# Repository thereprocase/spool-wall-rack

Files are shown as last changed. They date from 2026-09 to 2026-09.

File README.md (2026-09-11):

# Spool wall rack: recovered print settings and E + F trials

**Recovered print evidence changes the reference.** The completed overnight ASA archive uses seven walls, 10% base infill and 1.6 mm minimum top/bottom thickness. Its associated downloaded STEP matches E13 exactly. The newer STEP matches G; its saved PETG project uses two walls and the same 1.6 mm thickness settings, but the exact earlier PETG submission is not recovered. Geometry, walls and material changed together.

https://github.com/thereprocase/spool-wall-rack/blob/main/designs/rev-g2/print-controls/RECOVERED-PRINTS.md

**Current E + F result: material budget achieved; stiffness target missed.** A direct diagonal with a continuous solid helper core uses 22.49% less extrusion than the deliberate eight-wall G control, with 1.6 mm skins retained. Intermediate contact diagnostics give 4.9818 mm movement versus 2.6730 mm for that G control. Both tighter 1e-5 checks miss their time bounds. This is not a winning or physically qualified design.

The G rod/mount positions and protected bearing/capture geometry remain fixed. The locating underside stays at Y=-32 mm for at least 25.4 mm from the wall. No moulding support is assumed.

All current controls, actual slices, aligned STEP/helpers and numerical limitations

https://github.com/thereprocase/spool-wall-rack/tree/main/designs/rev-g2/print-controls

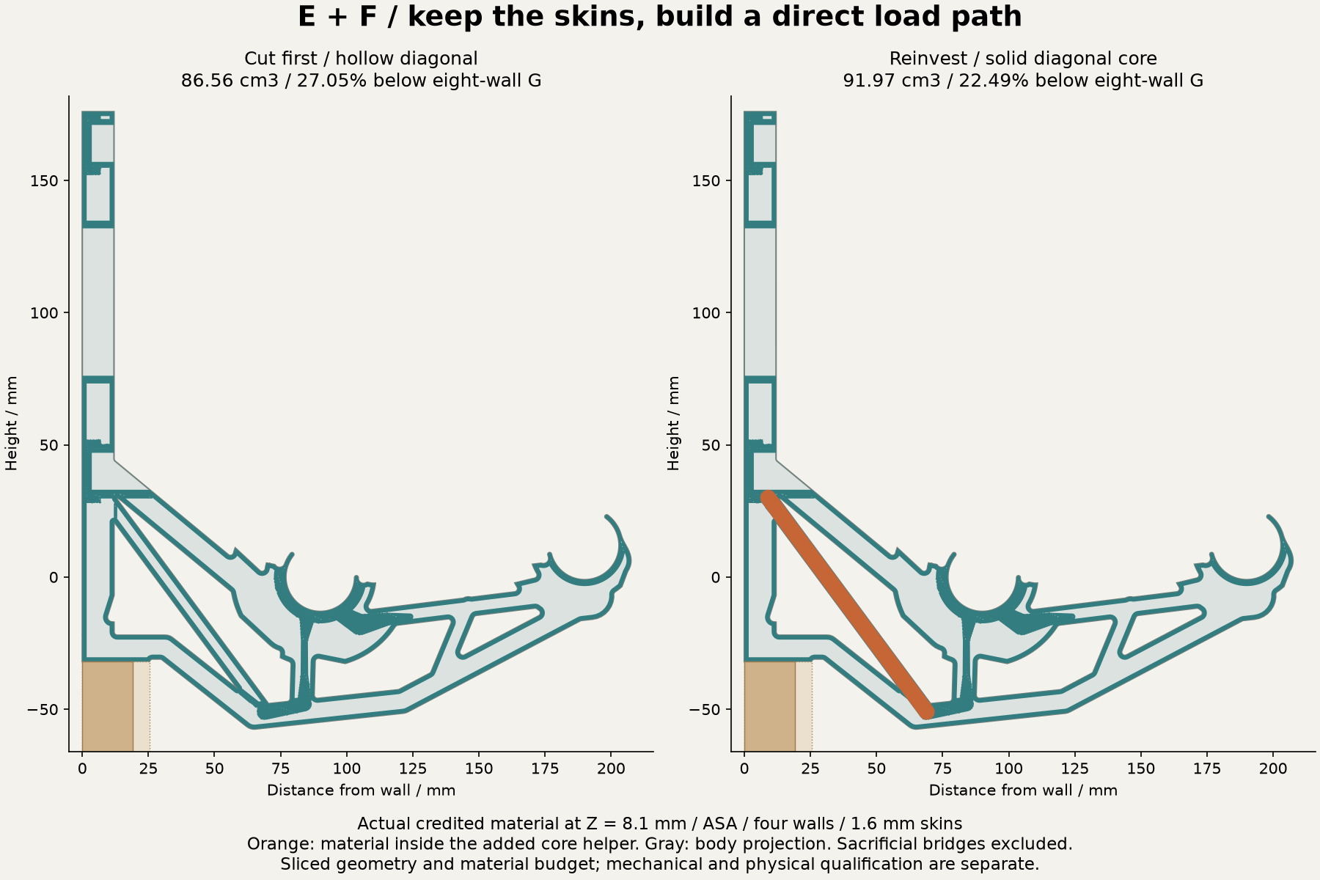
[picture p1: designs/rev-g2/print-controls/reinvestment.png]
Actual sliced brace reinvestment


## Preserved earlier screening work

**Completed local pilot: [evolutionary screening loop](analysis/rev-g2/EVOLUTION.md).** The first
batch screened 100 helper proposals in 11 min 18 s. The leading actual-slice
3D pass took 6 min 55 s including CAD, slicing, preparation and field audit:
4.1295 mm movement versus 4.3355 mm for G, with a 2.02% higher raw stress peak.
Its full-cell leader refinement took another 5 min 18 s and gives 4.1547 mm
maximum movement. Further finalist and mesh checks are recorded on the loop page. These are
screening results; material accuracy and physical qualification remain open.

Fresh 10.75 / 12 / 13.25 kg G contact checks are documented in [G results](analysis/rev-g2/G-RESULTS.md). One spool changes bracket movement by about 0.452 mm; material accuracy and physical qualification remain open.

[Printable STEP bodies, aligned helpers and per-idea notes](PRINT-CANDIDATES.md).

**Restart checkpoint:** [complete handoff and current candidates](RESTART-2026-09-11.md).

**G baseline: [completed 3D contact screen and accuracy limits](analysis/rev-g2/G-RESULTS.md).**
At 12 kg, the retained-material model gives **4.3355 mm maximum bracket movement**
and **20.0254 MPa raw peak tensile stress**. Wall contact has settled. A tenfold
tighter numerical check changes no nodal movement by more than 0.00000049 mm.
The geometry still omits 8.02% of raw nominal plastic; this is an explicitly
bounded numerical screen, not a qualified PETG/ASA bracket or load rating.
All seven G2 architectures remain unbuilt.

[Previous adaptive mesh and fresh P1S/PETG slicing checkpoint](analysis/rev-g2/ADAPTIVE-MESH.md).

**September 11, 2026: correcting the structural material model before G2.**
G's finalist is being rechecked against actual Orca paths with at least two
walls, 0% base infill and the existing 100% helpers. The wall/skin validation
matrix includes eight walls with two top/bottom layers and the reverse.
Thick 0.4 mm bridge extrusion counts toward plastic use but receives no
structural or bonded-connection credit. The new eroded-material contact screen is linked above; no corrected-material
qualification or preferred G2 prototype is established yet.

The reusable path-backed shape tool has passed independent occupancy and
thickness checks across all five schedules: 50,000 occupancy samples, with
zero mismatches outside the stated 0.005 mm polygonization band. The two-wall,
1 mm skin reference uses 77.920 cm³ of plastic, of which 6.940 cm³ is excluded
sacrificial bridge extrusion. A boundary-only volume mesh matches the
reconstructed continuum volume but fails topology/quality review. The long
whole-part CPU meshing attempts have been stopped. The replacement investigation
now uses GPU adaptive hexahedra; the completed eroded-material numerical
screen is linked above.

[GPU execution checkpoint](analysis/rev-g2/GPU-VALIDATION.md): the free Warp
runtime now passes an upstream elasticity comparison and independent 3D
elasticity/contact fixtures on the RTX 3080 Ti. GPU patch tests also pass on
an actual G slice crop. Conservative voxels still omit 17.12%, 8.37% and 4.31%
of that crop at progressively finer XY grids, so they are not accepted as
G's printed material. Material-converged whole-bracket mechanics and all seven
G2 architecture families remain unfinished. [Earlier software review](analysis/rev-g2/GPU-FEM-REVIEW.md).

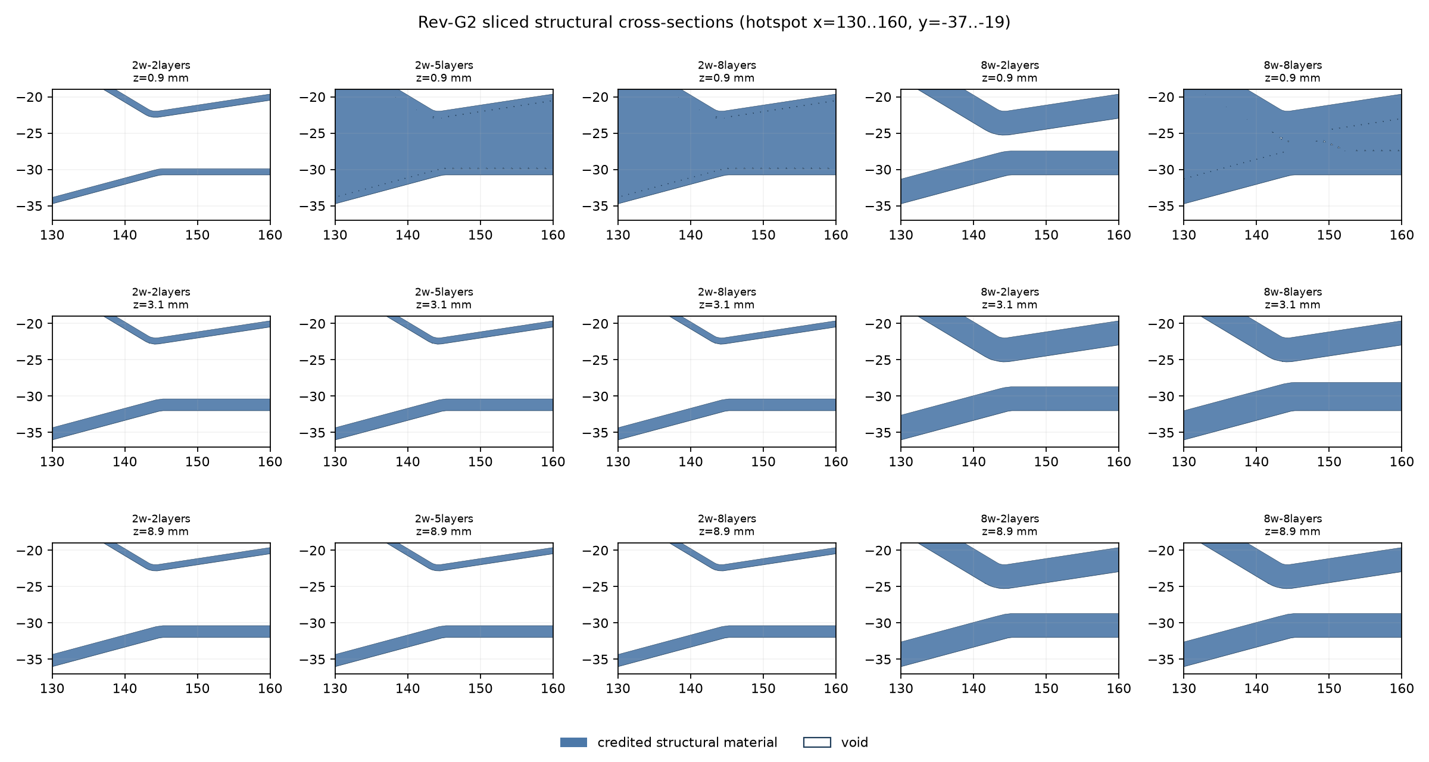
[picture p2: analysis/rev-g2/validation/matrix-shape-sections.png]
Actual sliced material across five wall and skin schedules


[G2 scope and acceptance gates](G2-BRIEF.md) ·
[Shape validation, slice evidence and reproduction](analysis/rev-g2/README.md) ·
[Slicer-backed shape tool](analysis/rev-g2/plastic_shape.py) ·
[Meshing progress and sources](analysis/rev-g2/MESHING-NOTES.md)

The new study changes actual architecture and density strategy while preserving
the specified interfaces. The current contract supersedes the earlier permission
to move rods or fixings and the old silhouette restrictions. P1S, 0.4 mm nozzle;
PETG or ASA.

## Preserved Rev G numerical study

**September 10, 2026: Rev G's evolutionary-search sprint is complete.
1,458 distinct parameter sets were evaluated. No tested finalist demonstrates
the requested 4× fracture margin; no qualified minimum-mass winner is selected.**
E13 remains the established prototype handoff, with its existing validation limits.

The results below belong to G's former material approximation. They are
preserved as regression evidence while the slice-to-FEM mapping is corrected;
they do not establish failure of the actual printed bracket.

[Current Rev G research CAD](designs/rev-g/README.md) ·
[Search, 3D results and limiting mechanism](analysis/rev-g/README.md) ·
[Next study](NEXT-SPRINT.md) · [Preserved F checkpoint](REV-F-CHECKPOINT.md) ·
[E13 guide](E13-ENGINEERING-GUIDE.md) · [Design journal](DESIGN-JOURNAL.md)

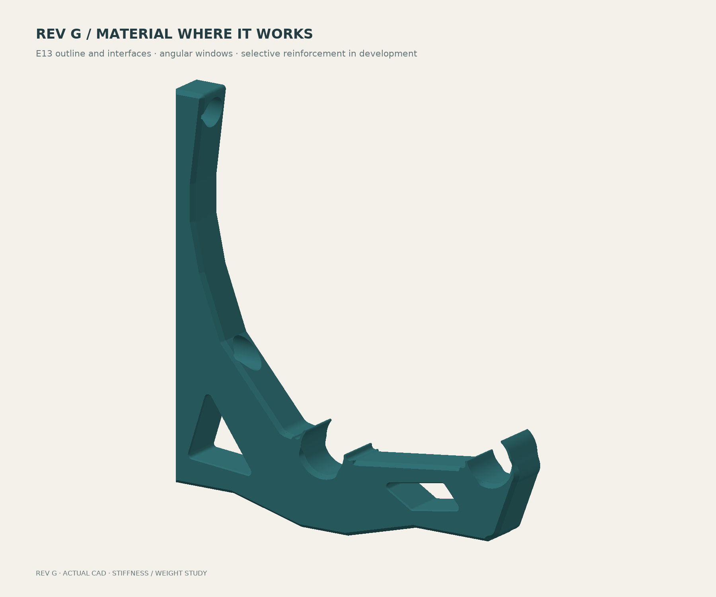
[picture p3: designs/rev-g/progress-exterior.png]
Actual Rev G finished CAD with preserved E13 exterior and angular windows


The full-plane search finalist slices to **103.76 g per bracket: 37.9% less
plastic than E13**. On matched fine meshes it is 51.1% more flexible and has
**6.6% better stiffness per gram**. Its 3.306 mm mean seat translation leaves
1.694 mm of the 5 mm total movement budget for other contributors at the
1 GPa planning modulus. Its raw tensile peak still fails the strength screen.

| Tested design | Actual Orca mass | Front vertical movement at 12 kg, E = 1 GPa | Outcome |
|---|---:|---:|---|
| E13, 8 walls | 167.11 g | 2.148 mm, h1 | Preserved reference prototype |
| G, thin shaped seed-1 candidate | 84.35 g | 4.930 mm, h2 | Movement, strength and dense-path coverage failures |
| G, full-plane search finalist | **103.76 g** | **3.246 mm, h1** | CAD/toolpaths pass; all three meshes fail fracture screen |
| G, wider inner-seat support | 108.03 g | 2.988 mm, h2 | Improves coarse result; fracture screen still fails |

Masses use the same neutral density of 1.24 g/cm³. Movements are modeled,
not measured. Mesh levels differ where stated; no physical print or sustained
load qualification is claimed.

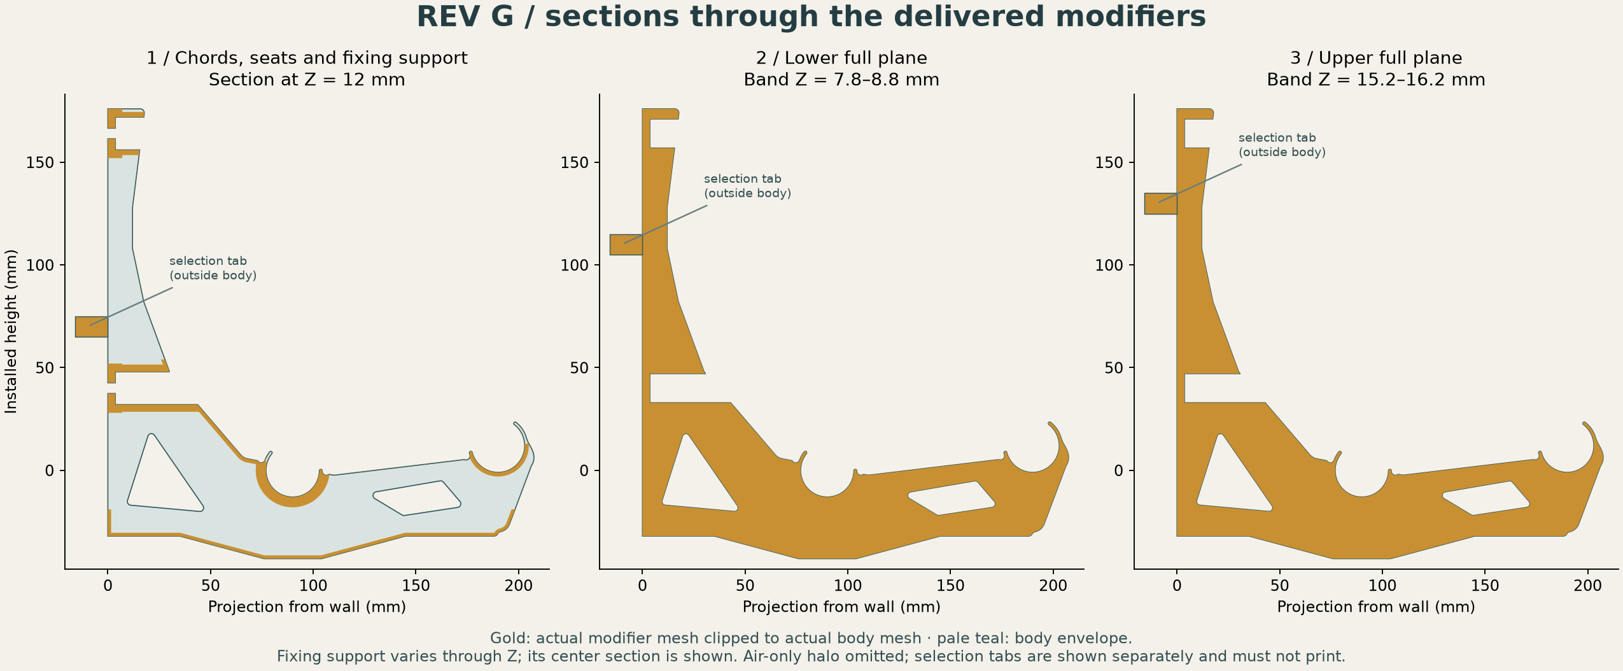
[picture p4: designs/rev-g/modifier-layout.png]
Sections through actual Rev G body and three modifier meshes


The genetic optimizer is implemented. Two broad-family seeds and a second
family informed by 3D failures were run; two cached search replays reproduced
the complete ledgers exactly. Four uncached physics cases match the canonical
solver. Actual Orca checks verify modifier roles, alignment and nonprinting
tabs. [Full evidence and reproduction commands](analysis/rev-g/README.md).

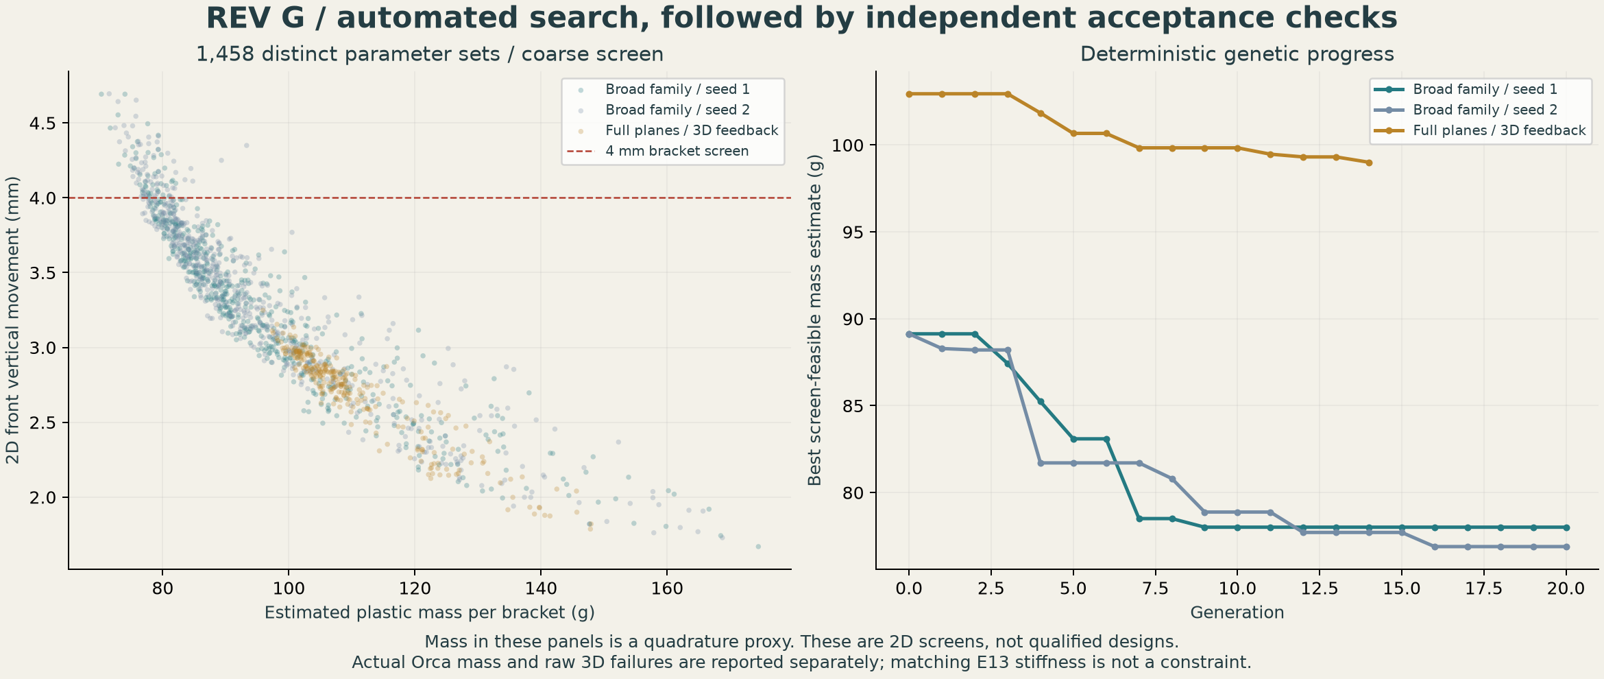
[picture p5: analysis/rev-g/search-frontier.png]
Genetic search progress and estimated mass/movement frontier


**What limits the design:** the full-plane candidate's raw tensile peak rises
from 32.29 to 55.05 MPa with mesh refinement, above the 10.125 MPa nominal
screen. The fine peak is adjacent to a preserved exterior forearm chamfer.
All finite cells are retained; this is not a converged rupture prediction.
The next study addresses that local geometry/material-model uncertainty before
further mass optimization. [Stress evidence](analysis/rev-g/README.md#mesh-refinement-and-the-limiting-mechanism)
· [Next study scope](NEXT-SPRINT.md).

---

## Preserved E13 print and engineering guide

**Established prototype handoff: E13 — an 11 mm deep reinforcement with straight angled
flanks and a short flat bottom.** It is 1.5 mm deeper than E12 and remains
below the 12.67 mm maximum. Small corner blends preserve the angular shape.

**[Download E13 STEP with aligned helpers](designs/closed-wall-e13/bracket-with-modifier-helpers.step)** ·
[CAD and print checks](designs/closed-wall-e13/README.md) ·
[Refined stress and material results](analysis/e13/RESULTS.md) ·
[Hotspot audit](analysis/e13/HOTSPOTS.md) · [Design journal](DESIGN-JOURNAL.md)

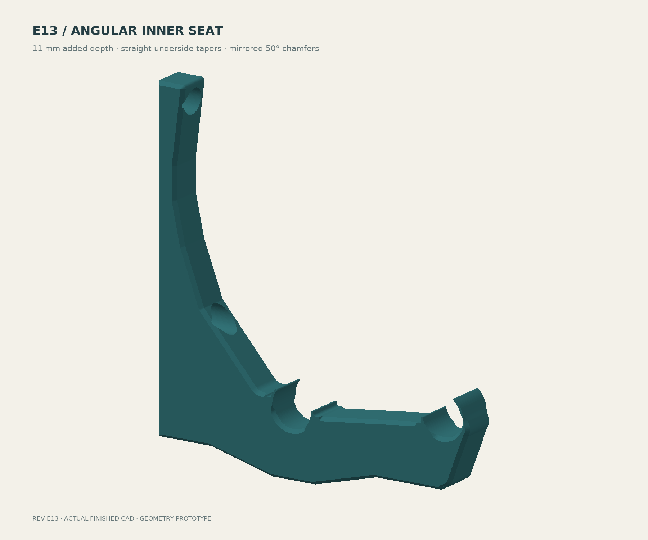
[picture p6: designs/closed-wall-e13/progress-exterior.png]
Current E13 finished CAD


## Angular shape and preserved fit

The underside has two straight 41 mm horizontal runs into a 28 mm flat. Each
flank changes height by 11 mm, about **15° to horizontal**. Small corner
blends join the facets. The inner-center section is **30 mm deep**, and the
body envelope is approximately **207.51 × 219.00 × 24 mm**.

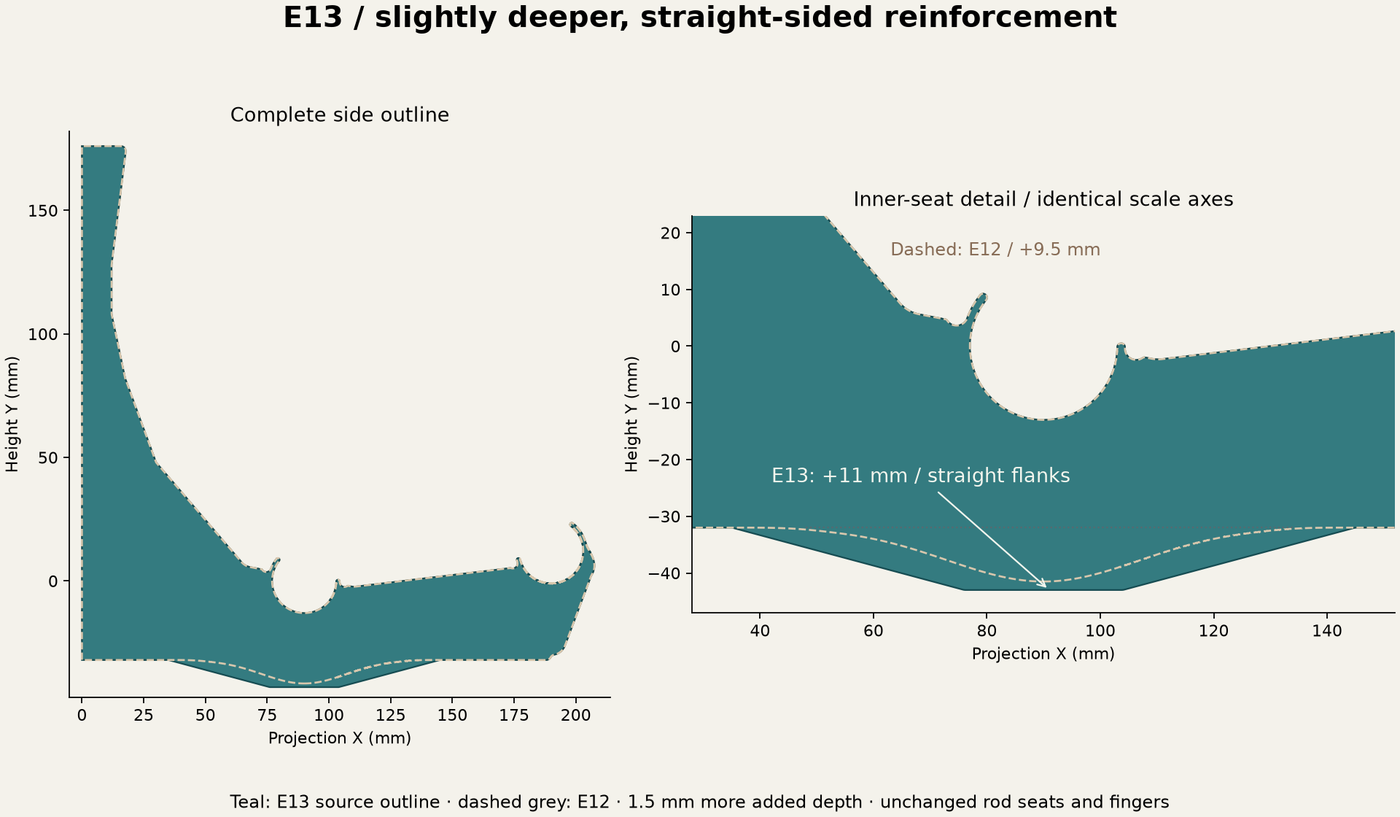
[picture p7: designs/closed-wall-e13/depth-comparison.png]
E13 and E12 outlines


The longer tapers spread the reinforcement into the adjoining knee and arm.
The matched reduced model gives **40–41% lower near-seat stress than E10**,
and **12–13% lower than E12**, with about **16% less front movement than E12**.
The outer-rod-only stress statistic is about **43% lower than E10**.
[Exact comparisons](analysis/e13/COMPARISON.md).

The finished ideal printed section has at least **3.15× E10's minimum
seat-band bending I** and **2.00× its elastic section modulus**. It does
not exceed both adjacent reference sections. The depth cap supersedes that
E11 target; adjacent arms have not been weakened to improve the ratio.
[Section audit](designs/closed-wall-e13/section-verification.json).

The R6 rigid shoulder blends, fingers and relief pockets remain. Both broad
faces have **2 mm chamfer inset, 2.384 mm rise and 50° above the bed**. Only thin
retainers receive bevel runouts. Actual STEP boundary probes confirm the
straight flanks, flat underside and mirrored angles.

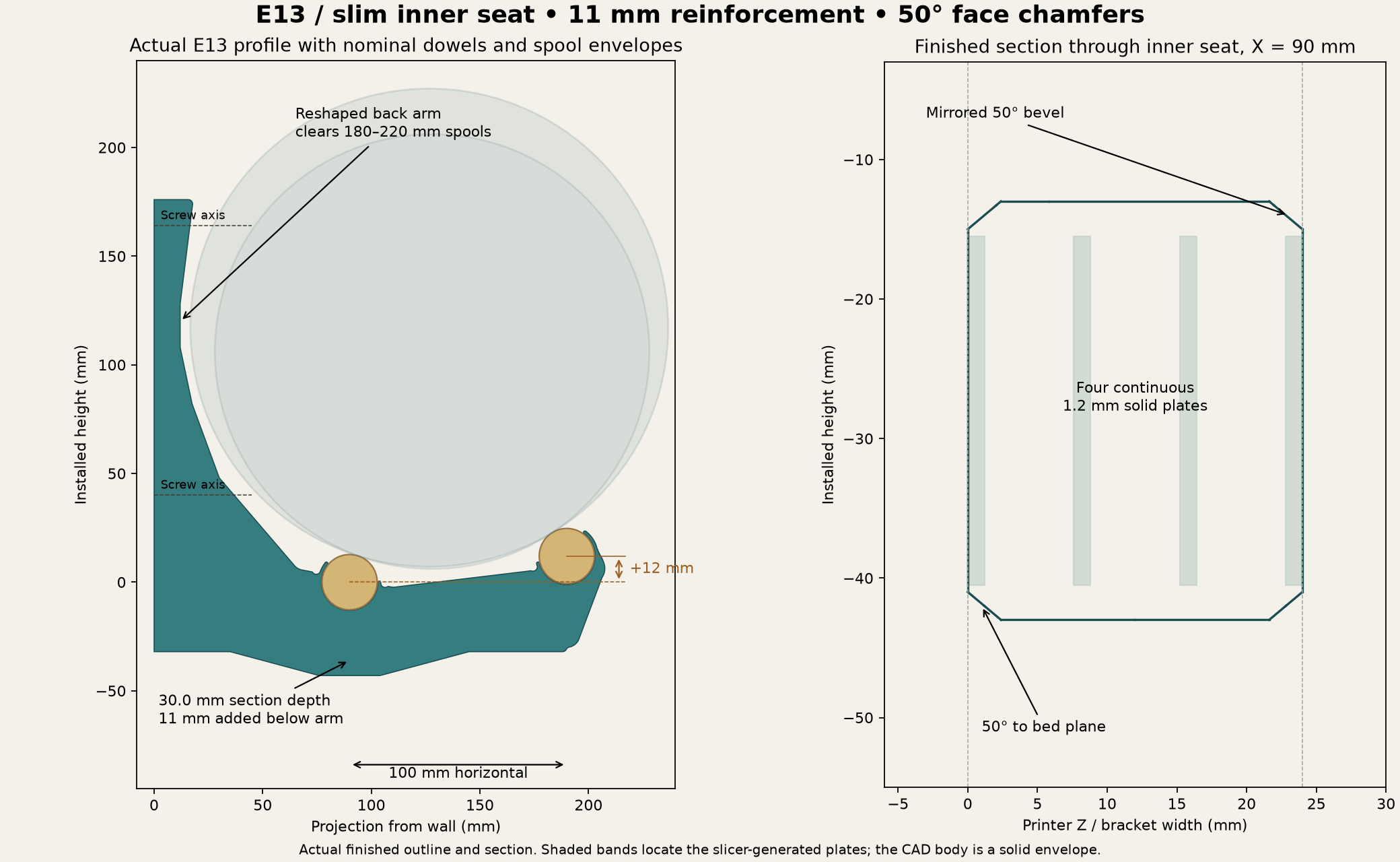
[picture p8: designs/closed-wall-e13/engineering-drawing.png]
Profile and finished section


[Inner-seat close-up](designs/closed-wall-e13/finish-inner-front.png) ·
[Reverse face](designs/closed-wall-e13/finish-inner-reverse.png) ·
[Outer fingers](designs/closed-wall-e13/finish-outer-front.png).

Rear/front rail centers stay at (90,0)/(190,12) mm. The 322-case nominal
180–220 mm spool sweep retains **3.927 mm minimum clearance**. All four flexible
sectors match E10 at nine print depths. Physical rod fit and insertion force
remain untested.

## Print setup

Print on the supplied broad side. Import the STEP as **one object with three
aligned parts**, so the main bending load stays in the layer plane.

| Setting | Working value |
|---|---|
| Body footprint / height | **207.51 × 219.00 × 24 mm**; check bed exclusions |
| Layer / first layer | **0.20 / 0.20 mm** |
| Reference nozzle | 0.4 mm |
| Outer / inner nominal line widths | 0.42 / 0.45 mm |
| Wall generator / solid-region gap fill | **Arachne / Everywhere** |
| PLA prototype walls | **8**, about 3.27 mm ideal contour thickness |
| PETG prototype walls | **10**, about 4.08 mm ideal contour thickness |
| Body infill | **15%**, zero structural credit |
| Exterior top / bottom | **1.2 / 1.2 mm**, six layers each |
| Helper 1 | **100% infill modifier**, Z=7.6–8.8 mm |
| Helper 2 | **100% infill modifier**, Z=15.2–16.4 mm |
| Filament process | Exact grade's calibrated temperature, cooling, flow and bonding |

1. Keep the main body printable with the selected walls, 15% infill and six
   top/bottom layers.
2. Convert both named helpers to **100% infill modifiers** in their supplied
   positions. They must not print as extra exterior slabs.
3. Inspect all four solid bands, seat perimeters, fingers, screw lands and
   access roofs; then save the configured machine/filament project.

STEP stores geometry and alignment, not modifier status or print settings.
[STL fallback and detailed handoff](designs/closed-wall-e13/README.md).

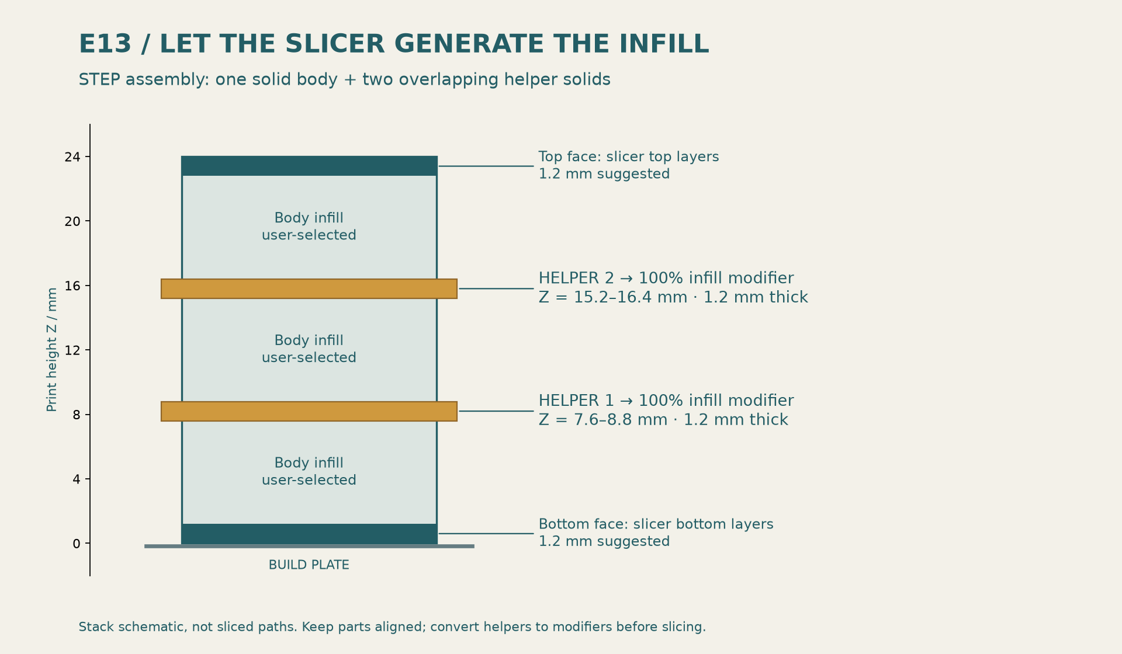
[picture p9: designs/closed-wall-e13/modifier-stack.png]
Modifier stack


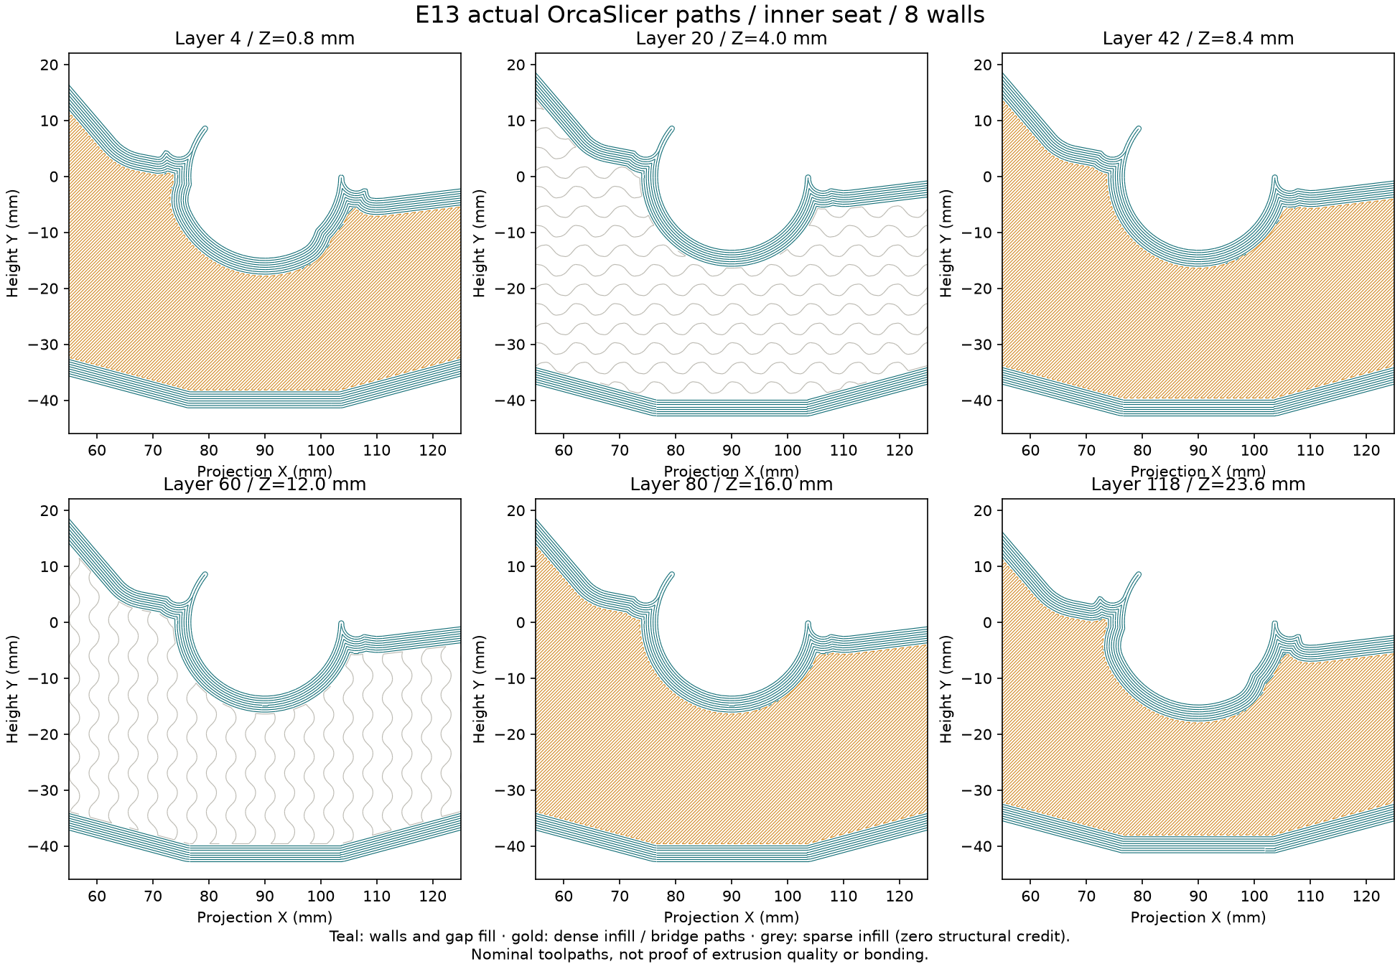
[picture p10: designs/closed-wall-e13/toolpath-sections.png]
Actual E13 OrcaSlicer paths


**Both OrcaSlicer 2.4.2 audits pass:** 120 layers, all 24 intended solid-band
layers checked around the inner seat, plus sampled full L-planes, walls and
fingers. Minimum nominal footprint coverage is **99.82% in the seat bands,
99.99% in sampled seat walls and 99.84% in sampled fingers**, with a
0.03 mm tessellation/rounding allowance. These neutral slices do not qualify
bonding, bridging, curling or an actual filament process.
[Toolpath evidence](designs/closed-wall-e13/toolpath-verification.json).

The contour estimate remains
`t(n) = 0.42 + (n − 1) × [0.45 − 0.2 × (1 − π/4)] mm`.
Arachne varies thin-feature widths; actual paths govern. Keep the four 1.2 mm
plates if changing nozzle or wall count. Sparse infill supports the plates
during printing while receiving zero structural credit in the analysis.

## Finer meshes and remaining stress concentrations

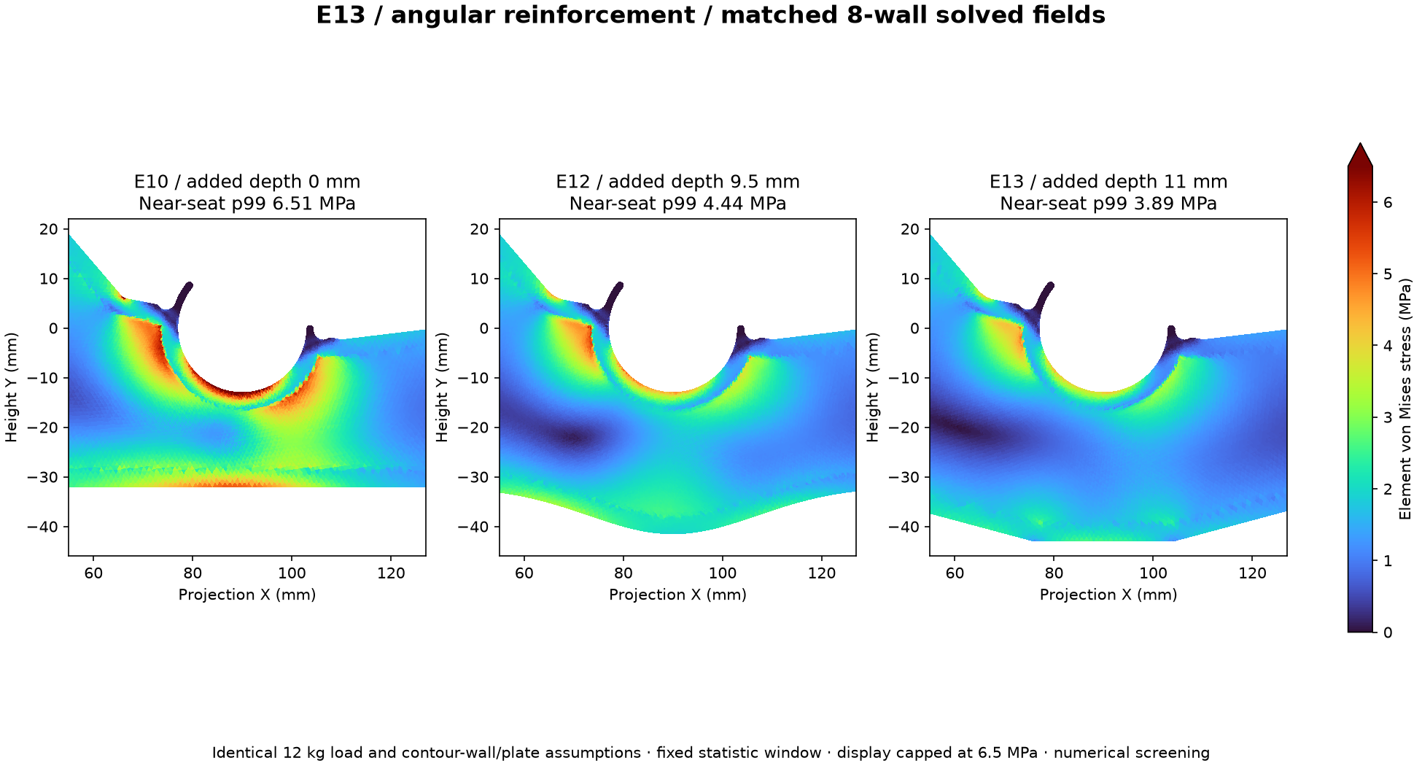
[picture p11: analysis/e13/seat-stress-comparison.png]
Matched reduced stress fields


The full 3D model includes the finished chamfers, ideal contour walls, four
continuous plates, screw tunnels, compression-only wall contact and rigid
washer/shank restraints. Sparse infill receives zero structural credit.

Both wall counts now have **three global mesh levels: h=2, 1.5 and 1 mm**.
E12 was also re-solved at h=1 mm for the matched hotspot comparison. Two further
meshes check the 500 N upper screw landing. All ten new 3D fields pass independent
free-residual, force and moment gates below 1e-6.

| Walls | Tetrahedra at h=2 / 1.5 / 1 mm | Last movement change | Last near-seat p99 change |
|---:|---:|---:|---:|
| 8 | 192,633 / 323,629 / 757,028 | +1.84% | -0.34% |
| 10 | 195,838 / 328,179 / 787,137 | +1.90% | -1.09% |

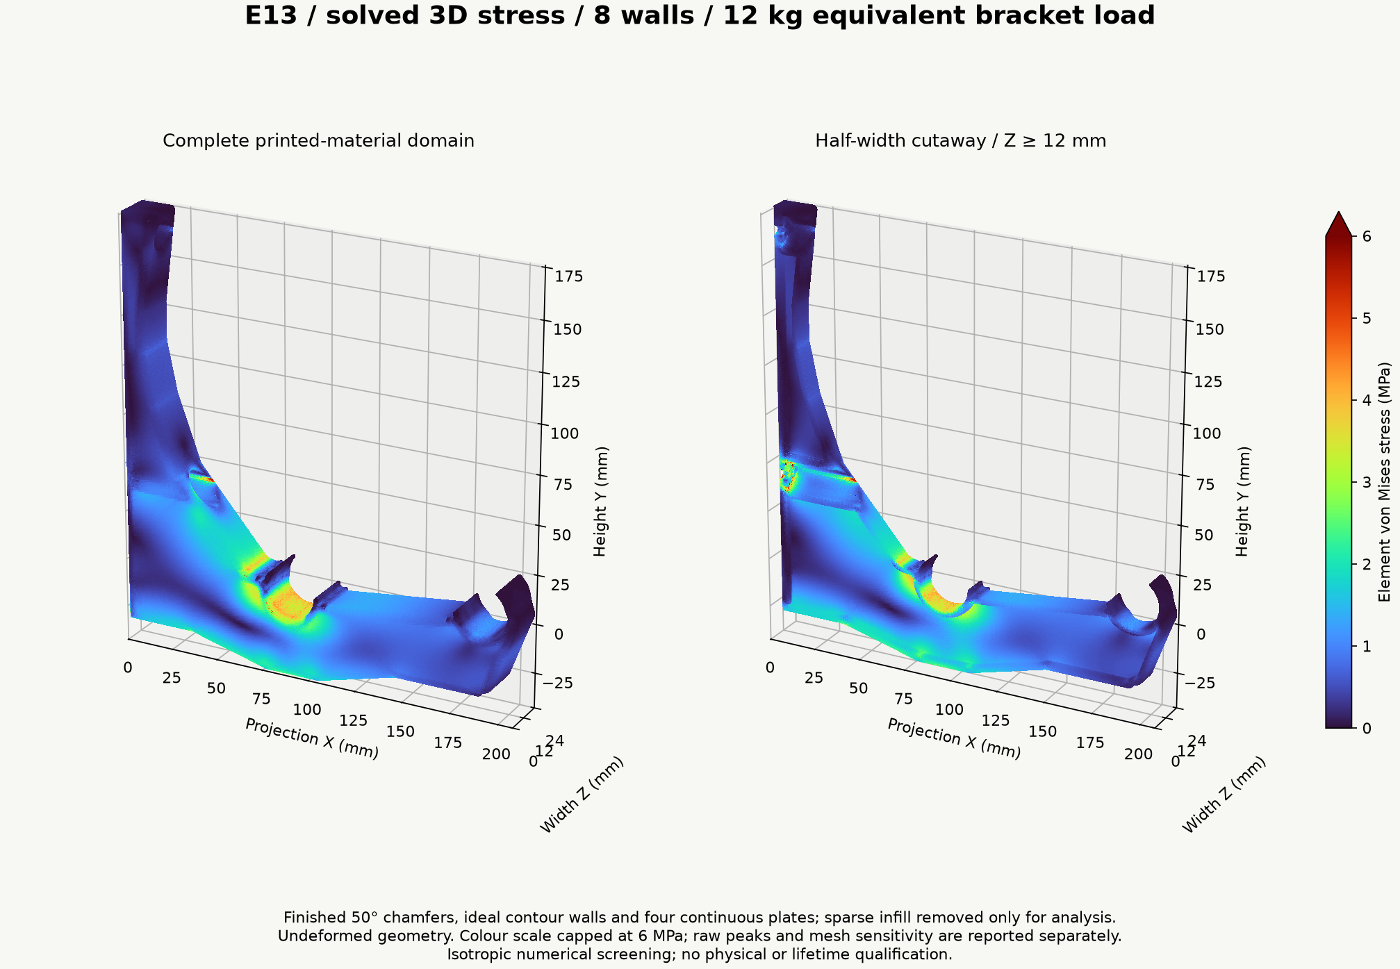
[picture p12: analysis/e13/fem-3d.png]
Refined 3D stress and cutaway


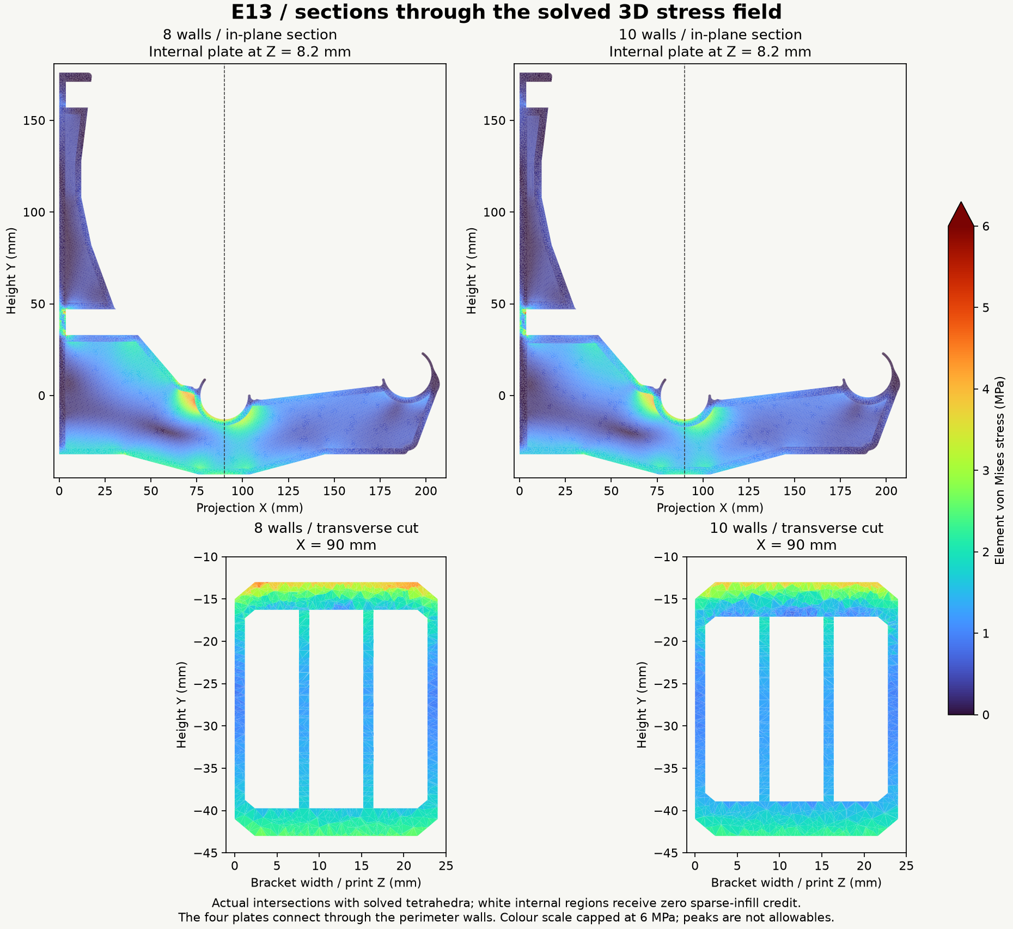
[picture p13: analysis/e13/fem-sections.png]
Sections through the actual solved tetrahedra


The table below compares volume-weighted p99 stress in fixed regions at the
same h=1 mm mesh size. Negative means lower stress in E13.

| Region | 8-wall stress change vs E12 | 10-wall stress change vs E12 |
|---|---:|---:|
| Inner seat | -13.28% | -13.22% |
| Knee | -9.31% | -10.37% |
| Outer arm | -19.41% | -20.24% |
| Lower landing | -0.17% | +0.93% |
| Upper landing | +1.17% | -1.12% |

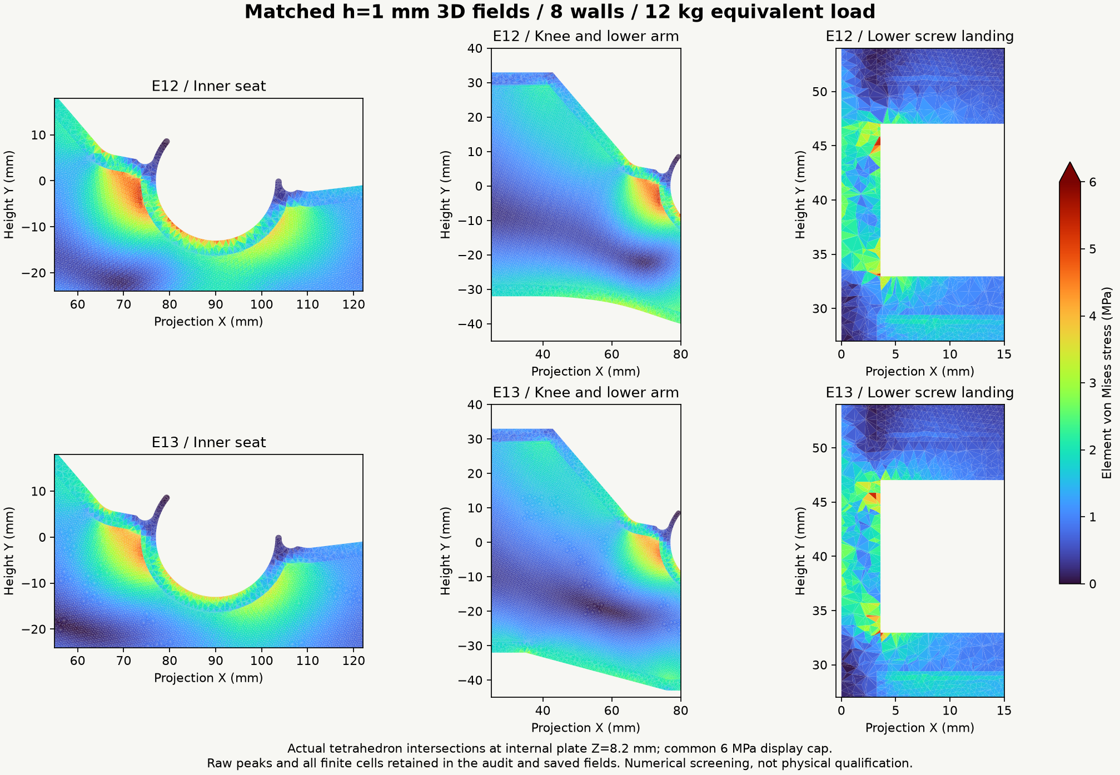
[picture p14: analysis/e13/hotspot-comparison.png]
Matched fine-mesh hotspot details


The large isolated raw peaks do **not** all disappear. Some change substantially
with refinement at chamfer, plate and restraint intersections. The audit keeps
their locations, cell volumes and every finite element; small cell size alone
does not establish that a peak is an artifact. The common 6 MPa figure cap
does not alter the saved stress field. No rupture allowable is inferred.
[Raw peaks and refinement](analysis/e13/HOTSPOTS.md) ·
[Full engineering results](analysis/e13/RESULTS.md).

## Current movement and material cases

The criteria remain **5 mm total loaded movement**, including dowels and
mounts, and **1 mm change per full spool**. At the 12 kg reference load, the
refined front coefficients are **K=2148.0 MPa·mm for 8 walls** and
**1936.6 for 10 walls**.

| Reference material | Walls | Initial front movement | One 1.25 kg roll | Ec for 5 mm bracket-only |
|---|---:|---:|---:|---:|
| PLA | 8 | 0.627 mm | 0.065 mm | 430 MPa |
| PETG | 10 | 0.838 mm | 0.087 mm | 387 MPa |
| ASA | 8 | 0.903 mm | 0.094 mm | 430 MPa |
| PA6-GF dry | 8 | 0.401 mm | 0.042 mm | 430 MPa |
| PA6-GF wet | 8 | 1.198 mm | 0.125 mm | 430 MPa |

These use the retained grade-specific room-temperature XY moduli, not measured
hot or aged properties. [Exact grades, conditions, sources and hashes](designs/closed-wall-e6/material-reference-data.json).
The [material report](analysis/e13/RESULTS.md) includes 24 kg linear proof
scaling and one-, five- and ten-year creep sensitivities. No lifetime safe
spool count is assigned.

For common linear-viscoelastic compliance with unchanged contact,
`δ(t,T) = K × J(t,T) = K / Ec(t,T)`.
The complete rack requires **Ec ≥ K / (5 mm − dowel movement − mount movement)**.
Retain the project screening target of **at least 1.0 GPa effective creep
modulus** at the intended age and temperature history. It is not a grade allowable.

The service envelope stays **85°F sustained and 100°F for six loaded hours/year**.
Short-time creep examples, assumed long-time tails, HDT and generic tensile
strength do not establish multi-year performance. PA6-GF dry/wet conditioning
and annealing remain separate. Fast spool unloading uses aged instantaneous
modulus rather than reversal of accumulated creep.

## Loads, rods and installation

The analysis target is **12 kg equivalent / 117.72 N per bracket**. For the
documented 180 mm spool contact case, the rear/front seats receive **75.12 / 42.60 N
downward**, plus **31.29 N outward each**. The front rail remains 12 mm higher;
the back arm accommodates the rearward-shifted spool. The retained
[rail-statics explanation](E10-ENGINEERING-GUIDE.md#current-rail-geometry-12-mm-front-lift)
describes that load split.

At 406.4 mm (16-inch) support spacing and 1.25 kg gross per spool, six spools per
bay weigh 7.5 kg and need pitch ≤67.7 mm. An interior support between simple
spans carries about one bay; the stated two-equal-span continuous example gives
1.25 times the bay load, or 9.375 kg before self-weight. The 12 kg target includes
margin for that example, not every loading pattern. **Six per bay is a proposed
test arrangement, not a released safe count.**

The **24 kg brief proof scenario** doubles the linear fields with unchanged
contact; it is neither a damage simulation nor a performed proof test.

| Hardware feature | E13 geometry |
|---|---:|
| Nominal screw clearance | Ø5.2 mm, with printable roof relief |
| Washer face to wall | 3.6 mm |
| Nominal driver access / checked straight envelope | Ø16 / Ø15.8 mm |
| Checked washer | Ø13 OD / Ø5.5 ID |
| Screw axes in installed coordinates | Y = 164 / 40 mm, Z = 12 mm |

The refined global model gives **211–213 N outward demand at the lower
washer** and about **15 N at the upper**, excluding tightening
preload. The 500 N upper-landing submodel gives **0.01208 mm** mean
compression at E1000 and a **4.95 MPa** raw peak; washer movement
changes **1.61%** on refinement.

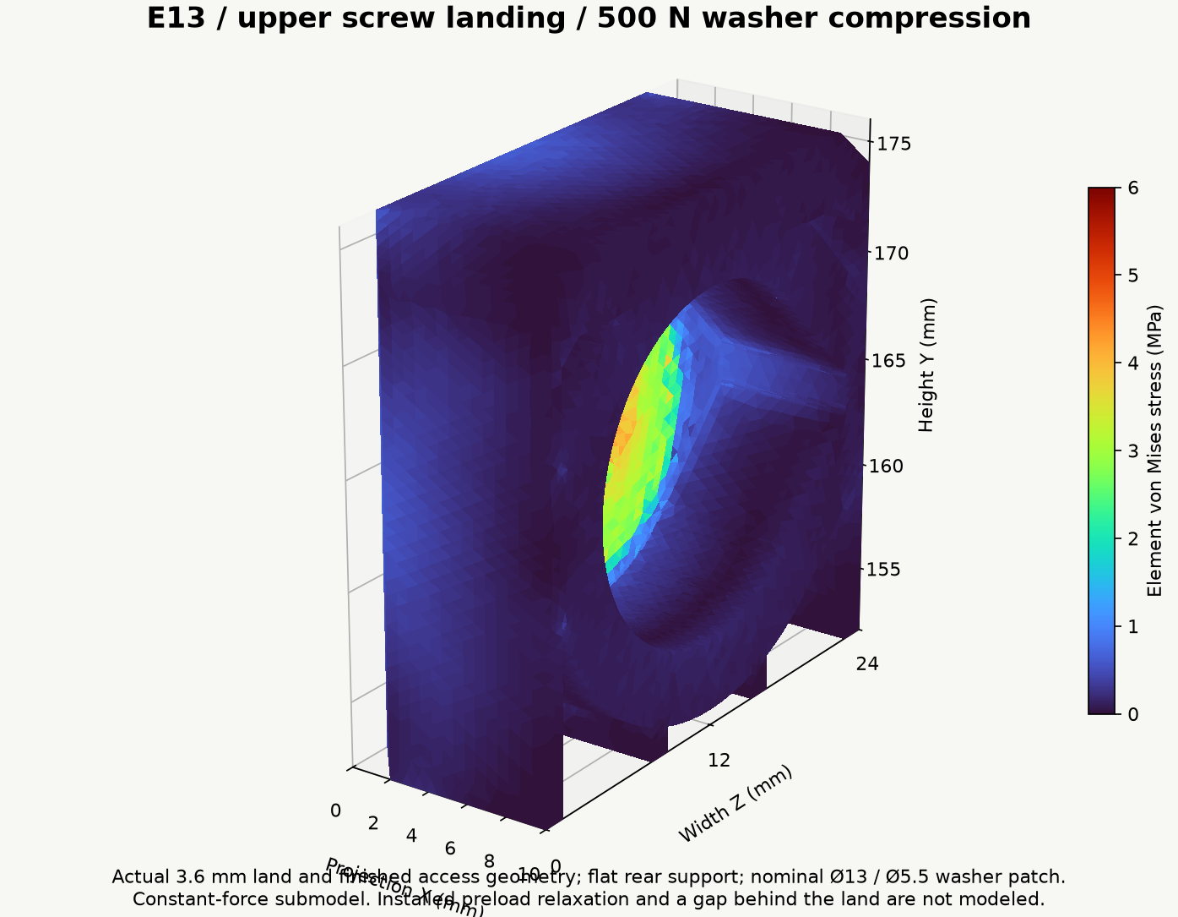
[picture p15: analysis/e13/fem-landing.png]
E13 screw-landing stress


Retain the backed 3.6 mm land. Mount against a flat, firm surface; a gap changes
the land into a bending/punching problem. Use flat-bearing heads and washers,
substrate-appropriate screws, and the manufacturer's pilot/embedment guidance.
M5 shank clearance does not make an M5 machine screw suitable for wood. Driving
torque does not reliably establish clamp force. Service and preload von Mises
maxima cannot simply be added as scalars.

**Rod fit remains provisional.** The 26.0 mm seat assumes nominal 25.4 mm stock.
The checked retail listings specify 1-inch actual diameter but no numeric
production/ovality tolerance. Measure the rods and use the
[full-width fit coupons and measurement plan](fit/README.md).

## Qualification and reproduction

The remaining print checks are physical: fit, snap insertion/retention, bonded
layers, supported internal bands and the actual filament process. Measure
immediate loaded movement and drift, rear/front seat positions, dowel sag and
wall/washer movement. Include the sustained 85°F condition and a six-hour loaded
100°F exposure; inspect for cracking, whitening, layer separation, permanent
snap opening and progressive embedment. A proof test or 1,000-hour trial alone
does not establish ten-year creep-rupture life.

[CAD rebuild and verification](designs/closed-wall-e13/README.md) ·
[Analysis reproduction and solver checks](analysis/e13/README.md) ·
[Machine-readable engineering summary](analysis/e13/engineering-summary.json).

The [curved E12 guide](E12-ENGINEERING-GUIDE.md), [deeper E11 guide](E11-ENGINEERING-GUIDE.md), [E10 guide](E10-ENGINEERING-GUIDE.md), [E9 analysis](analysis/e9/RESULTS.md)
and [level-rail E8 guide](E8-ENGINEERING-GUIDE.md) are preserved as earlier
baselines. [Design journal](DESIGN-JOURNAL.md) · [Design decisions](DESIGN.md) ·
[Separate future open-web exploration](future/open-web/README.md).

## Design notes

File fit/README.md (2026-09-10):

# Dowel fit: source dimensions and outstanding measurements

**The snap fit is not yet qualified against measured retail dowels.** The design uses a nominal 25.4 mm rod and a 26.0 mm CAD seat. That is 0.6 mm diametral design clearance, not a supplier tolerance and not proof that every 1-inch dowel fits.

## Source check — 10 September 2026

| Lowe's product | Identification | Published actual diameter | Published diameter/ovality tolerance found |
|---|---|---:|---|
| [Madison Mill poplar, 48 inches long](https://www.lowes.com/pd/Madison-Mill-Round-Wood-Poplar-Dowel-Actual-48-in-L-x-1-in-dia/3040774) | Item 19386; model 436513 | 1 inch / 25.4 mm | None on the checked listing |
| [Madison Mill oak, 36 inches long](https://www.lowes.com/pd/Madison-Mill-Round-Wood-Oak-Dowel-Actual-36-in-L-x-1-in-Dia/3040784) | Item 19425; model 432513 | 1 inch / 25.4 mm | None on the checked listing |

The manufacturer's [dowel page](https://www.madisonmill.com/dowels-accessories-2/) describes its products as true to size, but gives no numeric tolerance. Its [FAQ](https://www.madisonmill.com/faqs/) also provides no dimensional acceptance band. These pages do not establish minimum/maximum diameters, ovality, moisture condition or batch variation. No physical caliper measurements have been taken for this project.

The poplar listing pools reviews across multiple dowel diameters. Neither those pooled ratings nor the site's generated review summary establishes a measured 1-inch diameter range. Tolerances for another manufacturer's joinery pins must not be substituted for these retail rods.

## Dimensions to keep separate

- **Rod envelope:** measured minimum and maximum diameter, including ovality and locations along the actual rods. These values remain unknown.
- **Seat:** current CAD diameter 26.0 mm. The printed diameter also depends on the actual filament, flow, shrinkage and hole compensation.
- **Snap throat:** the unblended collar construction targets approximately 24.51 mm between rounded noses. Check the working section away from the 2 mm broad-face chamfers. Measure the finished/printed opening; do not treat that construction value as a production tolerance.
- **Finger section:** nominal 1.35 mm in the flexible region, with thickened bearing sectors and blended roots. Insertion strain and retained opening are separate from whole-bracket gravity FEM.

The current approximately 218° collar wrap is not itself a tolerance specification. Capture depends on the actual narrowest opening, rod diameter, finger flexibility and insertion direction. The chamfers taper out before the thin fingers so the edge finish does not consume their section.

## Fit conditions

For an initially relaxed cradle with positive geometric capture:

`smallest printed seat − largest conditioned rod > selected running clearance`

`smallest conditioned rod − largest printed throat > selected capture margin`

The largest rod and smallest throat govern required insertion opening. Half the total opening is only a symmetric-finger approximation; the integrated bracket has unequal local restraints. The seated rod should rest on the thick bearing region without holding the fingers permanently sprung apart. Confirm that the rod cannot escape after repeated insertion/removal and after the loaded temperature exposure.

No numeric production rod envelope, guaranteed insertion force, allowable snap strain or lifetime retention margin is assigned until the missing measurements are available. The 26.0 mm seat remains provisional; widening it blindly can reduce capture and bearing-location control.

## Practical measurements

Use gentle caliper pressure. At each intended bracket contact station, rotate the rod to find the minimum and maximum diameter. Repeat along each rod, including both ends and the middle; do not infer ovality from only one orientation. Record the SKU/species, finish and room condition. Measure again after any applied finish and after the rod has stabilized in the installation environment.

Print the fit coupons using the intended printer, filament and orientation before printing full brackets. Check insertion, seating, rotation, axial sliding, removal and repeat insertion. A coupon checks fit and handling; it does not establish bracket load capacity or creep life. Small-batch measurements describe that batch, not the manufacturer's complete production tolerance.

## Download the current fit coupons

- [Rear seat with aligned helper modifiers](rear-fit-coupon-with-helpers.step) — [body STL](rear-fit-coupon.stl).
- [Front seat with aligned helper modifiers](front-fit-coupon-with-helpers.step) — [body STL](front-fit-coupon.stl).

These are local sections extracted from the finished E10 bracket, at the full 24 mm width. Keep the supplied broad side on the bed and use the same filament, wall count, layers and solid bands as the intended bracket. Import each assembly as one aligned object and change its two helpers to 100% infill modifiers. Cut boundaries change restraint, so a coupon's insertion force is not a calibrated prediction for the complete bracket.

[Rebuild script](build_coupons.py) · [Geometry and mesh checks](coupon-verification.json).

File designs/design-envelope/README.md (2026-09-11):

# Post-G design envelope and material freedom

**Superseded initial draft.** [G2-BRIEF.md](../../G2-BRIEF.md) permits changes
to rail and fixing positions and uses a spool-relative compactness condition.
The fixed interfaces and local E13 underside floor below are a reference
illustration, not the mandatory G2 design domain.

The next search may change the structural body throughout this envelope.
**No existing solid region, wall, skin, rib, internal plane or window is
mandatory. Any number and shape of 100% infill helpers may redistribute
dense material.** Functional performance remains an acceptance requirement.

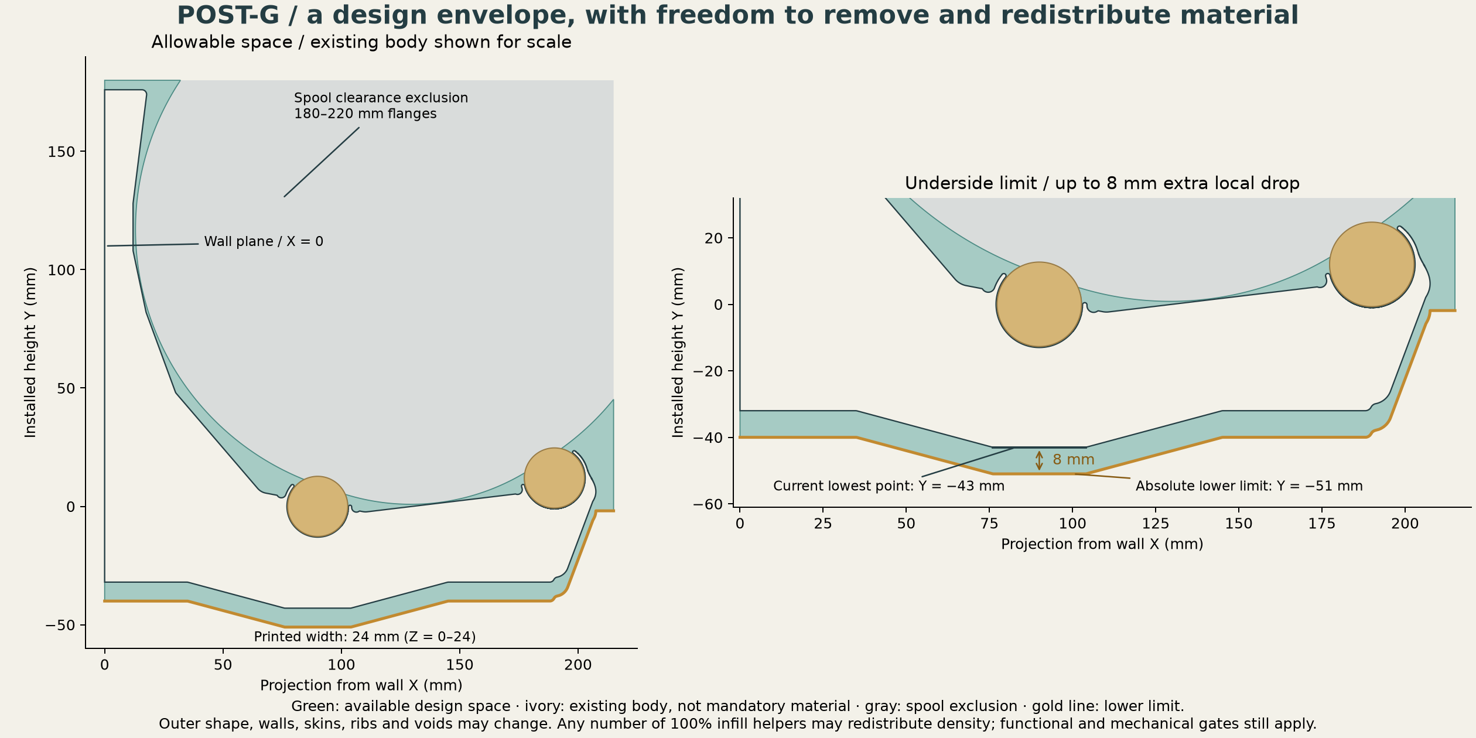
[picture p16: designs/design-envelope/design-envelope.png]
Allowable design space and underside limit


| Boundary | Limit |
|---|---|
| Extra downward extension | **8 mm below the current underside at each X** |
| Absolute lowest point | **Y = −51 mm**, relative to the rear rail center |
| Projection from wall | X = 0–215 mm |
| Upper extent | Y ≤ 180 mm |
| Printed width | Z = 0–24 mm |
| Seated spool exclusion | 180–220 mm flanges, at least 3.5 mm nominal clearance |

The underside cap follows the reference's lower silhouette with an 8 mm
offset. It therefore limits local hanging depth along the arm, rather than
allowing the whole arm to extend to the deepest central level. Beyond the
old forward tip, its final lower-limit height continues to X = 215 mm.
The body need not follow or touch this boundary. The old 12.67 mm added-depth
cap and exact-exterior preservation rule are superseded for the next search.

## Material and density freedom

Material may be removed anywhere or added anywhere inside the admissible
volume. Outer contours, chamfers, fillets, wall counts, skins, plates, ribs,
windows and sparse density are variables. There are no frozen solid islands
and no inherited full-plane architecture.

Helpers have no fixed count, shape or placement. They may overlap, include
disconnected regions or extend into air for selection. Their effective dense
region is **the union of all helpers intersected with the printable body**.
Overlaps count once. Helpers are modifiers, never extra printed parts; their
air-only portions must produce no extrusion. Actual Orca paths determine mass
and whether the intended density distribution is produced.

## Functional requirements

Keep the rail centers at (90, 0) and (190, 12) mm; nominal 25.4 mm rod fit,
13 mm seat radius and positive retention remain targets. Retainers may change,
but fit, capture, insertion force, strain and fatigue then need fresh checks.

Keep fixing axes at (Y, Z) = (164, 12) and (40, 12) mm, nominal 5.2 mm screw
clearance, 13 mm washer support at X = 3.6 mm and 15.8 mm driver access from
X = 3.61 mm. Wall contact must be coplanar at X = 0 and support the solved
load path; the former full-height strip is not mandatory. These are functional
targets, not exact retained volumes. Material behind or around an interface
may change if it still passes the relevant checks.

The 5 mm total movement limit, 1 mm change per 1.25 kg spool, requested 4×
fracture factor, stability and printability requirements remain. Sparse infill
has zero structural credit until a validated model supports otherwise.

## Machine-readable contract and scope

[Definition](definition.json) · [XY domain geometry](design-domain.geojson)
· [Construction and spatial probes](verification.json) · [Builder](build_envelope.py).

The flange exclusion covers continuous effective rail radii 12.4–12.7 mm.
A conservative 0.14 mm sampling guard covers intermediate spool diameters;
circumscribed circle polygons avoid underestimating exclusion. This remains
a seated nominal-clearance model, not insertion or loaded-contact validation.

The spatial checker verifies the envelope and explicit positive/negative
geometry probes. Screw/driver voids and washer support require separate 3D
checks; they are not represented as holes in the side-view illustration.
No new bracket has been optimized or qualified. The published G optimizer
and results remain an immutable prior study; the next implementation must
consume this expanded contract and support arbitrary helper collections.

From the repository root, using the existing pinned environment:

```text
python analysis/rev-g/run_native.py designs/design-envelope/build_envelope.py
```

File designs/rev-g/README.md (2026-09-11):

# Rev G — evolutionary-search research CAD

**The genetic study is complete. No tested finalist demonstrates the requested
4× fracture margin.** These files are research artifacts, not a qualified print
recommendation. E13 remains the [established prototype handoff](../closed-wall-e13/README.md),
with its existing physical-validation limits.

Actual Rev G finished CAD

The displayed body is the full-plane search finalist
`213f8c56151ddee40d51`. It preserves E13's exterior, seats, fingers, screw lands
and driver access. Its two angular windows use 0.9 of the Rev F window scale.
The body envelope remains approximately 207.51 × 219.00 × 24 mm. New window
mouths have 0.6 mm insets at 50°; the existing exterior finish is unchanged.
[Independent delivered-STEP comparisons](geometry-verification.json).

## Research downloads

| File | Contents |
|---|---|
| [Model and three modifiers](rev-g-model-and-modifiers.3mf) | Geometry-only multipart 3MF with modifier roles and per-object process overrides |
| [Body and three helper solids](bracket-with-modifiers.step) | Four aligned, named STEP solids; STEP does not encode slicer settings |
| [Body STEP](body-only.step) · [body STL](body-only.stl) | One printable body, without selection helpers |
| [Dense support helper](dense-chords-and-seats.step) | Chords, seats and fixing-tunnel support |
| [Lower plane](rib-plane-lower.step) · [upper plane](rib-plane-upper.step) | Two separate full internal planes |
| [Exact parameters](selected-layout.json) | Candidate dimensions and nominal process choices |

There are **three modifiers**. Their projecting tabs make selection easier;
the tabs and connecting halo lie outside the printed body. Keep all components
aligned. In a STEP import, convert every helper to a **100% infill modifier**;
only the body is a printable part. The 3MF already encodes those roles.

The supplied 3MF contains no machine or filament profile and no G-code. It
truthfully identifies its geometry packager, avoiding the incomplete native
project metadata that caused the earlier Orca CLI crash. A local neutral
OrcaSlicer 2.4.2 audit supplies separate temporary presets. It is not a
calibrated process for a particular printer or material.

Sections through actual delivered modifier meshes

## Actual slicing result

The full-plane finalist uses one nominal wall, 1.0 mm broad skins, two 1.0 mm
internal planes at Z = 7.8–8.8 and 15.2–16.2 mm, and 5% sparse infill. The
dense helper uses 100% rectilinear infill. The neutral audit uses 0.2 mm layers,
Arachne walls and gap fill everywhere.

It emits **83.68 cm³ / 103.76 g per bracket** at the shared neutral density
of 1.24 g/cm³: **37.91% less plastic than E13's 167.11 g** reference slice.
All 120 layers are present; three modifier roles survive the Orca round trip;
maximum vertex error is below 0.0001 mm. No selection-tab or window extrusion
is detected. Minimum sampled structural coverage is 99.73%, and minimum dense
helper coverage is 98.73%, using the documented 0.03 mm footprint allowance.
[Toolpath audit](toolpath-verification.json) · [3MF/input hashes](3mf-verification.json)
· [Helper solids and STL checks](helper-verification.json).

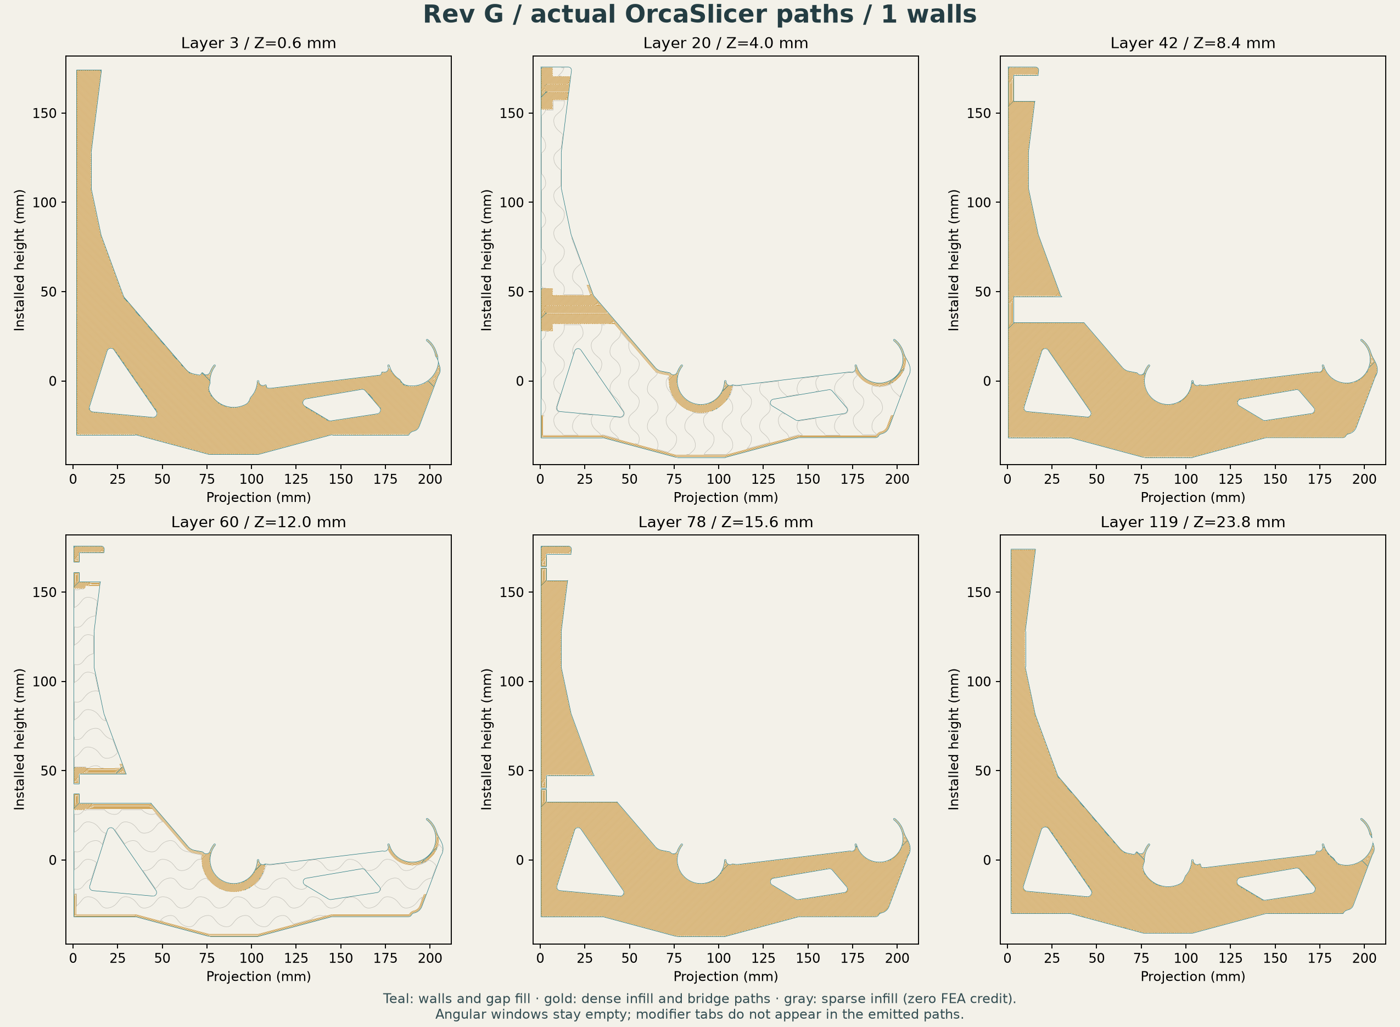
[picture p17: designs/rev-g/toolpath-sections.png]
Actual emitted Orca paths


These checks concern nominal emitted bead footprints. They do not prove bridge
formation, bonding, extrusion quality, fit, creep or strength in a physical part.
Sparse infill receives zero stiffness credit in the mechanical model.

## Mechanical status and alternatives

The full-plane candidate's h1 model gives 3.246 mm front vertical movement and
3.306 mm maximum mean seat translation at E = 1 GPa and the 12 kg reference
load. Its raw maximum tensile principal stress is **55.05 MPa**, above the
10.125 MPa screening limit. The peak rises and changes location with mesh
refinement; no converged fracture margin is established.

The [mechanical report](../../analysis/rev-g/README.md) retains all finite
fields, mesh audits, buckling results and rejected constraints. The current
download is the lowest-mass finalist from the completed full-plane search,
not an accepted optimum.

| Saved study | Actual mass | Outcome |
|---|---:|---|
| [Seed 1 thin shaped planes](studies/seed1-best/README.md) | 84.35 g | Movement, fracture and dense-footprint failures |
| [Full-plane search finalist](studies/full-plane-best/README.md) | 103.76 g | Toolpaths pass; fracture screen fails on all three meshes |
| [Wider inner-seat support](studies/seat-support/README.md) | 108.03 g | Movement improves; coarse fracture screen still fails |
| [Repaired F light helper](studies/repaired-f-light/README.md) | 93.76 g | Export and slicing repaired; original F strength failure remains |

## Reproduce

Use the [analysis requirements](../../analysis/e13/requirements.txt). From the
repository root, with `python` referring to that environment:

```text
python analysis/rev-g/run_native.py designs/rev-g/build_body.py
python analysis/rev-g/run_native.py designs/rev-g/repair_stl.py
python analysis/rev-g/run_native.py designs/rev-g/build_helpers.py
python designs/rev-g/package_3mf.py
python designs/rev-g/slice_audit.py /path/to/OrcaSlicer
python analysis/rev-g/run_native.py designs/rev-g/inspect_toolpaths.py
python analysis/rev-g/run_native.py designs/rev-g/verify_geometry.py
```

CAD/helper/packaging scripts accept the candidate folders used in the studies;
the body builder accepts a parameter JSON followed by its output folder. Run
Orca in its installed environment. The native worker preserves failure exit
codes and flushes outputs before process teardown; it does not turn failures
into successful builds. Regeneration can change tessellation bytes, so rerun
the linked audits after any rebuild.

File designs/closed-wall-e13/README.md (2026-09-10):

# E13 — angular inner-seat reinforcement

**[Download STEP with aligned helpers](bracket-with-modifier-helpers.step)** ·
[Current guide](../../README.md) · [Refined FEA](../../analysis/e13/RESULTS.md)

Finished E13 CAD

Added underside depth is **11 mm**, 1.5 mm more than E12 and below the 12.67 mm
cap. Straight 41 mm horizontal flanks join a 28 mm flat, with small corner
blends. The center section is 30 mm deep; the body is **207.51 × 219 × 24 mm**.
No holes were added. The matched comparisons and local section audit quantify
the improvement without inheriting E11's adjacent-section superiority target.

Outline comparison

Finished section and drawing

The R6 rigid shoulders, fingers, relief pockets and hardware remain. Both
faces have 2 mm chamfer inset, 2.384 mm rise and **50° above the bed**. Actual
STEP probes check the three straight underside segments and both bevel angles.
The four flexible sectors match E10 at nine depths within 0.025 mm STL tolerance.

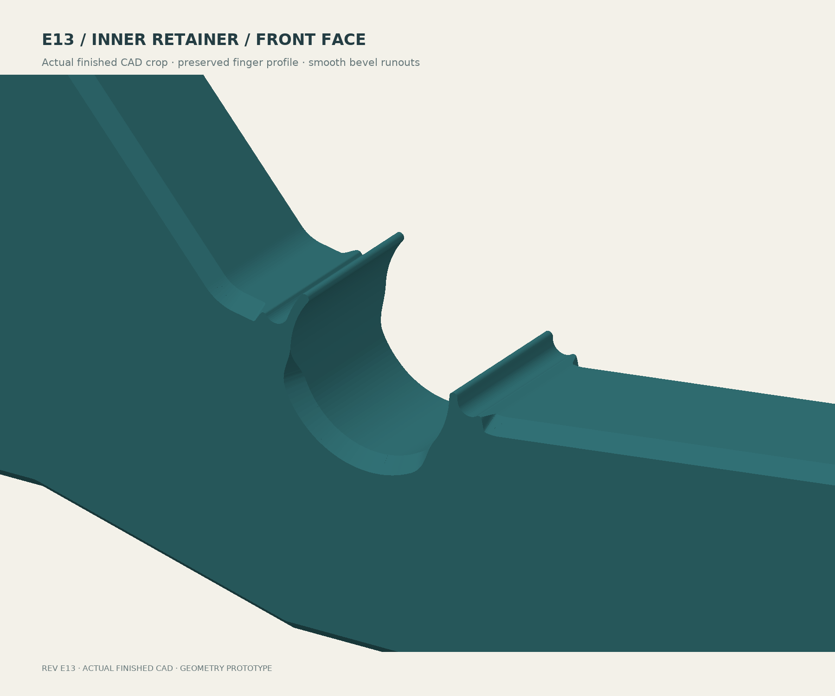
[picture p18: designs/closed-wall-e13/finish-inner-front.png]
Inner-seat finish


[Reverse face](finish-inner-reverse.png) · [Outer front](finish-outer-front.png) ·
[Outer reverse](finish-outer-reverse.png).

The STEP reimports as one valid body and two valid helpers. Closed STLs,
Ø15.8 mm driver, Ø13 mm washer and nominal M5 envelopes pass. The 322-case
nominal spool sweep retains 3.927 mm minimum clearance. Printed rod tolerance,
snap force, fatigue and loaded contact remain untested.

[Build record](build-verification.json) · [STEP/hardware](verification.json) ·
[Angles, straight facets and clearance](engineering-verification.json) ·
[Finger comparison](final-finish-verification.json) · [STL audit](stl-tessellation-check.json) ·
[Sections](section-verification.json).

## Slicing handoff

Import the STEP as **one object with three aligned parts**, broad side down.
Use 8 walls for the PLA prototype or 10 for PETG, 0.2 mm layers, six top/bottom
layers, 15% body infill, **Arachne walls and Everywhere gap fill**. The guide
uses a 0.4 mm nozzle and 0.42/0.45 mm nominal widths. Calibrate the actual filament.

Convert both named helper parts to **100% infill modifiers** at the supplied
Z=7.6–8.8 and 15.2–16.4 mm positions. Their 2 mm overlap is intentional. STEP
does not encode modifier status. Do not fuse or print the helpers as extra slabs.

Four solid bands

If components are lost during import, use [body-only.stl](body-only.stl),
[helper-1.stl](helper-1.stl) and [helper-2.stl](helper-2.stl) as aligned parts.
`body-mounted.stl` uses installed engineering axes and is not the print fallback.

Actual OrcaSlicer paths

Both 8/10-wall audits pass 120 layers and all 24 solid-band layers, with sampled
full L-planes, walls and fingers. Minimum seat-band/wall/finger coverage is
**99.82% / 99.99% / 99.84%**, with the documented 0.03 mm allowance.
[Settings, coverage and hashes](toolpath-verification.json). Equivalent full-plane
height ranges represent the helpers in the neutral audit. No print was started.

## Rebuild

Use OpenSCAD and [the recorded Python environment](../../analysis/e13/requirements.txt).
From this directory:

```sh
openscad -o profile.svg bracket.scad
python build_step.py
python repair_stl.py
python verify_step.py
python verify_engineering.py
python verify_sections.py
python final_finish_check.py
python render_cpu.py
python draw_engineering.py
python draw_depth_comparison.py
python draw_helpers.py
python slice_audit.py 8 /path/to/orca-slicer
python slice_audit.py 10 /path/to/orca-slicer
python inspect_toolpaths.py
```

Comparisons use preserved E10 finger geometry and E12 section/outline data.
Detached bevel remnants are checked against the intended chamfer before removal;
the STL weld repairs near-coincident exporter vertices without changing STEP.
[FEA reproduction and interpretation](../../analysis/e13/README.md).

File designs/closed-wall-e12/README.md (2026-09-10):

# E12 — quarter-depth inner seat

**[Download STEP with aligned helpers](bracket-with-modifier-helpers.step)** ·
[Current print guide](../../README.md) · [Current FEA](../../analysis/e12/RESULTS.md)

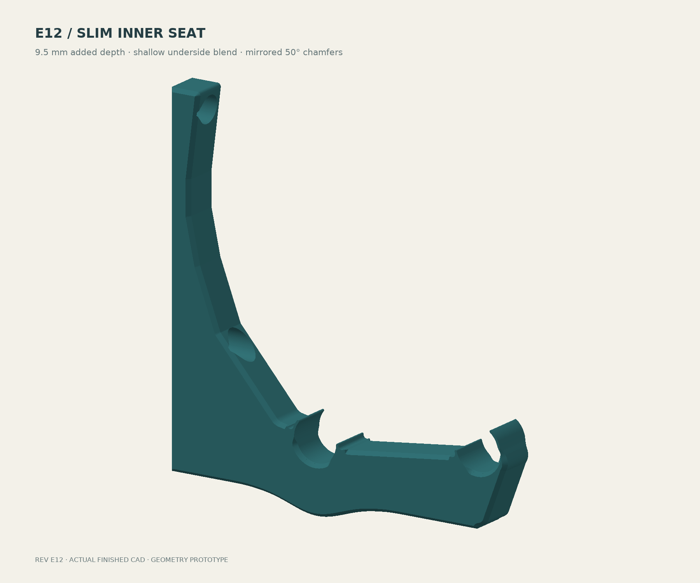
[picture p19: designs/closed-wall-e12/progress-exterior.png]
Finished E12 CAD


The added underside depth is **9.5 mm**, one-quarter of E11's 38 mm and below
the 12.67 mm maximum. It forms a shallow, broader blend. The inner center
section is about 28.5 mm deep; the overall body is **207.51 × 217.50 × 24 mm**.
No strain-relief holes were added. E12 does not inherit E11's claim of exceeding
both adjacent arms; [the section audit](section-verification.json) reports the
lower margin and the improvement over E10.

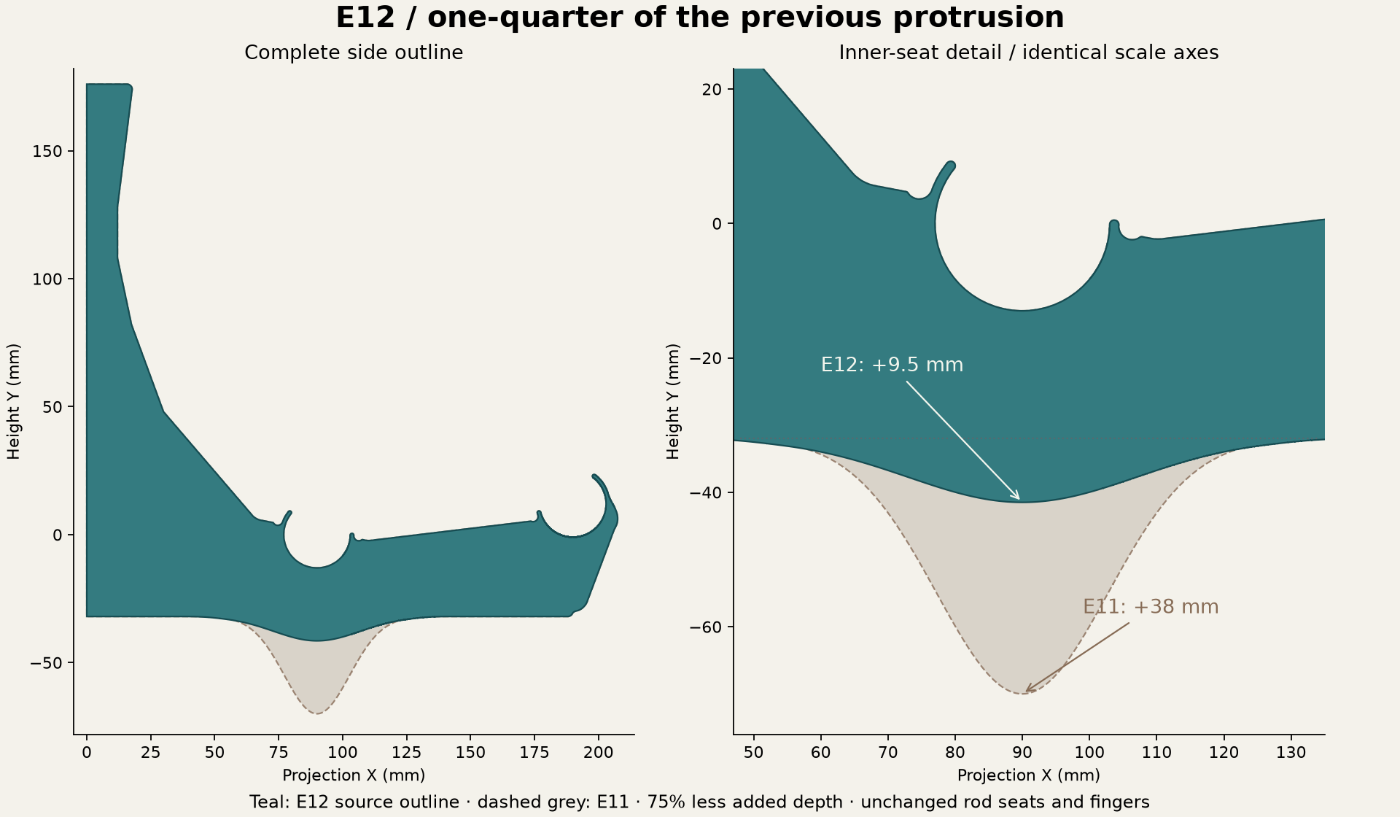
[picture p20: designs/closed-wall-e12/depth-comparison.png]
Depth comparison


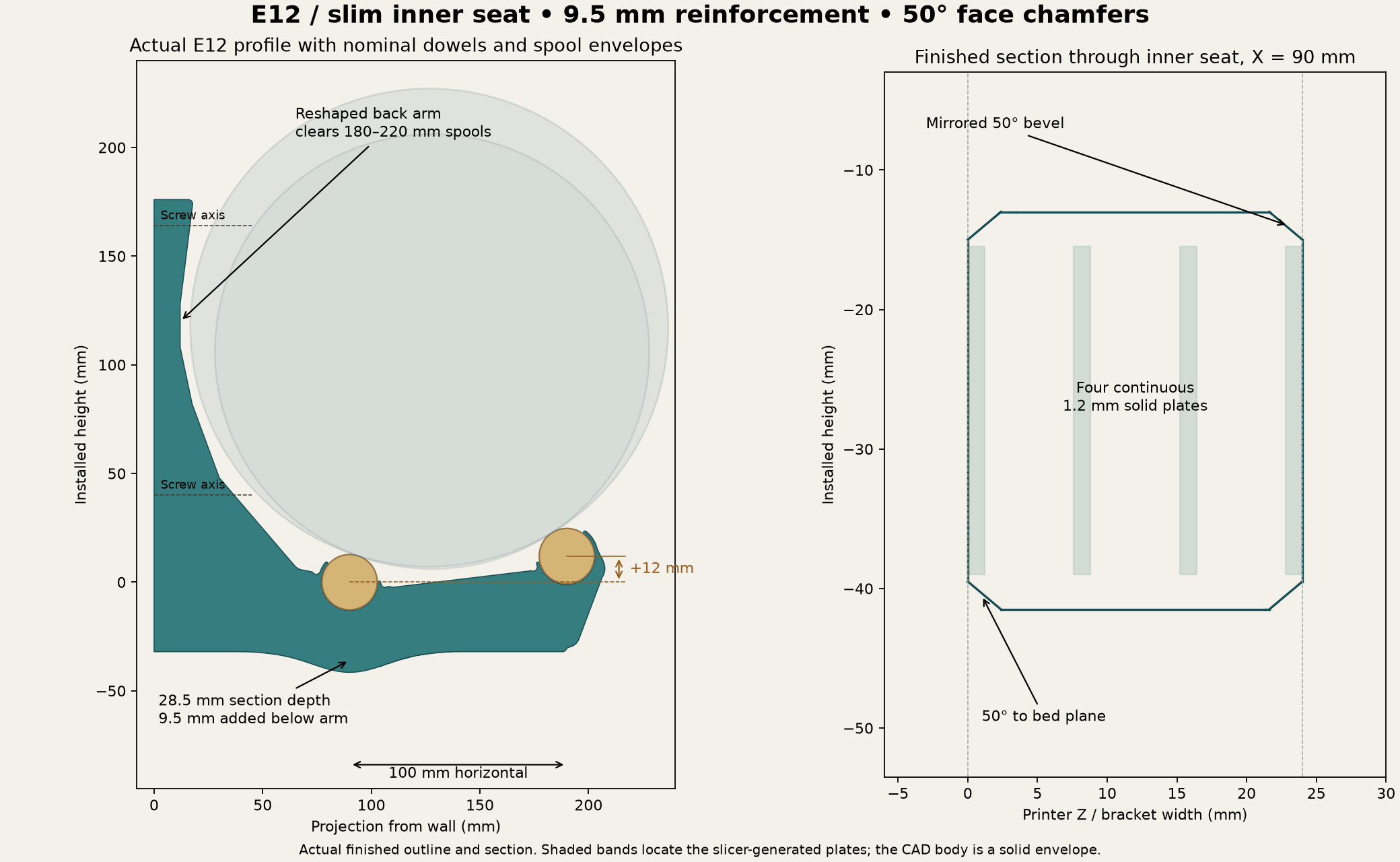
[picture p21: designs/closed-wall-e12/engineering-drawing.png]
Actual outline and finished section


## Finish and validation

The R6 rigid shoulder blends, fingers, relief pockets and hardware are preserved.
The 2 mm face inset has a 2.384 mm rise: **50° above the bed on both faces**.
Runouts remain limited to the thin retainers. The four flexible sectors match
E10 at nine depths within the documented 0.025 mm STL tolerance.

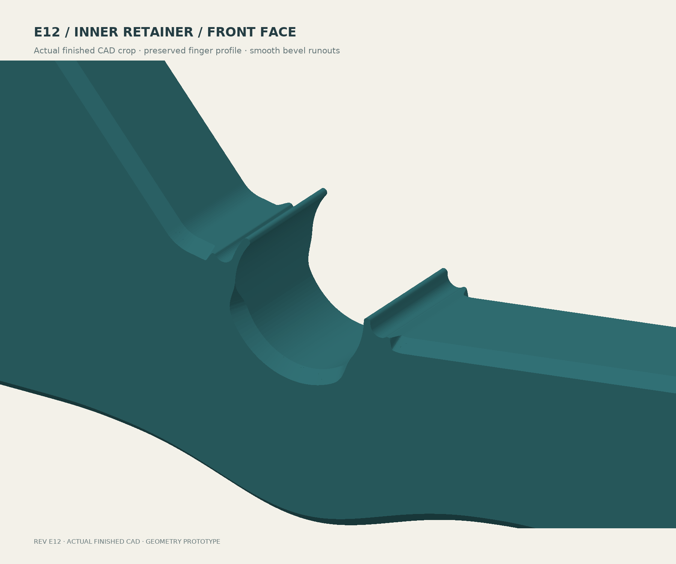
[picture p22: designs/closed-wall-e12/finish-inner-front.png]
Inner-seat finish


[Inner reverse](finish-inner-reverse.png) · [Outer front](finish-outer-front.png) ·
[Outer reverse](finish-outer-reverse.png).

The STEP reimports as one valid body and two valid helpers. Closed STLs,
Ø15.8 mm driver, Ø13 mm washer and nominal M5-shank envelopes pass. The 322-case
180–220 mm nominal spool sweep retains 3.927 mm minimum clearance. Physical
rod tolerance, snap force, fatigue and loaded contact remain untested.

[Build record](build-verification.json) · [STEP/hardware checks](verification.json) ·
[Angles and clearance](engineering-verification.json) · [Complete finger comparison](final-finish-verification.json) ·
[Tessellation audit](stl-tessellation-check.json) · [Section-property plots](section-comparison.png).

## Slicing handoff

Import the STEP as **one object with three aligned parts**, broad side down.
Set the body to 8 walls for the PLA prototype or 10 for PETG, using the guide's
0.4 mm nozzle / 0.42 and 0.45 mm nominal widths. Use 0.2 mm layers including the
first, six top/bottom layers, 15% body infill, **Arachne walls and Everywhere
gap fill**. These are working assumptions, not a calibrated filament profile.

Convert both named helper parts to **100% infill modifiers**, at their supplied
Z=7.6–8.8 and 15.2–16.4 mm positions. Their 2 mm overlap outside the body is
intentional. Do not fuse them or print them as extra slabs. STEP does not store
modifier status or slicer settings.

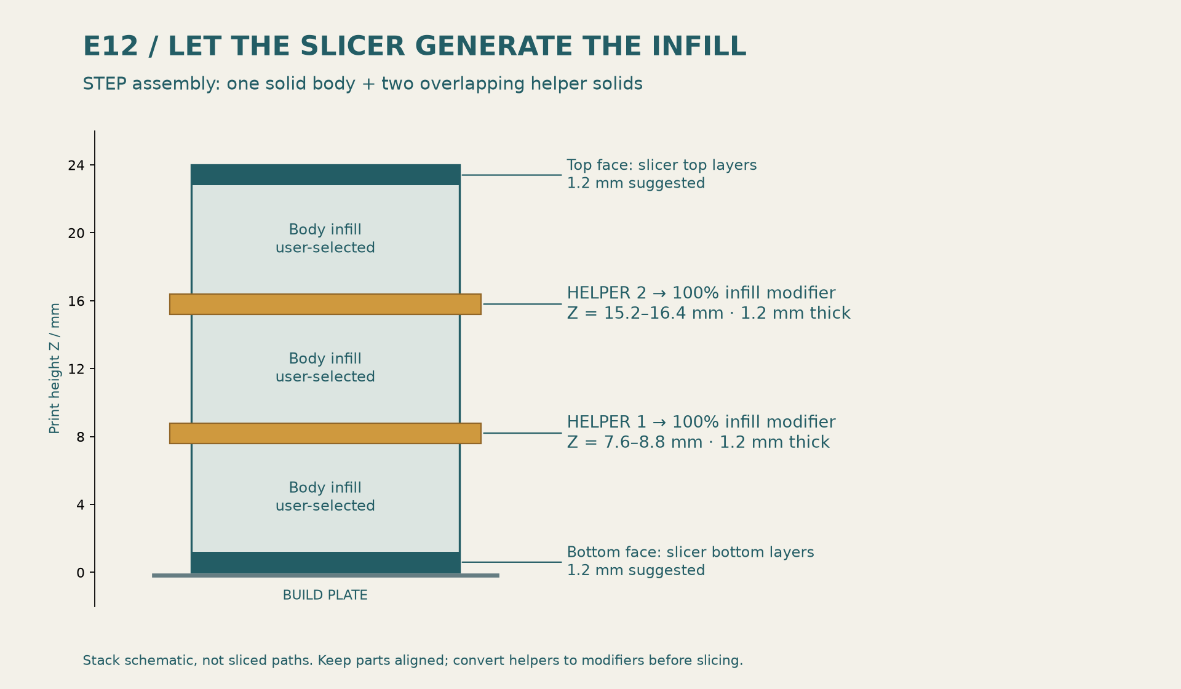
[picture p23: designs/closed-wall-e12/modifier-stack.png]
Solid-band locations


If the importer loses components, use [body-only.stl](body-only.stl),
[helper-1.stl](helper-1.stl) and [helper-2.stl](helper-2.stl) as aligned parts.
`body-mounted.stl` uses installed engineering axes and is not the print fallback.

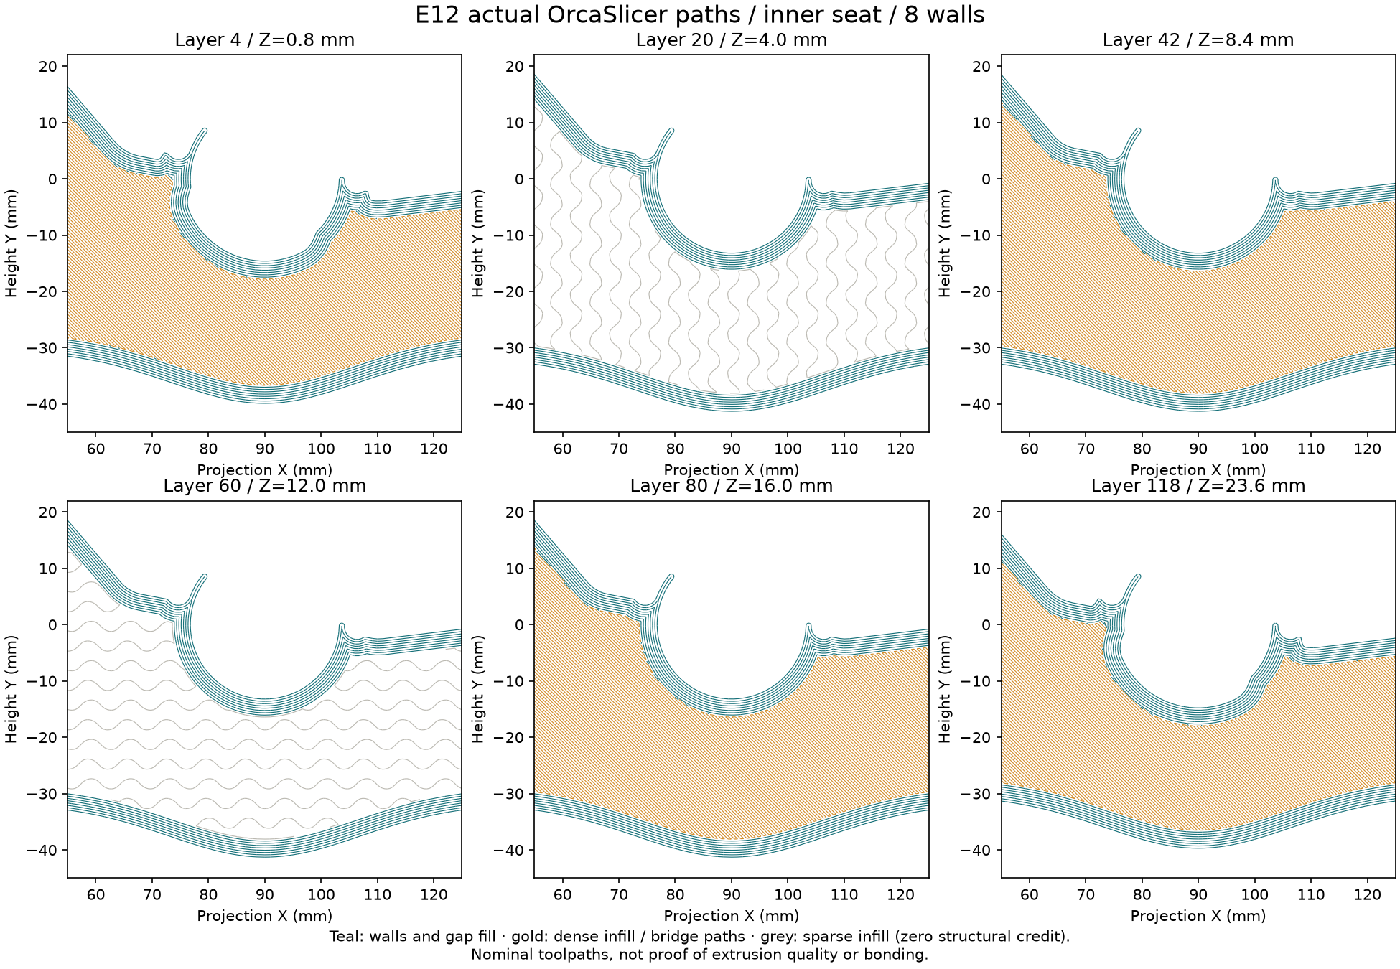
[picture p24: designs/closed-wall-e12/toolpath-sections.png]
Actual OrcaSlicer paths


Both 8/10-wall audits pass 120 layers, all 24 intended solid-band layers around
the seat, and sampled full L-planes, walls and fingers.
[Coverage, settings and source hashes](toolpath-verification.json).
The audit represents the full-plane helpers with equivalent height ranges;
it checks material paths, not a particular STEP import interaction or bonding.
No printer was connected and no print was started.

## Rebuild

Use OpenSCAD and [the recorded Python environment](../../analysis/e12/requirements.txt).
From this directory:

```sh
openscad -o profile.svg bracket.scad
python build_step.py
python repair_stl.py
python verify_step.py
python verify_engineering.py
python verify_sections.py
python final_finish_check.py
python render_cpu.py
python draw_engineering.py
python draw_depth_comparison.py
python draw_helpers.py
python slice_audit.py 8 /path/to/orca-slicer
python slice_audit.py 10 /path/to/orca-slicer
python inspect_toolpaths.py
```

Comparisons use the preserved E10 STL, E11 source outline and E11 section audit.
The narrowly bounded STL weld repairs exporter near-coincident vertices; it
does not change the STEP. [FEA reproduction and interpretation](../../analysis/e12/README.md).

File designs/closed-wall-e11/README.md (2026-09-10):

# E11 — reinforced inner seat and mirrored 50° finish

**[Download STEP with aligned helpers](bracket-with-modifier-helpers.step)** ·
[Current print guide](../../README.md) · [New E11 FEA](../../analysis/e11/RESULTS.md)

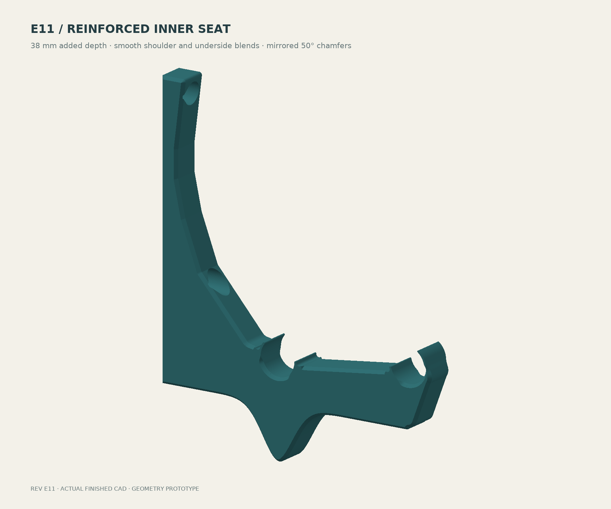
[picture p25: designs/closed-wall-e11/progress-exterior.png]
Finished E11 CAD


The inner seat now has a smooth 38 mm underside reinforcement, approximately
57 mm center section depth and R6 rigid-shoulder blends. The finished ideal
printed section exceeds both adjacent plain-arm reference bands: minimum
bending-I ratios are 1.539 on the wall side and 2.658 on the outer side; minimum
elastic section-modulus ratios are 1.282 and 1.846. These are local geometric
comparisons, not rupture or lifetime ratings.

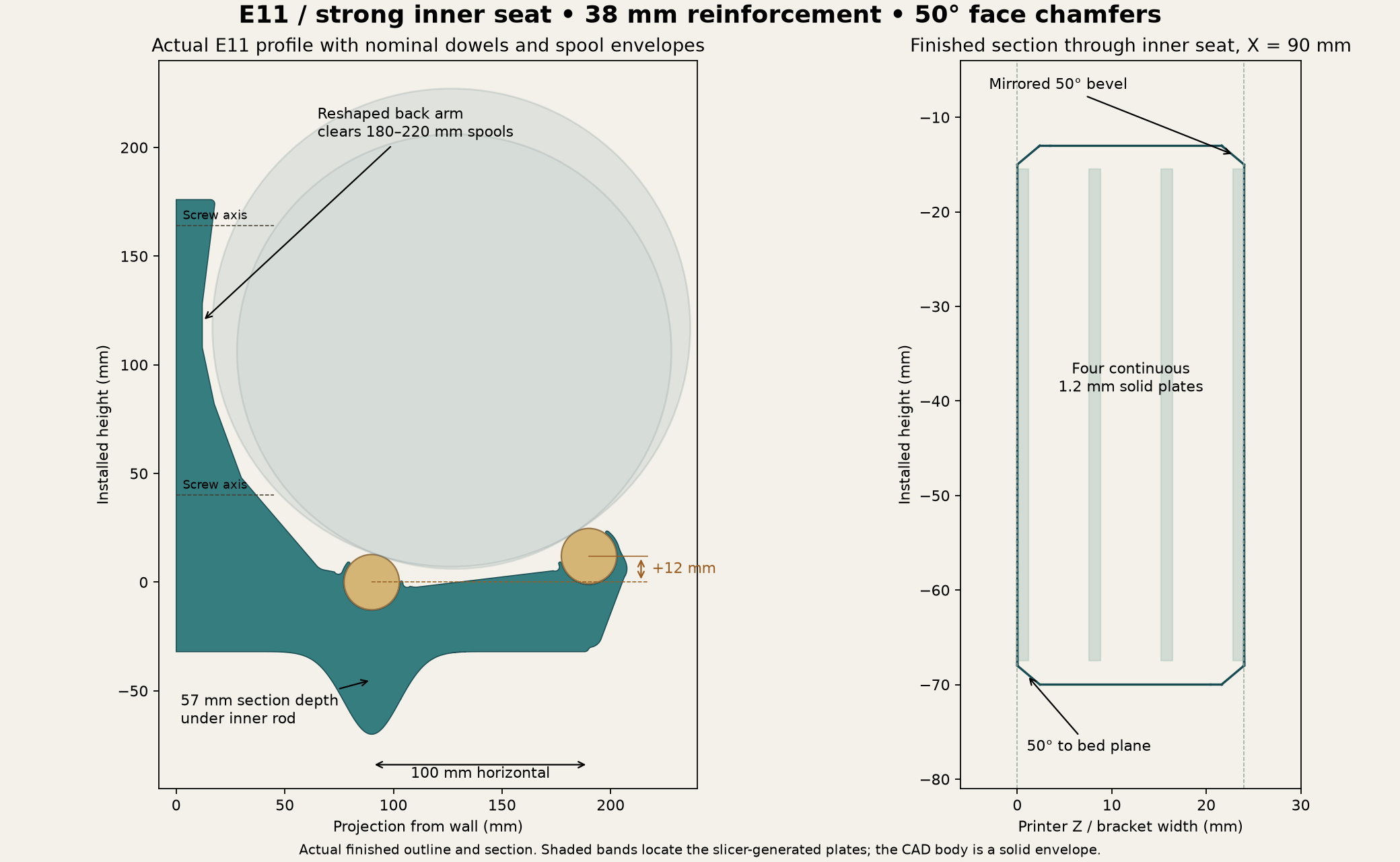
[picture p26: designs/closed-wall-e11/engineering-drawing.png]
Profile and finished inner-seat section


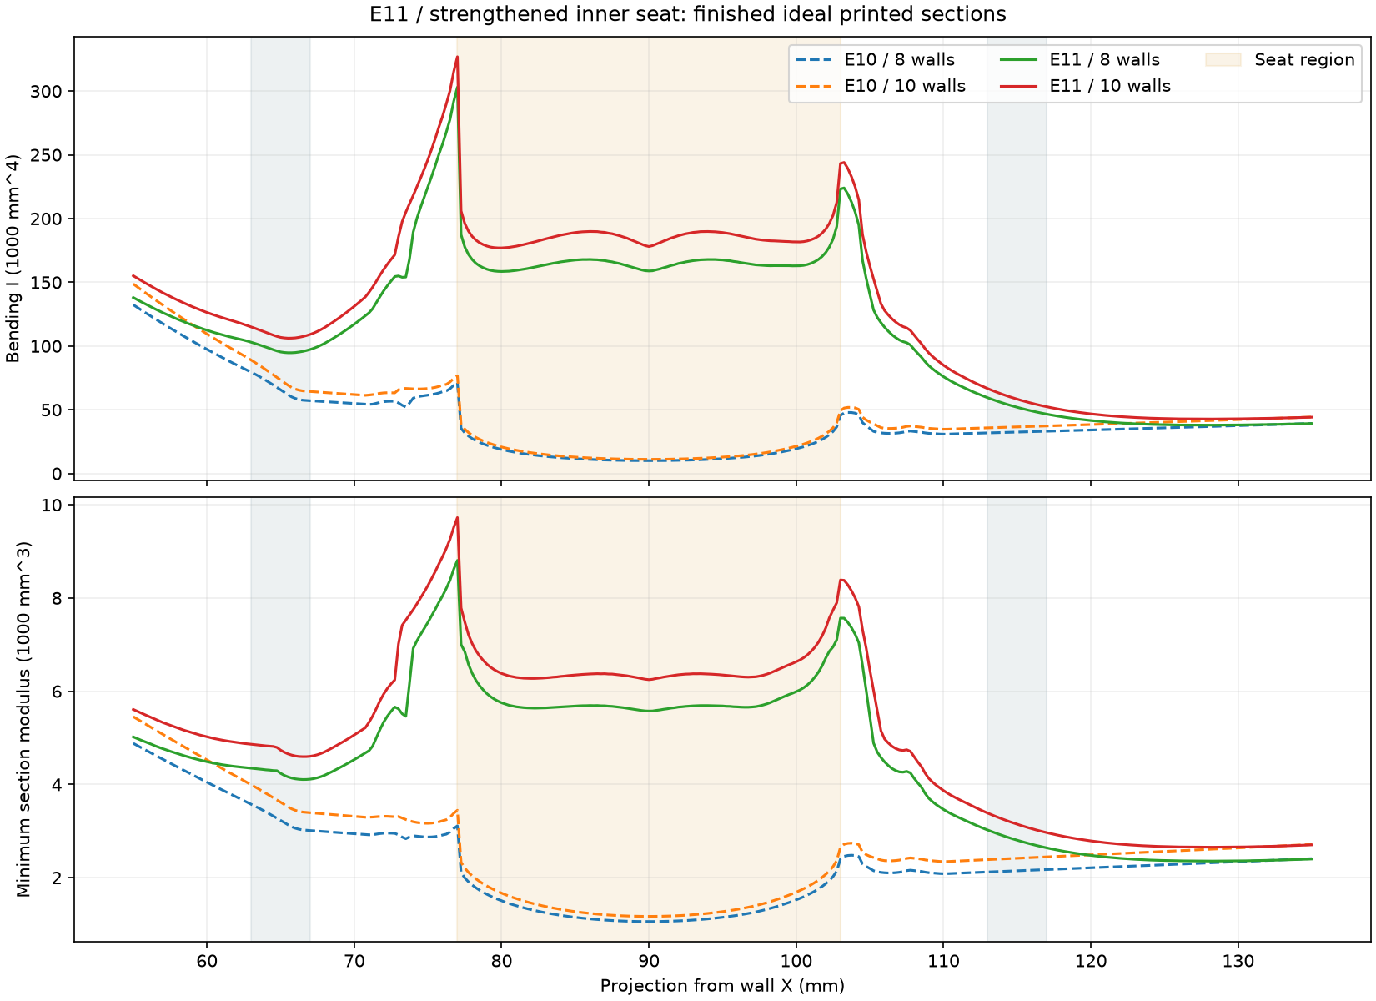
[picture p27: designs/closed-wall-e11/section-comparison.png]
Section-property audit


Both broad faces retain a 2 mm inset and rise 2.384 mm at **50° above the bed**.
Independent STEP material probes measure 50° on each side. Structural corner
blends retain full chamfer depth; the bevel tapers only before thin retainers.
The rear/front centers remain (90,0)/(190,12) mm.

## Finish and fingers

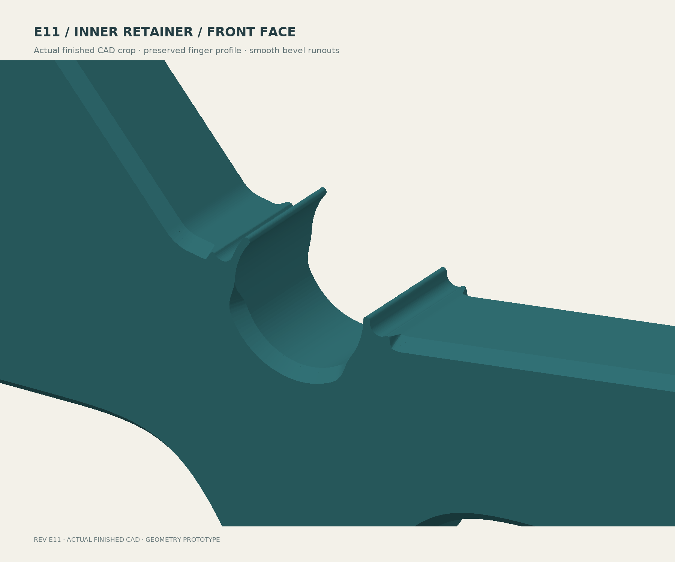
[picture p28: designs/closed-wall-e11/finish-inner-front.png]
Inner-seat finish


[Inner reverse face](finish-inner-reverse.png) ·
[Outer retainer](finish-outer-front.png) · [Outer reverse face](finish-outer-reverse.png).

The four flexible-finger sectors match E10 at nine print depths, within the
documented 0.025 mm STL comparison tolerance. Their functional 1.35 mm nominal
thin sections, rounded noses, relief pockets and root transitions are preserved.
The CAD comparison is independent of the eight material-presence probes in the
finish check. Physical insertion force and retention are not measured.

The 322-case nominal 180–220 mm spool sweep gives 3.927 mm minimum clearance.
The delivered STEP has one valid main body plus two valid helpers. Both driver,
washer and nominal M5 shank envelopes clear; both lands retain their support.

[STEP/hardware checks](verification.json) · [Finish and clearance probes](engineering-verification.json) ·
[Full finger comparison](final-finish-verification.json) · [Build record](build-verification.json).

The STLs are closed single components. Welding exporter-created near-coincident
vertices moves them by at most 0.00005 mm and discards collapsed triangles; it
does not modify the STEP. [Tessellation audit](stl-tessellation-check.json).

## Slicing

Import as **one object with three aligned parts**. The main CAD body is a solid
envelope for slicing, not an instruction to print it at 100%.

| Setting | Working value |
|---|---|
| Orientation | Supplied broad side down |
| Body envelope | 207.51 × 246.00 × 24 mm; check bed exclusions |
| Layer / first layer | 0.20 / 0.20 mm |
| Body walls | PLA 8 / PETG 10 as prototype starting points |
| Reference nozzle and outer/inner line widths | 0.4 mm; 0.42 / 0.45 mm |
| Wall generator / solid-region gap fill | Arachne / Everywhere |
| Body infill | 15%; zero structural credit |
| Exterior solid faces | 1.2 mm each, six layers |
| Helper bands | Z 7.6–8.8 and 15.2–16.4 mm |
| Helper treatment | Convert each to a **100% infill modifier** |

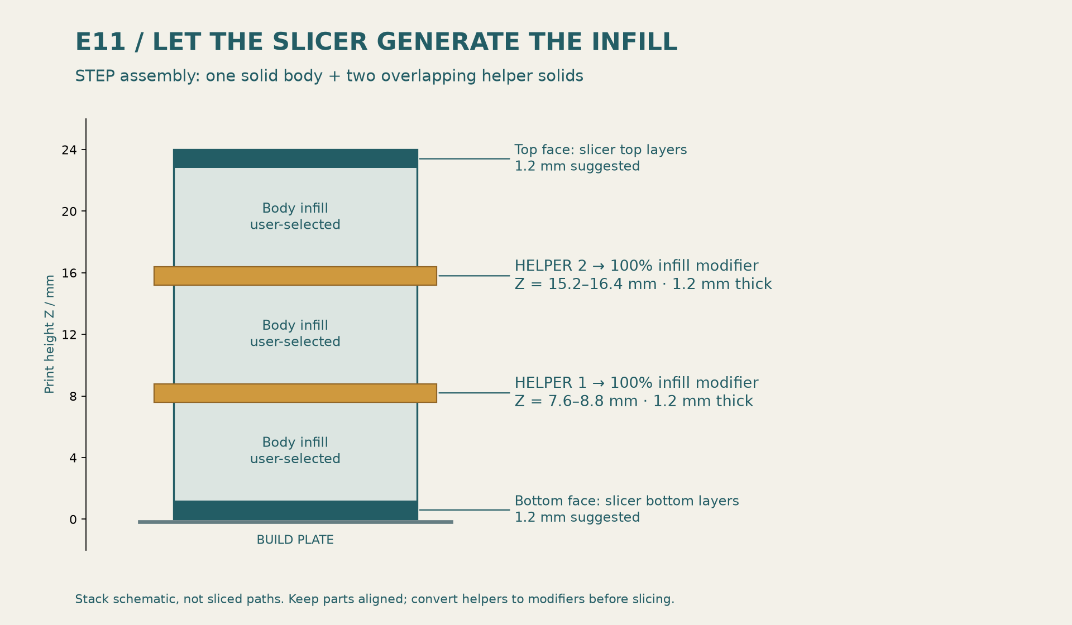
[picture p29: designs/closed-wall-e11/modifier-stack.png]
Modifier stack


Keep helpers aligned and do not print them as separate exterior slabs. STEP
does not store modifier status, wall count or filament settings. The helpers
extend 2 mm past the body bounds; this overlap is intentional.

If the STEP importer cannot preserve components, import these as aligned parts:
[body-only.stl](body-only.stl), [helper-1.stl](helper-1.stl), [helper-2.stl](helper-2.stl).
`body-mounted.stl` uses installed engineering axes and is not the oriented print fallback.

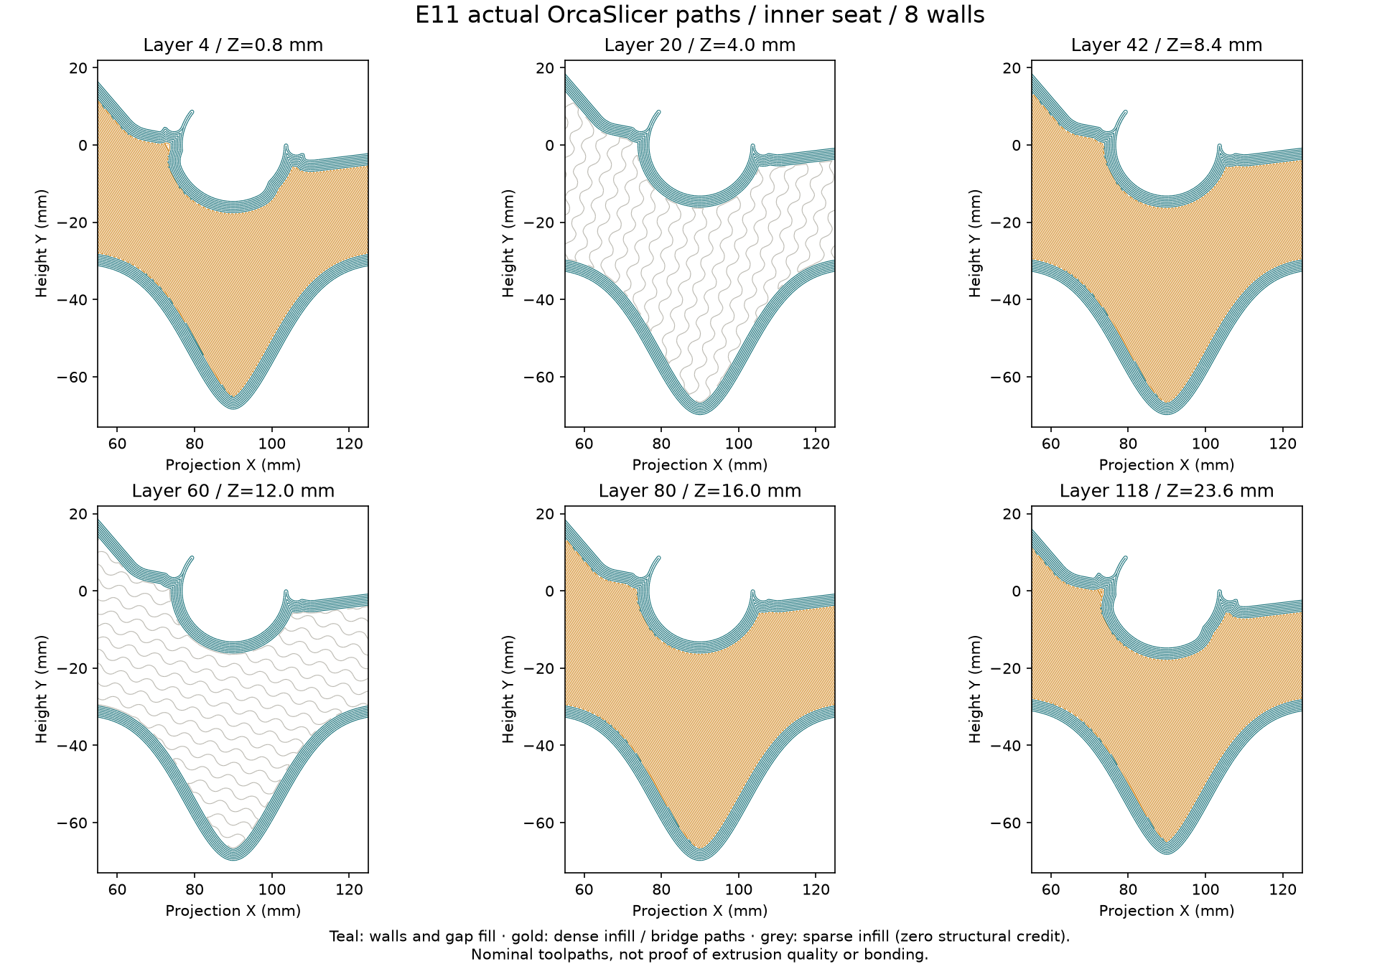
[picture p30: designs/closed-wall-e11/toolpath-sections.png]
Actual OrcaSlicer layers


Actual OrcaSlicer 2.4.2 8/10-wall audits pass with 120 layers. The 24 intended
solid-band layers pass the inner-seat footprint test; the sampled full L-planes
and seat walls also pass. The minimum seat-band footprint coverage is 99.79%,
with a documented 0.03 mm rounding/tessellation allowance.
Sampled flexible-finger coverage exceeds 99.84%. Arachne variable-width walls
fill the small nose pocket found in the initial classic-wall audit, preserving
the delivered CAD. Solid-region gap fill is set to Everywhere; see
[Orca's setting documentation](https://github.com/OrcaSlicer/OrcaSlicer_WIKI/blob/main/print_settings/strength/strength_settings_infill.md).
[Numerical toolpath evidence](toolpath-verification.json).

The audit uses equivalent whole-object height ranges for the two full-plane
helpers. It verifies the intended material paths, not a particular STEP-importer
interaction. Neutral audit profiles/G-code stay local and are not calibrated
print deliverables. Use the intended grade's temperature, cooling and flow;
inspect actual band support, bonding, access roofs and fingers before printing.

## Rebuild and verify

Use OpenSCAD and the Python packages in [the analysis environment](../../analysis/e11/requirements.txt).
From this directory:

```sh
openscad -o profile.svg -D 'part="profile"' bracket.scad
python build_step.py
python repair_stl.py
python verify_step.py
python verify_engineering.py
python verify_sections.py
python final_finish_check.py
python render_cpu.py
python draw_engineering.py
python draw_helpers.py
python slice_audit.py 8 /path/to/orca-slicer
python slice_audit.py 10 /path/to/orca-slicer
python inspect_toolpaths.py
```

Section and finger comparisons require the preserved E10 mounted STL.
`repair_stl.py` is a narrowly bounded tessellation repair, not a CAD repair.
The build copies shapes before meshing and verifies the delivered STEP on reimport.

The new [E11 numerical report](../../analysis/e11/RESULTS.md) includes matched
E10/E11 reduced models, 8/10-wall 3D refinement, washer-compression refinement,
updated material coefficients and explicit creep sensitivities. Exact rod fit,
printing, snap behavior and sustained/hot load qualification remain unperformed.

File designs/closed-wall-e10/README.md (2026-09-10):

# E10 — running prototype with front rail raised 12 mm

**[Download the STEP assembly](bracket-with-modifier-helpers.step)** — one solid CAD body and two aligned 1.2 mm helper solids. Import as aligned parts of one object, then convert the helpers to 100% infill modifiers.

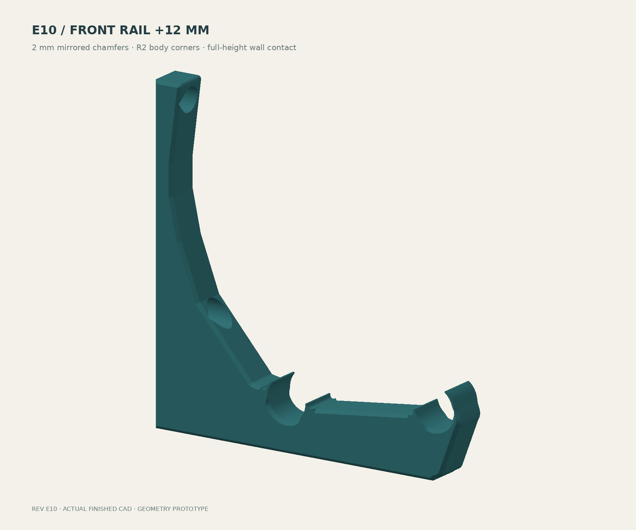
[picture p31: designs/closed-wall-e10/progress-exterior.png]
Current finished CAD


## Geometry changes

- Rear / front rail centers: (90, 0) and (190, 12) mm in installed side coordinates.
- Both broad faces use **2 mm chamfers**, mirrored about the bracket width midpoint. Chamfers stay at full depth through structural corner blends and taper only at the thin retainer regions. Side-profile fillets are formed first; face chamfers follow.
- Exposed body facets join with **nominal R2 fillets**. Snap noses keep their smaller functional radii; the wall-contact strip retains square end contact corners.
- Reshaped the back arm inward to clear the rearward-shifted spool while keeping full-height wall contact. The tight middle portion is 12 mm deep in projection.
- Reoriented both retainers to the raised-rail spool contact directions. The rigid bearing sectors oppose the contact points and the spool tracks remain exposed.
- Carried the raised front-seat buttress down to the original arm base, eliminating the disconnected-looking bottom stub. The underside stays at Y = −32 mm; the front region gains depth.
- Retained 3.6 mm screw landings, Ø5.2 mm shank clearance and Ø16 mm nominal access, with axes at Y = 164 and 40 mm.

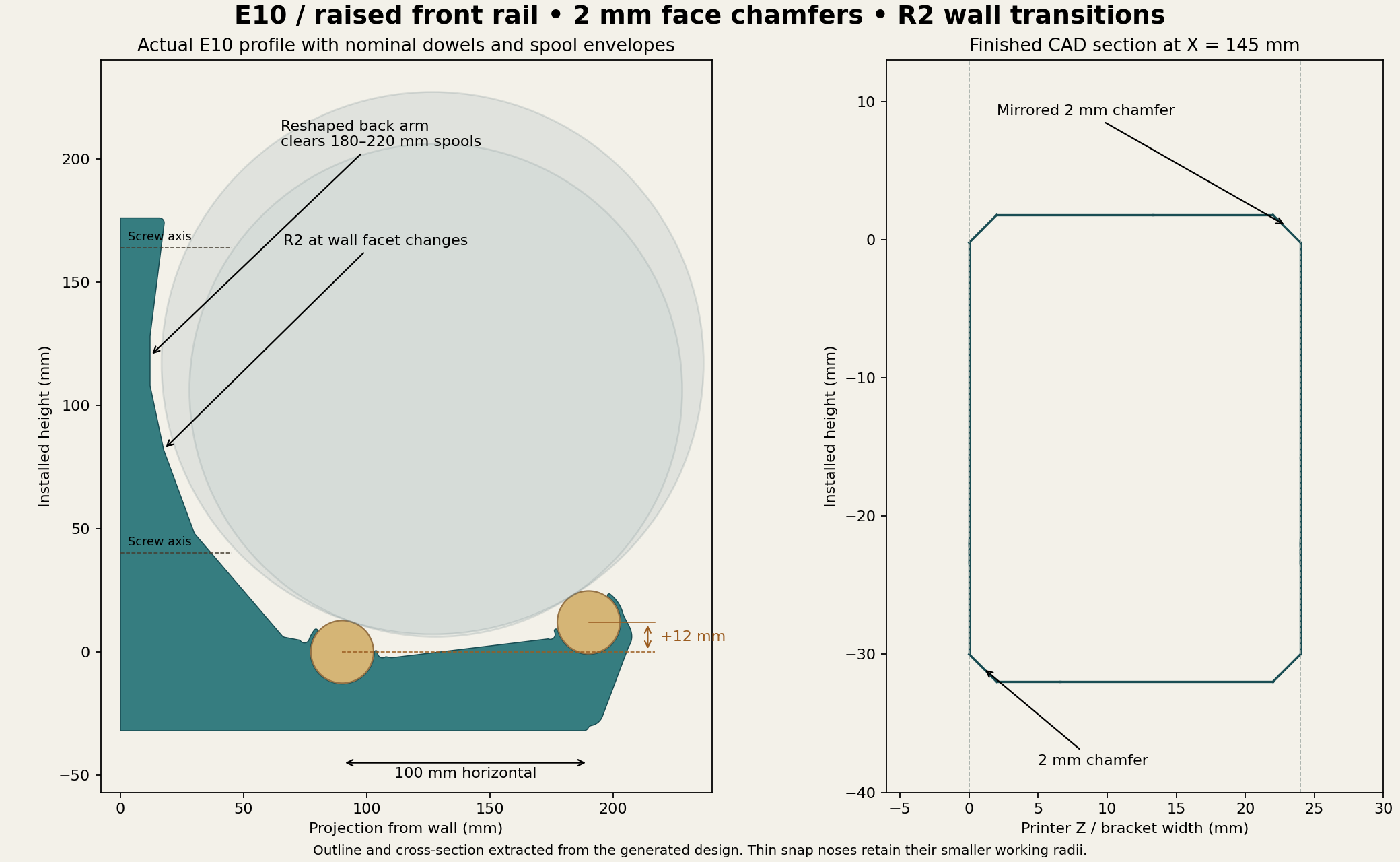
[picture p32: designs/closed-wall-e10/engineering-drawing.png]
Profile and finished chamfer section


## Geometry verification

The STEP roundtrip contains three valid solids. Body and helper STLs pass edge-closure checks. Ø15.8 mm straight driver, Ø13 mm washer and M5 nominal-shank envelope checks pass at both fixings.

The nominal 180–220 mm flange sweep, including the seat-clearance radius sensitivity, has **3.93 mm minimum clearance** over 322 evaluated cases. The finish verification samples full-depth segments around the structural outline, including the pre-existing corner blends, on both faces. Sampled body-facet arcs deviate from the nominal R2 construction by less than 0.001 mm in the exported profile; the STEP profile simplification tolerance is 0.005 mm.

The check includes 726 material probes over 121 full-depth outline segments and eight near-face probes confirming the thin fingers retain material. Both coupons preserve the full 24 mm width. The STEP remains a valid CAD solid; the STL cleanup closes four microscopic tessellation triangles without modifying the STEP. [Tessellation audit](stl-tessellation-check.json).

[Finished geometry checks](engineering-verification.json) · [STEP/helper/hardware checks](verification.json) · [Chamfer edge specification](finish-specification.json).

## Print setup

| Setting | Prototype value |
|---|---|
| Orientation | Supplied broad side down; do not separate or auto-arrange helper parts |
| Layers | 0.20 mm, including first layer for band alignment |
| Body infill | 15%; zero structural credit in analysis |
| Exterior solid faces | 1.2 mm top and 1.2 mm bottom, six layers each |
| Helper bands | Z 7.6–8.8 and 15.2–16.4 mm, each set as a **100% infill modifier** |
| Walls | PLA 8 / PETG 10 as prototype starting points; inspect actual toolpaths |
| Wall-count reference | 0.4 mm nozzle, 0.42 / 0.45 mm assumed outer / inner widths |
| Filament process | Exact manufacturer's grade profile, with verified flow and bonding |

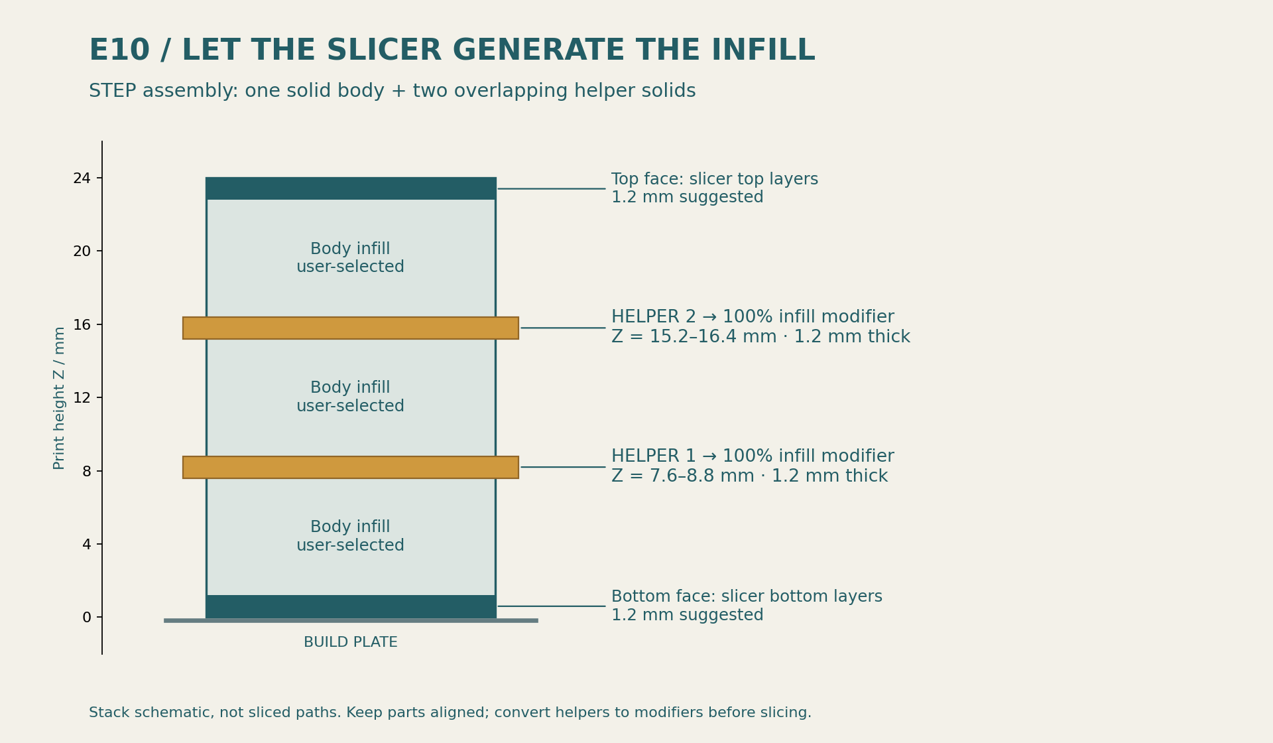
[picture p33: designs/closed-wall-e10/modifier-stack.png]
Modifier positions


STEP stores geometry and alignment, not slicer settings. The helpers must not become separately printed slabs. Inspect all four solid bands, perimeters under the rear seat, full screw-landing material and printable access roofs. The main CAD body is solid so the slicer can generate the selected infill.

If STEP components do not import correctly, use [body-only.stl](body-only.stl), [helper-1.stl](helper-1.stl) and [helper-2.stl](helper-2.stl) as aligned parts of one object.

## Engineering status

E10 is the running geometry prototype. The [E9 FEM and creep guide](../../analysis/e9/RESULTS.md) is a prior-finish baseline; the changed chamfers have not been re-solved as E10. No physical rod fit or creep qualification has been performed.

The nominal 26.0 mm seat is provisional. See the [dowel source check and fit coupons](../../fit/README.md). A published 1-inch catalog diameter does not establish a minimum/maximum production tolerance.

Serviceability criteria remain **5 mm total movement at full load and 1 mm change per full spool added or removed**. The 12 kg equivalent per-bracket case and 85°F sustained / 100°F for six hours per year remain analysis targets, not a released load rating.

## Rebuild

From this directory, with OpenSCAD and the Python CAD dependencies:

```sh
openscad -o profile.svg -D 'part="profile"' bracket.scad
python build_step.py
python repair_stl.py
python verify_step.py
python verify_engineering.py
python render_cpu.py
python draw_engineering.py
python draw_helpers.py
```

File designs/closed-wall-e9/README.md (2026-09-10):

# E9 — running prototype with front rail raised 12 mm

**[Download the STEP assembly](bracket-with-modifier-helpers.step)** — one solid CAD body and two aligned 1.2 mm helper solids. Import as aligned parts of one object, then convert the helpers to 100% infill modifiers.

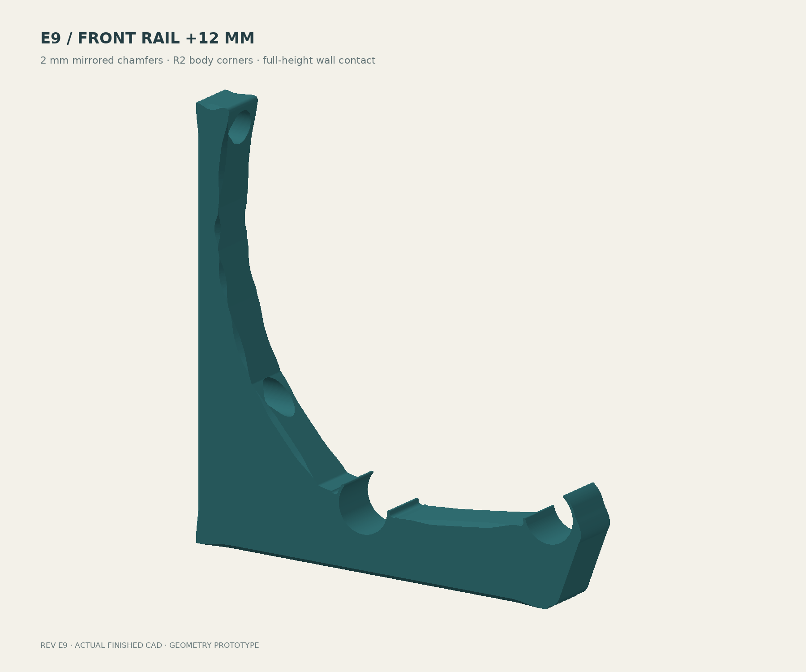
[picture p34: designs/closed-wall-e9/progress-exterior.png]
Current finished CAD


## Geometry changes

- Rear / front rail centers: (90, 0) and (190, 12) mm in installed side coordinates.
- Both broad faces use **2 mm chamfers**, mirrored about the bracket width midpoint. Chamfers fade out before retainers and wall-corner blends.
- Exposed body facets join with **nominal R2 fillets**. Snap noses keep their smaller functional radii; the wall-contact strip retains square end contact corners.
- Reshaped the back arm inward to clear the rearward-shifted spool while keeping full-height wall contact. The tight middle portion is 12 mm deep in projection.
- Reoriented both retainers to the raised-rail spool contact directions. The rigid bearing sectors oppose the contact points and the spool tracks remain exposed.
- Carried the raised front-seat buttress down to the original arm base, eliminating the disconnected-looking bottom stub. The underside stays at Y = −32 mm; the front region gains depth.
- Retained 3.6 mm screw landings, Ø5.2 mm shank clearance and Ø16 mm nominal access, with axes at Y = 164 and 40 mm.

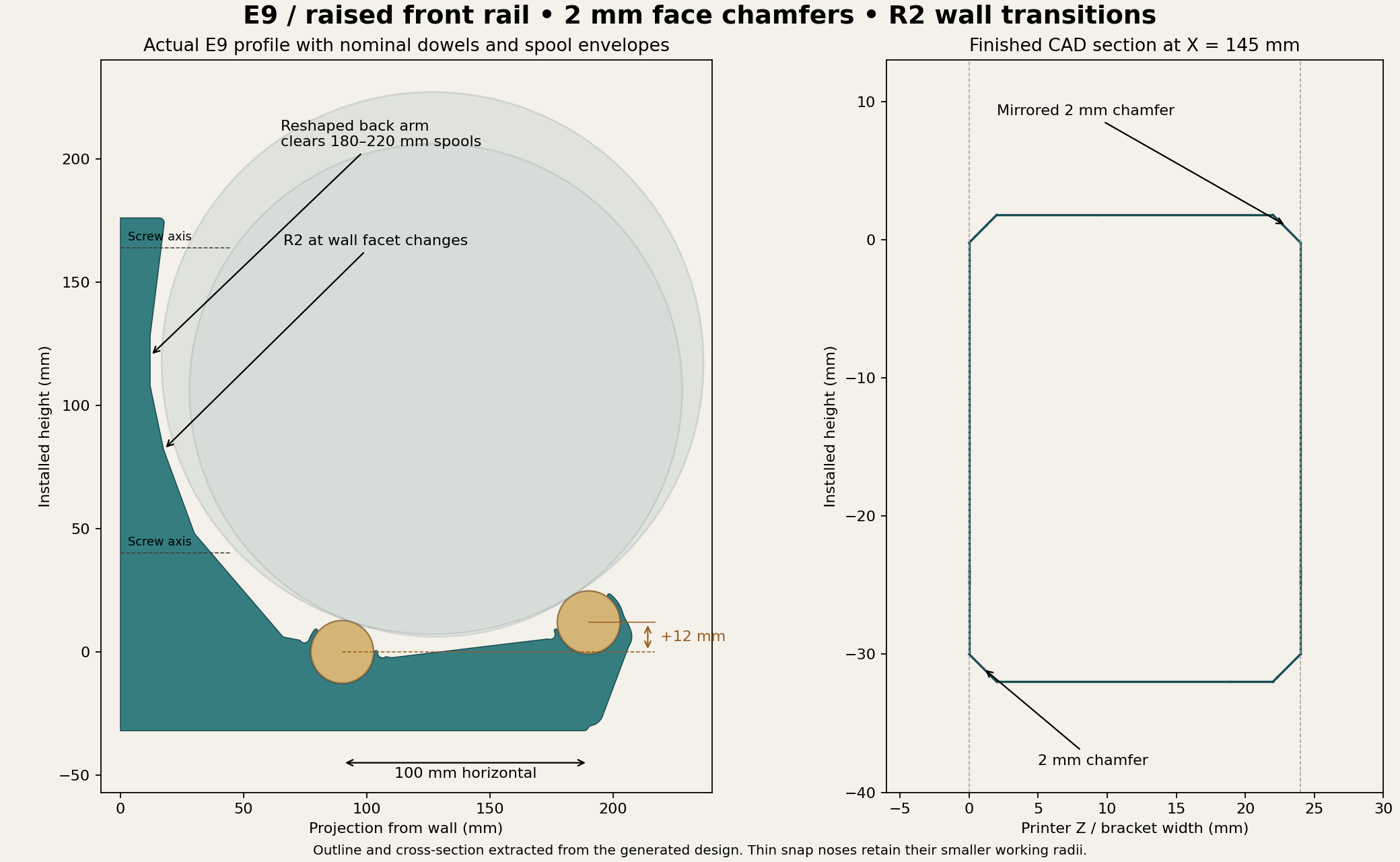
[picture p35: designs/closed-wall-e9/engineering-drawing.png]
Profile and finished chamfer section


## Geometry verification

The STEP roundtrip contains three valid solids. Body and helper STLs pass edge-closure checks. Ø15.8 mm straight driver, Ø13 mm washer and M5 nominal-shank envelope checks pass at both fixings.

The nominal 180–220 mm flange sweep, including the seat-clearance radius sensitivity, has **3.93 mm minimum clearance** over 322 evaluated cases. Material-presence probes confirm the mirrored 2 mm chamfers on nine selected structural edges. Sampled body-facet arcs deviate from the nominal R2 construction by less than 0.001 mm in the exported profile; the STEP profile simplification tolerance is 0.005 mm.

[Finished geometry checks](engineering-verification.json) · [STEP/helper/hardware checks](verification.json) · [Chamfer edge specification](finish-specification.json).

## Print setup

| Setting | Prototype value |
|---|---|
| Orientation | Supplied broad side down; do not separate or auto-arrange helper parts |
| Layers | 0.20 mm, including first layer for band alignment |
| Body infill | 15%; zero structural credit in analysis |
| Exterior solid faces | 1.2 mm top and 1.2 mm bottom, six layers each |
| Helper bands | Z 7.6–8.8 and 15.2–16.4 mm, each set as a **100% infill modifier** |
| Walls | PLA 8 / PETG 10 as prototype starting points; inspect actual toolpaths |
| Wall-count reference | 0.4 mm nozzle, 0.42 / 0.45 mm assumed outer / inner widths |
| Filament process | Exact manufacturer's grade profile, with verified flow and bonding |

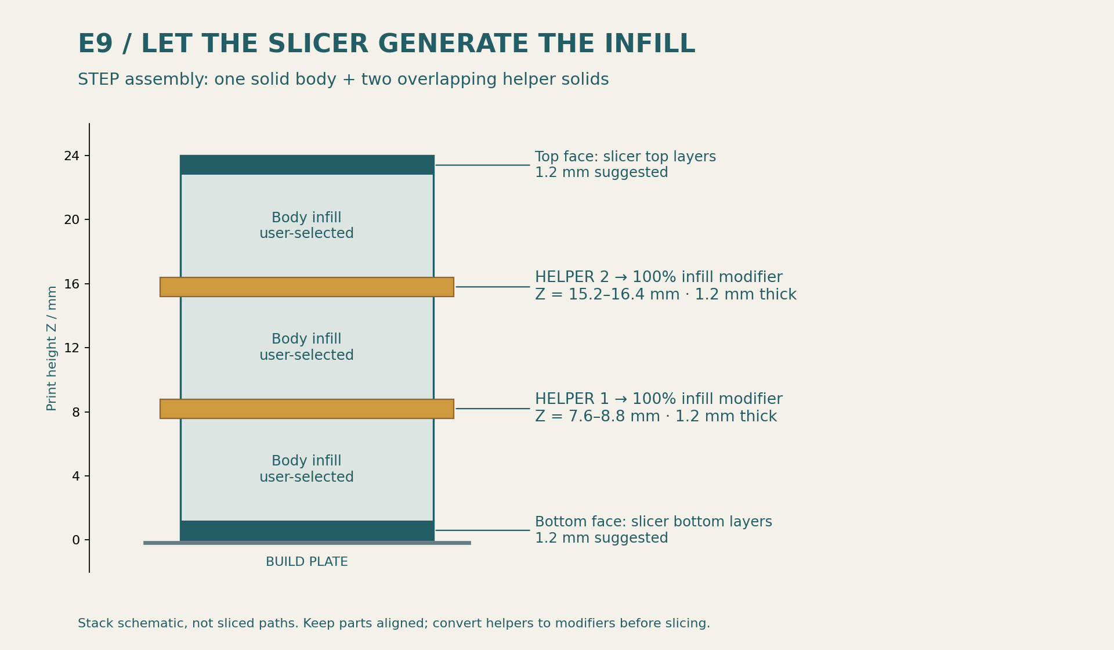
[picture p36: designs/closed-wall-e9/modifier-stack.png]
Modifier positions


STEP stores geometry and alignment, not slicer settings. The helpers must not become separately printed slabs. Inspect all four solid bands, perimeters under the rear seat, full screw-landing material and printable access roofs. The main CAD body is solid so the slicer can generate the selected infill.

If STEP components do not import correctly, use [body-only.stl](body-only.stl), [helper-1.stl](helper-1.stl) and [helper-2.stl](helper-2.stl) as aligned parts of one object.

## Engineering status

E9 is the running prototype. The level-rail E8 FEM and creep guide remain a historical baseline; E9 changes the load split, back arm and finishing geometry, so it does not inherit E8's results. New E9 2D/3D fields, refined 8/10-wall results and a screw-landing submodel are published under [analysis/e9](../../analysis/e9/RESULTS.md). See the [current full engineering guide](../../README.md) for material comparisons and conditional creep margins.

Serviceability criteria remain **5 mm total movement at full load and 1 mm change per full spool added or removed**. The 12 kg equivalent per-bracket case and 85°F sustained / 100°F for six hours per year remain analysis targets, not a released load rating.

## Rebuild

From this directory, with OpenSCAD and the Python CAD dependencies:

```sh
openscad -o profile.svg -D 'part="profile"' bracket.scad
python build_step.py
python verify_step.py
python verify_engineering.py
python render_cpu.py
python draw_engineering.py
python draw_helpers.py
```

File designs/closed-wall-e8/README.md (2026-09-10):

# E8 — solid STEP body with modifier helpers

**[Download the STEP assembly](bracket-with-modifier-helpers.step).** It contains one solid bracket body and two named, overlapping helper solids. The user chooses wall count and infill for the body, then converts the helpers to modifiers set to 100% infill. No infill pattern or support grid is modeled in the CAD.

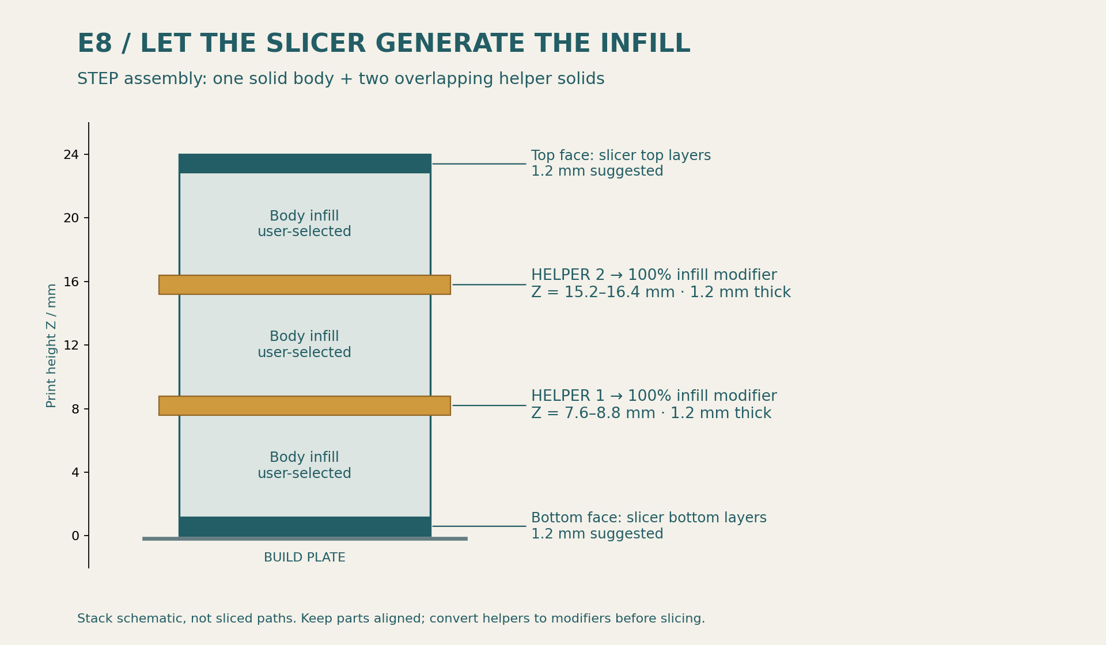
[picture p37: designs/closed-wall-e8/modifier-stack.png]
Modifier locations


**Prototype starting wall counts: PLA 8; PETG 10.** These are test settings, not a verified capacity. See [the thickness mapping and limitations](WALL-COUNTS.md).

## Slicer setup

1. Import the STEP while preserving its three aligned components as parts of one object. Keep the supplied orientation and relative positions; do not arrange the helper parts separately.
2. Select `MAIN_BODY_SET_WALLS_AND_INFILL`. Choose the desired wall count and body infill percentage. The working assumptions remain 0.2 mm layers, 15% body infill and 1.2 mm top/bottom faces; wall count is user-selected.
3. Change both parts named `MODIFIER_…_100_PERCENT_INFILL_…` to **modifier geometry**, and set their infill to **100%**. Use an infill pattern supported by the slicer at that density. These helpers must not print as independent slabs or be fused into the body.
4. Inspect the sliced preview. Confirm two continuous 1.2 mm internal solid bands, sparse infill between them, the desired perimeter thickness, and clear fastener openings. Save the configured slicer project for repeat prints.

| Assembly component | Role | Print Z |
|---|---|---:|
| Main body | Solid CAD envelope; user-selected walls/infill | 0–24 mm |
| Helper 1 | Change to 100% infill modifier | 7.6–8.8 mm |
| Helper 2 | Change to 100% infill modifier | 15.2–16.4 mm |

The helpers are 1.2 mm-thick solids, not zero-thickness surfaces. Each covers the body's entire XY projection with 2 mm of margin on every side, so the slicer can intersect it with the body to create the full internal plate. At 0.2 mm layers each band is six layers thick. Top and bottom faces come from the body's normal solid-layer settings. The slicer generates sparse infill beneath and between the internal bands.

STEP preserves geometry and component names; it does **not** encode modifier status, wall count, infill density or a printer profile. If the slicer does not preserve STEP components, load [body-only.stl](body-only.stl), [helper-1.stl](helper-1.stl) and [helper-2.stl](helper-2.stl) as one object with aligned parts, then assign the helpers as modifiers. All three STL files share the STEP's coordinates.

[Modifier mesh concept and settings](https://help.prusa3d.com/article/modifiers_1767) · [Solid layers over sparse infill](https://help.prusa3d.com/article/layers-and-perimeters_1748).

## Retained bracket features

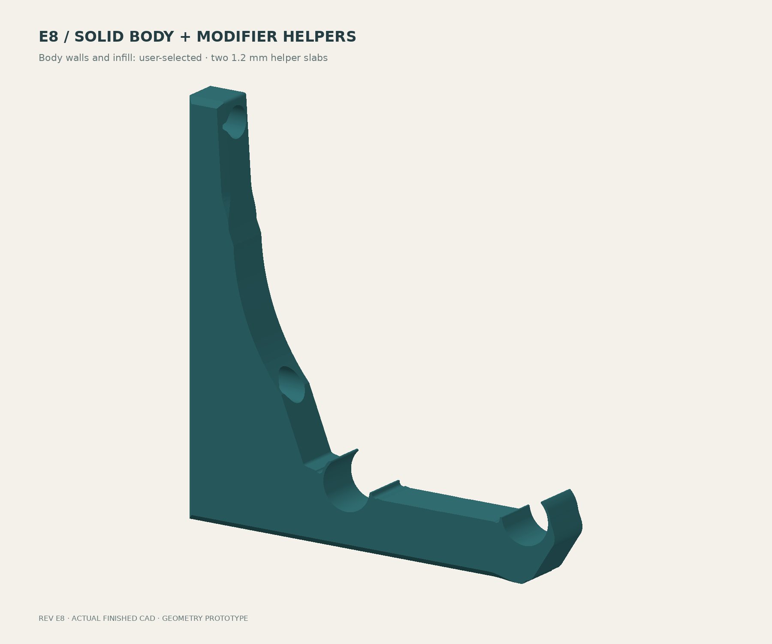
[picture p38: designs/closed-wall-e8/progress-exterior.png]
Actual E8 body envelope


The body retains E7's dowel seats, smooth snap roots, tapered broad-face chamfers and full-height wall contact. The fixings retain 3.6 mm washer-to-wall clamping thickness, Ø5.2 mm screw clearance, Ø16 mm nominal driver access, sloping access roofs and axes at Y = 164/40 mm. Nominal #8/#10 screws and M5 shanks fit the same clearance geometry. The STEP roundtrip retains three valid solids; geometric checks confirm the M5 shank, Ø13 mm washer and Ø15.8 mm straight driver clearance at both fixings.

E7's modeled cell lattice and large hollow bands are removed. E8 does not adopt the separate 34 mm arm-depth proposal. **Structural wall thickness now comes from slicing**, rather than an assumed 2.4 mm CAD shell. The main body's solid CAD volume is not printed material volume or mass. Previous hollow-section calculations do not rate arbitrary user-selected print settings, and sparse infill still receives zero structural credit.

The delivered STEP is an aligned geometry package, not a preconfigured slicer project or a validated load rating. Confirm actual solid bands, bridge behavior and fastener fit in the preview and a representative print.

## Files and rebuild

- [STEP assembly with helpers](bracket-with-modifier-helpers.step) — preferred handoff.
- [Body-only STEP](body-only.step) — external/functional geometry without helpers.
- [STEP and clearance verification](verification.json).
- [Build dimensions and helper bounds](build-verification.json).

Use OpenSCAD and Python with CadQuery/OCP, NumPy, Shapely, Matplotlib, Pillow and VTK. From this directory:

```sh
openscad -o profile.svg -D 'part="profile"' bracket.scad
python build_step.py
python verify_step.py
python render_cpu.py
python draw_helpers.py
```

The two helper solids intentionally overlap the main body. Do not union them when exporting the assembly. Keep the separate open-web exploration isolated.

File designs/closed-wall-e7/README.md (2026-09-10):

# E7 — compartmented voids and accessible wall fixings

E7 retains the closed-wall bracket and its four continuous 1.2 mm load-plane plates. It divides the three air bands into short bridge compartments and replaces the long screw bores with recessed washer seats close to the wall. The external arm depth and 2.4 mm structural perimeter remain E6 dimensions; the separate PLA/PETG beef-up study is not incorporated.

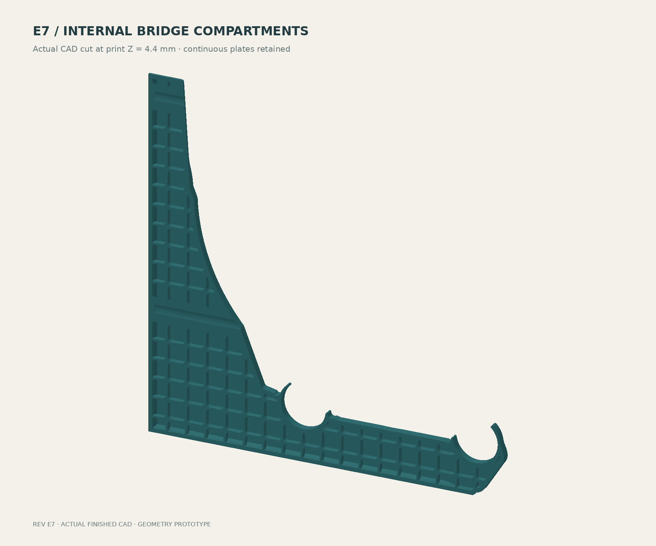
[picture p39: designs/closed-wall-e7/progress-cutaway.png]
Actual CAD cutaway


## First prints

- [Bridge coupon STL](bridge-coupon.stl): 36 × 36 × 24 mm, three hollow bands with the production cell size and plate thickness. Inspect the first roof layers at Z = 7.6, 15.2 and 22.8 mm; use slicer previews and optionally pause before later layers conceal the first bridge surface.
- [Fastener coupon STL](fastener-coupon.stl): extracted from the actual upper fixing, in print orientation. Check M5/#10 clearance, washer insertion, straight driver access and the access roof. This small sample does not establish the full wall-leg strength.
- [Full bracket STL](bracket.stl): geometry prototype, with the broad side on the bed.
- [Finished STEP, ZIP archive](bracket-step.zip): editable final solid. Unzip to obtain `bracket.step`.
- [Unchanged 8 mm snap coupon](snap-coupon-8mm.stl): local fit sample, not the full-width insertion-force test.

## Internal printing geometry

Each full compartment fits inside a 10 × 10 mm box. The fixed lattice has 1.2 mm dividing walls and R2 full-cell corners. Boundary cells are clipped to the original cavity envelope; tiny air slivers are filled. No cell can have a straight geometric span greater than 14.14 mm, including diagonals. Actual slicer bridge direction, extrusion width, anchorage and sag still require verification.

The air bands retain their original Z intervals: 1.2–7.6, 8.8–15.2 and 16.4–22.8 mm. Their final counts are 106, 97 and 106 cavities after bevel and fastener keepouts. The solid plates remain at 0–1.2, 7.6–8.8, 15.2–16.4 and 22.8–24 mm, interrupted locally by the fastener features. These added dividing walls support printing; no structural capacity is assigned to them. They supplement the continuous plates rather than replace them.

The main structural perimeter remains 2.4 mm. Preserve 0.2 mm layers and 1.2 mm top/bottom settings. Fifteen percent infill receives zero strength credit. These are true CAD voids; infill does not appear inside them. Verify actual solid paths in thin walls and plates. No validated printer/material profile or machine-ready G-code is included.

## Fixing and driver access

Dimensioned sections from final CAD

| Feature | E7 geometry |
|---|---:|
| Nominal screw clearance circle | Ø5.2 mm, with small upper print-roof relief |
| Intended shank fit | #8 / #10 wood screws; M5 clearance |
| Plastic between washer and wall | 3.6 mm |
| Washer envelope checked | Ø13 mm OD × Ø5.5 mm ID × 1.2 mm thick |
| Nominal straight access circle | Ø16 mm |
| Driver envelope verified against final CAD | Ø15.8 mm cylinder |
| Screw axes above rail-center datum | 164 and 40 mm |
| Screw spacing | 124 mm |

A #10 has a nominal major diameter of 0.190 inch, or 4.826 mm. The 5.2 mm clearance gives approximately 0.37 mm diametral clearance for #10 and 0.20 mm for nominal M5. M5 fit is more sensitive to printed hole undersizing; verify the coupon. The M5 designation is a clearance compatibility statement, not a recommendation to drive a metric machine screw directly into a wood stud. [Nominal screw diameter reference](https://boltdepot.com/fastener-information/Machine-Screws/Machine-Screw-Diameter).

Use a flat-under-head screw or a suitable washer on the flat landing. A countersunk head does not match this seat without appropriate hardware. The washer land supports approximately 99.1% of the checked washer annulus; a small upper bore relief accounts for the missing fraction. The land depth is 3.6 mm, not the complete wall-leg projection.

The old lower screw axis at Y = 12 mm aimed a straight driver into the rear rod/retainer region. Raising it to Y = 40 mm clears the dowel seats. Removed the obsolete projecting screw-head pad and long narrow sleeve geometry. Both openings extend forward to open air. Use an extended driver bit with approximately 60 mm of unobstructed reach beyond the head for the lower fixing; the verified envelope does not represent an entire drill chuck or arbitrary driver angle. Install before loading spools.

The large access opening has a circular lower region and tangent 45-degree upper shoulders, transitioning into a short rounded cap at print Z = 22.4 mm. That leaves a nominal 1.6 mm outer roof skin and avoids a long flat tunnel ceiling. The small screw bore also has upper roof relief. Printed roof quality remains a coupon check.

## Verification and tradeoffs

The final CAD is one valid solid. The full bracket and both new coupon meshes have no boundary or nonmanifold edges. Boolean checks find zero interference for the tested M5 shank, washer and driver envelopes at both fixings. The nominal 180–220 mm spool clearance sweep still passes. [DFM checks](dfm-verification.json) · [Compartment geometry](dfm-build.json) · [External clearance](verification.json) · [Finished-solid check](finish-verification.json).

Modeled solid volume increases from approximately 94.3 cm³ in E6 to 133.8 cm³ in E7, about 42%, including compartment walls and access reinforcement. The compact approximately 206.73 × 208 × 24 mm envelope remains. E7 does not adopt the 34 mm arm-depth proposal from the material sizing study.

**Slicer paths, physical bridge quality, mounting strength, snap behavior and sustained-load capacity remain unverified.** The internal long-span issue now has a concrete compartmented geometry to test. E6's material/load reports remain historical screening studies; the changed wall connection and local plate interruptions require renewed analysis before transferring any result. No safe spool count is released.

## Rebuild

Use OpenSCAD, Python, CadQuery/OCP, NumPy, Shapely, Matplotlib, Pillow and VTK. E7's `bracket.scad` exports only the exterior/cavity seed profiles. The authoritative finished geometry comes from `dfm_geometry.py` and `finish_cad.py`; an unfinished SCAD bracket export is intentionally disabled.

```sh
openscad -o profile.svg -D 'part="profile"' bracket.scad
openscad -o cavity-profile.svg -D 'part="hollow_profile"' bracket.scad
python finish_cad.py
python verify_dfm.py
python check_and_draw.py
python render_cpu.py
python draw_dfm.py
```

Run from this directory. Verification can extract the delivered STEP archive if the uncompressed file is absent. Repackage the regenerated STEP into `bracket-step.zip` when publishing a geometry change. Keep the separate open-web exploration isolated.

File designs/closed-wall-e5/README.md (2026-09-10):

# E5 — fixed-spacing height study, not selected

This study raises the underside by 45 mm while retaining 150 mm rail spacing. It provides a 194 mm full-height flat back and leaves 27.7 mm below a nominal 200 mm spool.

The 18 mm arm sacrifices too much local section stiffness to accept as an equivalent structural replacement. The final CAD midspan second moment of area is approximately 6,932 mm⁴ versus 38,013 mm⁴ in E4, with the same rail span. E6 instead shortens the span and restores a deeper arm. Both revisions remain unvalidated prototypes.

E5 height study

[Original section comparison](vertical-verification.json) · [E4/E5/E6 comparison](../closed-wall-e6/vertical-verification.json)

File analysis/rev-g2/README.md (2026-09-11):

# G2 prerequisite: correct the sliced-material model

**The five-case shape validation is complete; corrected G mechanics is still
in progress. No accepted G2 architecture exists yet.**
[Restart handoff and current results](../../RESTART-2026-09-11.md).
[Completed G contact screen](G-RESULTS.md): 4.3355 mm maximum movement and
20.0254 MPa raw peak tensile stress at 12 kg. A tenfold tighter numerical check
changes no nodal movement by more than 4.894e-7 mm. This remains an eroded-material
screen with 8.02% material omission, not a qualified printed-part result.

[Adaptive mesh checkpoint](ADAPTIVE-MESH.md): verified coarse/fine constraints
halve the protected whole-G 0.2 mm mesh. Both bounded full-G GPU solves failed
equilibrium convergence. A separate boundary census reaches 0.025 mm XY with
1.10% omitted raw plastic; multilevel grading and mechanics remain unfinished.
The fresh P1S/PETG slice, priming accounting and independently checked raw shape
remain distinct from the historical neutral input used in those GPU trials.
[GPU execution and validation checkpoint](GPU-VALIDATION.md): Warp now runs on
the RTX 3080 Ti and passes independent small 3D fixtures plus manufactured patch
tests on a raw G slice crop. Conservative voxel material loss remains 4.31%
even at 0.1 mm XY spacing in that crop. No full-G GPU result is accepted.
[G2-BRIEF.md](../../G2-BRIEF.md) defines the broader study. E13 and G files
remain unchanged.

The new [plastic_shape.py](plastic_shape.py) reads actual extrusion paths,
widths, heights and E values. It excludes 0.4 mm bridge paths from structural
material while retaining their full plastic use. The two-wall, five-layer
reference has 77.9203 cm³ spent plastic, including 6.9405 cm³ of thick bridges;
70.9798 cm³ is credited extrusion. The nominal continuous footprint volume
differs from the extrusion accounting and is reported separately.

The five actual Orca cases are two/eight walls crossed with two/eight top and
bottom layers, plus the two-wall, five-layer reference. Base infill is zero;
the original three helpers remain at 100%. The minimum is two walls. A prior
one-wall diagnostic is not the current reference.

Credited structural material across wall and skin schedules

## Completed checks

[Independent shape validation](validation/matrix-shape-validation.md) uses
analytical distances to every potentially covering variable-width capsule,
independent of the cached polygon union. All 50,000 occupancy samples agree
outside a 0.005 mm polygonization band. Through-thickness differences remain
within the independently computed sum of boundary-uncertain layer heights.
The sample set includes the old hotspot and thousands of occupied points
per case. This is a geometry check, not a mechanical acceptance result.

The [process audit](validation/process-matrix.json) verifies effective wall
counts, both shell layer counts and minimum thicknesses, zero base infill,
the three 100% helper modifiers, unchanged source hashes and P1S bed/exclusion
clearance. The neutral process is not a calibrated PETG/ASA print profile.

| Schedule | Credited E volume, cm³ | Sacrificial bridge volume, cm³ | Nominal structural footprint union, cm³ | Exact slice archive |
|---|---:|---:|---:|---|
| 2 walls, 2 skin layers | 60.374 | 6.901 | 61.394 | [ZIP](../../designs/rev-g2/g-recheck/2w-2layers/slice-evidence.zip) |
| 2 walls, 5 skin layers | 70.980 | 6.940 | 71.891 | [ZIP](../../designs/rev-g2/g-recheck/2w-5layers/slice-evidence.zip) |
| 2 walls, 8 skin layers | 81.248 | 6.928 | 82.058 | [ZIP](../../designs/rev-g2/g-recheck/2w-8layers/slice-evidence.zip) |
| 8 walls, 2 skin layers | 103.417 | 5.060 | 104.686 | [ZIP](../../designs/rev-g2/g-recheck/8w-2layers/slice-evidence.zip) |
| 8 walls, 8 skin layers | 119.736 | 5.090 | 120.770 | [ZIP](../../designs/rev-g2/g-recheck/8w-8layers/slice-evidence.zip) |

Total spent plastic is credited E plus sacrificial E. Footprint volume is a
separate geometric quantity. Each archive retains exact G-code, audit 3MF,
effective settings and slice result, with a hash manifest referencing G's
published geometry. [Archive verification](validation/slice-archive-audit.json).

The reference cache loads in 1.57 s and answers 10,000 occupancy queries in
0.064 s; 4,000 through-thickness queries take 0.108 s. Across the five cases,
cache loads take 1.10–2.28 s. These are recorded timings on the analysis
machine, not universal performance guarantees. Creating a new shape requires
an actual slice and the one-time path/polygon build.

The new `integrated_volume(regions)` API computes credited material volume
within supplied XY polygons by exact polygon intersections through the layer
stack. It passes independent two-slab analytic fixtures, including different
raw/continuum geometry, empty regions and overlapping queries. The whole G
projection agrees with the cached volume within 0.000000021 mm³.
[API validation](validation/integrated-volume-api.json).

For a constant-strain P1 triangle, this integration also supplies its exact
material-weighted stiffness under the reduced plane-stress assumptions. The
new [reduced recheck](reduced_plastic.py) retains all 37,985 coarse triangles;
it introduces no stiffness at empty sample points. Exact integration took
50.5 s for that mesh and is cached for reuse. The reduced model collapses
the washer plane and through-width deformation, so it remains a ranking
diagnostic pending the 3D comparison.

## Corrected 3D mechanics: unresolved

The [archived comparison](g-slicer-mapping/comparison.json) checks G's saved h1
finite cells against its original emitted paths. It is diagnostic only.
The new reference's layer-derived material forms one connected structural
component without thick-bridge credit. TetGen boundary recovery now reproduces
the continuum volume and all 39 enclosed voids. The
[independent mesh audit](validation/mesh-audit-tetgen-boundary-only.json)
still rejects that mesh for topology/quality. A bounded-envelope mesher passed
the [hollow-box fixture](validation/ftetwild-hollow-box-h1.json). The two long G
jobs were stopped without a mesh. The [tested GPU route](GPU-VALIDATION.md)
now replaces solver discovery; material fidelity and whole-part scaling remain
open. [Earlier GPU alternatives](GPU-FEM-REVIEW.md) and
[meshing attempts, rejected results and sources](MESHING-NOTES.md).

Production load and fixing classifier on the rejected diagnostic mesh

The colored nodes in this diagram come directly from the production interface
classifier. Its grey geometry is the layer projection and washer-plane section.
This checks interface placement on a rejected diagnostic mesh. The actual
contact routine separately passes analytic opening, closing, touching and
release fixtures; elastic assembly and stress recovery pass affine and rigid-
motion checks. [Numerical fixtures](validation/mechanics-fixtures.json).

The raw nominal footprint reference is retained separately from continuum
meshing experiments. Those experiments explicitly report gap closing,
sub-bead void homogenization, coordinate precision and geometric differences.
The path representation has passed the wall/skin geometry validation. The
mechanical recheck is incomplete. Do not equate a manifold surface, a
successful slice or a coverage check with a verified stress result.

## Reproduce the current work

Use the established [analysis environment](../e13/requirements.txt) plus
[the additional dependency](requirements-extra.txt). Native scripts run through
G's unchanged worker. `slice_matrix.py` runs in Orca's installed environment.

```text
python designs/rev-g2/prepare_g_recheck.py --case 2w-5layers
python designs/rev-g2/prepare_g_recheck.py --case 8w-2layers
python designs/rev-g2/prepare_g_recheck.py --case 2w-8layers
python designs/rev-g2/prepare_g_recheck.py --case 2w-2layers
python designs/rev-g2/prepare_g_recheck.py --case 8w-8layers
python designs/rev-g2/slice_matrix.py /path/to/OrcaSlicer
python analysis/rev-g/run_native.py analysis/rev-g2/plastic_shape.py designs/rev-g2/g-recheck/2w-5layers/.work/audit-2w analysis/rev-g2/g-recheck/2w-5layers/validated-shape
python analysis/rev-g/run_native.py analysis/rev-g2/validate_plastic_shape.py analysis/rev-g2/g-recheck --source-root designs/rev-g2/g-recheck --samples 10000
python analysis/rev-g/run_native.py analysis/rev-g2/mesh_plastic.py --validate-hollow-box --output analysis/rev-g2/validation/ftetwild-hollow-box-h1 --h 1 --backend ftetwild --epsilon-mm .01
```

Repeat the `plastic_shape.py` command for the other four case directories
before the matrix validator. To replay the archived slices without reslicing,
extract each ZIP into its case's `.work/audit-2w` or `.work/audit-8w` directory.
The two-wall, five-skin-layer [reference cache](g-recheck/2w-5layers/validated-shape/layers.json.gz)
is included; other caches are rebuildable from the archived inputs.

```python
import sys
sys.path.insert(0, 'analysis/rev-g2')
from plastic_shape import PlasticShape

shape = PlasticShape.load('analysis/rev-g2/g-recheck/2w-5layers/validated-shape')
inside = shape.contains([[145., -30., 23.2]])
thickness_mm = shape.equivalent_thickness([[145., -30.]])
section = shape.section(23.2)
```

The shape tool produces path data, compressed per-layer raw and simplified polygons,
separate spent/credited volume accounting and optional structural STL/mesh.
These are analysis artifacts. Printing uses the original body and modifiers,
with a separately selected and calibrated P1S PETG or ASA process.

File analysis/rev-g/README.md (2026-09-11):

# Rev G — completed evolutionary-search study

**No tested finalist passes every computational gate. The requested 4×
fracture margin remains unverified, and no qualified minimum-mass design is
selected.** The completed sprint implements and verifies the search, examines
real sliced candidates, feeds 3D failures back into a second family, and
publishes the limiting evidence. It does not establish a global optimum or
prove that every untested candidate is infeasible.

[Current CAD and actual toolpaths](../../designs/rev-g/README.md) ·
[Machine-readable search results](search-summary.json) ·
[Complete mechanical metrics](mechanics-summary.json) ·
[Publication integrity audit](publication-verification.json) ·
[Original sprint brief](../../REV-G-SPRINT-BRIEF.md)

Genetic search and candidate cloud

## Objective and limits

Minimize actual printed plastic mass within 5 mm total loaded movement,
including rails, mounting and creep, and 1 mm change per 1.25 kg spool. Use
the 12 kg / 117.72 N reference load and a requested nominal fracture factor
of at least four. Matching E13 stiffness is not a constraint.

The search uses E = 1,000 MPa and Poisson ratio 0.35 as an isotropic effective
creep-planning model. A provisional 1 mm rail/mount reserve gives a 4 mm
bracket screen. The final table also reports the magnitude of the mean seat
translation, which is slightly larger than vertical movement. The per-spool
number scales the same load pattern by 1.25/12; it is not a measured
whole-rack increment or a substitute for the rail/mount assessment.

The nominal tensile-principal-stress limit is **40.5 / 4 = 10.125 MPa**,
using the printed-Z typical tensile value in the
[official PolyLite PLA TDS](https://polymaker.com/wp-content/uploads/lana-downloads/PolyLite-PLA_TDS_EN_V5.4.pdf).
This scalar coupon screen is not a part allowable, a generic safe spool count,
or proof of ASA, PETG or conditioned PA6-GF lifetime performance. The existing
hot/sustained qualification envelope remains in the
[E13 material guide](../../E13-ENGINEERING-GUIDE.md). All finite raw 3D peaks
are retained; percentiles cannot pass the fracture gate.

## Implemented search and repeatability

[fast_screen.py](fast_screen.py) caches meshes, finished-layer membership,
wall masks and load patches while preserving the canonical plane-stress
equations and contact solve. Four cases reproduce canonical E13/F full
displacement and stress fields to below 1.2 × 10⁻¹⁰ mm and 3 × 10⁻¹⁰ MPa.
Each also repeats without its result cache.
[Exact validation records](fast-screen-validation.json).

[search.py](search.py) implements seeded integer genomes, tournament
selection, uniform crossover, bounded mutation, elitism and periodic
immigration. Candidate keys and run signatures include parameters, source,
input layers, dependency versions and screening limits. Numerical failures
are rejected. The saved population ledger contains every generation.

| Run | Population × generations | Distinct evaluations in run | 2D feasible / rejected | Best mass proxy |
|---|---:|---:|---:|---:|
| Seed 20260910, broad family | 32 × 20 | 590 | 455 / 135 | 78.01 g |
| Seed 20260911, broad family | 32 × 20 | 584 | 442 / 142 | 76.89 g |
| Seed 20260912, full-plane feedback | 24 × 14 | 291 | 245 / 46 | 99.01 g |

There are **1,458 distinct parameter sets overall**; seven broad-family
candidates occur in both seeds. The initial population is generation zero.
The first broad run and feedback run were each replayed from the numerical
cache; complete population ledgers, selections and summaries match exactly.
This verifies optimizer replay. The separate uncached four-case check verifies
the numerical evaluator. It is not a second uncached solve of all 1,458 cases.
[Replay evidence](repeatability-verification.json) · [Runs](runs/)
· [Every evaluated candidate](search-evidence/).

The broad family varies 1–8 walls, 0.6–1.2 mm skins and planes, full/shaped
planes, chord widths, seat support, tunnel collars and 0.9/1.0/1.1 window
scales. Sparse infill is fixed at 5% in this sprint and receives no structural
credit. Reduced-model mass is a quadrature proxy. Only actually sliced
finalists receive an Orca mass. The search is bounded and has no global
optimality certificate.

## 3D feedback and real candidates

The first seed's coarse best, `82e88fcf29749880c5c3`, moves 4.001 mm in the
fine 2D screen, narrowly outside the planning limit. It was examined in 3D
as a diagnostic candidate, not accepted. Its 3D movement is 4.930 mm vertical
and 5.034 mm resultant; its raw tensile peak is 120.46 MPa. Its actual dense
toolpath coverage also fails. The second seed's coarse best is preserved in
the ledger but was not claimed to have passed 3D or slicing.

[search_3d_feedback.py](search_3d_feedback.py) then restricts the family to
full planes, 1.0–1.2 mm skins/planes and stronger seat/tunnel support. It adds
2D screening reserve: 3.6 mm movement and 7 MPa stress. Final 3D limits remain
4 mm and 10.125 MPa. The resulting finalist is
`213f8c56151ddee40d51`; its fine 2D result is 3.054 mm and 6.889 MPa.
[Changed family and rationale](3d-feedback-search.json).

| Actual candidate | Orca mass at 1.24 g/cm³ | 3D mesh | Front vertical movement | Max mean seat translation | Raw tensile peak | 40.5 MPa / raw peak |
|---|---:|---:|---:|---:|---:|---:|
| Thin shaped seed 1 | 84.35 g | h2 | 4.930 mm | 5.034 mm | 120.46 MPa | 0.34 |
| Full-plane feedback | 103.76 g | h2 | 3.128 mm | 3.186 mm | 32.29 MPa | 1.25 |
| Full-plane feedback | 103.76 g | h1.5 | 3.167 mm | 3.225 mm | 37.99 MPa | 1.07 |
| Full-plane feedback | 103.76 g | h1 | 3.246 mm | 3.306 mm | 55.05 MPa | 0.74 |
| Wider inner-seat support | 108.03 g | h2 | 2.988 mm | 3.042 mm | 21.25 MPa | 1.91 |

The last row is a targeted 3D-feedback perturbation, increasing only the
inner-seat support width from 5 to 8 mm. It is not a new genetic optimum.
It improves the coarse result but remains rejected; no fine-mesh acceptance
is claimed for it. [Rationale](studies/seat-support/design-rationale.json).

At h1, the 103.76 g full-plane candidate is **37.91% lighter** than E13's
167.11 g reference and about **51.11% more flexible vertically**. Its
reference-load stiffness per gram is approximately **6.58% higher** on the
matched h1 comparison. This is a useful tradeoff inside the movement budget,
but the strength failure prevents selection. The remaining resultant-motion
budget is **1.694 mm** for other contributors; the proportional one-spool
bracket proxy is **0.344 mm**. These remain model-based planning quantities.

## Mesh refinement and the limiting mechanism

Raw stress and movement refinement

The full-plane meshes contain 214,688, 322,730 and 691,297 finite tetrahedra.
Every saved solution passes independently recomputed free residual, force
balance and moment balance below 10⁻⁶, with converged unilateral wall contact.
Only numerically zero-volume mesh cells may be excluded under the recorded
determinant gate; no finite cells are removed for their stress values.

Raw peak stress rises from 32.29 to 55.05 MPa, while the volume above the
10.125 MPa screen rises from 0.00879 to 0.20154 mm³. The global peak migrates
from the inner-seat neighborhood to the lower forearm. These peaks do not
converge to a usable rupture prediction. Small stressed volumes do not, by
themselves, establish numerical artifacts.

Actual finite-element sections and raw hotspot

The fine-mesh peak cell is at approximately (144.843, −30.697, 23.200) mm.
An independent comparison with both delivered G and source E13 STEP files
places its center about **0.00162 mm from a preserved exterior chamfer face**.
This is not solely an internal density-transition hotspot.
[CAD-face evidence and source hashes](hotspot-geometry-verification.json).
Changing reinforcement alone has not demonstrated a solution. The next study
needs to separate actual exterior geometry, emitted bead geometry and local
material behavior without deleting troublesome cells or relaxing the gate.

## Buckling, manufacturing and qualification

[Quadratic buckling report and benchmark](BUCKLING.md) records the complete
constant-strain prestress field, a quadratic displacement basis and linear
bifurcation eigenpairs. A beam benchmark exposes substantial first-order
shear locking. Buckling is reported separately from the fracture factor;
passing a linear stability screen cannot override the tensile failure.

The repaired F light helper, full-plane G finalist and wider-seat variant
pass the actual modifier and nominal bead-footprint checks. The first thin
G finalist fails dense coverage at an upper-skin bridge transition; that
failure is preserved. The earlier F helper export issue was fixed by extending
selection geometry through air. A CAD Boolean comparison proves that the
printed density intersection is unchanged.
[Correction evidence](../../designs/rev-g/studies/repaired-f-light/helper-correction-verification.json).

No physical print, fit test, calibrated process, sustained/hot test or creep
qualification was performed. E13 is retained as an established prototype
handoff, not relabeled as a qualified load rating. The completed G result is
an implemented repeatable optimizer and a documented **absence of a verified
feasible finalist in the tested set**.

## Reproduction and retained evidence

Install the pinned [requirements](../e13/requirements.txt) in a dedicated
environment. The portable [native worker](run_native.py) handles native-library
teardown while preserving failures. From the repository root:

```text
python analysis/rev-g/run_native.py analysis/rev-g/validate_fast.py
python analysis/rev-g/run_native.py analysis/rev-g/search.py --seed 20260910
python analysis/rev-g/run_native.py analysis/rev-g/search.py --seed 20260911
python analysis/rev-g/run_native.py analysis/rev-g/search_3d_feedback.py
python analysis/rev-g/run_native.py analysis/rev-g/refine_candidates.py 3d-feedback-seed-20260912-h2 --count 2
python analysis/rev-g/run_native.py analysis/rev-g/build_analysis_geometry.py designs/rev-g/studies/full-plane-best/selected-layout.json analysis/rev-g/.work/full-plane-best --body-dir designs/rev-g/studies/full-plane-best
python analysis/rev-g/run_native.py analysis/rev-g/mesh_model.py print-material 1 2 1 --clean --directory analysis/rev-g/.work/full-plane-best
python analysis/rev-g/run_native.py analysis/rev-g/solve3d.py print-material-1w-h2 --directory analysis/rev-g/.work/full-plane-best --pardiso
python analysis/rev-g/run_native.py analysis/rev-g/buckling.py --validate
python analysis/rev-g/run_native.py analysis/rev-g/buckling.py --field analysis/rev-g/studies/full-plane-best/print-material-1w-h2-solution.npz --output analysis/rev-g/studies/full-plane-best/buckling-p2-h2 --order 2
python analysis/rev-g/run_native.py analysis/rev-g/audit_publication.py
```

Use h1.5 and h1 for the two refined meshes. Study folders retain raw finite
fields and numerical audits; regenerable BREP/mesh caches and neutral G-code
stay local. Quadratic whole-rack buckling is memory intensive; the recorded
run used a 64 GiB workstation. Do not run multiple such jobs concurrently.
The [manifest](publication-manifest.json) hashes published evidence using
canonical LF for text and exact bytes for binary CAD and field files.

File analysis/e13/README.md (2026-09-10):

# E13 refined structural analysis and reproduction

[Results and material cases](RESULTS.md) · [Matched reduced comparison](COMPARISON.md) ·
[Fine-mesh hotspots](HOTSPOTS.md) · [Current guide](../../README.md).

E13 uses 11 mm added underside depth with long straight flanks and a short
flat. The 12.67 mm cap supersedes E11's adjacent-section margin target. Fingers,
R6 rigid shoulders, mirrored 50° bevels, hardware and four plates are retained.

## Models and refinement

- Five new reduced fields integrate the actual 120 finished STL layers with
  ideal contour walls and plates. E10/E12 comparison fields stay in their
  archived packages. The near-seat statistic uses fixed X75–110, Y−24–0 mm.
- Six current global 3D fields use h=2, 1.5 and 1 mm for 8 and 10 walls. Sparse
  core is removed only from the analysis domain. Two new h=1 mm E12 fields
  provide the matched fine-mesh comparison; they use the preserved E12 CAD.
- The actual upper 3.6 mm screw landing has two additional meshes at h=1 and
  0.65 mm with a separate 500 N washer-compression load and flat rear support.
- Global loads are 12 kg equivalent / 117.72 N per bracket: rear/front 75.12/
  42.60 N down and 31.29 N outward each. E=1000 MPa, nu=0.35. Wall contact is
  compression-only; washer axial and shank shear restraints are rigid. No
  friction or tightening preload is credited.

All ten 3D fields pass independent residual, force and moment balance below
1e-6. The reduced solver has separate affine/beam checks; the 3D patch checks
stress and energy and compares PARDISO with SuperLU. Same-domain face cleanup
preserves CAD volume within 0.001 mm3. Only numerically zero-volume cells may
be removed (normalized determinant below 1e-12, total volume below 1e-8 mm3).
All finite stress cells and their raw peaks remain.

## Reproduce

Use Python 3.12 and `requirements.txt`; `environment.json` records the actual
versions. Gmsh needs system graphics libraries; the published direct solves
use PARDISO/MKL. Build [E13 CAD](../../designs/closed-wall-e13/README.md) first.
Build and clean the preserved [E12 analysis domains](../e12/README.md) before
running the fine baseline commands. From this directory:

```sh
export OPENBLAS_NUM_THREADS=1
export OMP_NUM_THREADS=1
export MKL_NUM_THREADS=8
python verify_solver.py
python verify_solver3d.py
python solve_comparison.py
python build_analysis_geometry.py 8 10
python clean_analysis.py
for walls in 8 10; do
  for h in 2 1.5 1; do
    python mesh_model.py print-material "$walls" "$h" 1 --clean
    python solve3d.py "print-material-${walls}w-h${h}" --pardiso
  done
  python mesh_model.py print-material "$walls" 1 1 --clean --baseline-e12
  python solve3d.py "baseline-e12-print-material-${walls}w-h1" --pardiso
done
for h in 1 0.65; do
  python mesh_model.py landing 8 "$h" 1
  python solve3d.py "landing-8w-h${h}" --pardiso
done
python report.py
python audit_hotspots.py
python render_fields.py
python verify_release.py
```

PowerShell uses `$env:NAME='value'` for environment variables and equivalent
`foreach` loops. Mesher algorithm 1 is Delaunay; failed boundary recovery
retries HXT on the same geometry. Each mesh audit records the actual algorithm,
source and CAD-volume agreement. Contact can start from a completed coarser
field, but the final state must independently converge. PARDISO steps are
recorded as -2 in `linear_iterations`.

Saved `*-solution.npz` files contain coordinates, connectivity, displacement,
element stress, material volume and contact data. Figures intersect the actual
tetrahedra; their colour cap does not filter saved values. BREP domains, base
meshes, logs and caches regenerate locally and are not printable deliverables.

`verify_release.py` checks the 15 new fields, source hashes, material scaling,
geometry and toolpath gates, hotspot records and relative links. It verifies
the published artifact manifest, including archived comparison inputs. Use
`--write` only after deliberate regeneration. Earlier manifests apply to
their own revision checkout because root documentation evolves.

## Interpretation

Refinement measures numerical sensitivity, not physical validation. It does
not resolve printed anisotropy, bead bonding, actual rod/washer contact,
insertion force, damage or lifetime creep. Raw peaks are not allowables and
cannot be dismissed solely because their cells are tiny. Region statistics,
raw peaks and last-step changes are all published.

24 kg proof scaling and common-compliance creep scaling assume unchanged
contact and load pattern. Reference room-temperature moduli, a short PETG
creep example and assumed long-time/thermal tails remain distinct. No physical
print, hot-load trial or long-term creep-rupture qualification is claimed.

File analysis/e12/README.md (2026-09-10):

# E12 structural analysis and reproduction

[Solved results](RESULTS.md) · [E10/E11/E12 comparison](COMPARISON.md) ·
[Current print guide](../../README.md).

E12 limits the added underside depth to **9.5 mm**, meeting the quarter-depth
target and the 12.67 mm maximum. That cap supersedes E11's adjacent-section
margin requirement. Preserve the fingers, R6 rigid shoulders, mirrored 50°
chamfers, hardware and four continuous 1.2 mm plates.

## Models

- **Matched reduced model:** actual 120-layer finished STL outlines, ideal
  contour walls and plates, plane stress and projected fixing/contact conditions.
  E10/E11 solved fields are retained in `analysis/e11`; five E12 fields are new.
  The stress comparison window is fixed at X=75–110, Y=−24–0 mm.
- **Whole-bracket 3D:** finished E12 STEP, analysis-only sparse core removal,
  ideal 8/10-wall contours, four plates and retained tunnel surrounds. This is
  not a resolved bead, orthotropic, rod-contact or damage simulation.
- **Loads/restraints:** 12 kg equivalent / 117.72 N per bracket; rear/front
  seats receive 75.12/42.60 N downward and 31.29 N outward each. Compression-only
  wall contact, rigid washer axial and shank shear restraints; no clamp friction
  or arbitrary tightening preload. Reference E=1000 MPa, nu=0.35.
- **Landing:** the actual upper 3.6 mm land, flat rear support and a separate
  500 N nominal washer load. Two meshes assess this submodel's sensitivity.

## Numerical controls

All six published 3D fields pass independent free residual, force and moment
balance gates below 1e-6. The reduced solver has independent affine/beam checks;
the 3D affine stress/energy test includes PARDISO versus SuperLU.

All four global meshes use the audited same-domain face cleanup. CAD volume
changes remain below 0.001 mm3. Only numerically zero-volume cells may be
removed: normalized determinant below 1e-12, total removed volume below 1e-8 mm3.
Finite cells remain, including those producing raw stress peaks.

The initial 10-wall h3 HXT field failed the residual gate at 2.19e-4. A surface
algorithm 5 retry failed during mesh generation. Neither was accepted. The
published 10-wall pair is h2.5/h2 with surface algorithm 6 and Delaunay 3D, on
the unchanged cleaned analysis domain. The 8-wall pair is h3/h2. Raw peaks,
mesh sensitivities and rejected attempts are recorded in the results.

## Reproduce

Use Python 3.12 and `requirements.txt`; `environment.json` records the actual
versions and platform notes. Gmsh needs its system graphics libraries.
PARDISO/MKL is used for the published direct solves. Build the
[E12 CAD and geometry checks](../../designs/closed-wall-e12/README.md) first.
From this directory:

```sh
export OPENBLAS_NUM_THREADS=1
export OMP_NUM_THREADS=1
export MKL_NUM_THREADS=8
python verify_solver.py
python verify_solver3d.py
python solve_comparison.py e12 8 2
python solve_comparison.py e12 8 1
python solve_comparison.py e12 10 2
python solve_comparison.py e12 10 1
python solve_comparison.py e12 8 1 outer_only
python build_analysis_geometry.py 8 10
python clean_analysis.py
python mesh_model.py print-material 8 3 1 --clean
python solve3d.py print-material-8w-h3 --pardiso
python mesh_model.py print-material 8 2 1 --clean
python solve3d.py print-material-8w-h2 --pardiso
python mesh_model.py print-material 10 2.5 1 --clean
python solve3d.py print-material-10w-h2.5 --pardiso
python mesh_model.py print-material 10 2 1 --clean
python solve3d.py print-material-10w-h2 --pardiso
python mesh_model.py landing 8 1 1
python solve3d.py landing-8w-h1 --pardiso
python mesh_model.py landing 8 0.65 1
python solve3d.py landing-8w-h0.65 --pardiso
python report.py
python render_fields.py
python verify_release.py
```

In PowerShell set the environment variables with `$env:NAME='value'`. Algorithm
1 is Delaunay 3D; the mesher can retry failed boundary recovery with HXT.
Published global runs used Delaunay. Coarse or 8-wall contact can initialize a
new contact solve, but the final state must independently converge. PARDISO
steps are stored as -2 in `linear_iterations`.

Saved `*-solution.npz` files contain coordinates, connectivity, displacement,
element stress, material volume and contact data. Figures use these actual
fields; section views intersect the solved tetrahedra. The 6 MPa display cap
does not discard raw values. Geometry caches, BREP domains and base meshes
regenerate locally and are not printable deliverables.

`verify_release.py` checks the 11 new fields against their result files,
source hashes, material calculations, depth/section/toolpath gates and relative
Markdown links. It verifies the artifact manifest, including the archived
comparison inputs. After deliberately regenerating changed outputs, `--write`
records a new manifest. Earlier manifests apply to their original revision
checkout, since the root guide and project instructions evolve.

## Interpretation

Mesh refinement is numerical sensitivity, not proof of asymptotic convergence
or actual printed behavior. Neither percentiles nor raw peaks are allowables.
Linear 24 kg scaling and common-compliance creep scaling require an unchanged
load pattern and contact state. The grade-specific room-temperature moduli,
short-time PETG example and assumed thermal/long-time tails remain separate.

No physical print, rod fit, snap-force test, hot-load trial or long-term
creep-rupture qualification is claimed. The current criteria remain 5 mm total
loaded movement and 1 mm change per full spool, including dowels and mounts.

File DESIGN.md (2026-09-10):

# Design decisions

**Current implementation: [E13](README.md).** An 11 mm underside reinforcement
uses long straight flanks and a short flat, with small corner blends. It stays
within the 12.67 mm cap, which supersedes E11's adjacent-section superiority
target. Fingers, relief pockets, R6 rigid shoulders, 50-degree mirrored bevels
and hardware are retained. New global meshes at h=2/1.5/1 and matched h1 E12
baselines assess the other hotspots without suppressing finite stress cells.
[Current results](analysis/e13/RESULTS.md) and [hotspot audit](analysis/e13/HOTSPOTS.md).

Current printable CAD is a solid envelope with two aligned 100% infill modifier
helpers; wall count is slicer-controlled. Four continuous 1.2 mm planes remain
the load-path intent. The OrcaSlicer audit confirms the intended paths, while
physical fit, extrusion and sustained/hot qualification remain outstanding.

The sections below retain historical E6 reasoning and dimensions. Where they
describe modeled hollow bands, level rails, coupons or next work, use the
current E13 guide and [design journal](DESIGN-JOURNAL.md) for their successors.

## Closed-wall load path

The wall mounting leg extends upward. Four continuous planes span the arm, knee and wall leg: two exterior faces and two internal plates. Hollow bands force these internal planes into the modeled solid. They lie in printer XY. The principal installed bending load acts in those planes; local bearing, load transfer between planes and buckling still need evaluation.

## Structural thickness

E6 retains a 2.4 mm perimeter around the L profile while retaining 1.2 mm side faces and internal plates. This is a prototype choice, not an optimized thickness or load rating. The arm's upper and lower perimeter bands lie far from its bending neutral axis, so thickening them is useful. External and internal side planes also carry in-plane stress; do not describe all material as equally effective or infer proportional strength gains from perimeter thickness.

A modeled 2.4 mm wall does not guarantee a particular number of extrusion paths. The original three-wall setting must be revised or verified for the 2.4 mm perimeter. The snap fingers remain 1.35 mm in bending thickness. Their stiffness and strain requirements differ from those of the structural perimeter.

## Rotated snap seats

The current E6 geometry uses a 200 mm spool on 25.4 mm rods with 100 mm seat-center spacing. With 0.3 mm radial seat clearance, the rear contact direction is 63.587° from +X; the rigid bearing sector is centered at 243.587°. The front is mirrored. A 218° curved retainer leaves a 142° opening toward the spool. Rounded noses form an approximately 24.51 mm throat, giving about 0.89 mm nominal diametral interference. E1–E5 used 150 mm seat spacing.

The lower/outside bearing sector is 6 mm thick radially. Local relief pockets free the curved fingers from the bracket body. Finger deflection stays in the print layer plane. The ideal seated rod relaxes into the saddle; the design avoids relying on sustained finger clamping.

The 8 mm coupon is a preliminary fit sample. At equal profile geometry, its width is one-third that of the full bracket, so it cannot establish the full part's insertion force. Curved-beam strain, root concentrations, release behavior, overtravel and actual filament behavior have not been validated.

For circular rigid contact, the dowel also receives outward thrust. Over the original 180–220 mm range that component is of similar magnitude to vertical load. Preserve the solid seat-to-arm path; do not route the main bearing load through thin fingers.

## Next work

1. Verify coupon fit against measured dowel diameter and ovality; analyze curved-finger insertion/release and tolerance extremes.
2. Resolve internal roof printing while retaining continuous load-plane plates. Any printing scaffold gets zero structural credit.
3. Inspect slicer paths with explicit line widths, plate thicknesses and printer profile.
4. Evaluate bracket, mounting fasteners and dowel spans together; derive material-specific creep-aware loads from defensible data and tests.

## References

- [Covestro snap-fit design guide](https://solutions.covestro.com/-/media/covestro/solution-center/brands/downloads/imported/1557218421.pdf): snap geometry and stress-free seated design principles. Molded-resin values are not printed-material allowables.
- [Prusa layers and perimeters](https://help.prusa3d.com/article/layers-and-perimeters_1748): extrusion overlap and solid layer behavior.
- [Prusa bridging guidance](https://help.prusa3d.com/article/poor-bridging_1802): unsupported extrusion and bridge quality.

## E2 root correction

Removed the stepped annular root and intersecting circular bumps. The finger outer boundary now uses a quintic radial transition with zero first and second derivative at its joins to the thin finger and thick bearing sector. This gives tangent and curvature continuity in the analytic profile. The model discretizes that curve at 0.25-degree intervals.

The complete bracket profile receives R1.5 concave blends and R0.45 convex rounds. A 17.75 mm relief-pocket radius leaves clearance around the finger while a 6 mm radial bearing sector maintains attachment to the bracket. The coupon base also has rounded corners and blended connections. These changes remove the previous sharp re-entrant roots; they do not establish zero local stress concentration or a safe snap strain.

The larger roots shorten/change the effective flexible length relative to E1. Validate the curved finger as modeled, rather than reusing the earlier straight-cantilever screening example.

## E3 obsolete saddle removal

The old open-saddle lip sectors and round support nodes remained in the base profile after snap retainers were added. They produced an unnecessary secondary prong beneath the working finger. Removed those old features at both rail locations. A new buttress joins a patch of the rigid bearing sector to a rounded anchor inside the arm. It does not use the old lip as a stop or load-bearing feature.

The complete profile retains the concave and convex blends established in E2. The local retainer coupon is unchanged; the integrated support geometry is different and still requires its own compliance and insertion checks.

## E4 angular outline and smoothly terminating face bevels

The large outline uses straight facets with nominal R2 corner blends. Both broad faces have mirrored 3 mm chamfers on selected structural edges. Their depth falls to zero over 20 mm before small features. The quintic Bezier control values 3, 3, 3, 0, 0, 0 ensure zero slope and curvature at each end; the thin snap noses retain their smaller local rounds. The integrated concave root blends are R2.

The final solid is built from the OpenSCAD profile by `finish_cad.py`. A raw SCAD bracket export omits the finished bevels and their matching internal rim reinforcement. The cavity keepout lies 1.8 mm beyond the bevel in the sum of inward distance and face depth. Including the maximum runout gradient of 0.28125, its normal spacing exceeds 1.2 mm. This retains a conservative solid ligament behind the bevel; it is a geometric design rule, not a load allowable. The middle hollow band and both 1.2 mm internal load-plane plates remain continuous.

The finished CAD passes single-solid validity and STL edge closure. Full-profile nominal clearance is 5.34 mm for 180–220 mm spool flanges. Internal bridge spans, toolpaths, fasteners, snap force, fatigue and creep remain unvalidated.

## E5/E6 vertical efficiency

E5 explored simply raising the arm underside while keeping the old rail spacing. Its 18 mm-deep arm had only 18% of the old midpoint section inertia; it was not selected as an equivalent structural replacement.

E6 moves the seats to X=90 and 190 mm, keeping a roughly 28 mm-deep arm between them. The back is flat at X=0 from Y=−32 to +176 mm. The upper fixing moves to Y=164 mm and the lower remains at Y=12 mm. The central 18 mm of the back width reaches both ends of that height after broad-face chamfering; screw holes interrupt its bearing area. A full-height plane is a fit condition, not a claim of full or uniform contact pressure under load.

For 180/200/220 mm flanges, the bracket extends 31.4/32.7/33.7 mm below the spool and never extends above its top. Loaded rack envelopes are 211.4/232.7/253.7 mm before adding handling space. The 200 mm case saves 40.1 mm over E4. The single bracket occupies approximately 206.73 × 208 × 24 mm on the bed.

The section-property script reads final STEP solids. Its midpoint `I/L³` comparison suggests that the shorter forearm can recover the stiffness lost through reduced depth, but it does not model the complete bracket. The idealized bolt-force screen assumes equal rail loading, a point wall-compression reaction and one upper tension fixing. Neither calculation provides a spool rating.

The 100 mm rail spacing reduces the ideal rise needed to rock the spool over one rod to about 12 mm, from 29 mm in E4. This is the main handling compromise; the rail snap does not restrain the spool. Check bumps, off-center loading and sliding with real spools. The closed-wall internal printing issue remains unresolved. The separate open-web path is unchanged.

## Full-row service case at 16 inches on center

The current load study assumes six 1.25 kg gross spools per 406.4 mm bay. It calculates demands rather than allowable capacities. In the two-equal-span continuous-dowel case, the middle support carries 9.375 kg equivalent before rod self-weight and handling loads. An interior support does not merely carry half one bay. Spool width and weight, continuous versus jointed dowels, end overhangs and support compliance affect the reactions.

See E6's `check_16inch_loading.py` and `loading-16inch.json`. Do not treat the low nominal stress at one sampled section, generic filament tensile strengths, or a brief proof load as a long-term creep qualification. The material work cases below now define the temperature envelope and reference grades; a sustained-load limit remains unestablished.

## Material and temperature cases

Use 85°F (29.4°C) sustained and 100°F (37.8°C) for six hours/year at full load. Evaluate PLA, PETG, ASA and PA6-GF. E6's rounded design/qualification target is 12 kg equivalent per bracket; a proposed 24 kg brief proof case is a chosen test target, not an allowable load or code factor. The ten-station beam screen gives 3.47 MPa maximum sampled nominal stress across 180–220 mm spools; critical local behavior remains outside that model.

ASA is the first prototype selection for thermal headroom and unfilled snap behavior. Reference PA6-GF data require annealing and separate dry/water-conditioned cases; do not apply dry stiffness or dry HDT to wet material. No grade-specific long-term creep allowables have been established. Preserve unknown capacity/life fields as null rather than inventing material-specific spool ratings.

See [the material report](designs/closed-wall-e6/MATERIAL-CASES.md) for primary sources, assumptions, calculations and proposed qualification criteria. Geometry remains E6. Resolving internal roofs and inspecting sliced paths precede full-bracket mechanical testing.

## E7 manufacturing revision

The current geometry subdivides all three true air bands into bounded 10 × 10 mm cells with 1.2 mm dividing walls and R2 full-cell corners. It preserves the four 1.2 mm load-plane plates. This limits geometric cavity spans to 14.14 mm in any direction, with no assigned strength credit for the printing dividers. Physical roof quality and sliced paths remain unverified.

Both washer landings now lie 3.6 mm from the wall. The Ø5.2 mm screw clearance accepts nominal #8/#10 and M5 shanks. Ø16 mm nominal access, verified with a Ø15.8 mm cylinder and Ø13 mm washer, replaces the narrow long bores. Raise the lower axis to Y=40 mm to clear the rear rod; upper remains Y=164 mm. Tool tunnels have 45-degree roof shoulders and short rounded caps at print Z=22.4 mm. Small bore relief gives approximately 99.1% support beneath the checked washer annulus. Remove the former protruding lower screw pad.

See [E7](designs/closed-wall-e7/README.md) for dimensions, actual CAD sections, coupons and verification. The external arm remains approximately 28 mm deep with a 2.4 mm perimeter; the separate material-sizing proposal is not implemented. E7's changed connection requires renewed mechanical evaluation. Nominal volume is 133.8 cm³, approximately 42% above E6. Start with the bridge and fastener coupons.

## E8 slicer-controlled interior

Supersedes E7's modeled grid. Deliver a solid bracket envelope and two separate overlapping helper slabs in STEP. The user sets the body's walls and infill, converts the helper parts to modifier geometry and sets those regions to 100% infill. Slabs occupy print Z=7.6–8.8 and 15.2–16.4 mm. Suggested top/bottom solid thickness remains 1.2 mm; sparse body infill remains 15% as the working assumption and receives zero strength credit. These settings are not encoded by STEP.

E7's fastener geometry remains. Actual structural perimeter thickness now follows the selected slicer wall settings. The grid, hollow bands and 2.4 mm modeled shell are not present in E8. Do not infer printed mass from the solid CAD volume or carry the earlier hollow-CAD capacity calculations across arbitrary print settings. See [the E8 handoff](designs/closed-wall-e8/README.md).

## E8 prototype wall-count selection

Use 8 walls for the PLA prototype and 10 for PETG, with both 1.2 mm helpers at 100% infill. Under the explicit 0.42 mm outer / 0.45 mm inner line-width and 0.2 mm layer assumptions, approximate perimeters are 3.27 and 4.08 mm. Six walls approximate the old 2.4 mm shell; nine approximate 3.6 mm. Counts are prototype choices rather than proven minimums. See [wall-count assumptions and screen](designs/closed-wall-e8/WALL-COUNTS.md). CAD remains unchanged and no capacity is released.

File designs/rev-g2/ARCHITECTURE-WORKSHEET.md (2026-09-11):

# G2 architecture family worksheet (provisional)

**Current update:** [six broad XY sketches](shape-seeds/README.md) now make the
body-shape directions visible. They are not CAD/STEP or mechanical results.
The [current interface contract](INTERFACE-CONTRACT.md) fixes rod and mounting
positions, G's moulding locating height, and a one-inch horizontal underside
from the wall before descending. E plus F is the selected next body. This supersedes older relocation
and 8 mm envelope assumptions in the preparatory notes below.

This is a preparatory architecture screen for G2. It does not select a family,
change E13 or Rev G, or claim mass, strength, movement, fit, or print tests.
The corrected Rev G material mapping and mechanical recheck are prerequisites
for ranking these families.

The common target is a single printable bracket for a Bambu P1S with a 0.4 mm
nozzle, PETG or ASA, and at least two walls. The bracket must accept nominal
one-inch dowels and 180–220 mm spools, positively retain the dowels, and let the
spool flanges slide along the dowels across the bracket positions. Dowel capture
must provide a feasible insertion and removal path without sustained clamping.
Rail centers and capture geometry are
design variables; measured dowel diameter/ovality and printed-coupon results
are fit inputs and acceptance checks, not assumed design values. The reference load is
12 kg / 117.72 N per bracket; 5 mm total loaded movement reserves 1 mm for
rails and mounts pending their own model or measurements, leaving a provisional
4 mm bracket allocation. The 1.25 kg spool movement-change limit is a separate
load/contact check. The 85 °F sustained and brief 100 °F conditions, effective
E = 1,000 MPa planning model, and requested nominal fracture factor of four are
screening assumptions, not lifetime or material allowables.

## Common parameter and audit vocabulary

Installed `X` points outward from the wall, `Y` is vertical, and `Z` runs along
the dowels and across the 24 mm bracket thickness (also the print-build
direction). The existing Rev G functional reference places the rear and front
seat centers near `(X,Y) = (90,0)` and `(190,12)`, with wall fixing lands near
`Y = 40` and `164`; these are starting coordinates only. A spool flange slides
along `Z`; the dowels are retained positively at the seats. Each family should
expose rail center spacing, seat radius, capture geometry, wall fixing land
size, web/rib width, wall-loop count, skin thickness, and helper regions as
parameters, while taking measured dowel dimensions only as fit-validation
inputs.

Every coarse model should represent the body as a union of finite 2D section
regions lofted or extruded through Z, with actual body intersections at each
0.2 mm layer. Wall and skin domains come from the corrected Orca-derived
material map; sparse base infill receives zero structural credit. Dense helper
regions are clipped to the body and counted once. Sacrificial 0.4 mm bridges
count as spent plastic but receive zero stiffness, strength, and bonded-connection credit.
Each candidate needs the same 3D equilibrium, force/moment, contact, movement,
mesh-refinement, retained-cell, buckling, and process-envelope gates.
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

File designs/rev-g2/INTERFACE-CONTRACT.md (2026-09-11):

# G2 current interface contract

The body outline is a design variable. The completed G helper pilot validated
the local screening workflow; its frozen body is not a constraint on this study.
Start with substantially different structural families, then mutate dimensions
within each family by 5–10%. Body depth, width, outer contour, braces, windows,
wall footprint, skin arrangement and helper count/shape may change.

The latest interface requirements supersede the older permission to relocate
rods and mounting holes:

| Interface | Current requirement |
|---|---|
| Rear and front rod axes | Keep `(X,Y) = (90,0)` and `(190,12)` mm; axes run along Z. |
| Mounting holes | Keep axes at `(Y,Z) = (164,12)` and `(40,12)` mm. Preserve the reference 5.2 mm screw clearance and functional washer/driver access. |
| Spool clearance | Preserve axial flange sliding for 180–220 mm spools, with at least 3.5 mm nominal clearance over the effective rail-radius interval 12.4–12.7 mm. |
| Matching bottom corner | Preserve G's lower wall corner at X=0, Y=-32 mm. The printed bracket slides down the wall until this underside touches the top of the closet crown moulding. Rod and mounting heights relative to that datum stay unchanged. |
| Horizontal moulding clearance | Keep the underside at Y=-32 mm for at least 25.4 mm outward from the wall. Moulding projects 19.05 mm; the one-inch design reach includes 6.35 mm extra allowance. No bracket material may descend below that level for X from 0 to 25.4 mm. Beyond it, this moulding imposes no downward limit. |
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

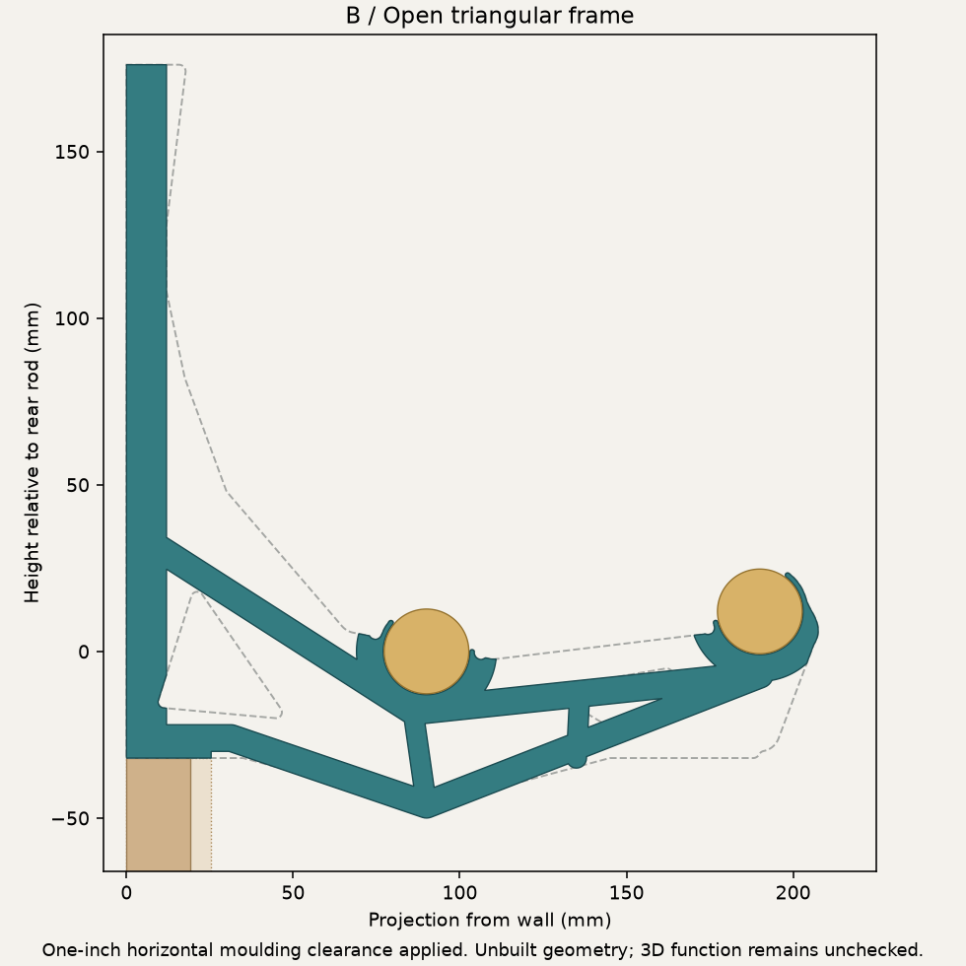
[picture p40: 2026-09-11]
designs/rev-g2/shape-seeds/B-open-truss.png

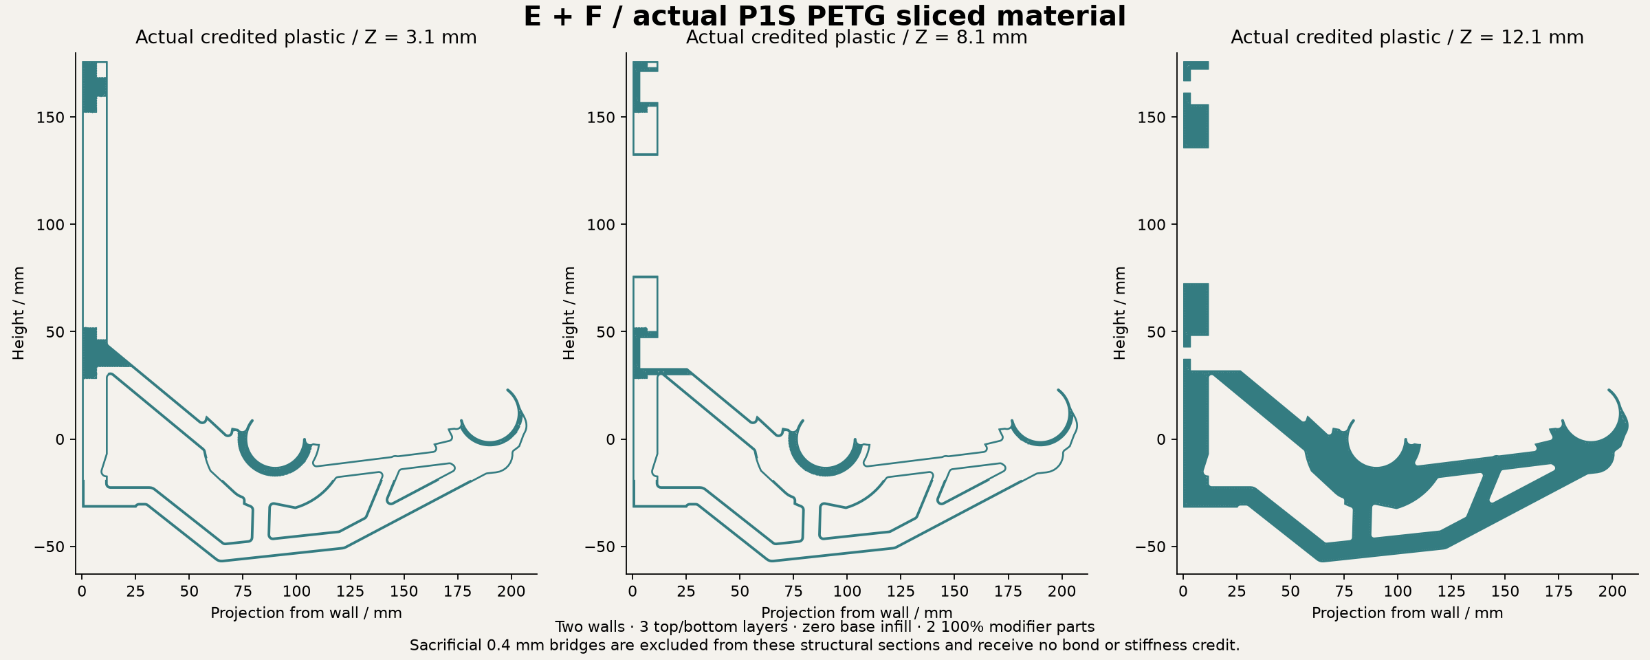
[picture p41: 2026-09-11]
designs/rev-g2/ef-cut-v4/toolpath-sections.png

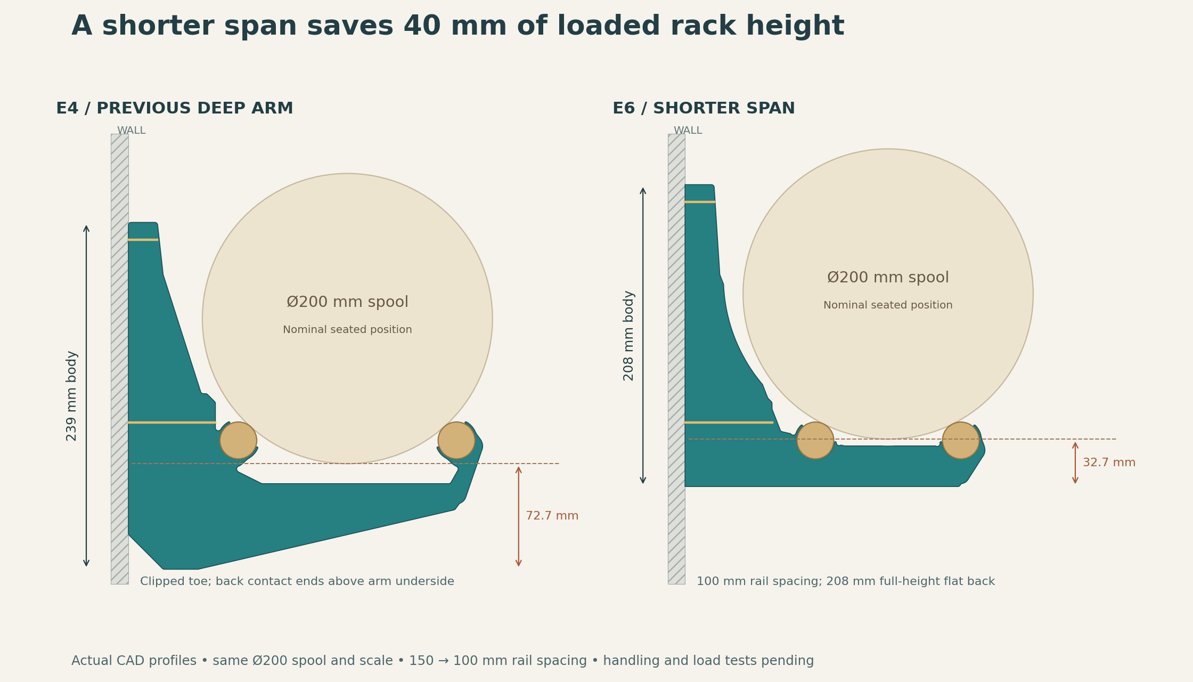
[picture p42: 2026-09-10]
designs/closed-wall-e6/vertical-comparison.png

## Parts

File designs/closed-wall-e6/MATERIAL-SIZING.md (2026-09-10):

# How much additional section for PLA or PETG?

**Proposed shared starting point: 3.6 mm modeled structural perimeters and a 34 mm-deep straight arm, retaining the four continuous 1.2 mm plates and 24 mm overall width.** Carry the added section smoothly through the knee; do not strengthen only the midpoint. E6 CAD remains unchanged pending this study's implementation and local verification.

The present straight arm is approximately 28 mm deep with 2.4 mm structural perimeters. An ideal rectangular multi-cell section gives the following comparison. All modeled solid counts; infill counts zero.

| Study | Straight-arm plastic increase | Geometric bending stiffness, I | Pure bending stress reduction at equal moment |
|---|---:|---:|---:|
| 3.6 mm perimeter only; 28 mm depth | 20% | 1.23× | 19% |
| One more 1.2 mm continuous plate; 24.4 mm width; original depth/perimeter | 13% | 1.07× | 6% |
| 3.6 mm perimeter; 32 mm depth | 29% | 1.72× | 34% |
| **3.6 mm perimeter; 34 mm depth** | **33%** | **2.00×** | **39%** |
| 3.6 mm perimeter; 36 mm depth | 37% | 2.30× | 44% |

These are local section ratios, not whole-part mass increases, whole-bracket deflections or reductions in the previously reported maximum combined stress. The rectangular baseline has I = 23,925 mm⁴ versus 22,261 mm⁴ at the finished CAD midpoint, illustrating the approximation. Chamfers and their cavity-rim reinforcement, the irregular knee, sleeves, snap roots, shear and plate stability require final-CAD checks.

For width b, depth h, perimeter thickness t and n continuous plates of thickness p, the model subtracts the air bands from the outer rectangle:

`A = b*h - (b - n*p)*(h - 2*t)`

`I = [b*h^3 - (b - n*p)*(h - 2*t)^3]/12; S = 2*I/h`

The perimeter increase is particularly useful in the upper and lower longitudinal portions of the arm, where material lies farthest from its bending neutral axis. Additional full-depth plates also carry in-plane bending and shear, but adding one alone gives less bending benefit per added material in this section. Their number should also reflect stability and manufacturing requirements.

## Material interpretation

Using the specific reference flexural moduli in the [material assessment](MATERIAL-CASES.md), PETG needs approximately **41% more I** to match the original ASA section's initial bending stiffness. The older PolyLite PETG reference would need 69% more. The 34 mm candidate provides about 100% more I, producing approximately **1.42× the original ASA initial EI** with the current PETG reference, or 1.18× with the legacy PETG reference. These comparisons use typical reference properties, not properties measured at 85°F or after creep. [Current PETG source](https://cdn.shopify.com/s/files/1/0548/7299/7945/files/PETG_TDS_Polymaker_297e875c-5d38-4d2b-ba68-eef8916de183.pdf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).

The PLA reference already has approximately the same initial bending modulus as ASA, so no extra section is required merely to match that initial stiffness. The proposed increase lowers working stress and provides deformation margin for either material; it does not establish how much is required for long-term creep. Published PLA research shows that creep can continue well below Tg, but does not supply a transferable factor for this grade and temperature envelope. [PLA creep research](https://arxiv.org/abs/2302.11240).

For a linear creep-stiffness sensitivity, doubling I offsets a halving of effective modulus when comparing otherwise identical beam geometry and loading. **A 50% retained modulus is an illustrative assumption, not a measured PLA/PETG retention value or a prediction of service life.** Geometry cannot be sized to a specific life until a defensible time/temperature-dependent material basis exists.

## Implementation intent

Add the 6 mm below the arm to preserve spool clearance and rail positions. Expect approximately 6 mm additional extension below the spool, about 39 mm total for the 200 mm reference spool, subject to final geometry. Continue the lower load path into the full-contact wall leg, maintain smooth knee transitions, and recheck the critical sections. Preserve thin working snap fingers and their smooth roots; do not scale the complete retainer by the perimeter increase.

The four plates stay at 1.2 mm to retain the solid-layer strategy. The thicker modeled perimeter needs matching sliced solid paths rather than the original three-wall assumption. Empty-cavity roof printing remains unresolved and must be handled before representative mechanical testing. The 12 kg sustained/hot qualification target remains unchanged; this sizing study does not release a safe spool count.

[Calculation script](size_material_alternatives.py) · [Computed values](material-sizing.json).

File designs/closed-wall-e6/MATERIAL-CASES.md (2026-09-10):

# E6 material cases: 85°F storage, 100°F excursions

**Decision: use ASA for the first full-load prototype.** This is an engineering selection for its thermal headroom and an unfilled material for the integrated snap fingers. It is not a demonstrated creep advantage over every PLA, PETG or nylon formulation. PA6-GF is an alternative requiring moisture-conditioned evaluation and separate snap testing. No material currently has a verified full-row rating.

Geometry remains E6: four continuous 1.2 mm load-plane plates, a 2.4 mm modeled structural perimeter, 24 mm overall width and 100 mm rail spacing. All modeled solid must actually print solid; 15% infill receives zero structural credit. The original three-perimeter setting does not itself ensure the modeled perimeter is filled. The unresolved empty-cavity roofs remain a manufacturing gate for every material.

## Service and qualification loads

Use 85°F (29.4°C) for sustained storage, with the same full load at 100°F (37.8°C) for six hours per year. Do not substitute an annual average temperature. No intended service life was specified, so this study does not claim a multi-year life.

| Case | Vertical load per bracket | Purpose |
|---|---:|---|
| Six 1.25 kg gross spools per 16-inch bay; two equal continuous spans | 9.375 kg equivalent at the middle support, before self-weight | Original packed-row service example |
| Continuous full row at 60 mm pitch | 10.583 kg equivalent, before self-weight | Denser packing sensitivity |
| Sustained at 85°F | **12 kg equivalent / 117.72 N** | Rounded design and qualification target |
| Hot excursion at 100°F | **12 kg equivalent / 117.72 N** | Full-load temperature case, six hours/year |
| Proposed brief proof case | **24 kg equivalent / 235.44 N** | Chosen 2× test target; not a code safety factor or capacity |

The 12 kg target leaves 1.42 kg above the 60 mm pitch example for self-weight and modest variation. Actual self-weight must fit that budget. For this screen the entire equivalent load acts at the rod seats, conservatively placing bracket self-weight farther from the wall than its actual center of mass. This does not cover arbitrary heavier/narrower spools, clustered loads, overhangs, impact or uneven support settlement. The two-span reaction factor is not a universal bound. Six spools fit per bay when their effective pitch is at most 67.7 mm; gross mass includes the empty spool.

At 12 kg and equal rail sharing, each seat carries 58.86 N downward and approximately 26–33 N outward over 220–180 mm spool diameters. Wall moment is 16.48 N·m. An ideal bottom compression point gives 84 N upper-fixing tension; actual fastener bearing, pull-through, substrate and wall contact still need checking.

The final CAD section screen samples the knee and forearm at ten stations. The largest sampled nominal combined stress is **3.47 MPa**, including outward seat thrust and axial load; linear scaling gives **6.93 MPa** at the proposed proof load. The knee and the forearm near the rear seat are more demanding than the old midpoint-only screen. These are beam estimates, not peak stresses or failure predictions. They exclude local concentrations, seat/root deformation, connection behavior, shear, plate buckling and creep. Symmetric rod loads are assumed.

[Reproducible load cases](work_material_cases.py) · [Calculated results](material-work-cases.json) · [CAD section extraction](check_material_sections.py) · [Section properties](section-load-screen.json).

## Material comparison

These are specific reference grades, not universal properties of the polymer families. Published typical specimen data are not design allowables. In particular, HDT is a short-duration standardized deflection test, not a continuous temperature rating.

| Material and reference | Typical XY flexural modulus | HDT at 1.8 MPa | Assessment for this temperature envelope |
|---|---:|---:|---|
| [PLA, PolyLite V5.4](https://cdn.shopify.com/s/files/1/0548/7299/7945/files/PolyLite_PLA_TDS_EN_V5.4.pdf?v=1731949179) | 3.23 GPa | 58°C | Stiff initially, least thermal headroom here. Keep as a monitored trial; not the first choice for unattended long-term storage without creep evidence. |
| [PETG, current Polymaker formula](https://cdn.shopify.com/s/files/1/0548/7299/7945/files/PETG_TDS_Polymaker_297e875c-5d38-4d2b-ba68-eef8916de183.pdf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) | 2.28 GPa | 65°C | Candidate, but lower reference stiffness and still needs sustained-load measurement. No substantiated blanket claim that PETG creeps more or less than PLA. |
| [ASA, PolyLite/Polymaker](https://cdn.shopify.com/s/files/1/0548/7299/7945/files/PolyLite_ASA_TDS_EN_V5.4.pdf?v=1731955208) | 3.21 GPa | 100°C | First prototype choice: useful thermal headroom with reference bending stiffness similar to PLA. Printed warp, adhesion and snap behavior must be checked. |
| [PA6-GF25, Fiberon V1.1](https://cdn.shopify.com/s/files/1/0548/7299/7945/files/TDS_FIBERON_PA6-GF25_V1.1_EN.pdf), annealed dry → water-conditioned | 4.31 → 1.45 GPa | 157°C dry; wet not reported | Dry headline stiffness is unsuitable as the sole basis. Evaluate both conditioning states; the dry material's low elongation also makes snap insertion a distinct concern. |

The PA6-GF reference specimens were annealed at 100°C for 16 hours. Water-conditioned specimens then underwent 48 hours in 60°C water; the retrieved TDS reports 4.57% moisture. This is a moisture sensitivity case, not an assertion that an indoor rack reaches that condition. Its wet flexural modulus is about one-third of dry. Annealing can change fit, so the dowel throat and flat wall face must be remeasured. A shop FAQ reports a different moisture percentage; this study uses the TDS. Neither the dry HDT nor dry stiffness is assigned to the wet case.

PETG formulations differ: the legacy PolyLite TDS lists 1.90 GPa flexural modulus and 75°C HDT at 1.8 MPa. Those values cannot be silently transferred to the current formula. [Reference values, source URLs and retrieved-document hashes](material-reference-data.json).

For scale only, a **vertical-load-only, constant-section 100 mm forearm** with the E6 midpoint inertia predicts initial reference deflections of 0.273 mm PLA, 0.387 mm PETG, 0.275 mm ASA and 0.204/0.609 mm dry/water-conditioned PA6-GF at the 12 kg case. These use the published typical flexural moduli. They are not whole-bracket deflections, do not include outward force or joint flexibility, and are not predictions at 85°F or after creep.

## Why there is no material-specific safe spool count yet

No grade-specific long-duration creep curves at 29.4°C and 37.8°C were obtained for these four reference formulations. Dividing their room-temperature tensile strengths by nominal bracket stress would miss local failure and time-dependent deformation. Elongation at break is likewise not allowable snap strain.

Published research on a different printed PLA grade found continuing flexural creep over 170 hours at approximately 20°C; its one-week creep modulus was substantially below its datasheet flexural modulus. That establishes why being below Tg does not eliminate creep. It does not supply a transferable derating factor for these grades, temperatures or years of storage. [Fischbach and Weinberg, 2023](https://arxiv.org/abs/2302.11240).

For **PLA, PETG, ASA and PA6-GF alike**, the proposed target is the full-row case above; maximum verified sustained spools remain **undetermined**. This means capacity is unestablished, not that all four have equal capacity or that any has failed.

## Concrete next qualification work

1. Resolve internal roof printing and inspect actual solid paths before testing a full bracket. Use final geometry, documented grade, layer orientation and extrusion widths. Include representative repeat prints; one passing part cannot establish production reliability.
2. Measure dowel fit and test full-width snap insertion/release at temperature. Include annealed dry and moisture-conditioned PA6-GF. Fingers should relax after insertion; sustained load belongs in the thick bearing seat. Check retention again after thermal/load exposure.
3. Apply the 12 kg equivalent case at 30°C for an initial 1,000-hour monitored trial. Use actual spool-rim contact or fixtures reproducing both vertical and outward seat forces. Hanging a vertical weight from each rod alone misses the outward thrust. Include the smaller-spool case and monitor both seats and the wall joint.
4. Under the same load, include a six-hour exposure at 38°C and record movement during the excursion and after return to 30°C. Repeat excursions as part of longer testing; six hours of heating alone does not reproduce years of prior creep.
5. Proposed serviceability screening targets: no more than 1 mm additional vertical seat movement from the initial loaded reading; no more than 0.5 mm residual movement 24 hours after unloading at 30°C; no visible cracks, loss of snap retention or spool/plastic interference. These are selected project acceptance targets, not published standards. Record creep slope as well as total movement.
6. After initial characterization, use a separate specimen for a proposed 24 kg, ten-minute proof case with the same force directions and controlled temperature. Inspect for damage and loss of function afterward. Passing a brief proof test or the 1,000-hour trial does not establish multi-year creep life: release requires an appropriate longer-term basis, critical-region analysis and verified mounting/dowel details.

Keep the closed-wall path separate from the deferred open-web concept. No geometry change or material-specific capacity release is made by this study.

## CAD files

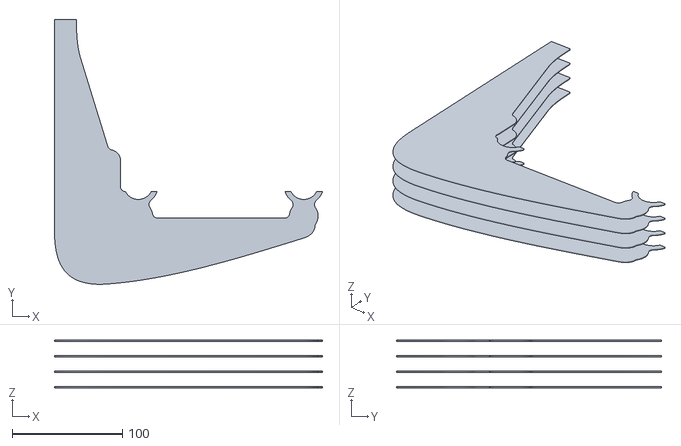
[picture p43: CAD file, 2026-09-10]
designs/closed-wall-d/exploded-plates.stl
243.0 x 240.0 x 43.2

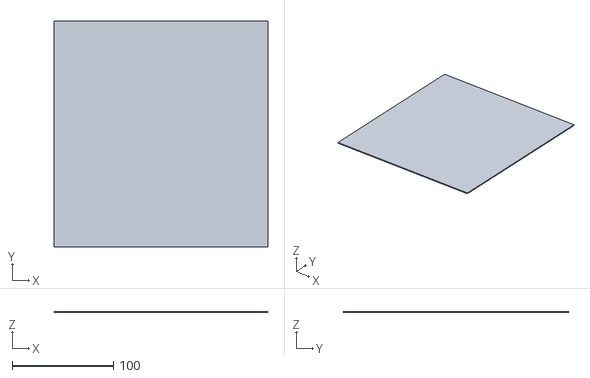
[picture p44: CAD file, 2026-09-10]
designs/closed-wall-e13/helper-1.stl
211.5 x 223.0 x 1.20

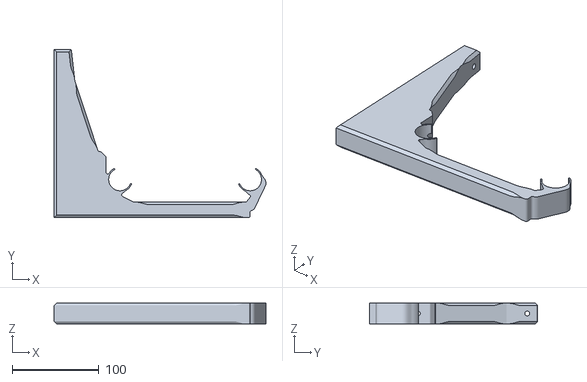
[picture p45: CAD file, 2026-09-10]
designs/closed-wall-e5/mounted.stl
244.2 x 194.0 x 24.0

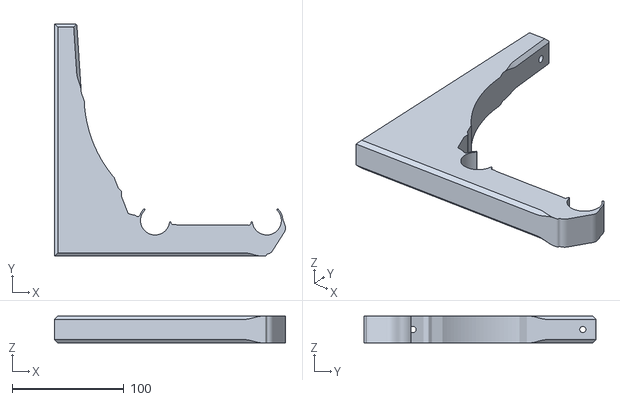
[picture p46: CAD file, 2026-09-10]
designs/closed-wall-e6/mounted.stl
206.7 x 208.0 x 24.0

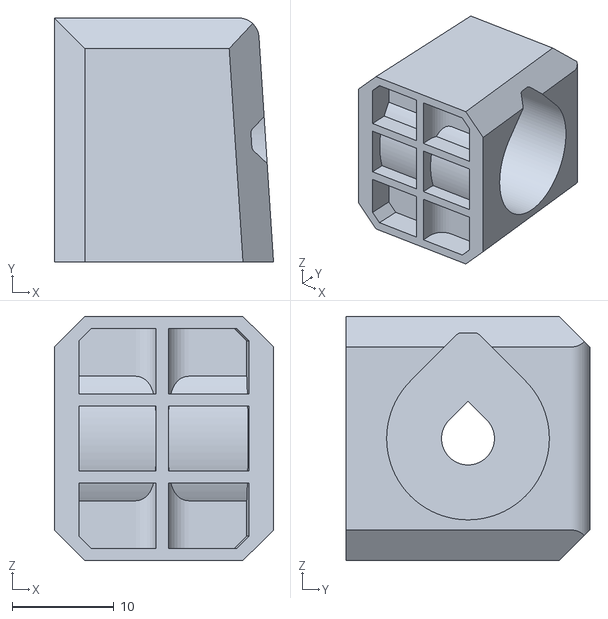
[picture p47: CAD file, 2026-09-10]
designs/closed-wall-e7/fastener-coupon.stl
21.5 x 24.0 x 24.0

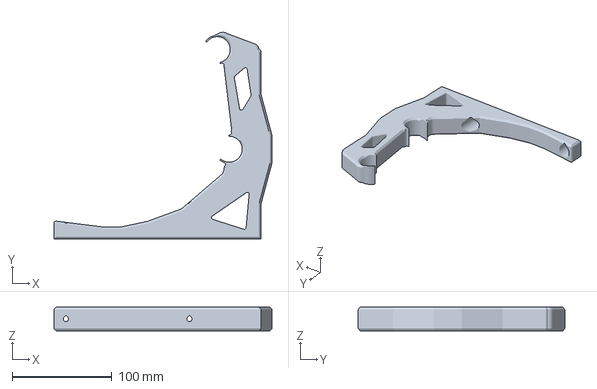
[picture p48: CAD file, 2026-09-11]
designs/rev-g/rev-g-model-and-modifiers.3mf
219.0 x 207.5 x 24.0 mm

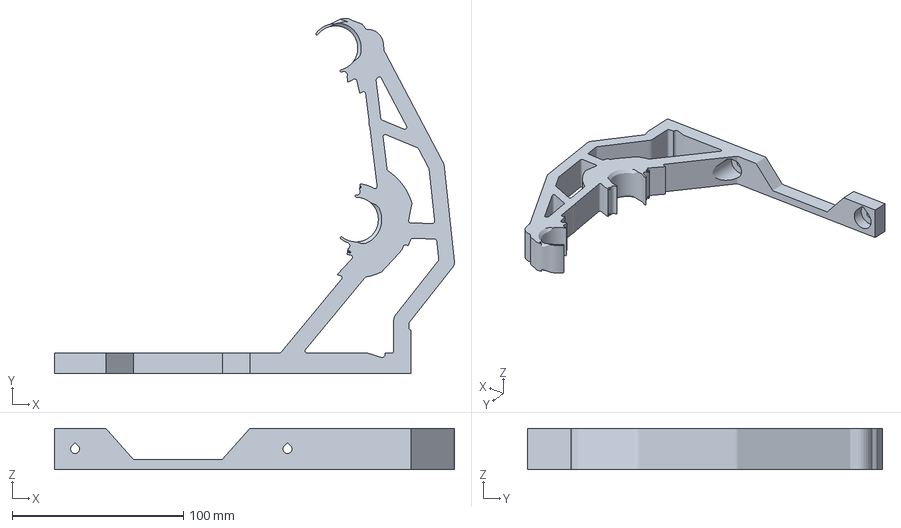
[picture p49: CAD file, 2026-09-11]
designs/rev-g2/ef-cut-v4/part-model-and-modifiers.3mf
233.5 x 207.5 x 24.0 mm

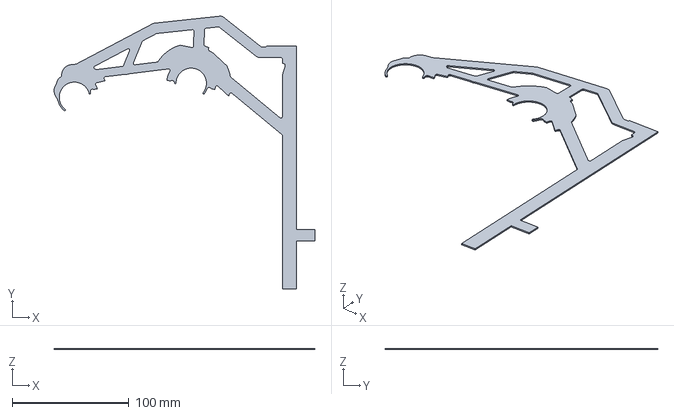
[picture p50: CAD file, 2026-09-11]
designs/rev-g2/ef-hybrid-v1/rib-plane-upper.step
223.5 x 233.5 x 1.00 mm

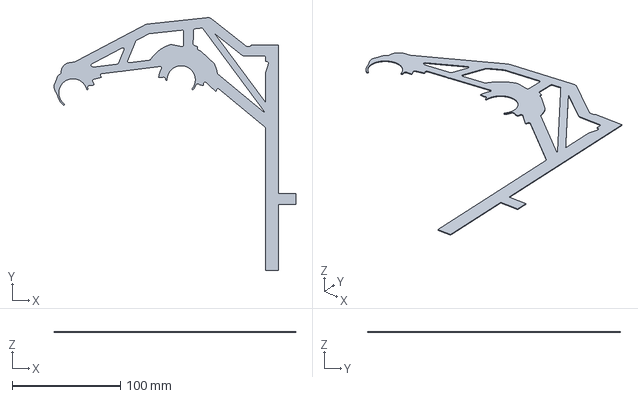
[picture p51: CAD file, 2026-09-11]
designs/rev-g2/ef-triangulated-v1/central-rib-plane.step
223.5 x 233.5 x 0.6 mm

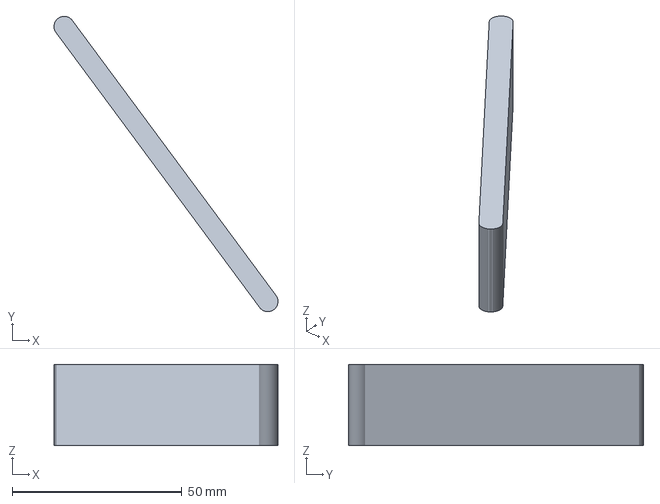
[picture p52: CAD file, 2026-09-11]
designs/rev-g2/print-controls/ef-core-asa-4w-1p6/direct-brace-core.step
66.0 x 87.0 x 24.0 mm

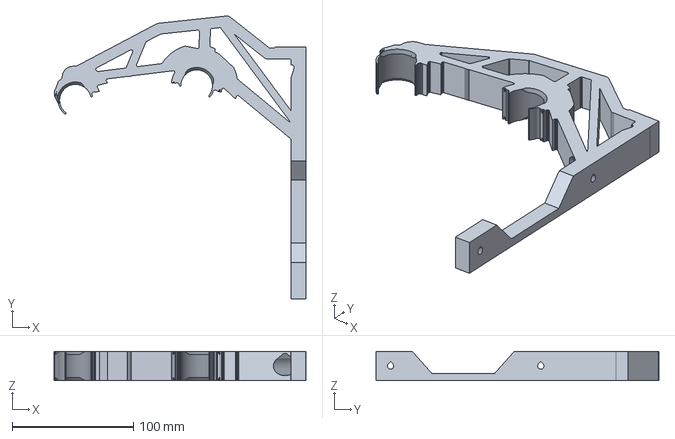
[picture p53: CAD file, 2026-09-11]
designs/rev-g2/print-controls/ef-triangulated-asa-4w-1p6/body-only.step
207.5 x 233.5 x 24.0 mm

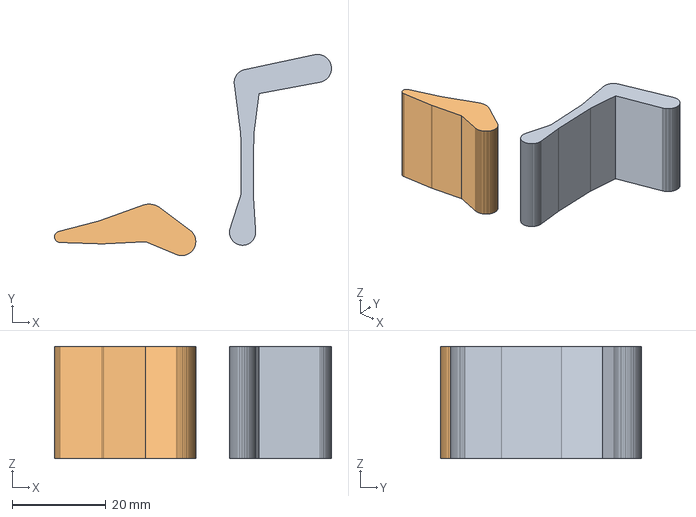
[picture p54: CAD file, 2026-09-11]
designs/rev-g2/print-controls/ef-triangulated-asa-8w-1p6/local-transition-backing.step
59.2 x 43.0 x 24.0 mm

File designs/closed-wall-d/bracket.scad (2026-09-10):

// Revision D: upward L-shaped bracket with continuous in-plane laminations.
// SIDE-PRINT axes: X = projection from wall, Y = height on wall, Z = bracket width.
// No assigned safe working load or creep life. Prior A/B caps are withdrawn.
include <profile_points.scad>
$fn=128;
part="bracket"; // bracket | profile | hollow_profile | stack_section | exploded | bridge_coupon
rod_d=25.4;
clearance_d=.6;
rear=76;
front=226;
width=24;
side_wall=1.35;       // Three 0.45 mm perimeter lines.
layer=.2;
face=1.2;             // Six 0.20 mm layers, including each internal plate.
internal_plates=2;     // 1 => 2 cavities; 2 => 3; 3 => 4.
fixings=[138,12];
wall_depth=20;
seat_r=(rod_d+clearance_d)/2;
plate_pitch=(width-face)/(internal_plates+1);
air_depth=(width-(internal_plates+2)*face)/(internal_plates+1);
assert(air_depth>0,"Too many plates for selected width");
assert(abs(air_depth/layer-round(air_depth/layer))<0.00001,"Align cavity heights to layers; use width=24.4 with 3 internal plates");
module capsule(a,b,d){hull(){translate(a)circle(d=d);translate(b)circle(d=d);}}
module outline(){
 difference(){
  offset(r=-5) offset(r=5) union(){
   polygon(profile_points);
   // Flat front bearing face for the lower screw washer.
   capsule([50,2],[50,22],20);
   for(x=[rear,front]) {
    translate([x,-28]) circle(r=13);
    intersection(){translate([x,0])circle(r=18);translate([x-19,-24])square([38,18]);}
   }
  }
  for(x=[rear,front])translate([x,0])circle(r=seat_r);
  // Maintain >=3 mm nominal clearance to every specified rigid flange.
  for(R=[90:1:110]){
   h=sqrt(pow(R+rod_d/2,2)-75*75)-clearance_d/2;
   translate([(rear+front)/2,h])circle(r=R+3);
  }
 }
}
module hollow_profile(){offset(delta=-side_wall)outline();}
module screw_holes(){for(y=fixings)translate([-1,y,width/2])rotate([0,90,0])cylinder(d=5.5,h=75);}
module sleeve_protection(){
 // Continuous sleeve joins the plates at each screw, without a transverse grid.
 for(y=fixings)translate([-1,y,width/2])rotate([0,90,0])cylinder(d=5.5+2*side_wall,h=75);
}
module air_volumes(){
 difference(){
  for(i=[0:internal_plates])translate([0,0,face+i*plate_pitch])
   linear_extrude(air_depth)hollow_profile();
  sleeve_protection();
 }
}
module bracket(){difference(){linear_extrude(width)outline();air_volumes();screw_holes();}}
if(part=="bracket") {
 // One part on P1S, broad side on bed, rotated 180 deg to clear front-left exclusion.
 translate([250,156,0])rotate([0,0,180])bracket();
}
if(part=="profile")outline();
if(part=="hollow_profile")hollow_profile();
if(part=="stack_section")intersection(){bracket();translate([105,-95,-1])cube([4,100,width+2]);}
if(part=="exploded") {
 // Visual explanation only, not an assembly or printable part.
 for(i=[0:internal_plates+1])color(i==0||i==internal_plates+1?"teal":"orange")
  translate([0,0,i*14])linear_extrude(face)outline();
}
if(part=="bridge_coupon") {
 // Actual root section, 90 mm in X, with the exact stacked cavities and faces.
 intersection(){bracket();translate([18,-95,-1])cube([90,92,width+2]);}
}
if(part=="arm_section") intersection(){bracket();translate([-1,-95,-1])cube([126,260,26]);}

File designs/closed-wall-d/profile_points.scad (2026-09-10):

profile_points=[[0.0, 150.0], [0.0, -42.0], [0.03534, -45.04111], [0.14209, -47.97729], [0.32135, -50.80911], [0.57422, -53.53711], [0.90179, -56.16183], [1.30518, -58.68384], [1.78546, -61.10367], [2.34375, -63.42188], [2.98114, -65.63901], [3.69873, -67.75562], [4.49762, -69.77225], [5.37891, -71.68945], [6.34369, -73.50778], [7.39307, -75.22778], [8.52814, -76.85001], [9.75, -78.375], [11.05975, -79.80331], [12.4585, -81.1355], [13.94733, -82.3721], [15.52734, -83.51367], [17.19965, -84.56076], [18.96533, -85.51392], [20.8255, -86.37369], [22.78125, -87.14062], [24.83368, -87.81528], [26.98389, -88.39819], [29.23297, -88.88992], [31.58203, -89.29102], [34.03217, -89.60202], [36.58447, -89.82349], [39.24005, -89.95596], [42.0, -90.0], [47.74716, -89.66098], [53.54761, -89.20972], [59.39603, -88.65115], [65.28711, -87.99023], [71.21555, -87.2319], [77.17603, -86.3811], [83.16324, -85.44278], [89.17188, -84.42188], [95.19662, -83.32333], [101.23218, -82.1521], [107.27322, -80.91312], [113.31445, -79.61133], [119.35056, -78.25168], [125.37622, -76.83911], [131.38614, -75.37857], [137.375, -73.875], [143.33749, -72.33334], [149.26831, -70.75854], [155.16214, -69.15555], [161.01367, -67.5293], [166.8176, -65.88474], [172.5686, -64.22681], [178.26138, -62.56046], [183.89062, -60.89062], [189.45102, -59.22226], [194.93726, -57.5603], [200.34402, -55.9097], [205.66602, -54.27539], [210.89792, -52.66232], [216.03442, -51.07544], [221.07022, -49.51968], [226.0, -48.0], [227.1835, -47.59644], [228.29614, -47.13867], [229.33737, -46.6311], [230.30664, -46.07812], [231.2034, -45.48413], [232.0271, -44.85352], [232.77719, -44.19067], [233.45312, -43.5], [234.05435, -42.78589], [234.58032, -42.05273], [235.03049, -41.30493], [235.4043, -40.54688], [235.7012, -39.78296], [235.92065, -39.01758], [236.0621, -38.25513], [236.125, -37.5], [236.1088, -36.75659], [236.01294, -36.0293], [235.83688, -35.32251], [235.58008, -34.64062], [235.24197, -33.98804], [234.82202, -33.36914], [234.31967, -32.78833], [233.73438, -32.25], [233.06558, -31.75854], [232.31274, -31.31836], [231.47531, -30.93384], [230.55273, -30.60938], [229.54446, -30.34937], [228.44995, -30.1582], [227.26865, -30.04028], [226.0, -30.0], [92.0, -30.0], [90.16562, -29.9794], [88.41089, -29.91724], [86.73343, -29.81296], [85.13086, -29.66602], [83.6008, -29.47586], [82.14087, -29.24194], [80.74869, -28.96371], [79.42188, -28.64062], [78.15805, -28.27213], [76.95483, -27.85767], [75.80984, -27.3967], [74.7207, -26.88867], [73.68503, -26.33304], [72.70044, -25.72925], [71.76456, -25.07675], [70.875, -24.375], [70.02939, -23.62344], [69.22534, -22.82153], [68.46048, -21.96872], [67.73242, -21.06445], [67.03879, -20.10818], [66.3772, -19.09937], [65.74527, -18.03745], [65.14062, -16.92188], [64.56088, -15.75211], [64.00366, -14.52759], [63.46658, -13.24777], [62.94727, -11.91211], [62.44333, -10.52005], [61.95239, -9.07104], [61.47208, -7.56454], [61.0, -6.0], [24.0, 114.0], [23.6366, 115.21582], [23.2959, 116.42578], [22.97717, 117.62988], [22.67969, 118.82812], [22.40271, 120.02051], [22.14551, 121.20703], [21.90735, 122.3877], [21.6875, 123.5625], [21.48523, 124.73145], [21.2998, 125.89453], [21.13049, 127.05176], [20.97656, 128.20312], [20.83728, 129.34863], [20.71191, 130.48828], [20.59973, 131.62207], [20.5, 132.75], [20.41199, 133.87207], [20.33496, 134.98828], [20.26819, 136.09863], [20.21094, 137.20312], [20.16248, 138.30176], [20.12207, 139.39453], [20.08899, 140.48145], [20.0625, 141.5625], [20.04187, 142.6377], [20.02637, 143.70703], [20.01526, 144.77051], [20.00781, 145.82812], [20.0033, 146.87988], [20.00098, 147.92578], [20.00012, 148.96582], [20.0, 150.0]];

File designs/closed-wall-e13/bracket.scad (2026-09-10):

// Revision E13: solid exterior profile with load-aligned snaps.
// Run build_step.py for solid envelope, recessed fasteners and helper solids.
// Raw SCAD bracket is an intermediate envelope, not the released DFM solid.
// upward L-shaped bracket with continuous in-plane laminations.
// SIDE-PRINT axes: X = projection from wall, Y = height on wall, Z = bracket width.
// No assigned safe working load or creep life. Prior A/B caps are withdrawn.
// Angular structural profile; snap geometry remains smoothly curved.
wall_bottom=-32; wall_top=176;
front_lift=12;
// Straight reinforcement facets, with the existing small corner finish.
// Eleven millimetres added depth stays below the 38/3 mm absolute cap.
// Long flanks carry the thickening into the knee and outer arm without steps.
seat_extra_depth=11;
profile_points=[[0,176],[0,-32],[35,-32],[76,-32-seat_extra_depth],
 [104,-32-seat_extra_depth],[145,-32],[190,-32],[190,7.2],
 [110,-2.4],[66,6],[30,48],[17.5,82],[12,108],[12,128],[18,176]];
include <retainer_geometry.scad>
$fn=128;
part="profile"; // profile only; final STEP assembly is built by build_step.py
rod_d=25.4;
clearance_d=.6;
rear=90;
front=190;
width=24;
seat_r=(rod_d+clearance_d)/2;
module capsule(a,b,d){hull(){translate(a)circle(d=d);translate(b)circle(d=d);}}
module arm_outline(){
 difference(){
  offset(r=2) offset(r=-2) offset(r=-2) offset(r=2) union(){
   polygon(profile_points);
   // E13 removes the obsolete projecting lower screw-head pad.

  }
  for(c=[[rear,0],[front,front_lift]])translate(c)circle(r=seat_r);
  // Maintain >=3 mm nominal clearance to every specified rigid flange.
  for(R=[90:1:110]){
   S=sqrt(100*100+front_lift*front_lift);
   q=sqrt(pow(R+rod_d/2-clearance_d/2,2)-S*S/4);
   translate([140-front_lift*q/S,front_lift/2+100*q/S])circle(r=R+3.5);
  }
 }
}
// Fresh bearing buttresses replace all former open-saddle lips and circular nodes.
module bearing_patch(){sector(snap_seat_r+2.5,snap_seat_r+bearing_t,245,295);}
module bearing_bridge(x,is_front=false){
 hull(){
  translate([x,-24])circle(r=6);
  translate([x,is_front ? front_lift : 0])if(is_front)rotate(front_rotation)bearing_patch();
  else rotate(rear_rotation)bearing_patch();
 }
}
module seat_structure(){
 union(){
  difference(){arm_outline();for(c=[[rear,0],[front,front_lift]])translate(c)circle(r=relief_pocket_r);}
  bearing_bridge(rear);
  bearing_bridge(front,true);
 }
}
module blended_outline(){
 rounded_profile() union(){
  seat_structure();
  // Larger rigid shoulder blends; retain the relief pockets around the snaps.
  intersection(){
   difference(){
    offset(r=-6,$fn=192)offset(r=6,$fn=192)seat_structure();
    for(c=[[rear,0],[front,front_lift]])translate(c)circle(r=relief_pocket_r);
   }
   // Localize the addition to the rear shoulders; other body corners stay R2.
   translate([55,-25])square([70,70]);
  }
  translate([rear,0])rear_collar();
  translate([front,front_lift])front_collar();
 }
}
// Square wall-side end lands keep the back coplanar for its full height.
// Exposed body and snap edges retain their existing blends.
module outline(){union(){blended_outline();translate([0,wall_bottom])square([4,wall_top-wall_bottom]);}}
// Final solid body, fastener features and helper slabs are built by:
// fastener_geometry.py + build_step.py. Do not export an unfinished full bracket here.
if(part=="profile")outline();
if(part=="bracket")assert(false,"Build the finished E13 solid with build_step.py");

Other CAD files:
designs/rev-g2/ef-reinvest-v2/part-model-and-modifiers.3mf
designs/rev-g2/print-controls/ef-triangulated-asa-6w-1p6/part-model-and-modifiers.3mf
designs/rev-g2/print-controls/g-asa-4w-1p6/part-model-and-modifiers.3mf
designs/rev-g2/print-controls/g-asa-8w-1p6/part-model-and-modifiers.3mf
designs/rev-g2/print-controls/g-petg-4w-1p6/part-model-and-modifiers.3mf
designs/closed-wall-e13/retainer_geometry.scad
designs/closed-wall-d/arm-section.stl
designs/closed-wall-d/bracket.3mf
designs/closed-wall-d/bracket.stl
designs/closed-wall-d/bridge-coupon.stl
designs/closed-wall-e1/bracket.scad
designs/closed-wall-e1/bracket.stl
designs/closed-wall-e1/retainer_geometry.scad
designs/closed-wall-e1/snap-coupon-8mm.stl
designs/closed-wall-e10/body-mounted.stl
designs/closed-wall-e10/body-only.step
designs/closed-wall-e10/body-only.stl
designs/closed-wall-e10/bracket-with-modifier-helpers.step
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

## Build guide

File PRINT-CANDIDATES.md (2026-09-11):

# Printable CAD checkpoint index

## Current print controls and connected brace

Eight deliberate print controls have aligned body/helper STEP, model-only 3MF, actual Orca slices, settings audits and source hashes. The successful recovered ASA print is associated with E13 and seven walls, not the eight-wall G control used as this study's denominator.

https://github.com/thereprocase/spool-wall-rack/tree/main/designs/rev-g2/print-controls

https://github.com/thereprocase/spool-wall-rack/blob/main/designs/rev-g2/print-controls/RECOVERED-PRINTS.md

The direct-core E+F trial cuts 27.048% before reinvestment, adds back 5.406 cm3, and retains 22.492% net saving. Its 4.9818 mm intermediate movement diagnostic exceeds the 4 mm allocation. Numerical tightening fails its bound. The complete handoff is retained as an implemented, rejected stiffness trial.

https://github.com/thereprocase/spool-wall-rack/tree/main/designs/rev-g2/print-controls/ef-core-asa-4w-1p6

The upper-mast cut and earlier connected helper trial also have complete CAD/slice handoffs. Their percentages use the older two-wall, 1.0 mm skin G reference.

https://github.com/thereprocase/spool-wall-rack/tree/main/designs/rev-g2/ef-cut-v4

https://github.com/thereprocase/spool-wall-rack/tree/main/designs/rev-g2/ef-reinvest-v2

## Implemented E + F material-allocation trials

These historical thin-reference schedules have aligned body/helper STEP files, model-only 3MF, actual P1S PETG
slicing, checks and hashes. They are experimental and physically unqualified.
The matched G slice spends 74.100 cm3. Sacrificial bridges count in these totals
and receive no structural or bond credit.

| Candidate | Spent extrusion, cm3 | Saving versus G | Role |
|---|---:|---:|---|
| ef-hybrid-v1 | 73.007 | 1.475% | First reinforced reference; accepted numerical screen is worse than G |
| ef-lean-v1 | 65.966 | 10.977% | Intermediate material trial; mechanics untested |
| ef-lean-v2 | 61.613 | 16.851% | Intermediate material trial; mechanics untested |
| ef-cut-v3 | 52.454 | 29.211% | Intermediate 1e-4 diagnostic; tight check failed |
| ef-reinvest-v1 | 58.796 | 20.653% | Adds 6.342 cm3; stiffness remains inadequate |

Browse each handoff for direct STEP/helper/3MF downloads and verification.

https://github.com/thereprocase/spool-wall-rack/tree/main/designs/rev-g2/ef-hybrid-v1

https://github.com/thereprocase/spool-wall-rack/tree/main/designs/rev-g2/ef-lean-v1

https://github.com/thereprocase/spool-wall-rack/tree/main/designs/rev-g2/ef-lean-v2

https://github.com/thereprocase/spool-wall-rack/tree/main/designs/rev-g2/ef-cut-v3

https://github.com/thereprocase/spool-wall-rack/tree/main/designs/rev-g2/ef-reinvest-v1

The six broader architecture seeds remain XY sketches. The selected E+F hybrid
is now built separately. Preserve G's lower locating datum and the 25.4 mm
horizontal underside from the wall; keep the fixed rod/mount positions and
spool clearance. Previous CAD handoffs remain preserved below.

## G evolutionary helper variants

[Screening workflow and measured timings](analysis/rev-g2/EVOLUTION.md).
The 100 reduced proposals are parameter evaluations. These three selected
variants have actual body/helper STEP assemblies and model-only 3MF files.
They use the G body, two walls, five top/bottom layers, 0% base infill and
100% helpers. These are experimental handoffs with unresolved qualification.

| Candidate | Aligned assembly | Notes and individual helpers |
|---|---|---|
| Balanced screen leader, f9ad9cdbc331 | [STEP](designs/rev-g2/evolution/f9ad9cdbc331/bracket-with-modifiers.step) | [Handoff](designs/rev-g2/evolution/f9ad9cdbc331/README.md) |
| Second stiffness candidate, 0c3bac68efa9 | [STEP](designs/rev-g2/evolution/0c3bac68efa9/bracket-with-modifiers.step) | [Handoff](designs/rev-g2/evolution/0c3bac68efa9/README.md) |
| Lighter inner-seat helper, 9be1dd4d87d3 | [STEP](designs/rev-g2/evolution/9be1dd4d87d3/bracket-with-modifiers.step) | [Handoff](designs/rev-g2/evolution/9be1dd4d87d3/README.md) |

Fresh 10.75 / 12 / 13.25 kg G contact checks are documented in [G results](analysis/rev-g2/G-RESULTS.md). One spool changes bracket movement by about 0.452 mm; material accuracy and physical qualification remain open.

Geometry handoffs with helper solids and notes. Keep all relative body/helper positions. Import each STEP assembly as one object with multiple parts: the body prints, helpers become 100% infill modifiers. External tabs/halos must never print. STEP carries geometry, not slicer settings. Use OrcaSlicer and a calibrated printer/material profile. These are experimental geometries, not released load ratings.

[Completed G contact screen](analysis/rev-g2/G-RESULTS.md): 4.3355 mm maximum
movement and 20.0254 MPa raw peak tensile stress at 12 kg in the retained-material
model. Contact and numerical sensitivity are checked; 8.02% material omission
and physical qualification remain unresolved. The existing aligned G body and
three helper exports below are the exact CAD handoff; no new architecture is added.

## Current G recheck schedules

All five use the same unchanged G body and aligned helpers. Their differences are slicer settings. Each page links the combined STEP, individual helpers, exact settings and raw slice evidence. The old G 3MF defaults are historical; the current recheck requires at least two walls and 0% base infill.

| Schedule | STEP, helpers and notes |
|---|---|
| 2 walls / 2 top and bottom layers | [Handoff](designs/rev-g2/g-recheck/2w-2layers/README.md) |
| 2 walls / 5 top and bottom layers | [Handoff](designs/rev-g2/g-recheck/2w-5layers/README.md) |
| 2 walls / 8 top and bottom layers | [Handoff](designs/rev-g2/g-recheck/2w-8layers/README.md) |
| 8 walls / 2 top and bottom layers | [Handoff](designs/rev-g2/g-recheck/8w-2layers/README.md) |
| 8 walls / 8 top and bottom layers | [Handoff](designs/rev-g2/g-recheck/8w-8layers/README.md) |

The 2w/5-layer reference has a corrected 2D diagnostic and the eroded-material
3D contact screen linked above. Physical strength remains unqualified.

[Adaptive mesh and P1S/PETG demo checkpoint](analysis/rev-g2/ADAPTIVE-MESH.md):
the implemented coarse/fine GPU adapter passes independent fixtures and
halves the protected 0.2 mm G mesh. That checkpoint predates the completed contact screen linked above.
The separate fresh PETG slice reuses G's existing body and three helpers;
it adds no architecture or physical qualification to the handoffs below.

[GPU validation checkpoint](analysis/rev-g2/GPU-VALIDATION.md): an installed
free GPU backend passes small 3D fixtures and an actual-slice crop patch test.
The crop's voxel material loss remains unresolved. This adds analysis evidence;
the eight implemented handoffs and five slicing schedules below are unchanged.

## Implemented recent architecture alternatives

| Idea | Aligned STEP body plus helpers | Notes |
|---|---|---|
| G full-plane research finalist | [STEP](designs/rev-g/bracket-with-modifiers.step) | [Notes](designs/rev-g/README.md) |
| G thin shaped planes, seed 1 | [STEP](designs/rev-g/studies/seed1-best/bracket-with-modifiers.step) | [Notes](designs/rev-g/studies/seed1-best/README.md) |
| G archived full-plane best | [STEP](designs/rev-g/studies/full-plane-best/bracket-with-modifiers.step) | [Notes](designs/rev-g/studies/full-plane-best/README.md) |
| G wider inner-seat support | [STEP](designs/rev-g/studies/seat-support/bracket-with-modifiers.step) | [Notes](designs/rev-g/studies/seat-support/README.md) |
| G repaired F light helpers | [STEP](designs/rev-g/studies/repaired-f-light/bracket-with-modifiers.step) | [Notes](designs/rev-g/studies/repaired-f-light/README.md) |
| F shaped planes / three walls | [STEP](designs/rev-f/bracket-with-modifiers.step) | [Notes](designs/rev-f/README.md) |
| F full planes / four walls | [STEP](designs/rev-f/studies/full-plane-4w/bracket-with-modifiers.step) | [Notes](designs/rev-f/studies/full-plane-4w/README.md) |
| E13 continuous body and helpers | [STEP](designs/closed-wall-e13/bracket-with-modifier-helpers.step) | [Notes](designs/closed-wall-e13/README.md) |

Each notes page includes the original process choices, illustrations and geometry/slicing/mechanical status. Historical one-wall candidates remain evidence only; the G2 minimum of two walls requires a new slice and analysis before reuse. Old G material approximations do not establish failure or success of the corrected print.

## G2 concepts awaiting CAD

[Seven-family worksheet](designs/rev-g2/ARCHITECTURE-WORKSHEET.md): continuous plates, triangular frame, closed-section seat arms, cross-width portal, drop cradle, thick-seat portal, and layered shear box. These are concept notes, not printable candidates. Every future checkpoint must include its parameterized body, aligned STEP helpers, sections, process notes and actual slicing evidence. This remains explicit unfinished work in the restart handoff.

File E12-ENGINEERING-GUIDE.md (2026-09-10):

# Archived E12 engineering guide

This is the E12 snapshot. See [the current guide](README.md) for the active design.

# Spool wall rack — E12 print and engineering guide

**Current prototype: E12 — a shallow, smooth inner-seat reinforcement with
one-quarter of E11's protrusion.** Added depth is **9.5 mm**, down from 38 mm,
meeting the preferred quarter-depth target and the 12.67 mm maximum.

**[Download E12 STEP with aligned helpers](designs/closed-wall-e12/bracket-with-modifier-helpers.step)** ·
[CAD and print checks](designs/closed-wall-e12/README.md) ·
[Updated FEA and material results](analysis/e12/RESULTS.md) · [Design journal](DESIGN-JOURNAL.md)

Current E12 finished CAD

## Smaller shape, measured tradeoff

The added underside depth is **75% smaller**, blended across a broader span.
The inner center section is approximately **28.5 mm deep**, compared with 19 mm
in E10 and 57 mm in E11. The finished body envelope is now approximately
**207.51 × 217.50 × 24 mm**.

E12 and E11 depth comparison

The matched reduced-model comparison gives **31.7–32.5% lower near-seat stress
than E10**, compared with E11's 37.4–37.6%. Front movement is only **5.6–7.1%
higher than E11**. With only the outer rod loaded, E12's near-seat stress
statistic is about **35% lower than E10**. No relief holes were added: the
continuous shallow blend already retains most of the measured benefit.
[Exact three-revision comparison](analysis/e12/COMPARISON.md).

The finished ideal printed section has at least **2.77× E10's minimum
seat-band bending I** and **1.85× its elastic section modulus**. It **does
not exceed both adjacent arms**. The explicit depth cap supersedes that E11
margin target; the adjacent arms were not weakened to force a favorable ratio.
[Section comparison and ratios](designs/closed-wall-e12/section-verification.json).

The R6 rigid shoulder blends, functional fingers and relief pockets are
preserved. Both broad-face chamfers retain **2 mm face inset, 2.384 mm rise and
50° above the bed**, mirrored on the reverse face. Other exposed body corners
retain their smaller finish, with smooth chamfer runouts at thin retainers.

Profile and finished section

[Inner-seat close-up](designs/closed-wall-e12/finish-inner-front.png) ·
[Reverse face](designs/closed-wall-e12/finish-inner-reverse.png) ·
[Outer fingers](designs/closed-wall-e12/finish-outer-front.png).

The rear/front rail centers stay at (90,0)/(190,12) mm. The 322-case nominal
180–220 mm spool sweep retains **3.927 mm minimum clearance**. All four flexible
finger sectors match E10 at nine print depths; this checks geometry, not
physical insertion force, fatigue or rod tolerance.

## Print setup

Print on the supplied broad side. Import the STEP as **one object with three
aligned parts**, so the main bending load stays in the layer plane.

| Setting | Working value |
|---|---|
| Body footprint / height | **207.51 × 217.50 × 24 mm**; check bed exclusions |
| Layer / first layer | **0.20 / 0.20 mm** |
| Reference nozzle | 0.4 mm |
| Outer / inner nominal line widths | 0.42 / 0.45 mm |
| Wall generator / solid-region gap fill | **Arachne / Everywhere** |
| PLA prototype walls | **8**, about 3.27 mm ideal contour thickness |
| PETG prototype walls | **10**, about 4.08 mm ideal contour thickness |
| Body infill | **15%**, zero structural credit |
| Exterior top / bottom | **1.2 / 1.2 mm**, six layers each |
| Helper 1 | **100% infill modifier**, Z=7.6–8.8 mm |
| Helper 2 | **100% infill modifier**, Z=15.2–16.4 mm |
| Filament process | Exact grade's calibrated temperature, cooling, flow and bonding |

1. Keep the main body printable with the selected walls, 15% infill and six
   top/bottom layers.
2. Convert both named helpers to **100% infill modifiers** in their supplied
   positions. They must not print as extra exterior slabs.
3. Inspect all four solid bands, seat perimeters, fingers, screw lands and
   access roofs; then save the configured machine/filament project.

STEP stores geometry and alignment, not modifier status or print settings.
[STL fallback and detailed handoff](designs/closed-wall-e12/README.md).

Modifier stack

Actual E12 OrcaSlicer paths

**Both OrcaSlicer 2.4.2 audits pass:** 120 layers, all 24 intended solid-band
layers checked around the inner seat, plus sampled full L-planes, walls and
fingers. Minimum nominal footprint coverage is **99.82% in the seat bands,
99.99% in sampled seat walls and 99.84% in sampled fingers**, with a
0.03 mm tessellation/rounding allowance. These neutral slices do not qualify
bonding, bridging, curling or an actual filament process.
[Toolpath evidence](designs/closed-wall-e12/toolpath-verification.json).

The contour estimate remains
`t(n) = 0.42 + (n − 1) × [0.45 − 0.2 × (1 − π/4)] mm`.
Arachne varies thin-feature widths; actual paths govern. Keep the four 1.2 mm
plates if changing nozzle or wall count. Sparse infill supports the plates
during printing while receiving zero structural credit in the analysis.

## Updated stress and material results

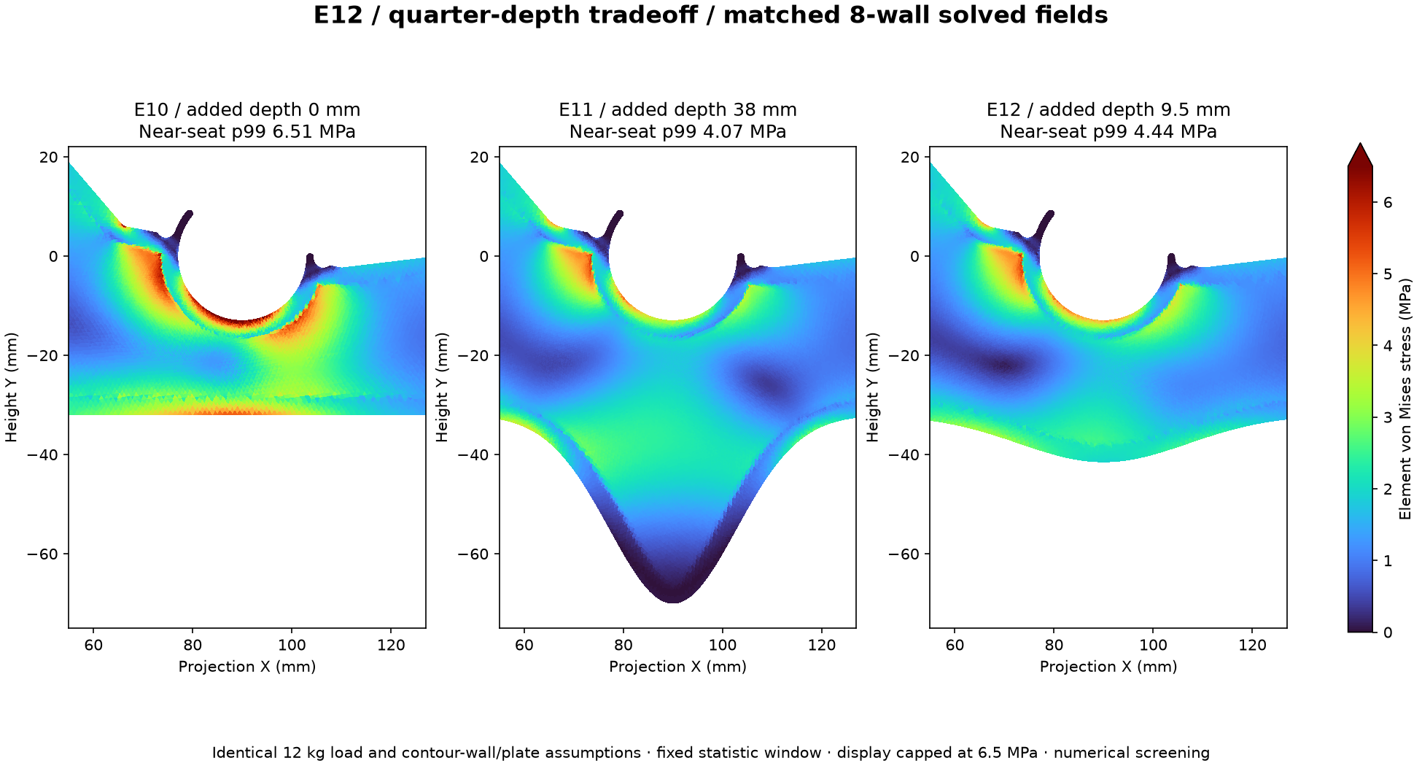
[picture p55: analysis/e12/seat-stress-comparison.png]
Matched E10/E11/E12 stress


New E12 3D solves include the finished exterior, ideal contour walls, four
continuous plates, fastener openings, compression-only wall contact, rigid
washer axial restraints and rigid shank shear restraints. No clamp friction or
arbitrary preload is credited. Sparse core is removed only in the analysis.

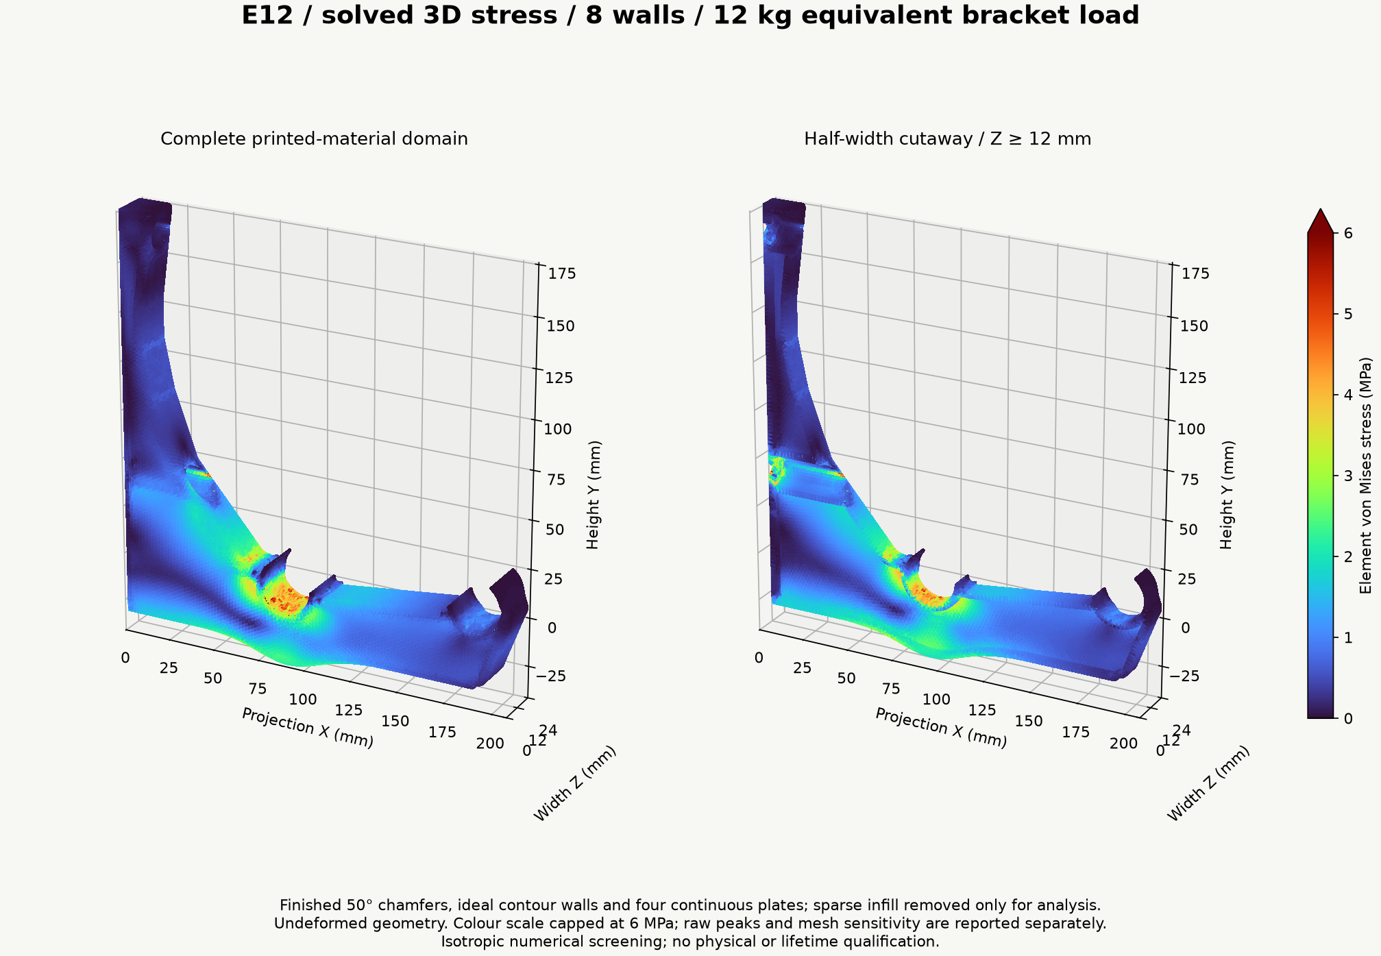
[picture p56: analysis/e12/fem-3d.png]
E12 3D stress and cutaway


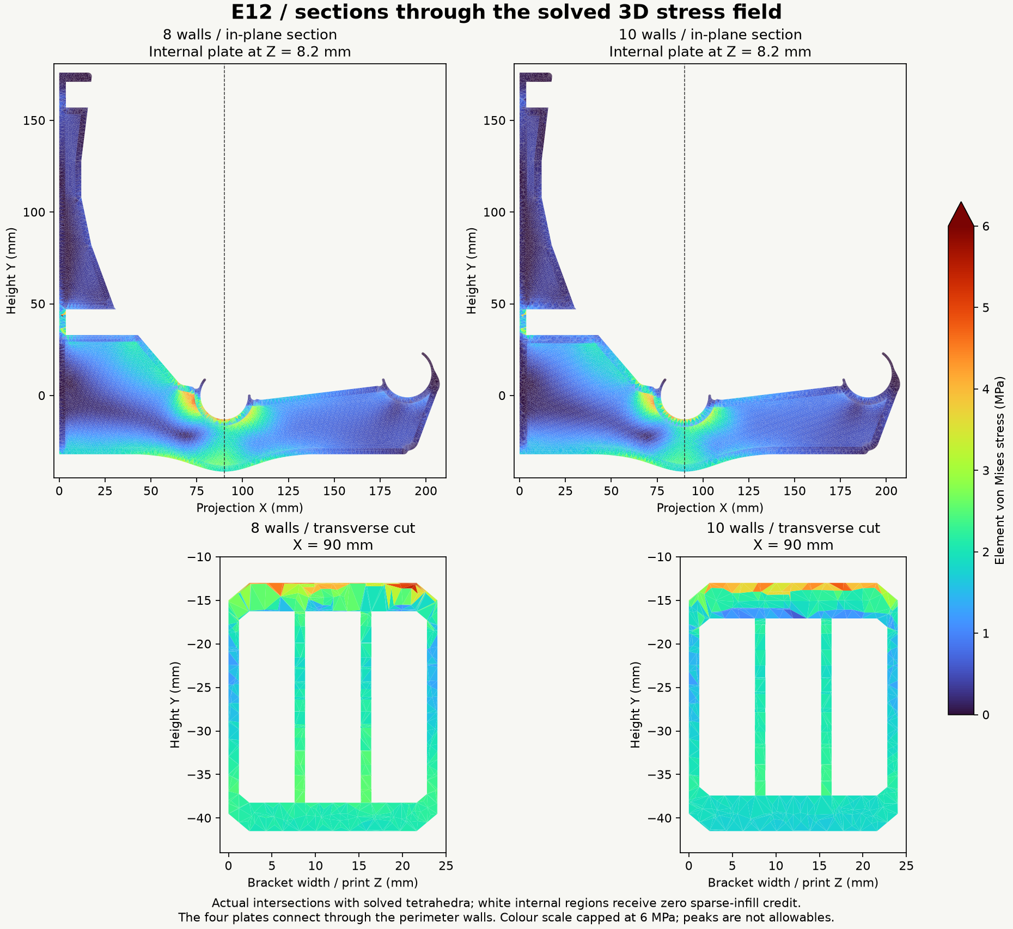
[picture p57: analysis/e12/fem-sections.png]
E12 stress sections


| Walls | Tetrahedra, coarse → fine | Movement refinement change | Near-seat p99, coarse → fine |
|---:|---:|---:|---:|
| 8 | 136,844 → 209,627 | 2.35% | 3.99 → 4.34 MPa |
| 10 | 159,490 → 211,444 | 1.43% | 3.94 → 4.10 MPa |

All six published 3D fields pass independently recomputed residual, force and
moment balance below 1e-6. The refined reduced and 3D movement coefficients
agree within 0.85%. These are numerical checks, not independent physical
validation or proof of asymptotic convergence. Raw refined peaks are
**35.2 / 38.9 MPa** for 8/10 walls and are not rupture allowables.
[Raw fields, rejected mesh attempts and full results](analysis/e12/RESULTS.md).

The criteria remain **5 mm total loaded movement**, including dowels and
mounts, and **1 mm change when adding/removing one full spool**. At the 12 kg
reference load, the new front coefficients are **K=2472.5 MPa·mm for 8 walls**
and **2241.9 for 10 walls**.

| Reference material | Walls | Initial front movement | One 1.25 kg roll | Ec for 5 mm bracket-only |
|---|---:|---:|---:|---:|
| PLA | 8 | 0.722 mm | 0.075 mm | 495 MPa |
| PETG | 10 | 0.970 mm | 0.101 mm | 448 MPa |
| ASA | 8 | 1.039 mm | 0.108 mm | 495 MPa |
| PA6-GF dry | 8 | 0.462 mm | 0.048 mm | 495 MPa |
| PA6-GF wet | 8 | 1.379 mm | 0.144 mm | 495 MPa |

These are retained grade-specific room-temperature XY moduli, not measured hot
or aged properties. [Exact grades, conditions, sources and hashes](designs/closed-wall-e6/material-reference-data.json).
The [updated material report](analysis/e12/RESULTS.md) includes 24 kg linear
proof scaling, landing checks and explicit one-, five- and ten-year creep
sensitivities. No lifetime safe spool count is assigned.

For common linear-viscoelastic compliance with unchanged contact,
`δ(t,T) = K × J(t,T) = K / Ec(t,T)`.
The complete rack requires **Ec ≥ K / (5 mm − dowel movement − mount movement)**.
Keep the project screening target of **at least 1.0 GPa effective creep modulus**
at the intended age and temperature history. It is not a grade allowable.

The service envelope stays **85°F sustained and 100°F for six loaded hours/year**.
Short-time creep examples, assumed long-time tails, HDT and generic tensile
strength do not establish multi-year performance. PA6-GF dry/wet conditioning
and annealing remain separate; fast spool unloading uses aged instantaneous
modulus rather than reversal of accumulated creep.

## Loads, rods and installation

The analysis target is **12 kg equivalent / 117.72 N per bracket**. For the
documented 180 mm spool contact case, the rear/front seats receive **75.12 / 42.60 N
downward**, plus **31.29 N outward each**. The front rail remains 12 mm higher;
the back arm accommodates the rearward-shifted spool. The retained
[rail-statics explanation](E10-ENGINEERING-GUIDE.md#current-rail-geometry-12-mm-front-lift)
describes that load split.

At 406.4 mm (16-inch) support spacing and 1.25 kg gross per spool, six spools per
bay weigh 7.5 kg and need pitch ≤67.7 mm. An interior support between simple
spans carries about one bay; the stated two-equal-span continuous example gives
1.25 times the bay load, or 9.375 kg before self-weight. The 12 kg target includes
margin for that example, not every loading pattern. **Six per bay is a proposed
test arrangement, not a released safe count.**

The **24 kg brief proof scenario** doubles the linear fields with unchanged
contact; it is neither a damage simulation nor a performed proof test.

| Hardware feature | E12 geometry |
|---|---:|
| Nominal screw clearance | Ø5.2 mm, with printable roof relief |
| Washer face to wall | 3.6 mm |
| Nominal driver access / checked straight envelope | Ø16 / Ø15.8 mm |
| Checked washer | Ø13 OD / Ø5.5 ID |
| Screw axes in installed coordinates | Y = 164 / 40 mm, Z = 12 mm |

The global model attracts about **203–208 N outward demand at the lower washer**
and **15 N at the upper**, excluding tightening preload. The new 500 N
upper-landing submodel gives **0.01207 mm** mean compression at E1000 and a
**5.00 MPa** raw peak; its movement changes 1.68% on refinement.

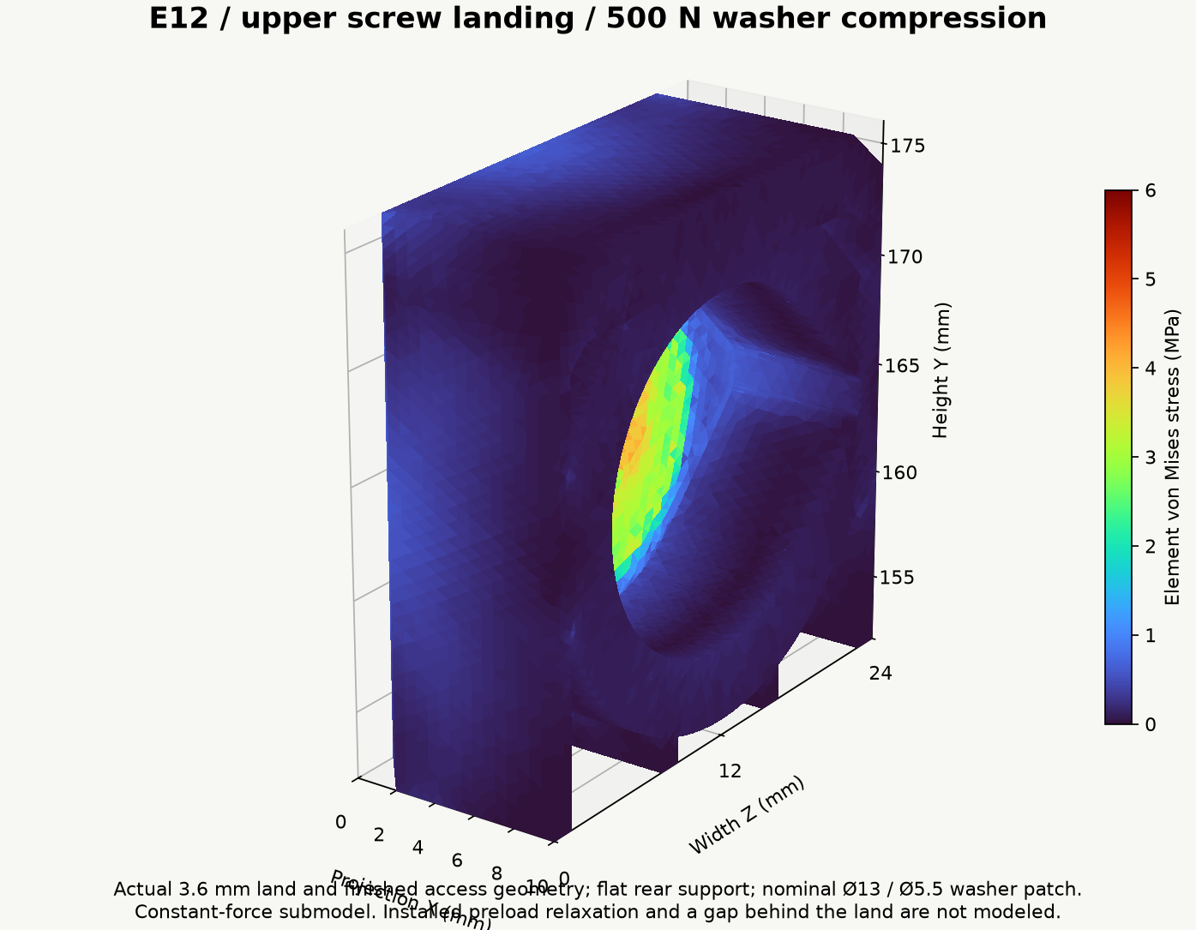
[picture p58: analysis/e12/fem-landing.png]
E12 screw-landing stress


Retain the backed 3.6 mm land. Mount against a flat, firm surface; a gap changes
the land into a bending/punching problem. Use flat-bearing heads and washers,
substrate-appropriate screws, and the manufacturer's pilot/embedment guidance.
M5 shank clearance does not make an M5 machine screw suitable for wood. Driving
torque does not reliably establish clamp force. Service and preload von Mises
maxima cannot simply be added as scalars.

**Rod fit remains provisional.** The 26.0 mm seat assumes nominal 25.4 mm stock.
The checked retail listings specify 1-inch actual diameter but no numeric
production/ovality tolerance. Measure the rods and use the
[full-width fit coupons and measurement plan](fit/README.md).

## Qualification and reproduction

The remaining print checks are physical: fit, snap insertion/retention, bonded
layers, supported internal bands and the actual filament process. Measure
immediate loaded movement and drift, rear/front seat positions, dowel sag and
wall/washer movement. Include the sustained 85°F condition and a six-hour loaded
100°F exposure; inspect for cracking, whitening, layer separation, permanent
snap opening and progressive embedment. A proof test or 1,000-hour trial alone
does not establish ten-year creep-rupture life.

[CAD rebuild and verification](designs/closed-wall-e12/README.md) ·
[Analysis reproduction and solver checks](analysis/e12/README.md) ·
[Machine-readable engineering summary](analysis/e12/engineering-summary.json).

The [deeper E11 guide](E11-ENGINEERING-GUIDE.md), [E10 guide](E10-ENGINEERING-GUIDE.md), [E9 analysis](analysis/e9/RESULTS.md)
and [level-rail E8 guide](E8-ENGINEERING-GUIDE.md) are preserved as earlier
baselines. [Design journal](DESIGN-JOURNAL.md) · [Design decisions](DESIGN.md) ·
[Separate future open-web exploration](future/open-web/README.md).

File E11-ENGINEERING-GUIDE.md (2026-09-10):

# Archived E11 engineering guide

Historical 38 mm reinforcement; E12 supersedes this shape and its current-status claims.
For the current prototype use [README](README.md).

# Spool wall rack — E11 print and engineering guide

**Current prototype: E11 — reinforced inner seat, smooth rigid-shoulder blends,
and mirrored 50° broad-face chamfers.** The inner-seat section now exceeds both
adjacent plain-arm reference bands in local bending stiffness and elastic
section modulus. The flexible fingers, rail centers and hardware geometry are
preserved.

**[Download E11 STEP with aligned helpers](designs/closed-wall-e11/bracket-with-modifier-helpers.step)** ·
[STL fallback and CAD checks](designs/closed-wall-e11/README.md) ·
[New E11 FEA and material results](analysis/e11/RESULTS.md) ·
[Design journal](DESIGN-JOURNAL.md)

Current finished E11 CAD

## What E11 improves

- Added **38 mm of smoothly blended underside depth** beneath the inner rod.
  The center section is approximately **57 mm deep**, up from 19 mm in E10.
- Across the seat band, the finished ideal printed section has at least
  **54% more bending I and 28% more elastic section modulus** than the stronger
  adjacent plain-arm reference band. The comparison includes the new runouts
  in those adjacent bands; it is not a solid-envelope-only calculation.
- Applied **R6 blends to the rigid rear shoulders**, retaining the relief
  pockets, functional finger roots and smaller nose radii. Other exposed
  body-facet joins keep their nominal R2 finish.
- Kept the **2 mm face inset** and changed the chamfer rise to **2.384 mm**:
  **50° above the bed plane**, mirrored on the opposite face. At 0.2 mm layers,
  nominal lateral growth is 0.168 mm per layer. Runouts occur only near the
  thin retainers.

E11 profile and actual finished section

[Section-property comparison](designs/closed-wall-e11/section-comparison.png) ·
[Inner-seat close-up](designs/closed-wall-e11/finish-inner-front.png) ·
[Opposite face](designs/closed-wall-e11/finish-inner-reverse.png) ·
[Outer retainer](designs/closed-wall-e11/finish-outer-front.png)

The rear/front rail centers remain **(90, 0) / (190, 12) mm**. The nominal
180–220 mm spool sweep retains **3.93 mm minimum clearance** across 322 cases.
Complete flexible-finger sectors match E10 at nine depths through the exported
part. This preserves geometry; physical insertion and retention still need
the measured rods and intended filament.

## Print setup

Print on the supplied broad side so the principal bending load stays in the
layer plane. Import the STEP as **one object with three aligned parts**.

| Setting | Working value |
|---|---|
| Body footprint / height | Approximately **207.51 × 246.00 × 24 mm**; check bed exclusions |
| Layer height, including first | **0.20 mm** |
| Reference nozzle | 0.4 mm |
| Outer / inner line-width assumptions | 0.42 / 0.45 mm |
| Wall generator / solid-region gap fill | **Arachne / Everywhere** |
| PLA prototype walls | **8**, approximately 3.27 mm contour thickness |
| PETG prototype walls | **10**, approximately 4.08 mm contour thickness |
| Body infill | **15%**, with zero stiffness/strength credit in analysis |
| Exterior top / bottom | **1.2 / 1.2 mm**, six layers each |
| Helper 1 | **100% infill modifier**, Z = 7.6–8.8 mm |
| Helper 2 | **100% infill modifier**, Z = 15.2–16.4 mm |
| Solid infill | A bonded, fully dense pattern supported by the slicer |
| Filament process | Exact grade's calibrated temperature, cooling, flow and bonding settings |

1. Keep the main body printable and set its walls, 15% infill and six top/bottom layers.
2. Convert both named helper parts to **modifiers** and set their infill to 100%.
   Keep their supplied positions. They must not print as extra exterior slabs.
3. Inspect all four solid bands, the continuous perimeter below the inner seat,
   both fingers, the screw landings and the printable access roofs.
4. Save the configured project with the actual machine and filament identity.
   STEP stores geometry and alignment, not modifier status or print settings.

Solid-band locations

Actual OrcaSlicer paths through E11

**Actual OrcaSlicer 2.4.2 audits pass for 8 and 10 walls.** Both slices have 120
layers. Every intended solid-band layer passes the inner-seat footprint check;
the minimum nominal coverage is **99.79%**, and sampled seat-wall coverage is
above **99.99%**, using a documented 0.03 mm geometry/rounding allowance. Sampled
full L-planes exceed 99.96% coverage, and sampled flexible fingers exceed 99.84%.
The final audit uses Arachne variable-width walls: the initial classic-wall
slice left a small pocket inside one finger nose on an exterior solid layer.
[Toolpath evidence](designs/closed-wall-e11/toolpath-verification.json).
These are neutral geometry audits, not calibrated print profiles or proof of
bonding, bridge quality or absence of curling.

The contour estimate is
`t(n) = 0.42 + (n − 1) × [0.45 − 0.2 × (1 − π/4)] mm`.
Actual line width and thin-wall handling govern the slice. Recalculate the wall
count for another nozzle; keep the four 1.2 mm plates. Sparse infill supports
those plates during printing even though it receives no structural credit.

## New stress results

The matched E10/E11 reduced-model comparison gives **37.4–37.6% lower near-seat
stress** and **35.1–35.5% less front movement** at the same load and wall count.
With **only the outer rod loaded**, near-seat stress falls **43.5%**, supporting
the reduced-section bending diagnosis. The same fixed stress window is used
in both designs, so added underside volume does not dilute that statistic.
[Matched comparison and mesh checks](analysis/e11/COMPARISON.md).

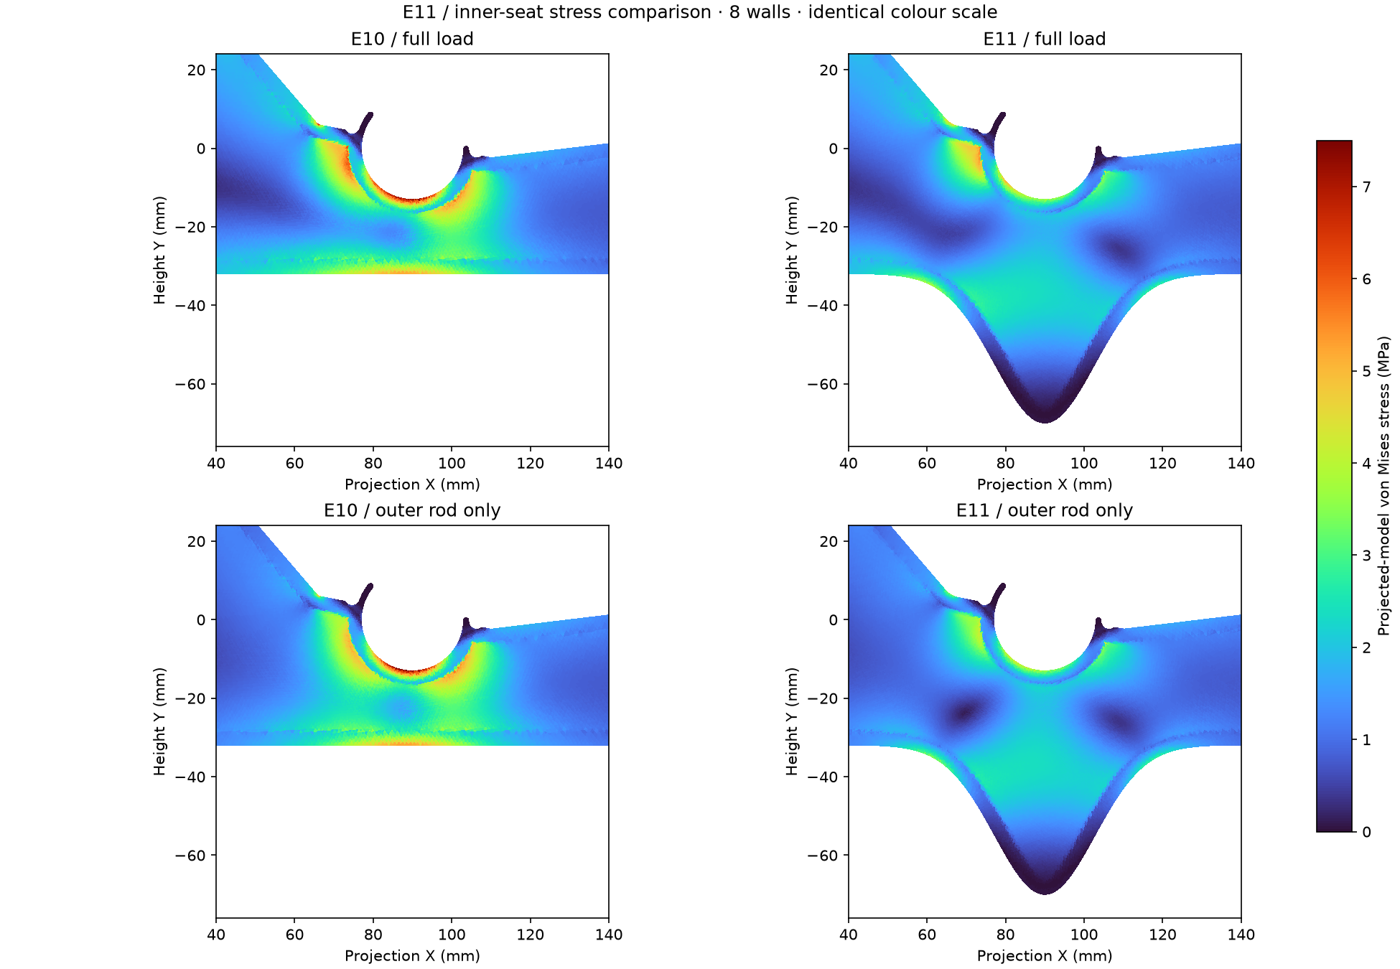
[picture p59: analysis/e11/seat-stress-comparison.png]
Matched E10/E11 inner-seat stress comparison


The **new E11 3D solves** include the actual finished exterior, ideal contour
walls, four continuous plates, fastener openings, compression-only wall contact,
rigid washer axial restraints and rigid shank shear restraints. Sparse core
material is removed only in the analysis domain. No clamp friction or arbitrary
preload is credited.

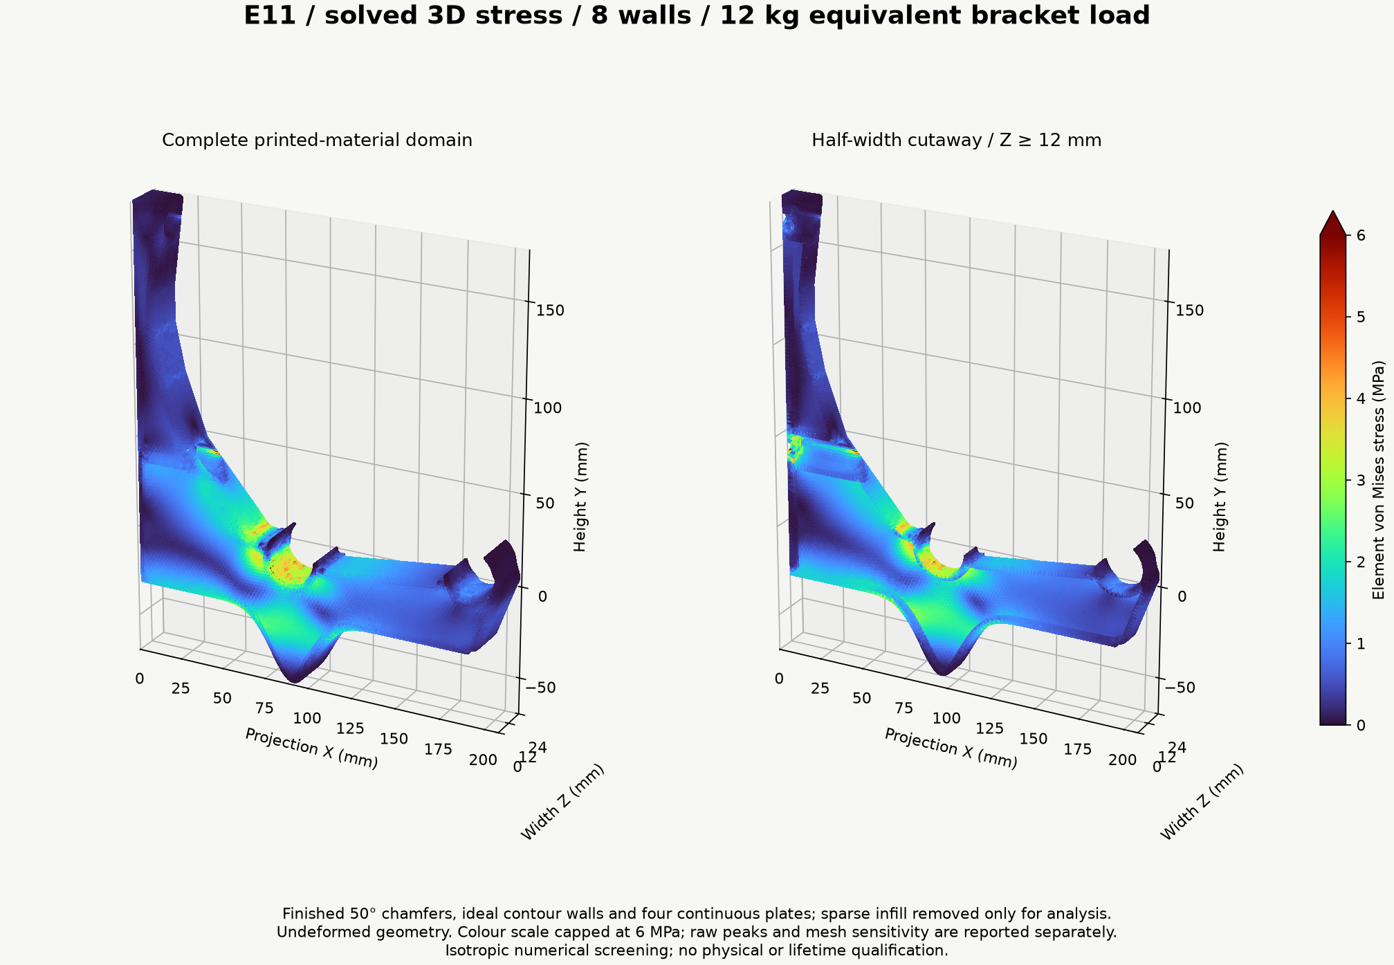
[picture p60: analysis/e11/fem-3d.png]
E11 3D stress and cutaway


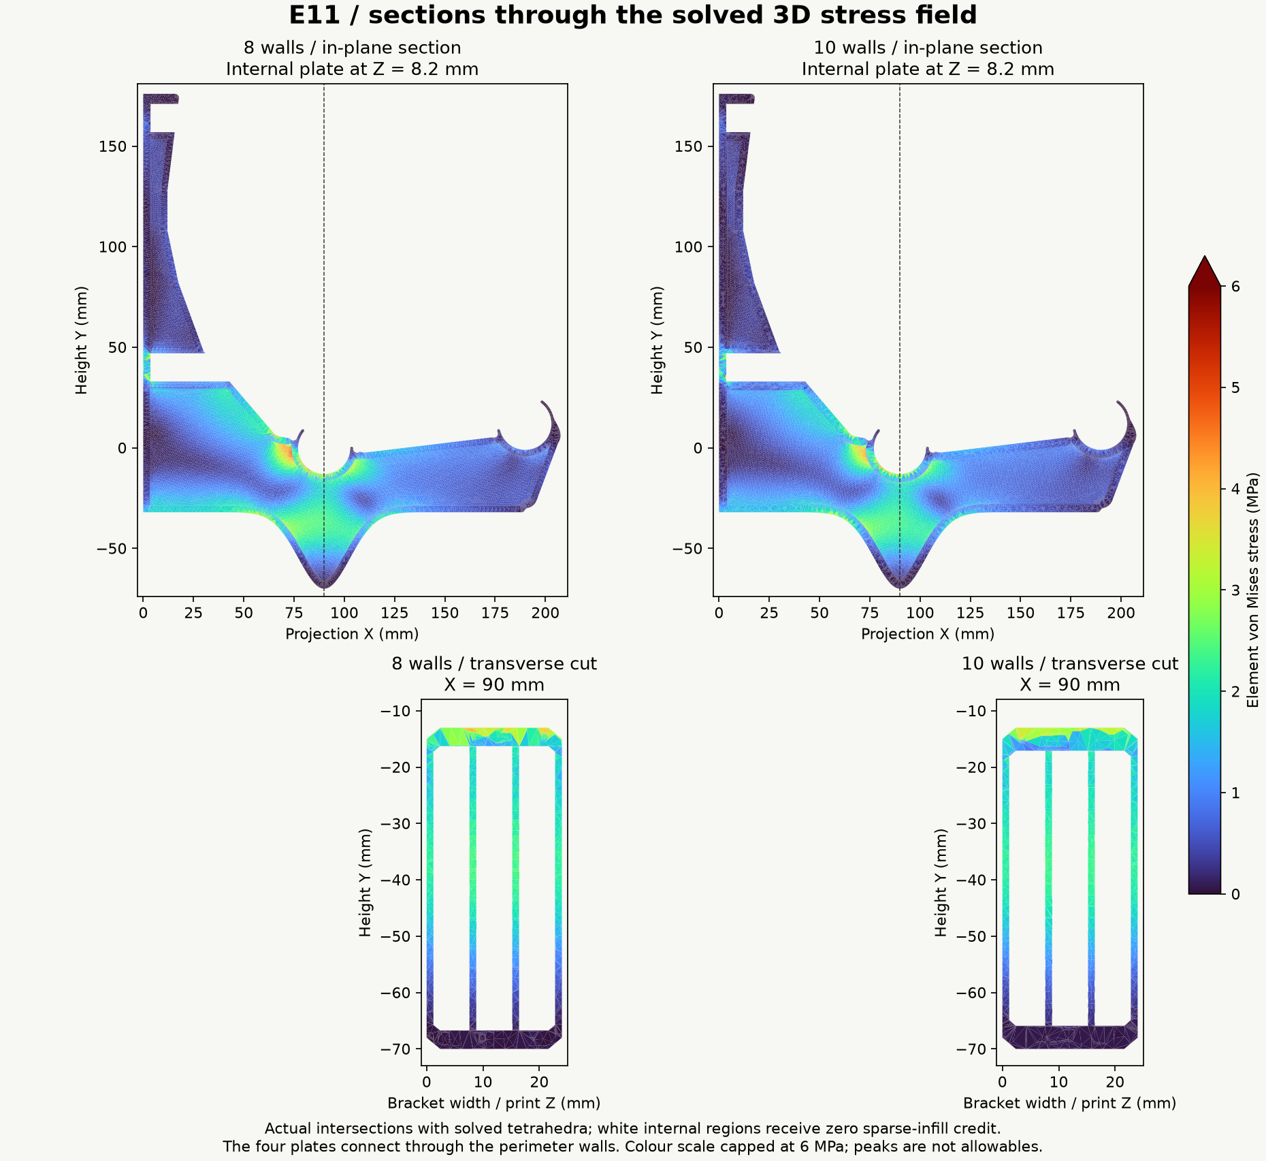
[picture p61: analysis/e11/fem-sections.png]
E11 in-plane and transverse stress sections


[10-wall 3D stress view](analysis/e11/fem-3d-10w.png).

| Walls | Tetrahedra, coarse → fine | Front movement refinement change | Near-seat p99, coarse → fine |
|---:|---:|---:|---:|
| 8 | 180,806 → 235,089 | 2.56% | 3.56 → 3.79 MPa |
| 10 | 149,156 → 242,810 | 2.27% | 3.79 → 3.79 MPa |

All published 3D fields pass independently recomputed residual, force and moment
balance gates below 1e-6. The refined 2D/3D front-movement coefficients agree
within 0.55%. This is numerical screening, not independent physical validation.
The meshes do not establish asymptotic convergence. **Raw refined peaks are
37.9 / 51.1 MPa** for 8/10 walls and remain sensitive to small cells at geometric
and analysis-core intersections; neither those peaks nor percentiles are
allowables. [Raw fields, peak locations, rejected runs and numerical audits](analysis/e11/RESULTS.md).

## Material movement and creep margin

The project criteria remain **5 mm total loaded movement**, including creep,
dowels and mounts, and **1 mm change when adding/removing one full spool**.
The new refined geometry coefficients are **K = 2306.3 MPa·mm for 8 walls** and
**2098.2 MPa·mm for 10 walls**, at 12 kg equivalent load per bracket.

| Reference material | Walls | Initial front movement | One 1.25 kg roll | Ec for 5 mm bracket-only | Compliance growth limit |
|---|---:|---:|---:|---:|---:|
| PLA | 8 | 0.673 mm | 0.070 mm | 461 MPa | 7.43× |
| PETG | 10 | 0.908 mm | 0.095 mm | 420 MPa | 5.51× |
| ASA | 8 | 0.969 mm | 0.101 mm | 461 MPa | 5.16× |
| PA6-GF annealed/dry | 8 | 0.431 mm | 0.045 mm | 461 MPa | 11.61× |
| PA6-GF water-conditioned | 8 | 1.286 mm | 0.134 mm | 461 MPa | 3.89× |

These use the retained grade-specific room-temperature XY moduli, not measured
hot or aged properties. [Exact reference grades, conditions, sources and hashes](designs/closed-wall-e6/material-reference-data.json).
PLA/PETG remain prototype options; ASA is the higher-temperature comparison.
PA6-GF conditioning and annealing must match its source, and can alter fit.
HDT and generic tensile strength do not establish a sustained-load rating.

For common linear-viscoelastic compliance with unchanged contact:
`δ(t,T) = K × J(t,T) = K / Ec(t,T)`.
For the complete rack use **Ec ≥ K / (5 mm − dowel movement − wall/fastener movement)**.
Retain the project screening target of **at least 1.0 GPa effective creep modulus**
at the intended age and loaded temperature history; this is not a grade allowable.

The service envelope is **85°F sustained, plus 100°F for six loaded hours/year**.
The [updated material report](analysis/e11/RESULTS.md) recalculates one-, five-
and ten-year sensitivity cases using E11's coefficients. Published short-time
creep examples do not establish a multi-year law for the printed grades. Thermal
shifts and long-time tails remain explicit assumptions. Fast spool removal uses
aged instantaneous unloading modulus, not reversed accumulated creep.

## Loads, rods and installation

The analysis target is **12 kg equivalent / 117.72 N per bracket**. For the
documented 180 mm spool contact case, the rear/front seats receive **75.12 / 42.60 N
downward**, plus **31.29 N outward each**. The front rail remains 12 mm higher;
the back arm accommodates the rearward-shifted spool. The retained
[rail-statics explanation](E10-ENGINEERING-GUIDE.md#current-rail-geometry-12-mm-front-lift)
describes that load split.

At 406.4 mm (16-inch) support spacing and 1.25 kg gross per spool, six spools per
bay weigh 7.5 kg and need pitch ≤67.7 mm. An interior support between simple
spans carries about one bay; the stated two-equal-span continuous example gives
1.25 times the bay load, or 9.375 kg before self-weight. The 12 kg target includes
margin for that example, not every loading pattern. **Six per bay is a proposed
test arrangement, not a released safe count.**

The **24 kg brief proof scenario** doubles the linear fields with unchanged
contact; it is neither a damage simulation nor a performed proof test.

| Hardware feature | E11 geometry |
|---|---:|
| Nominal screw clearance | Ø5.2 mm, with printable roof relief |
| Washer face to wall | 3.6 mm |
| Nominal driver access / checked straight envelope | Ø16 / Ø15.8 mm |
| Checked washer | Ø13 OD / Ø5.5 ID |
| Screw axes in installed coordinates | Y = 164 / 40 mm, Z = 12 mm |

The global model attracts about **208 N outward demand at the lower washer**
and **15–16 N at the upper**, excluding tightening preload. The new 500 N
upper-landing submodel gives **0.01207 mm** mean compression at E1000 and a
**5.00 MPa** raw peak; its movement changes 1.66% on refinement.

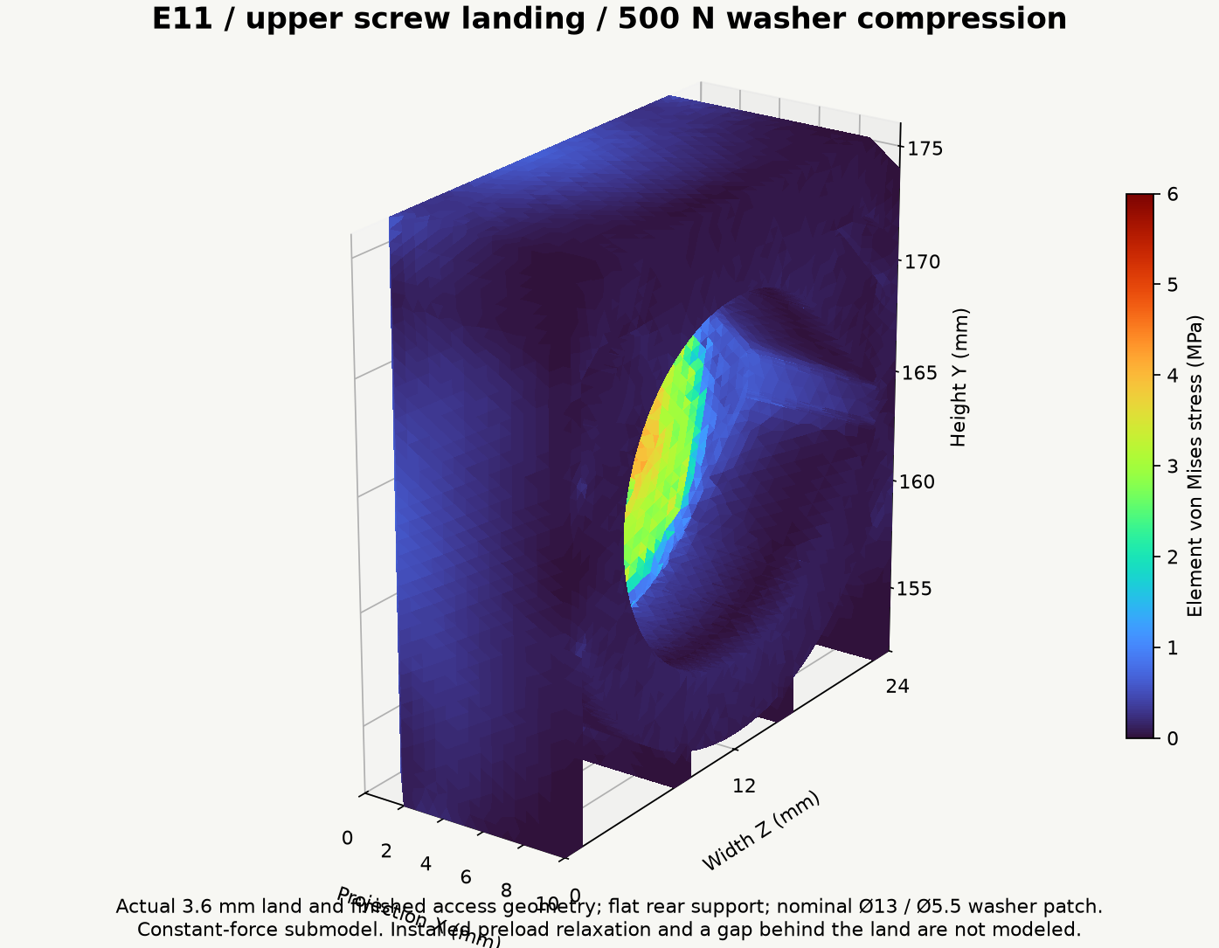
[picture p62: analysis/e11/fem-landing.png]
E11 screw-landing stress


Retain the backed 3.6 mm land. Mount against a flat, firm surface; a gap changes
the land into a bending/punching problem. Use flat-bearing heads and washers,
substrate-appropriate screws, and the manufacturer's pilot/embedment guidance.
M5 shank clearance does not make an M5 machine screw suitable for wood. Driving
torque does not reliably establish clamp force. Service and preload von Mises
maxima cannot simply be added as scalars.

**Rod fit remains provisional.** The 26.0 mm seat assumes nominal 25.4 mm stock.
The checked retail listings specify 1-inch actual diameter but no numeric
production/ovality tolerance. Measure the rods and use the
[full-width fit coupons and measurement plan](fit/README.md).

## Qualification and reproduction

The remaining print checks are physical: fit, snap insertion/retention, bonded
layers, supported internal bands and the actual filament process. Measure
immediate loaded movement and drift, rear/front seat positions, dowel sag and
wall/washer movement. Include the sustained 85°F condition and a six-hour loaded
100°F exposure; inspect for cracking, whitening, layer separation, permanent
snap opening and progressive embedment. A proof test or 1,000-hour trial alone
does not establish ten-year creep-rupture life.

[CAD rebuild and verification](designs/closed-wall-e11/README.md) ·
[Analysis reproduction and solver checks](analysis/e11/README.md) ·
[Machine-readable engineering summary](analysis/e11/engineering-summary.json).

The [E10 guide](E10-ENGINEERING-GUIDE.md), [E9 analysis](analysis/e9/RESULTS.md)
and [level-rail E8 guide](E8-ENGINEERING-GUIDE.md) are preserved as earlier
baselines. [Design journal](DESIGN-JOURNAL.md) · [Design decisions](DESIGN.md) ·
[Separate future open-web exploration](future/open-web/README.md).

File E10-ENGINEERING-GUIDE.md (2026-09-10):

# Archived E10 print and engineering guide

This snapshot preserves the E10 handoff and its prior-finish E9 calculations.
Use the [current E11 guide](README.md) for the current print files, coefficients
and stress fields. Statements below describing a current prototype are historical.

**Current prototype: E10, with the front rail raised 12 mm. Both broad faces have 2 mm chamfers; exposed wall-facet direction changes have nominal R2 fillets. Fillets precede the chamfers; the bevel stays continuous around the main body and tapers only at thin dowel-retainer regions.** Print on the broad side so principal bending loads stay in the layer plane. Two aligned helper solids create continuous internal plates through slicer modifiers.

**[Download the current STEP](designs/closed-wall-e10/bracket-with-modifier-helpers.step)** · [Aligned STL fallback and rebuild](designs/closed-wall-e10/README.md) · [Solved E9 stress fields and results](analysis/e9/RESULTS.md) · [Archived level-rail E8 guide](E8-ENGINEERING-GUIDE.md)

Current E10 CAD

E10 profile and actual finished section

The back arm is reshaped inward for the rearward-shifted spool. A 322-case sweep across 180–220 mm spool diameters and two effective dowel radii gives **3.93 mm minimum nominal clearance**. Both retainers follow the new contact directions. The raised seat connects continuously to the original arm base.

The new finish removes the individual bevel stop/start patches at structural joints. E9's load calculations remain the **prior-finish baseline** below; its coefficients are not a new FEM solve of E10. The 12 mm rail lift, side profile, fasteners and helper positions remain the same.

**Dowel fit remains provisional.** Lowe's lists Madison Mill poplar and oak rods as 1 inch actual diameter, but no numeric diameter/ovality tolerance was found on the checked listings or manufacturer pages. The 26.0 mm seat was designed around nominal 25.4 mm stock; it has not been qualified against measured rods. [Source check, fit conditions and coupons](fit/README.md).

## Current engineering decision

Use **8 walls for the PLA prototype or 10 for the PETG prototype**, plus the four 1.2 mm solid plates described below. At the assumed extrusion widths, these provide about **3.27 and 4.08 mm** of contour wall. These are deliberate prototype settings; they are not material-independent lifetime ratings.

The prior-finish E9 whole-bracket calculations give approximately **1.01 mm front-seat movement for PLA and 1.37 mm for PETG** at the 12 kg equivalent bracket load. That initial flexibility is acceptable against the project serviceability criteria:

- **5 mm maximum total movement under full load**, including creep.
- **1 mm maximum change when adding or removing one full spool.**
- No cracking, loss of rod capture, fastener pull-through or progressive instability. Creep must remain within the movement budget over the chosen service life; an accelerating rate requires investigation.

Movement is measured from the unloaded geometry, relative to a stable wall reference. Decorative camber does not erase actual deformation. Measure at the bracket and between supports so dowel sag and wall/fastener movement are included.

**The remaining material question is creep and rupture over time, not whether 1.2 mm of elastic movement looks large.** No retrieved source establishes an indefinite-life rating for the exact printed grades at this rack's temperatures. The calculations below quantify how much compliance growth the design can tolerate instead of assigning an invented creep factor.

## Print setup

| Setting | Working value |
|---|---|
| Orientation | Supplied broad side down; bracket width is printer Z |
| Layer height | 0.20 mm, including the first layer for the stated band alignment |
| Nozzle used for wall-count mapping | 0.4 mm |
| Assumed outer / inner line width | 0.42 / 0.45 mm; explicit analysis inputs, not asserted slicer defaults |
| PLA contour walls | 8 |
| PETG contour walls | 10 |
| Body infill | 15%; **zero strength or stiffness credit** in the analysis |
| Body top / bottom solid thickness | 1.2 / 1.2 mm, six layers each |
| Helper 1 | 100% infill modifier, print Z = 7.6–8.8 mm |
| Helper 2 | 100% infill modifier, print Z = 15.2–16.4 mm |
| Solid infill | A pattern the slicer supports at 100%, with bonded adjoining lines |
| Filament profile | Exact grade's manufacturer profile, calibrated for the machine |
| Temperature, cooling and flow | Follow that grade's profile; verify bonding and flow before load testing |
| Print envelope | Approximately 206.73 × 208 × 24 mm; pair-print constraint removed |

1. Import the STEP as **one object with three aligned parts**. Do not arrange its components independently.
2. Keep `MAIN_BODY_SET_WALLS_AND_INFILL` as the printable body. Set its walls, 15% infill and six top/bottom layers.
3. Convert each named `MODIFIER_…` helper to **modifier geometry** and set its infill to **100%**. A helper is a finite 1.2 mm slab, not a zero-thickness STEP surface.
4. Inspect the toolpaths at each band. Confirm four continuous solid planes, contour thickness through the knee and beneath both seats, and uninterrupted solid plastic in the screw landings.
5. Confirm the helpers do not print as extra exterior slabs. Check driver tunnels, screw clearance, thin snap fingers and internal bridging over the sparse infill.
6. Save the configured slicer project with the filament identity and settings. The STEP itself stores geometry, not these settings.

Solid-band layout

The body is solid **in CAD** so the slicer can generate its internal structure. It is not an instruction to print the body at 100%. Sparse infill supports the internal bands during printing even though it receives no structural credit. Do not reintroduce modeled hollow bands or an internal grid into the printable STEP.

Use the supplied orientation for all mechanical comparisons. Standing the bracket upright changes the layer-load relationship. A 0.6 mm nozzle may suit abrasive filament, but the wall **count** must then be recalculated to achieve the modeled thickness. Do not silently carry over the 0.4 mm mapping.

### Walls versus millimetres

A rounded-rectangle bead-spacing estimate at 0.2 mm layers is:

`t(n) = 0.42 + (n − 1) × [0.45 − 0.2 × (1 − π/4)] mm`

| Walls | Approximate thickness |
|---:|---:|
| 3 | 1.23 mm |
| 5 | 2.05 mm |
| 6 | 2.46 mm |
| 8 | 3.27 mm |
| 9 | 3.68 mm |
| 10 | 4.08 mm |
| 12 | 4.90 mm |

Inspect the real slice; variable line width, thin-wall handling and local geometry alter this estimate. The two exterior and two interior plates stay 1.2 mm thick. More perimeters add material near bending-section edges and reduce working stress, but gains diminish. They do not establish a material's creep-rupture law. E9 keeps the underside at Y = −32 mm and raises the front seat center to Y = +12 mm, increasing depth toward the front; the rear-seat section still warrants particular attention.

## Material choice at 85°F sustained / 100°F for six hours per year

Both temperature cases retain full load. The following are **reference-grade comparisons**, not universal polymer properties. [Datasheet values, exact sources and hashes](designs/closed-wall-e6/material-reference-data.json).

| Material case | Prototype setup | Engineering implication |
|---|---|---|
| PLA | 8 walls; four 1.2 mm plates | Initially stiff. Least thermal headroom of these reference grades. Plausible candidate under the 5 mm criterion, with a grade-specific sustained/hot load trial. |
| PETG | 10 walls; same plates | More compliant initially, accommodated by thicker walls. A useful candidate; published short-time PETG creep evidence does not determine this grade's multi-year behavior. |
| ASA | Start with 8-wall geometry for comparison | First higher-temperature prototype choice. Thermal headroom is useful, but ASA is not automatically creep-qualified. |
| PA6-GF, annealed/dry | Compare the 8-wall effective thickness | High dry stiffness; match the datasheet's conditioning and annealing before using its properties. Integrated snaps need their own insertion/retention check. |
| PA6-GF, moisture-conditioned | Same geometry, conditioned properties | The reference Young's modulus falls from about 5.36 to 1.79 GPa. Treat this as a separate case, not as dry nylon with a small correction. |

The PA6-GF source specifies 100°C / 16-hour annealing for its reported properties. Its water-conditioned specimens are a deliberate sensitivity case, not a claim about equilibrium moisture in a particular room. Annealing can change fit. Use suitable abrasion-resistant extrusion hardware for glass-filled material and recheck the dowel and screw coupons after conditioning.

HDT and glass-transition temperature help compare thermal sensitivity; neither is a sustained-load allowable. Generic tensile strength divided by a convenient factor is not a creep design method. “PLA+”, “PETG HF” and other modified products need their own data.

## Loads and spool count

The design case uses 406.4 mm (16-inch) support spacing and an assumed **1.25 kg gross mass per full spool**, including the empty spool.

Six spools per bay weigh 7.5 kg and require pitch no greater than 67.7 mm. An interior support between simple spans receives about one bay's load. For two equal continuous spans under uniform load, the middle reaction is **1.25 times one bay's load**, or 9.375 kg equivalent before self-weight. At a continuous 60 mm spool pitch, that estimate becomes about 10.58 kg. The **12 kg equivalent / 117.72 N per bracket** analysis target allows additional demand for that example. It is not a universal bound on uneven loading, overhangs or arbitrary continuous spans.

For E9's 180 mm spool load case, the rear seat receives **75.12 N downward** and the front **42.60 N downward**, with **31.29 N outward at each seat**. The applied FEM moment about the wall is approximately **15.24 N·m**. Loads act over bearing arcs, not at thin finger tips. The structural load case uses an effective 12.4 mm rail radius; the illustrative 200 mm spool statics below uses nominal 12.7 mm. Both are documented inputs.

**Six per bay is the full-row test arrangement, not a released safe count.** No maximum safe spool count is yet assigned for PLA, PETG, ASA or PA6-GF. A capacity must satisfy the printed bracket, snaps, dowels, screws and wall, including creep and the specified serviceability limits.

For a tested material with usable creep compliance, scale bracket movement linearly within this small-deflection model:

`δ(m,t,T) = δ(12 kg,t,T) × m / 12 kg`

Then check the actual support reactions for the installation. Do not equate “six spools per bay” with “six spools carried solely by one bracket.”

## E9 baseline: what the FEM resolves

The **2D plane-stress model** integrates the ideal printed material across the width. It includes contour walls, the four solid bands and fastener opening effects. It omits broad-face chamfers and projects the mounting restraints onto the wall, so it is a reduced comparison model.

The **3D model** starts with the actual chamfered E9 exterior and functional holes, then removes an analysis-only sparse core. It retains the ideal contour walls, four continuous plates and tunnel surrounds. These analysis cavities are not printable CAD changes.

Both models use compression-only wall contact. Rigid washer patches restrain outward movement and ideal screw shanks carry shear. The wall cannot pull the bracket inward. The 3D material is small-strain, homogeneous and isotropic with Poisson ratio 0.35; the reference solve uses E = 1,000 MPa and scales displacement to each grade's published XY Young's modulus. This does not resolve actual FFF orthotropy, bead defects, layer adhesion, screw/stud compliance or changing snap contact.

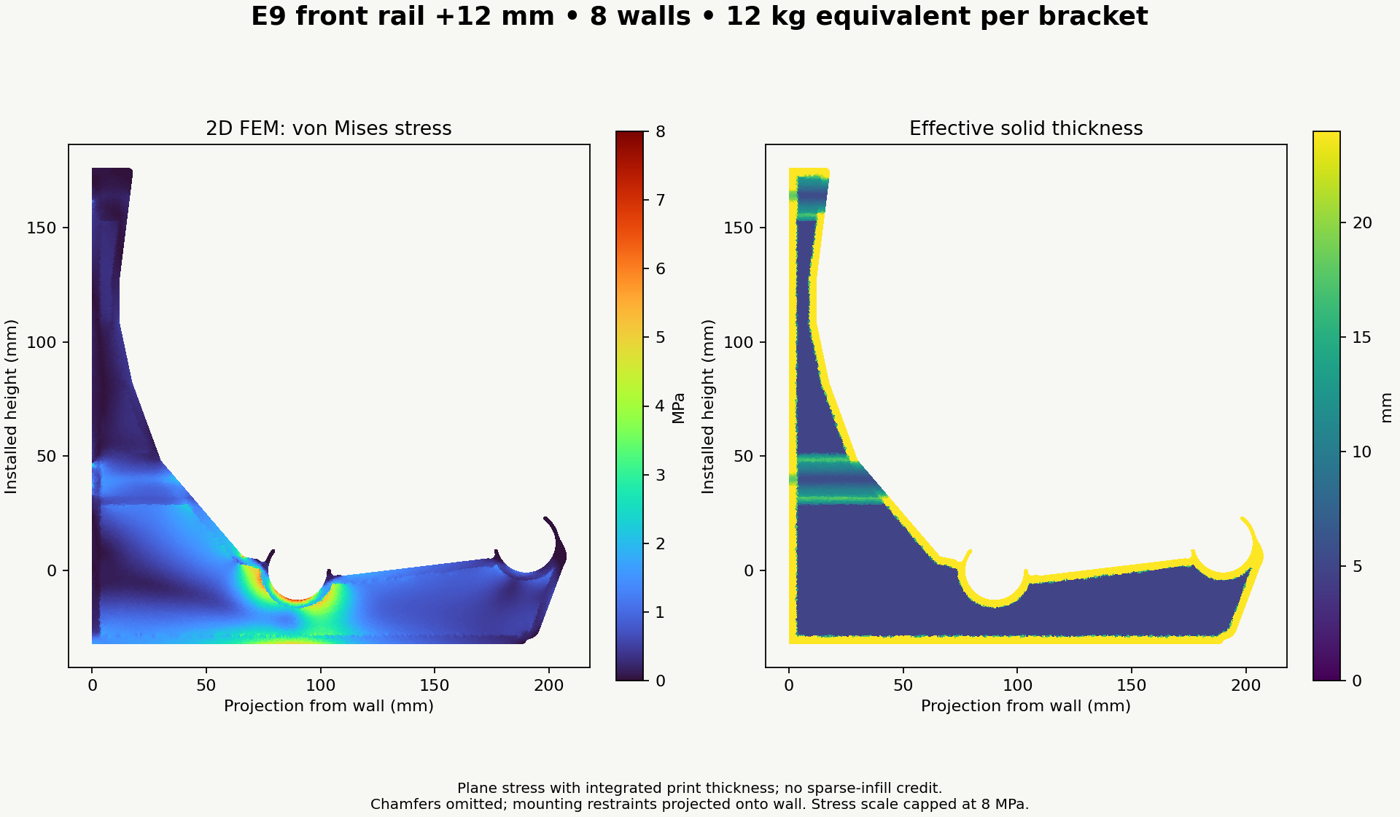
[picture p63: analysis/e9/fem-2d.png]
2D solved FEM


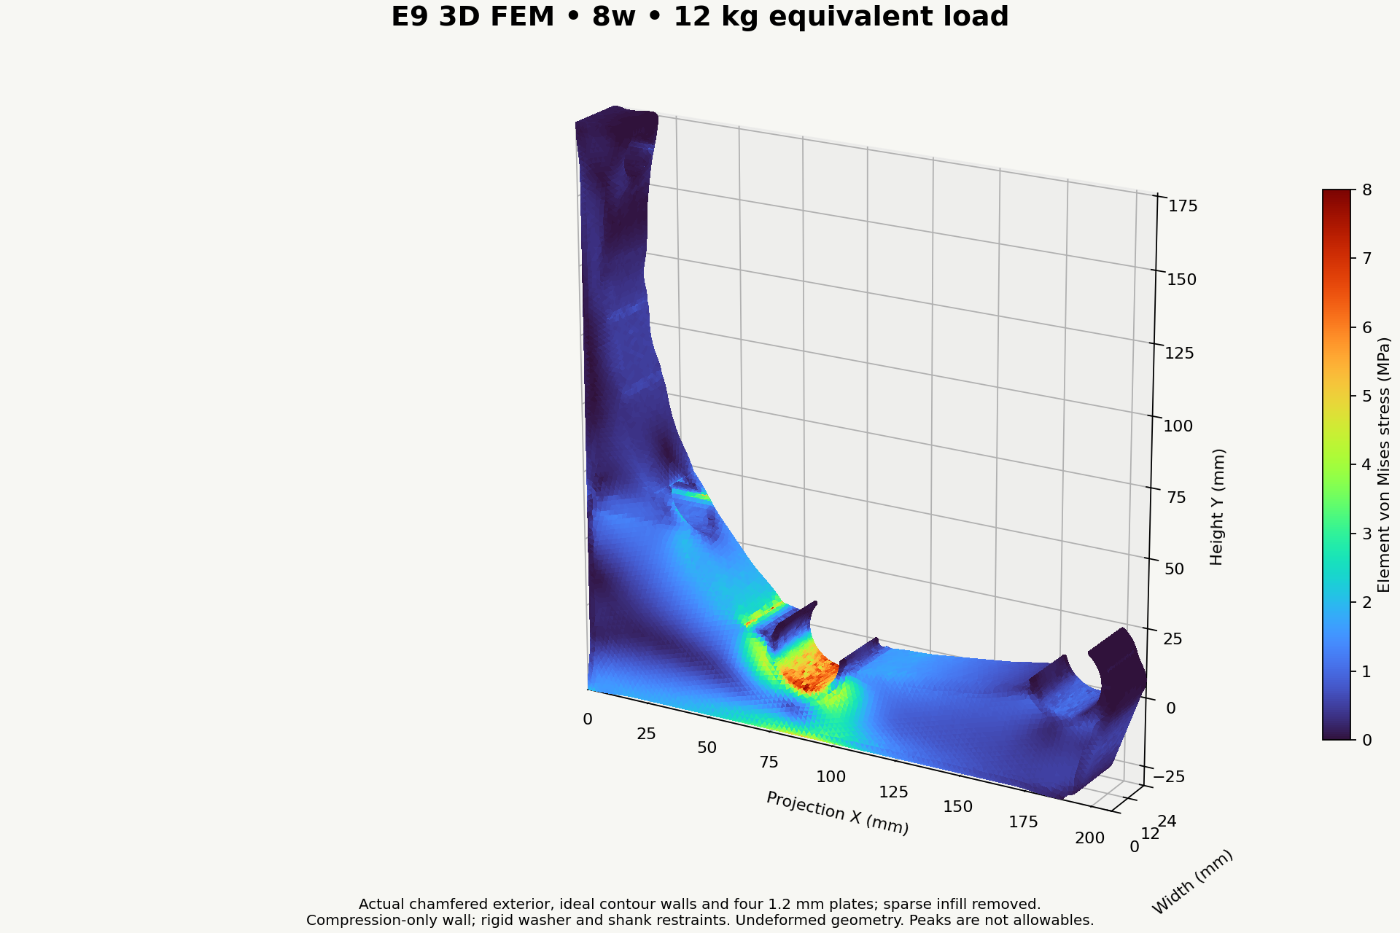
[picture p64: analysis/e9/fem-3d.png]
3D solved FEM


**Takeaways:** the rear-seat region remains important, but the raised-front geometry reduces front movement relative to the level-rail E8 baseline by approximately **18.0% for 8 walls and 17.7% for 10 walls**. This compares complete revisions: the load split, back arm, front depth and chamfers all changed. It is not an isolated rail-height stiffness experiment.

Refined rear-seat regional volume-p99 von Mises stresses are **6.04 MPa for 8 walls and 5.60 MPa for 10 walls**. The lower fixing attracts significant outward reaction, so treating the upper screw alone as the overturning restraint misses this model's connection behavior.

- 8 walls: 108,604 → 183,495 tetrahedra; front movement changes 4.50%; rear-seat regional p99 changes from 5.21 to 6.04 MPa.
- 10 walls: 103,938 → 186,126 tetrahedra; front movement changes 6.44%; rear-seat regional p99 changes from 5.05 to 5.60 MPa.

These comparisons do not establish asymptotic convergence. Raw maxima are **11.2/19.8 MPa** for the 8/10-wall meshes. Sharp analysis-core transitions, tiny cells and ideal restraint edges affect local peaks; actual printed radii, bead anisotropy and defects are not resolved. **Neither raw peaks nor percentile summaries are material allowables.** See [E9 results](analysis/e9/RESULTS.md) for the actual fields, reactions and residuals.

The 8-wall 2D refinement changes front movement by 0.69%; its refined coefficient is about 2.1% below the 3D value. Agreement between these related models is a comparison, not independent physical validation.

The initial 8-wall mesh contained numerically zero-volume cells and failed the independent residual check. That result was rejected. Removing one coarse and six fine degenerate cells removed less than 1.4e-12 mm³ of nominal volume; the corrected solves have relative free residuals below 4e-9 and pass force/moment balance checks. Finite-volume cells were retained. The coarse 8-wall raw peak of 63 MPa falls to 11.2 MPa on refinement and moves from a microscopic tunnel-mouth cell to an inner transition beneath the rear seat—further reason not to interpret raw peaks as rupture allowables. [Mesh audits and reproduction](analysis/e9/README.md).

An affine uniaxial patch test checks stiffness assembly, recovered stress and strain energy. Whole-bracket force/moment balance, residuals and refinement checks accompany the result files. A mesh comparison supports numerical interpretation; it does not validate years of service.

## Creep calculation and available margin

For a constant load and a common linear-viscoelastic compliance throughout a model with unchanged contact state:

`δ(t,T) = K × J(t,T) = K / Ec(t,T)`

Here K is the geometry/load coefficient in MPa·mm, J is creep compliance in MPa⁻¹ and Ec is the **secant creep modulus**, not the instantaneous unloading modulus. For the refined E9 raised-front solves:

| Case | K (MPa·mm) | Initial front movement | Ec for 5 mm bracket-only | Compliance growth limit |
|---|---:|---:|---:|---:|
| PLA, 8 walls | 3466 | 1.01 mm | 693 MPa | 4.94× |
| PETG, 10 walls | 3160 | 1.37 mm | 632 MPa | 3.66× |
| ASA, 8 walls | 3466 | 1.46 mm | 693 MPa | 3.43× |
| PA6-GF dry, 8 walls | 3466 | 0.65 mm | 693 MPa | 7.73× |
| PA6-GF wet, 8 walls | 3466 | 1.93 mm | 693 MPa | 2.59× |

Refinement updates live in [RESULTS.md](analysis/e9/RESULTS.md). These thresholds spend the full 5 mm on the bracket. For the complete rack, use **Ec ≥ K / (5 mm − dowel movement − wall/fastener movement)**. The earlier 1-inch wood-rail example gave about 0.22 mm instantaneous sag with an assumed 8 GPa modulus; wood grade, moisture, defects and long-term behavior remain installation inputs.

For a material-data screening target, use **at least 1.0 GPa effective creep modulus at the intended age and loaded temperature history**. This rounds above the bracket-only thresholds and preserves some movement budget for the dowels, mounting and reaction redistribution. It is a project screening target, not a published grade allowable or a rupture criterion.

The correspondence calculation keeps the original seat reactions. Relative seat sag reduces the initial 12 mm height advantage and redistributes load toward the front. For a nominal 200 mm spool, lowering the front 5 mm relative to the rear changes its vertical share from about 35.2% to 41.3%. This is a sensitivity case, not the predicted differential movement. A deformed-contact check is needed near the movement limit; the linear threshold is not an exact nonlinear capacity.

A one-roll change assigning an entire 1.25 kg reaction to one bracket gives approximately **0.11 mm for PLA and 0.14 mm for PETG** with the reference instantaneous modulus. For simple spans and the stated two-equal-span geometry, a single point load's reaction at the relevant support does not exceed the whole load. This estimate excludes overhangs, unusual continuity and handling impact. Fast removal of a roll depends on the aged unloading modulus; it is not correctly modeled by simply reversing all accumulated creep.

Even a settled, linear response at the full 5 mm limit gives a proportional one-roll change of about 0.52 mm for this load assumption. The 5 mm full-load criterion is therefore more restrictive than the 1 mm per-roll criterion in that simplified case.

### Published creep evidence and its limit

[Stankevics et al., 2025](https://doi.org/10.3390/polym17152075) tested unidirectional, 100%-filled Devil Design PETG at approximately 21.3°C, with tests extending to 20 hours. Its Figure 26 Prony spectrum provides a short-time benchmark. Graphically transcribed amplitudes are approximately 0.005, 0.010, 0.015, 0.010, 0.020 and 0.080 at time constants 1 through 100,000 seconds in decades.

`J(t)/J0 = 1 + Σ Ai[1 − exp(−t/τi)]`

That spectrum gives roughly 1.07 at five hours, 1.10 at 20 hours and a formal asymptote of 1.14. **The asymptote is a property of the fitted finite series, not proof that a rack at 85°F stops creeping.** Longer-time mechanisms were not calibrated by that experiment.

[Fischbach and Weinberg, 2023](https://arxiv.org/abs/2302.11240) tested a different printed PLA at room temperature. After approximately one week, measured flexural creep modulus was 1,040 MPa, about 56% of its 1,860 MPa datasheet flexural modulus, and deformation was still increasing. That demonstrates meaningful sub-Tg creep; it cannot be transferred unchanged to this PLA grade, temperature or service life.

The [calculation file](analysis/e9/engineering-summary.json) reports one-, five- and ten-year **sensitivity cases**, including unmeasured long-time compliance tails of 0, 0.02 and 0.10 per year. These are explicitly assumed continuations of a short-time example, not claimed PLA/PETG forecasts.

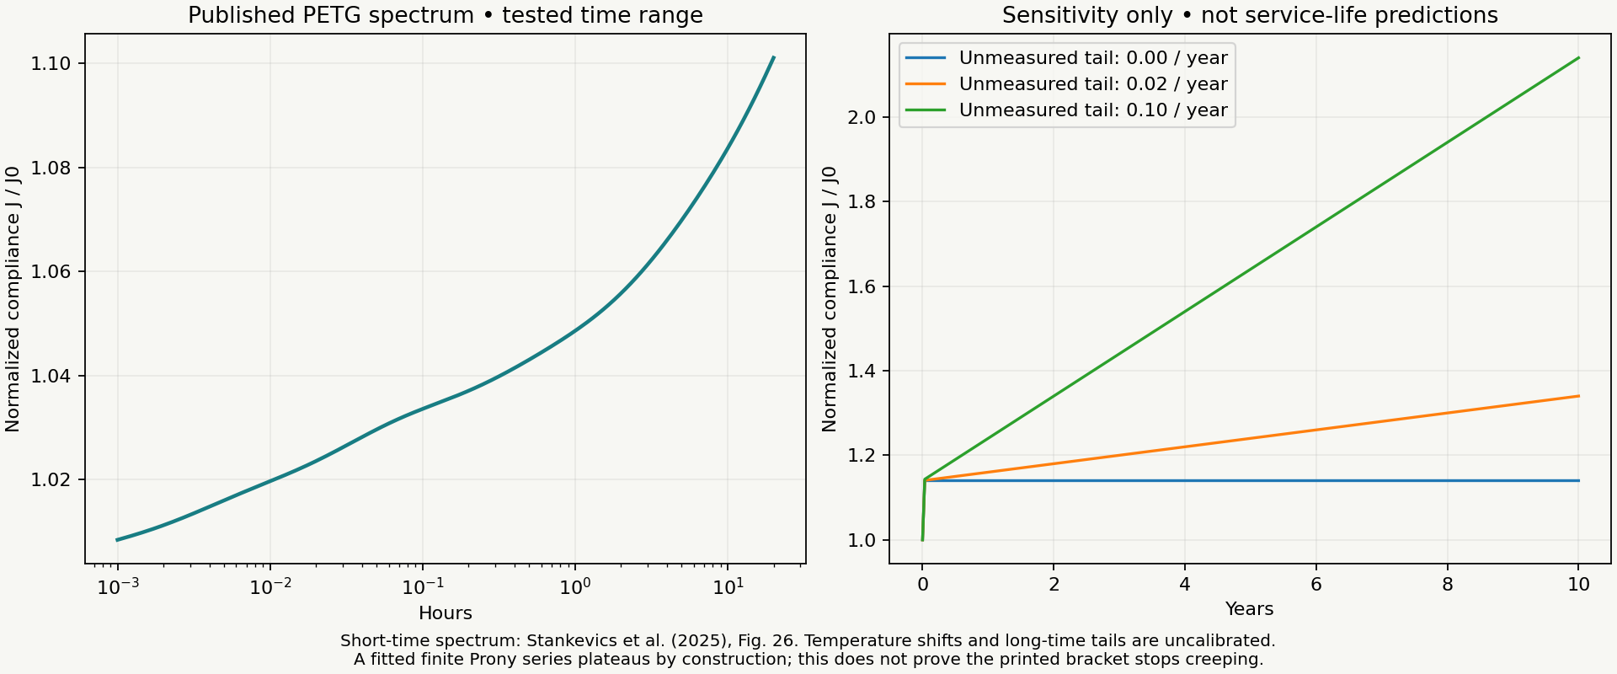
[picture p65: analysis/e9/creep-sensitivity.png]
Creep sensitivity


A long-time viscous tail can be almost invisible in a 20-hour test yet add appreciable deformation over ten years. Conversely, slow creep that remains inside the movement budget need not make the rack unusable. The release question is whether the grade's measured compliance and creep-rupture behavior support the intended life.

### Six hot hours each year

With 85°F as the reference temperature, reduced annual time is:

`ξyear = 8,754 + 6 × Ahot hours`

Ahot is the material's creep-rate shift at 100°F relative to 85°F. It is not known for these print/grade combinations. An **assumed Arrhenius sensitivity**, using activation energies of 50, 100 and 200 kJ/mol, gives Ahot about 1.70, 2.90 and 8.42. The six hot hours then add about 0.048%, 0.130% or 0.508% to annual equivalent time.

Those small percentages do not establish thermal adequacy: the shift law is uncalibrated, reversible hot softening still occurs during the excursion, and nonlinear creep or damage may invalidate simple time shifting. Check loaded movement during the actual hot exposure. Do not replace the cycle with an average temperature or use a universal WLF constant as grade data.

## Screw landings and installation

| Feature | Current design |
|---|---:|
| Screw clearance | Nominal Ø5.2 mm with small printable roof relief |
| Compatible shank envelopes | #8, #10 and nominal M5; printed M5 fit needs confirmation |
| Washer face to wall | **3.6 mm** |
| Nominal driver access | Ø16 mm with sloping roof |
| Checked straight driver envelope | Ø15.8 mm |
| Analysis washer | Ø13 OD / Ø5.5 ID; 1.2 mm thick for geometric fit |
| Screw axes | Y = 164 and 40 mm; Z = 12 mm |

Use flat-bearing heads and washers. A countersunk head introduces wedging that these models do not cover. Do not assume every washer sold for M5 has the analyzed outside diameter. For a different washer, check fit and recalculate bearing area.

The actual CAD supports approximately 99.1% of the specified washer annulus. The small loss comes from the printable roof relief in the screw hole. The available bearing area is about **108 mm²**:

`A ≈ 0.991 × π/4 × (13² − 5.5²)`

| Assumed clamp force per screw | Mean pressure on supported annulus |
|---:|---:|
| 250 N | 2.3 MPa |
| 500 N | 4.6 MPa |
| 1,000 N | 9.3 MPa |

These forces are scenarios. Driving torque into wood does not reliably determine the clamp force because thread cutting and friction consume torque.

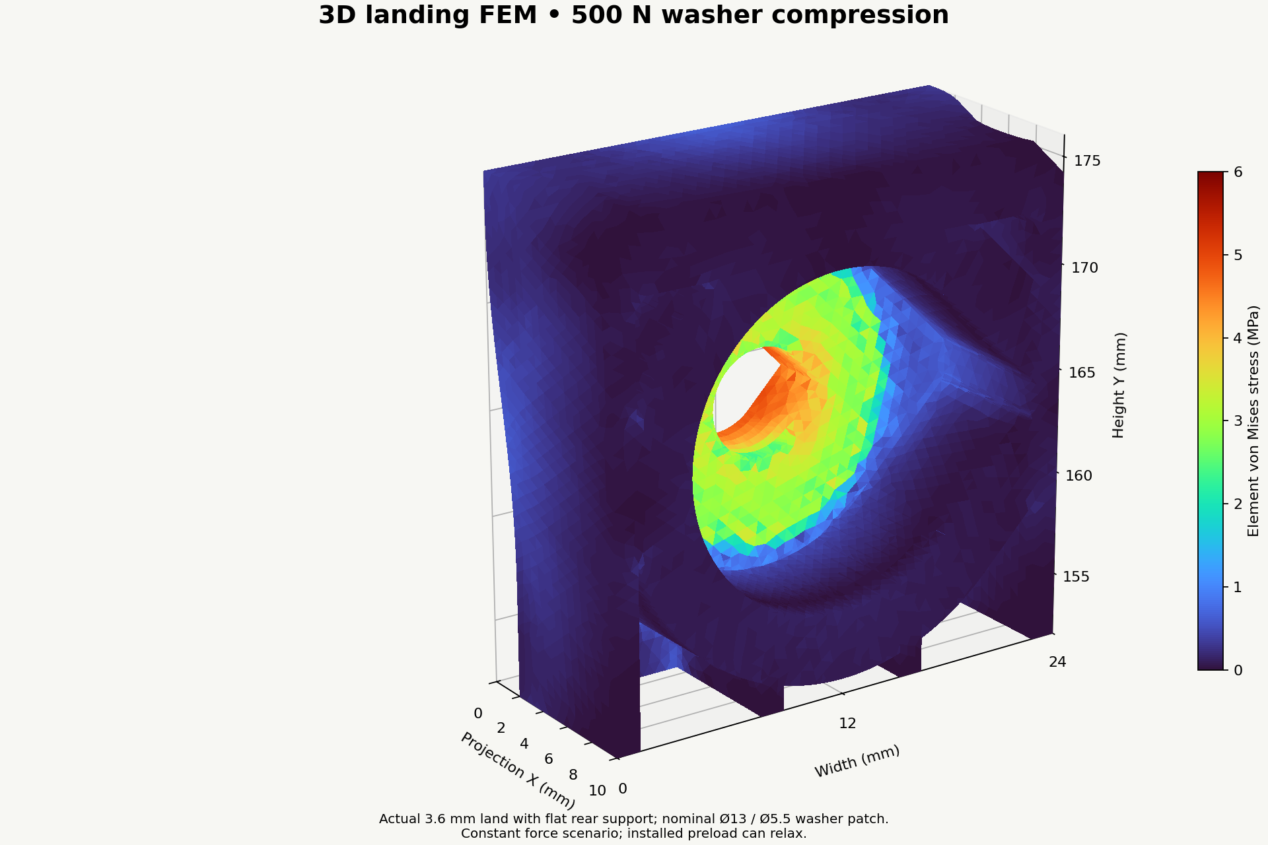
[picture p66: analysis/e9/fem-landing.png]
Screw-landing FEM


The local 3D submodel uses the actual **upper 3.6 mm land**, 500 N distributed washer force and flat rear support. E9's 85,567-tetrahedron solve gives **0.01200 mm** mean axial washer movement at E = 1,000 MPa and **4.96 MPa** raw von Mises peak. At the reference PLA/PETG moduli, axial movement is about 0.0035/0.0052 mm. The earlier E8 landing refinement provides a useful numerical baseline; this is a new E9 coupon result, not a newly repeated E9 mesh-convergence study. These are constant-force calculations, not installed clamp-force-retention predictions.

**Retain the 3.6 mm land for now.** The backed compression case does not justify making it thicker. More thickness would add creep compression travel and violate the compact clamp intent without addressing the governing bracket region. This is a reasoned decision to retain the geometry, not a claim that every washer, tightening force or wall surface is acceptable.

The whole-bracket service model checks both fixings. The refined 8-wall solve attracts approximately **210 N outward demand at the lower washer and 15 N at the upper**. Those demands depend on wall contact and connection stiffness. They do not include arbitrary tightening preload, and maxima from separate cases cannot simply be added as scalar von Mises stresses.

Mount against a flat, firm surface with full back contact. A gap behind a landing changes it into a bending/punching problem and invalidates the backed compression case. Seat the washer firmly without crushing the print; inspect for embedment and loosening. The load path does not rely on sustained clamp friction alone.

Use screws intended for the actual stud substrate, with manufacturer-specified pilot drilling and embedment. Required length includes the 3.6 mm plastic, washer, wall finish and required stud engagement. M5 **shank clearance** does not mean an M5 machine screw can be driven directly into wood. Install the screws before loading the rack. The checked tool is a straight cylindrical envelope, not an arbitrary drill body.

## Current rail geometry: +12 mm front lift

Raising the front rail changes support geometry and reactions; it is more than cosmetic camber. For nominal 25.4 mm dowels, 100 mm horizontal spacing, frictionless contacts and a 200 mm spool:

| Quantity | Level rails | Front rail +12 mm |
|---|---:|---:|
| Spool center from wall | 140.0 mm | 128.0 mm |
| Rear / front vertical load fractions | 50% / 50% | 64.8% / 35.2% |
| Wall moment at 12 kg equivalent | 16.48 N·m | 15.07 N·m |
| Net moment about rear rail | 5.89 N·m | 4.47 N·m |

This reduces wall moment about **8.6%** and the net moment about the rear rail about **24%**. The front rail still carries roughly 35% of the weight. Across 180–220 mm spools, the wall-moment reduction is about 7.6–9.5%. The front rail also presents a higher obstacle to forward roll-out.

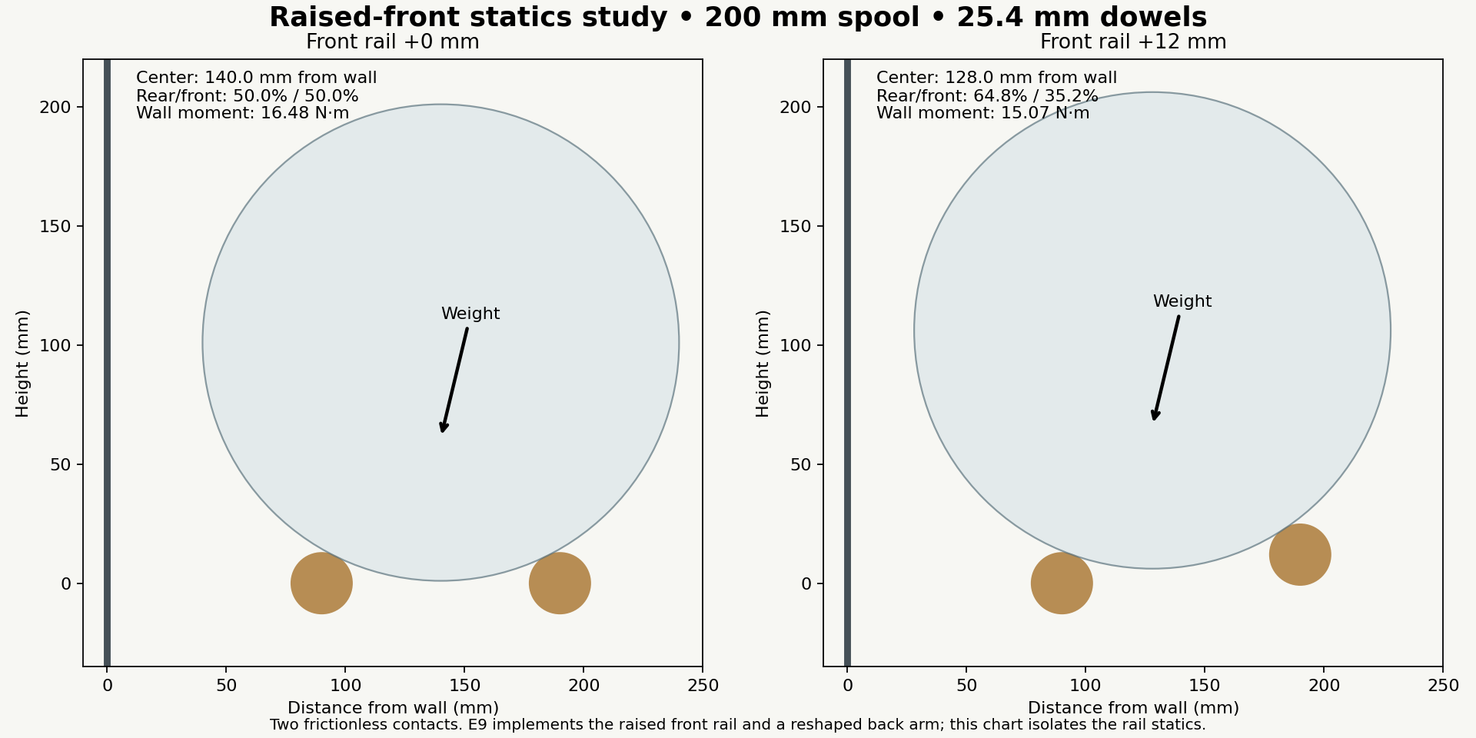
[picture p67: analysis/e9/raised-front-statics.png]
Raised-front statics study


**E9 incorporates the necessary back-arm reshaping and independently reoriented retainers.** The old E8 profile interfered with a 220 mm spool when its front rail was simply lifted. E9's renewed 180–220 mm sweep clears by at least 3.93 mm over the evaluated nominal cases. This resolves the geometric issue; printed tolerances and actual spool/dowel sizes still need fit checks.

The rear seat carries greater vertical load, which is included in the new FEM. Cosmetic camber remains a separate possible adjustment based on a defensible one-year front-minus-rear sag estimate; the present 12 mm lift is a structural support-geometry choice.

## Qualification before assigning a lifetime spool rating

Record the actual filament grade, print settings, dry/conditioned state, washer, screws, dowel diameter/grade, spool mass/pitch and support arrangement. Confirm the slice matches the structural assumptions.

Measure unloaded position, immediate loaded movement and loaded drift at increasing elapsed times, including a sustained 85°F trial and a six-hour loaded 100°F exposure. Log the temperature at the bracket. Track the rear and front seats, span-center rail sag, washer embedment and any movement relative to the wall.

Use **5 mm total full-load movement and 1 mm per-roll change** as the project limits. Compare creep rates over equal time intervals; a plateau should emerge from measurements, not from forcing a finite Prony fit. Inspect for cracks, whitening, layer separation, permanent snap opening, loss of capture and increasing screw embedment. A 24 kg brief proof case is a proposed separate test; passing it does not establish long-term creep life.

A 1,000-hour trial is useful screening and model calibration. It is not automatically a ten-year rating. Extrapolation requires justified temperature/time shifts, the grade's creep behavior and a rupture check.

## Reproduction and design history

[E9 analysis scripts and reproduction commands](analysis/e9/README.md) include material-domain construction, 2D/3D solvers, known-solution verification, stress rendering and conditional creep calculations. The existing [GitHub Actions workflow](.github/workflows/engineering-analysis.yml) reproduces the archived E8 baseline; E9 results shown here were generated with the checked-in E9 scripts. Result JSON files retain force/moment balance, residuals and mesh details. Analysis-only BREP files and base meshes are regenerated, not print deliverables.

The current CAD geometry verification is separate: [E10 STEP and hardware checks](designs/closed-wall-e10/verification.json). Physical printing and mechanical tests have not been performed in this repository.

[Design journal and superseded calculations](DESIGN-JOURNAL.md) · [Design decisions](DESIGN.md) · [Separate future open-web exploration](future/open-web/README.md)

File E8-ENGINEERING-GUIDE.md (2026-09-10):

# Archived E8 level-rail engineering guide

**Historical baseline. E9 is the running prototype; use the [current guide](README.md) and its downloads.**

**This archived revision is E8, with level rails.** Print the bracket on its broad side so the principal bending load stays in the layer plane. Two aligned helper solids create continuous internal plates through slicer modifiers.

**[Download the STEP assembly](designs/closed-wall-e8/bracket-with-modifier-helpers.step)** · [Aligned STL fallback and rebuild](designs/closed-wall-e8/README.md) · [Solved results and stress images](analysis/e8/RESULTS.md) · [Analysis run](https://github.com/thereprocase/spool-wall-rack/actions/workflows/engineering-analysis.yml)

The **front rail raised 12 mm** is a separate statics study, described below. It is not incorporated in this STEP and does not inherit the level-rail FEM results.

Current E8 CAD

## Current engineering decision

Use **8 walls for the PLA prototype or 10 for the PETG prototype**, plus the four 1.2 mm solid plates described below. At the assumed extrusion widths, these provide about **3.27 and 4.08 mm** of contour wall. These are deliberate prototype settings; they are not material-independent lifetime ratings.

The initial whole-bracket calculations give approximately **1.2 mm front-seat movement for PLA and 1.7 mm for PETG** at the 12 kg equivalent bracket load. That initial flexibility is acceptable against the project serviceability criteria:

- **5 mm maximum total movement under full load**, including creep.
- **1 mm maximum change when adding or removing one full spool.**
- No cracking, loss of rod capture, fastener pull-through or progressive instability. Creep must remain within the movement budget over the chosen service life; an accelerating rate requires investigation.

Movement is measured from the unloaded geometry, relative to a stable wall reference. Decorative camber does not erase actual deformation. Measure at the bracket and between supports so dowel sag and wall/fastener movement are included.

**The remaining material question is creep and rupture over time, not whether 1.2 mm of elastic movement looks large.** No retrieved source establishes an indefinite-life rating for the exact printed grades at this rack's temperatures. The calculations below quantify how much compliance growth the design can tolerate instead of assigning an invented creep factor.

## Print setup

| Setting | Working value |
|---|---|
| Orientation | Supplied broad side down; bracket width is printer Z |
| Layer height | 0.20 mm, including the first layer for the stated band alignment |
| Nozzle used for wall-count mapping | 0.4 mm |
| Assumed outer / inner line width | 0.42 / 0.45 mm; explicit analysis inputs, not asserted slicer defaults |
| PLA contour walls | 8 |
| PETG contour walls | 10 |
| Body infill | 15%; **zero strength or stiffness credit** in the analysis |
| Body top / bottom solid thickness | 1.2 / 1.2 mm, six layers each |
| Helper 1 | 100% infill modifier, print Z = 7.6–8.8 mm |
| Helper 2 | 100% infill modifier, print Z = 15.2–16.4 mm |
| Solid infill | A pattern the slicer supports at 100%, with bonded adjoining lines |
| Filament profile | Exact grade's manufacturer profile, calibrated for the machine |
| Temperature, cooling and flow | Follow that grade's profile; verify bonding and flow before load testing |
| Print envelope | Approximately 206.73 × 208 × 24 mm; pair-print constraint removed |

1. Import the STEP as **one object with three aligned parts**. Do not arrange its components independently.
2. Keep `MAIN_BODY_SET_WALLS_AND_INFILL` as the printable body. Set its walls, 15% infill and six top/bottom layers.
3. Convert each named `MODIFIER_…` helper to **modifier geometry** and set its infill to **100%**. A helper is a finite 1.2 mm slab, not a zero-thickness STEP surface.
4. Inspect the toolpaths at each band. Confirm four continuous solid planes, contour thickness through the knee and beneath both seats, and uninterrupted solid plastic in the screw landings.
5. Confirm the helpers do not print as extra exterior slabs. Check driver tunnels, screw clearance, thin snap fingers and internal bridging over the sparse infill.
6. Save the configured slicer project with the filament identity and settings. The STEP itself stores geometry, not these settings.

Solid-band layout

The body is solid **in CAD** so the slicer can generate its internal structure. It is not an instruction to print the body at 100%. Sparse infill supports the internal bands during printing even though it receives no structural credit. Do not reintroduce modeled hollow bands or an internal grid into the printable STEP.

Use the supplied orientation for all mechanical comparisons. Standing the bracket upright changes the layer-load relationship. A 0.6 mm nozzle may suit abrasive filament, but the wall **count** must then be recalculated to achieve the modeled thickness. Do not silently carry over the 0.4 mm mapping.

### Walls versus millimetres

A rounded-rectangle bead-spacing estimate at 0.2 mm layers is:

`t(n) = 0.42 + (n − 1) × [0.45 − 0.2 × (1 − π/4)] mm`

| Walls | Approximate thickness |
|---:|---:|
| 3 | 1.23 mm |
| 5 | 2.05 mm |
| 6 | 2.46 mm |
| 8 | 3.27 mm |
| 9 | 3.68 mm |
| 10 | 4.08 mm |
| 12 | 4.90 mm |

Inspect the real slice; variable line width, thin-wall handling and local geometry alter this estimate. The two exterior and two interior plates stay 1.2 mm thick. More perimeters add material near bending-section edges and reduce working stress, but gains diminish. They do not establish a material's creep-rupture law. The main arm remains approximately 28 mm deep; the earlier 34 mm depth proposal has not been implemented.

## Material choice at 85°F sustained / 100°F for six hours per year

Both temperature cases retain full load. The following are **reference-grade comparisons**, not universal polymer properties. [Datasheet values, exact sources and hashes](designs/closed-wall-e6/material-reference-data.json).

| Material case | Prototype setup | Engineering implication |
|---|---|---|
| PLA | 8 walls; four 1.2 mm plates | Initially stiff. Least thermal headroom of these reference grades. Plausible candidate under the 5 mm criterion, with a grade-specific sustained/hot load trial. |
| PETG | 10 walls; same plates | More compliant initially, accommodated by thicker walls. A useful candidate; published short-time PETG creep evidence does not determine this grade's multi-year behavior. |
| ASA | Start with 8-wall geometry for comparison | First higher-temperature prototype choice. Thermal headroom is useful, but ASA is not automatically creep-qualified. |
| PA6-GF, annealed/dry | Compare the 8-wall effective thickness | High dry stiffness; match the datasheet's conditioning and annealing before using its properties. Integrated snaps need their own insertion/retention check. |
| PA6-GF, moisture-conditioned | Same geometry, conditioned properties | The reference Young's modulus falls from about 5.36 to 1.79 GPa. Treat this as a separate case, not as dry nylon with a small correction. |

The PA6-GF source specifies 100°C / 16-hour annealing for its reported properties. Its water-conditioned specimens are a deliberate sensitivity case, not a claim about equilibrium moisture in a particular room. Annealing can change fit. Use suitable abrasion-resistant extrusion hardware for glass-filled material and recheck the dowel and screw coupons after conditioning.

HDT and glass-transition temperature help compare thermal sensitivity; neither is a sustained-load allowable. Generic tensile strength divided by a convenient factor is not a creep design method. “PLA+”, “PETG HF” and other modified products need their own data.

## Loads and spool count

The design case uses 406.4 mm (16-inch) support spacing and an assumed **1.25 kg gross mass per full spool**, including the empty spool.

Six spools per bay weigh 7.5 kg and require pitch no greater than 67.7 mm. An interior support between simple spans receives about one bay's load. For two equal continuous spans under uniform load, the middle reaction is **1.25 times one bay's load**, or 9.375 kg equivalent before self-weight. At a continuous 60 mm spool pitch, that estimate becomes about 10.58 kg. The **12 kg equivalent / 117.72 N per bracket** analysis target allows additional demand for that example. It is not a universal bound on uneven loading, overhangs or arbitrary continuous spans.

For the level-rail model, each seat receives 58.86 N downward. The 180 mm spool case adds 32.93 N outward at each seat and produces about 16.48 N·m at the wall. Loads act over bearing arcs, not at the thin finger tips. The older load formula used an effective 12.4 mm rail radius; the separate raised-front statics uses nominal 12.7 mm radius. These are explicitly different inputs.

**Six per bay is the full-row test arrangement, not a released safe count.** No maximum safe spool count is yet assigned for PLA, PETG, ASA or PA6-GF. A capacity must satisfy the printed bracket, snaps, dowels, screws and wall, including creep and the specified serviceability limits.

For a tested material with usable creep compliance, scale bracket movement linearly within this small-deflection model:

`δ(m,t,T) = δ(12 kg,t,T) × m / 12 kg`

Then check the actual support reactions for the installation. Do not equate “six spools per bay” with “six spools carried solely by one bracket.”

## What the FEM resolves

The **2D plane-stress model** integrates the ideal printed material across the width. It includes contour walls, the four solid bands and fastener opening effects. It omits broad-face chamfers and projects the mounting restraints onto the wall, so it is a reduced comparison model.

The **3D model** starts with the actual chamfered E8 exterior and functional holes, then removes an analysis-only sparse core. It retains the ideal contour walls, four continuous plates and tunnel surrounds. These analysis cavities are not printable CAD changes.

Both models use compression-only wall contact. Rigid washer patches restrain outward movement and ideal screw shanks carry shear. The wall cannot pull the bracket inward. The 3D material is small-strain, homogeneous and isotropic with Poisson ratio 0.35; the reference solve uses E = 1,000 MPa and scales displacement to each grade's published XY Young's modulus. This does not resolve actual FFF orthotropy, bead defects, layer adhesion, screw/stud compliance or changing snap contact.

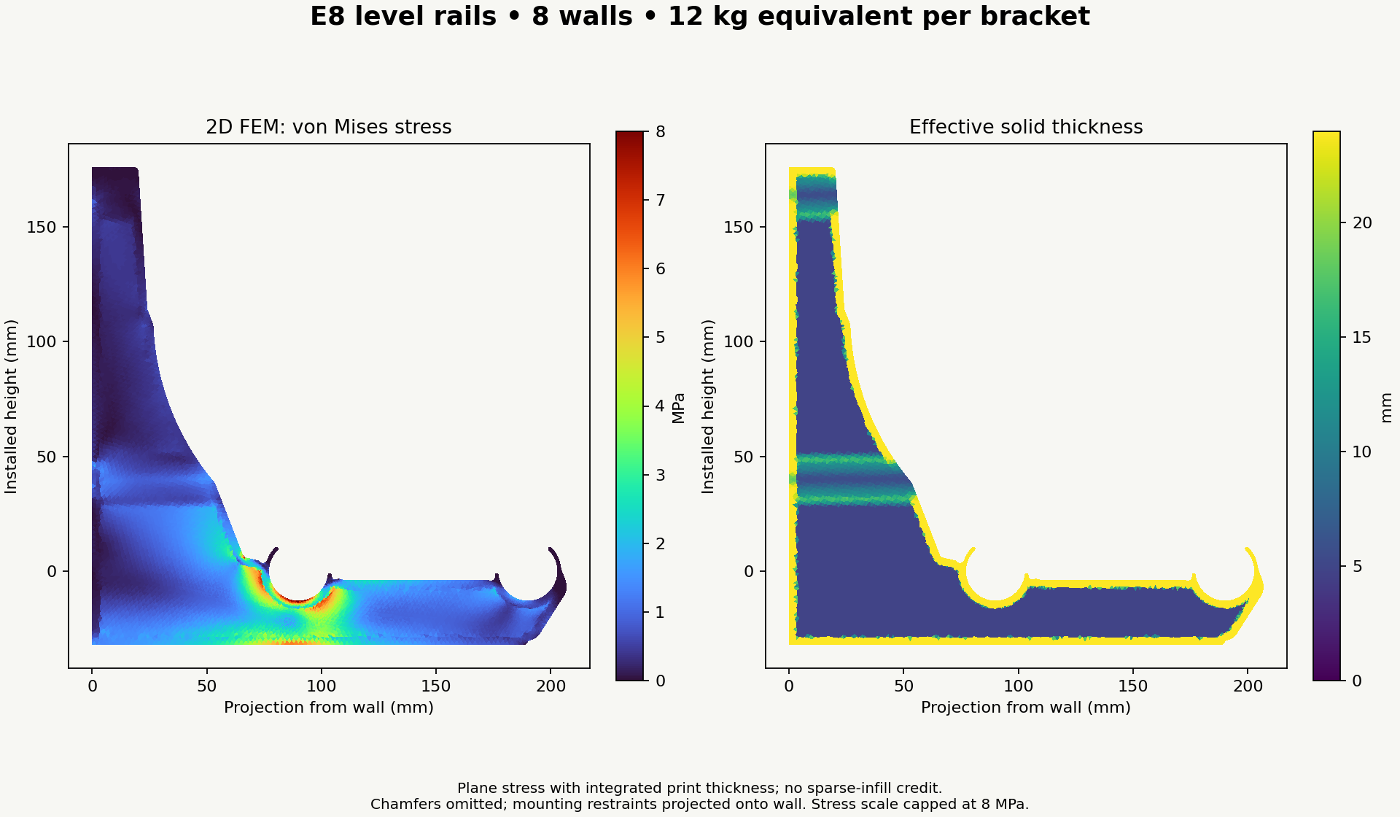
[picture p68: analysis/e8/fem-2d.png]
2D solved FEM


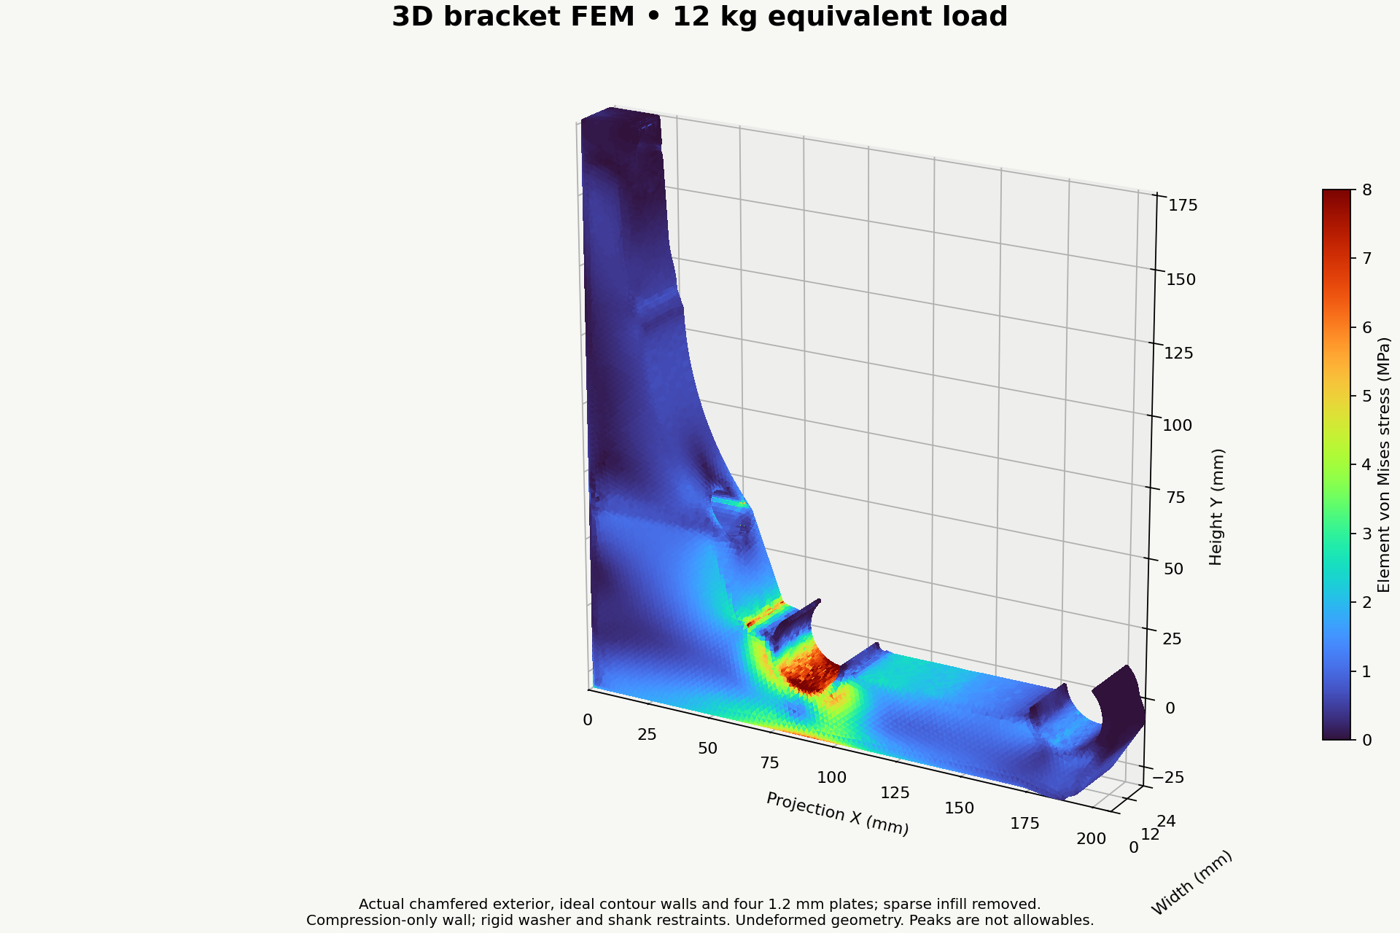
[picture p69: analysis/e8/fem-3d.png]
3D solved FEM


**Takeaways:** the reduced section beneath the rear dowel seat contributes substantial rotation. The earlier 0.22/0.27 mm numbers described only an idealized forearm and must not be used as whole-bracket movement. The first 8-wall 3D solve placed about 48% of the elastic strain energy in the rear-seat region, versus about 14% in the forward arm region. The recessed lower fixing also attracts significant outward reaction; assuming the upper screw alone takes the overturning couple misses that connection behavior.

The refined rear-seat regional volume-p99 von Mises stresses are approximately **7.6 MPa for 8 walls and 7.0 MPa for 10 walls**. Refinement increased these regional values by about 19% and 12%, while front movement increased about 5% and 6%. Global field percentiles changed less. The stress field is not demonstrated to be asymptotically converged. Raw peaks depend on tiny mesh cells at tool-tunnel/chamfer intersections as well as idealized restraint edges. For example, the regenerated 8-wall coarse maximum sits in a roughly 0.0000046 mm³ element at a tunnel-mouth intersection; that value is not a reliable rupture demand. The refined maxima move into the analysis-only inner-wall transitions beneath the rear seat, reaching approximately 25–27 MPa in very small cells. Those sharp core transitions approximate slicer-generated geometry; this analysis neither resolves their physical printed radii nor establishes a notch/rupture allowable. Different meshes can reverse the ranking of raw peak stress between the 8- and 10-wall cases. **Neither raw peaks nor percentile summaries are material allowables.** Use the [regenerated results](analysis/e8/RESULTS.md) for current mesh comparisons, actual stress fields, reactions and residuals.

An affine uniaxial patch test checks stiffness assembly, recovered stress and strain energy. Whole-bracket force/moment balance, residuals and refinement checks accompany the result files. A mesh comparison supports numerical interpretation; it does not validate years of service.

## Creep calculation and available margin

For a constant load and a common linear-viscoelastic compliance throughout a model with unchanged contact state:

`δ(t,T) = K × J(t,T) = K / Ec(t,T)`

Here K is the geometry/load coefficient in MPa·mm, J is creep compliance in MPa⁻¹ and Ec is the **secant creep modulus**, not the instantaneous unloading modulus. For the refined level-rail solves:

| Case | K, approximately | Initial movement | Ec needed for 5 mm bracket-only movement | Maximum compliance growth relative to reference E |
|---|---:|---:|---:|---:|
| PLA, 8 walls | 4,226 MPa·mm | 1.23 mm | 845 MPa | 4.05× |
| PETG, 10 walls | 3,839 MPa·mm | 1.66 mm | 768 MPa | 3.01× |

Refinement updates live in [RESULTS.md](analysis/e8/RESULTS.md). These thresholds spend the full 5 mm on the bracket. For the complete rack, use **Ec ≥ K / (5 mm − dowel movement − wall/fastener movement)**. The earlier 1-inch wood-rail example gave about 0.22 mm instantaneous sag with an assumed 8 GPa modulus; wood grade, moisture, defects and long-term behavior remain installation inputs.

For a material-data screening target, use **at least 1.0 GPa effective creep modulus at the intended age and loaded temperature history**. This rounds above the bracket-only thresholds and preserves some movement budget for the dowels, mounting and reaction redistribution. It is a project screening target, not a published grade allowable or a rupture criterion.

The tabulated correspondence calculation keeps the original seat reactions. Deformation changes those reactions: with a 200 mm spool and the front seat 4.65 mm lower relative to the rear, the front vertical load share rises from 50% to about 55.8%. That modest positive feedback needs a deformed-contact check near the movement limit; do not treat the linear threshold as an exact nonlinear capacity.

A one-roll change assigning an entire 1.25 kg reaction to one bracket gives approximately **0.13 mm for PLA and 0.17 mm for PETG** with the reference instantaneous modulus. For simple spans and the stated two-equal-span geometry, a single point load's reaction at the relevant support does not exceed the whole load. This estimate excludes overhangs, unusual continuity and handling impact. Fast removal of a roll depends on the aged unloading modulus; it is not correctly modeled by simply reversing all accumulated creep.

Even a settled, linear response at the full 5 mm limit gives a proportional one-roll change of about 0.52 mm for this load assumption. The 5 mm full-load criterion is therefore more restrictive than the 1 mm per-roll criterion in that simplified case.

### Published creep evidence and its limit

[Stankevics et al., 2025](https://doi.org/10.3390/polym17152075) tested unidirectional, 100%-filled Devil Design PETG at approximately 21.3°C, with tests extending to 20 hours. Its Figure 26 Prony spectrum provides a short-time benchmark. Graphically transcribed amplitudes are approximately 0.005, 0.010, 0.015, 0.010, 0.020 and 0.080 at time constants 1 through 100,000 seconds in decades.

`J(t)/J0 = 1 + Σ Ai[1 − exp(−t/τi)]`

That spectrum gives roughly 1.07 at five hours, 1.10 at 20 hours and a formal asymptote of 1.14. **The asymptote is a property of the fitted finite series, not proof that a rack at 85°F stops creeping.** Longer-time mechanisms were not calibrated by that experiment.

[Fischbach and Weinberg, 2023](https://arxiv.org/abs/2302.11240) tested a different printed PLA at room temperature. After approximately one week, measured flexural creep modulus was 1,040 MPa, about 56% of its 1,860 MPa datasheet flexural modulus, and deformation was still increasing. That demonstrates meaningful sub-Tg creep; it cannot be transferred unchanged to this PLA grade, temperature or service life.

The [calculation file](analysis/e8/engineering-summary.json) reports one-, five- and ten-year **sensitivity cases**, including unmeasured long-time compliance tails of 0, 0.02 and 0.10 per year. These are explicitly assumed continuations of a short-time example, not claimed PLA/PETG forecasts.

Creep sensitivity

A long-time viscous tail can be almost invisible in a 20-hour test yet add appreciable deformation over ten years. Conversely, slow creep that remains inside the movement budget need not make the rack unusable. The release question is whether the grade's measured compliance and creep-rupture behavior support the intended life.

### Six hot hours each year

With 85°F as the reference temperature, reduced annual time is:

`ξyear = 8,754 + 6 × Ahot hours`

Ahot is the material's creep-rate shift at 100°F relative to 85°F. It is not known for these print/grade combinations. An **assumed Arrhenius sensitivity**, using activation energies of 50, 100 and 200 kJ/mol, gives Ahot about 1.70, 2.90 and 8.42. The six hot hours then add about 0.048%, 0.130% or 0.508% to annual equivalent time.

Those small percentages do not establish thermal adequacy: the shift law is uncalibrated, reversible hot softening still occurs during the excursion, and nonlinear creep or damage may invalidate simple time shifting. Check loaded movement during the actual hot exposure. Do not replace the cycle with an average temperature or use a universal WLF constant as grade data.

## Screw landings and installation

| Feature | Current design |
|---|---:|
| Screw clearance | Nominal Ø5.2 mm with small printable roof relief |
| Compatible shank envelopes | #8, #10 and nominal M5; printed M5 fit needs confirmation |
| Washer face to wall | **3.6 mm** |
| Nominal driver access | Ø16 mm with sloping roof |
| Checked straight driver envelope | Ø15.8 mm |
| Analysis washer | Ø13 OD / Ø5.5 ID; 1.2 mm thick for geometric fit |
| Screw axes | Y = 164 and 40 mm; Z = 12 mm |

Use flat-bearing heads and washers. A countersunk head introduces wedging that these models do not cover. Do not assume every washer sold for M5 has the analyzed outside diameter. For a different washer, check fit and recalculate bearing area.

The actual CAD supports approximately 99.1% of the specified washer annulus. The small loss comes from the printable roof relief in the screw hole. The available bearing area is about **108 mm²**:

`A ≈ 0.991 × π/4 × (13² − 5.5²)`

| Assumed clamp force per screw | Mean pressure on supported annulus |
|---:|---:|
| 250 N | 2.3 MPa |
| 500 N | 4.6 MPa |
| 1,000 N | 9.3 MPa |

These forces are scenarios. Driving torque into wood does not reliably determine the clamp force because thread cutting and friction consume torque.

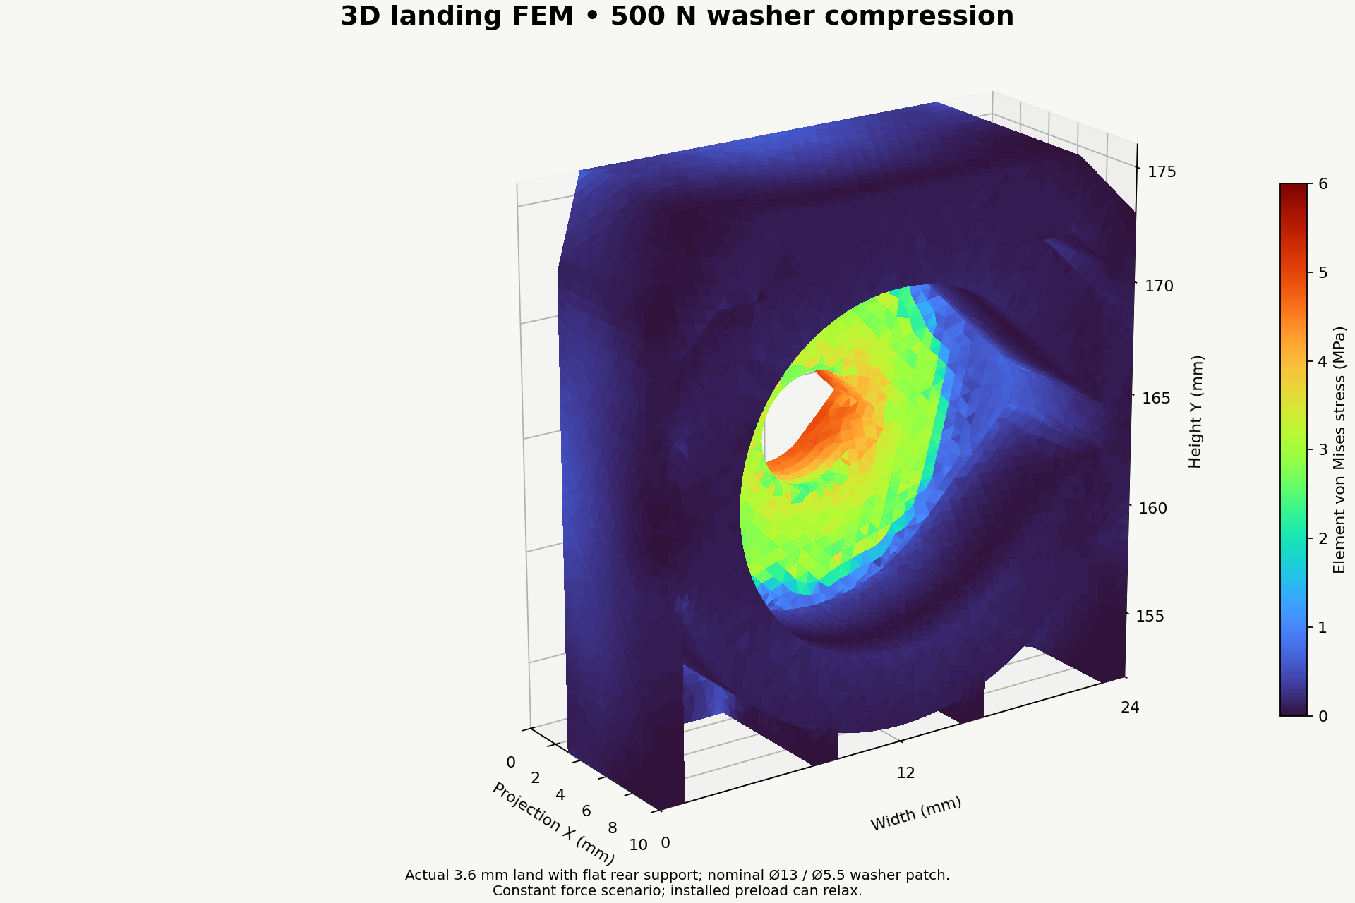
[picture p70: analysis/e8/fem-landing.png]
Screw-landing FEM


The local 3D submodel uses the actual **upper 3.6 mm land**, a 500 N distributed washer force and flat rear support. Refining that submodel from approximately 27,500 to 81,300 tetrahedra changed average axial washer movement from 0.0118 to 0.0121 mm at E = 1,000 MPa; the raw von Mises peak changed from about 4.83 to 4.98 MPa. At the PLA reference modulus that axial movement is about 0.0035 mm; at PETG's, about 0.0052 mm. These are constant-force calculations, not predictions of installed clamp-force retention.

**Retain the 3.6 mm land for now.** The backed compression case does not justify making it thicker. More thickness would add creep compression travel and violate the compact clamp intent without addressing the governing bracket region. This is a reasoned decision to retain the geometry, not a claim that every washer, tightening force or wall surface is acceptable.

The whole-bracket service model checks both fixings. The refined 8-wall solve attracted approximately 187 N outward reaction at the lower washer and 25 N at the upper; those demands depend on wall contact and connection stiffness. They replace the earlier upper-screw-only assumption for this specific model. They do not include an arbitrary tightening preload, and maxima from separate cases cannot simply be added as scalar von Mises stresses.

Mount against a flat, firm surface with full back contact. A gap behind a landing changes it into a bending/punching problem and invalidates the backed compression case. Seat the washer firmly without crushing the print; inspect for embedment and loosening. The load path does not rely on sustained clamp friction alone.

Use screws intended for the actual stud substrate, with manufacturer-specified pilot drilling and embedment. Required length includes the 3.6 mm plastic, washer, wall finish and required stud engagement. M5 **shank clearance** does not mean an M5 machine screw can be driven directly into wood. Install the screws before loading the rack. The checked tool is a straight cylindrical envelope, not an arbitrary drill body.

## Raised-front rail study: +12 mm

Raising the front rail changes support geometry and reactions; it is more than cosmetic camber. For nominal 25.4 mm dowels, 100 mm horizontal spacing, frictionless contacts and a 200 mm spool:

| Quantity | Level rails | Front rail +12 mm |
|---|---:|---:|
| Spool center from wall | 140.0 mm | 128.0 mm |
| Rear / front vertical load fractions | 50% / 50% | 64.8% / 35.2% |
| Wall moment at 12 kg equivalent | 16.48 N·m | 15.07 N·m |
| Net moment about rear rail | 5.89 N·m | 4.47 N·m |

This reduces wall moment about **8.6%** and the net moment about the rear rail about **24%**. The front rail still carries roughly 35% of the weight. Across 180–220 mm spools, the wall-moment reduction is about 7.6–9.5%. The front rail also presents a higher obstacle to forward roll-out.

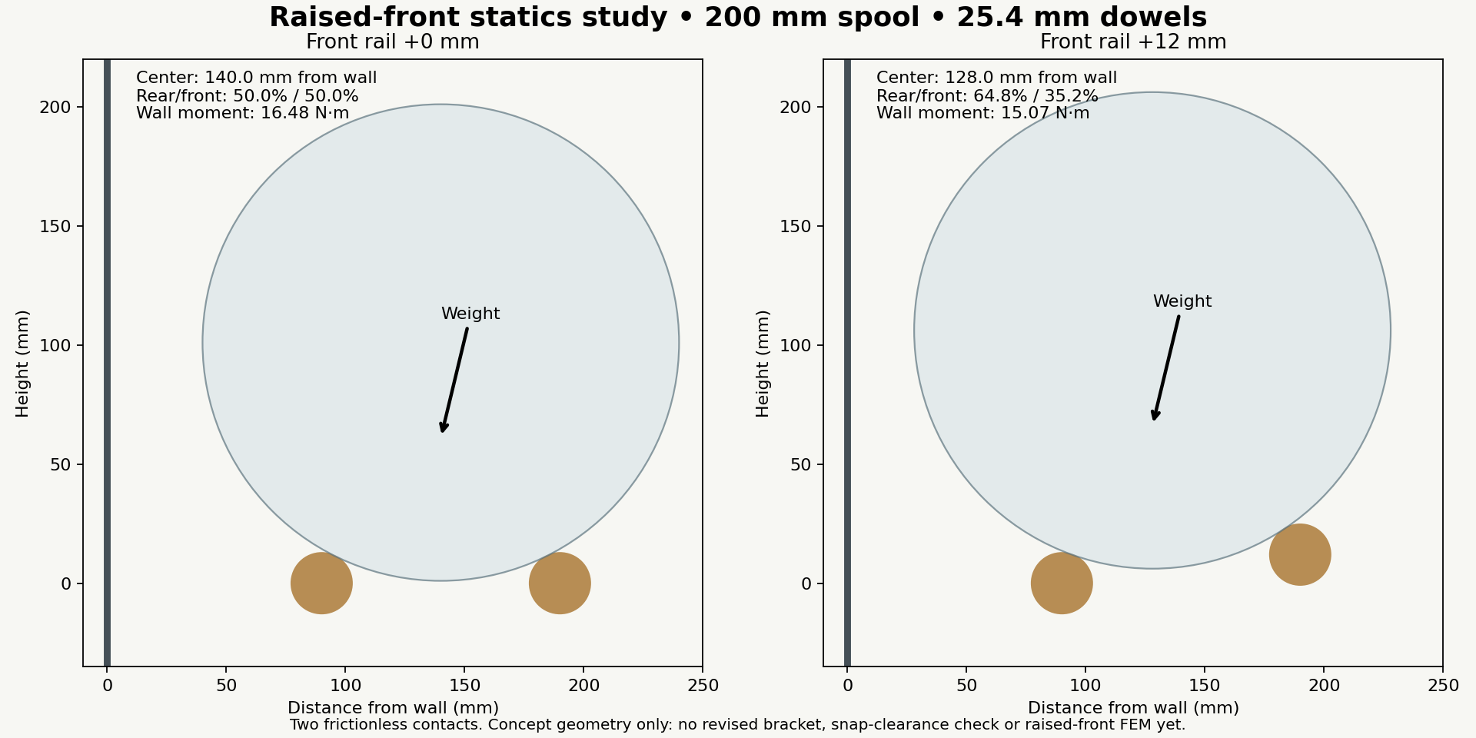
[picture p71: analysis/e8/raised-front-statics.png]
Raised-front statics study


**The unmodified back arm fails the raised-front clearance check.** With the front rail +12 mm, nominal clearance is about 4.65 mm for a 180 mm spool, only 0.22 mm for a 200 mm spool, and **−9.45 mm (interference)** for a 220 mm spool. These values come from point-to-segment distances on the exported E8 profile, using nominal dowel geometry. [Clearance results](analysis/e8/raised-front-clearance.json). Reshape the back arm toward the wall or move the rails outward before adopting this option; moving the rails outward returns some of the moment reduction.

The cost also includes greater rear-seat vertical load. That seat is already an important flexible region. Moving the front seat without remaking its supporting arm and rotating both snap openings to the new contact directions would be incomplete. The closer spool also needs a renewed wall-arm clearance sweep over the full diameter range.

**This option is not yet printable or FEM-qualified.** Complete its geometry, contact/clearance checks and load cases as a separate revision before replacing E8. Cosmetic camber remains an optional separate adjustment: half of a defensible one-year **front-minus-rear differential sag**, not half an unsupported life estimate.

## Qualification before assigning a lifetime spool rating

Record the actual filament grade, print settings, dry/conditioned state, washer, screws, dowel diameter/grade, spool mass/pitch and support arrangement. Confirm the slice matches the structural assumptions.

Measure unloaded position, immediate loaded movement and loaded drift at increasing elapsed times, including a sustained 85°F trial and a six-hour loaded 100°F exposure. Log the temperature at the bracket. Track the rear and front seats, span-center rail sag, washer embedment and any movement relative to the wall.

Use **5 mm total full-load movement and 1 mm per-roll change** as the project limits. Compare creep rates over equal time intervals; a plateau should emerge from measurements, not from forcing a finite Prony fit. Inspect for cracks, whitening, layer separation, permanent snap opening, loss of capture and increasing screw embedment. A 24 kg brief proof case is a proposed separate test; passing it does not establish long-term creep life.

A 1,000-hour trial is useful screening and model calibration. It is not automatically a ten-year rating. Extrapolation requires justified temperature/time shifts, the grade's creep behavior and a rupture check.

## Reproduction and design history

[Analysis scripts](analysis/e8) include the material-domain construction, 2D/3D solvers, known-solution verification, stress rendering, creep calculations and raised-front statics. [GitHub Actions](.github/workflows/engineering-analysis.yml) runs and publishes the calculated fields, then repeats the bracket and landing checks with finer meshes. The result JSON files retain force/moment balance, residuals and mesh details. Analysis-only BREP files and base meshes are regenerated; they are not print deliverables.

The CAD geometry verification is separate: [E8 STEP and hardware checks](designs/closed-wall-e8/verification.json). Physical printing and mechanical tests have not been performed in this repository.

[Design journal and superseded calculations](DESIGN-JOURNAL.md) · [Design decisions](DESIGN.md) · [Separate future open-web exploration](future/open-web/README.md)

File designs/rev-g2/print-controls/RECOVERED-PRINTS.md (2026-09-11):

# Recovered print evidence

The successful overnight ASA archive is associated with **E13**, not an established eight-wall G print. Its filename and closed-face preview agree with the downloaded STEP, which matches the published E13 assembly byte for byte. The newer downloaded STEP matches G byte for byte.

| Evidence | Polymer | Walls | Base infill | Minimum top/bottom thickness | Confidence |
|---|---|---:|---:|---:|---|
| Overnight completed archive, two E13-associated brackets | PolyLite ASA | 7 | 10% | 1.6 mm | Actual stored slice and completed-job filename recovered |
| Saved project using G and three 100% helpers | PolyLite PETG | 2 | 10% | 1.6 mm | Saved during the morning print; not proof of its exact submitted slice |
| Later G-named archive currently on the printer | PLA profile | 5 | 20% | 1.6 mm | Newer reused filename; not the earlier PETG submission |

Both recovered process configurations also store five top and three bottom layers at 0.2 mm, alongside the 1.6 mm minimum thickness settings. Do not interpret the layer counts alone as 1.0/0.6 mm skins.

The ASA archive estimates 256.94 g for two objects together. That is a slicer estimate, not measured mass. The saved PETG project retains all three expected G helpers as 100% infill modifiers. The sliced-only ASA archive omits source meshes and per-part modifier configuration; its exact helper setup is not recovered from that archive.

The original PETG submitted archive was not recovered. The cached G-code's first 65,536 bytes and total size match the newer PLA archive; the cache does not preserve the earlier PETG settings. The printer's filename has been reused, and the saved project was written after the completed morning job began. Bridge history records the completed jobs but does not retain their old project contents. Filament profile labels establish intended slicing material, not independent chemical identification of the loaded filament.

These findings prevent assigning the observed flexibility change solely to ASA versus PETG. Geometry and wall count changed as well. The eight-wall G schedules in this folder remain deliberate virtual controls, not reconstructions of the successful physical print. Their savings retain that explicit denominator.

The compact JSON receipt includes source hashes, selected settings and the exact public STEP matches. Original printer archives and private job metadata remain local and are excluded from Git.

https://github.com/thereprocase/spool-wall-rack/blob/main/designs/rev-g2/print-controls/recovered-print-evidence.json

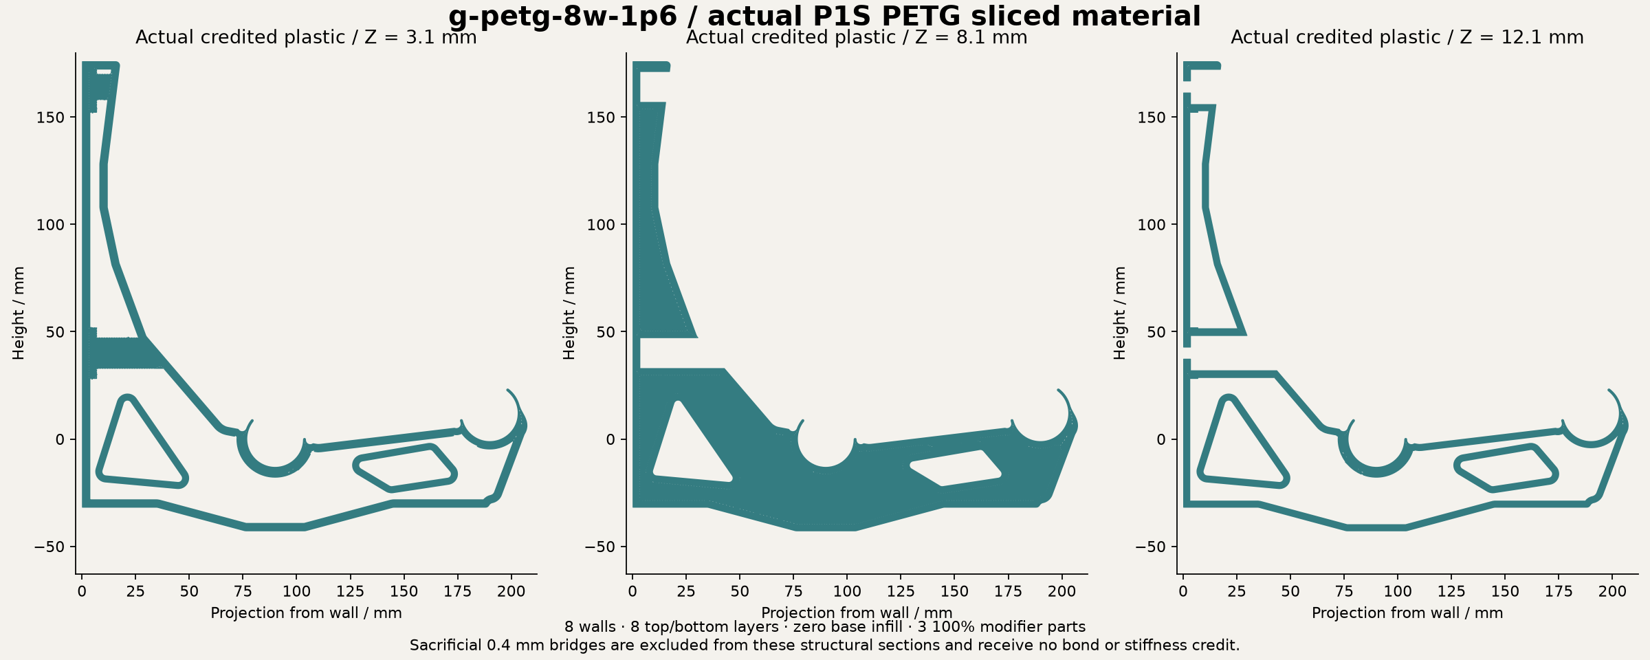
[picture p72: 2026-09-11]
designs/rev-g2/print-controls/g-petg-8w-1p6/toolpath-sections.png

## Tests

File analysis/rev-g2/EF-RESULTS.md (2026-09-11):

# Current continuation: thicker print controls and continuous brace core

The newer controls and reinvestment handoffs are under the following page. Historical percentages below use the two-wall, 1.0 mm skin digital G reference, not a recovered physical print.

https://github.com/thereprocase/spool-wall-rack/tree/main/designs/rev-g2/print-controls

The thin cut and helper trials now have intermediate 1e-4 contact diagnostics. Each tighter 1e-5 attempt missed its bound and is preserved: cut-v3 11.434463 mm / 69.397705 MPa; reinvest-v1 10.765244 mm / 67.948735 MPa; connected reinvest-v2 10.493240 mm / 59.759355 MPa. These did not become winners. No percentile stress substitution was used.

Upper-mast relief frees 2.090 cm3 of actual extrusion in cut-v4, which saves 32.032% against the thin digital G. Connected tapered helpers then spend 10.318 cm3, leaving 18.108% saving in reinvest-v2. Local raw-layer routes pass connectivity, but improved connection alone did not recover G stiffness. The next body adds a direct diagonal and retains thicker skins.

# E + F material reserve and local reinforcement

The implemented cut removes **29.211% of matched G spent extrusion**.
A separate local helper adds **6.342 cm3** back at three transitions, leaving
**20.653% net saving**. These are fresh Orca P1S PETG extrusion totals. The
new cut and reinforced mechanical checks are underway; mass saving is not
strength qualification.

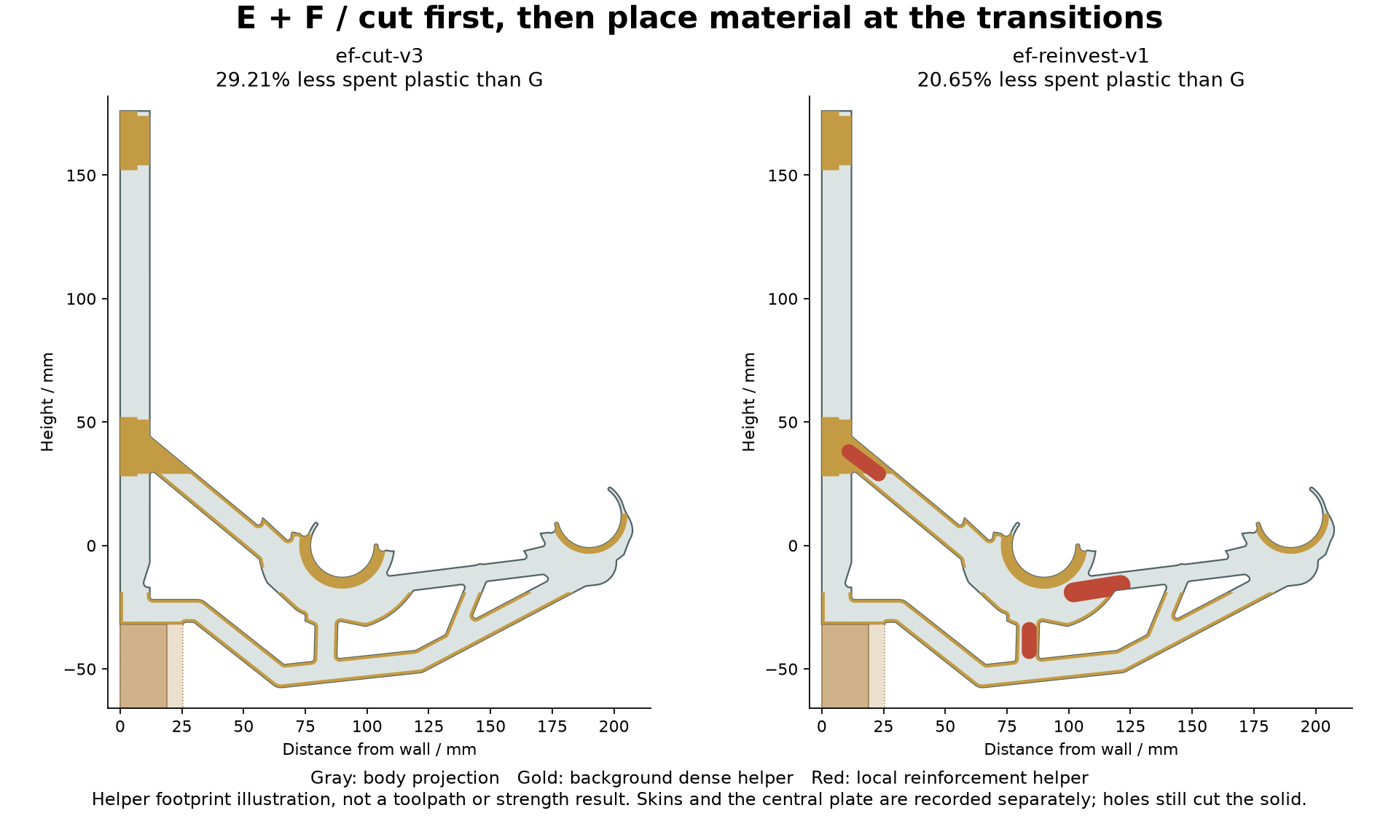
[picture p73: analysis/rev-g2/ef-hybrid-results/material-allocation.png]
Cut and reinforcement allocation


## Measured slice progression

| Candidate | Spent extrusion, cm3 | Saving versus G | Skin, mm | Internal planes |
|---|---:|---:|---:|---|
| Matched P1S G | 74.100 | reference | 1.0 | two 1.0 mm |
| EF reinforced reference | 73.007 | 1.475% | 1.0 | two 1.0 mm |
| EF lean v1 | 65.966 | 10.977% | 0.8 | one 1.0 mm |
| EF lean v2 | 61.613 | 16.851% | 0.8 | one 0.6 mm |
| EF cut v3 | 52.454 | 29.211% | 0.6 | one 0.6 mm |
| EF reinvest v1 | 58.796 | 20.653% | 0.6 | one 0.6 mm plus local backing |

All use two walls, 0% base infill and 100% helper regions. Totals include
startup extrusion and sacrificial bridges. The denominator is the matched
P1S G slice at 74.099671 cm3, not the older neutral-slicer G schedule.
The body is identical across these EF allocation trials. Layer/plate changes
and helper changes require a fresh slice; modifier geometry alone is not
printed plastic. All actual credited path sets are connected and pass the
P1S bed/exclusion and modifier-role checks.

## What the first full EF screen found

At 12 kg, the heavier EF reference gives **5.660824 mm** maximum movement and
**39.997226 MPa** raw tensile peak. G gives 4.335468 mm and approximately
20.0242 MPa under the matched planning model. The first EF body is more
flexible; the 1.475% saving did not establish an efficient design.

Its peak is near installed XYZ 107.758, -12.358, 15.442 mm, where the inner
seat joins the forearm. The local helper extends backing through this joint,
and also covers the wall/upper-brace and seat/keel-post transitions. Placement
is seeded by the accepted reference stress field. The cut and reinvested
states must independently establish the effect on compliance and movement.
If reinforcement needs more budget, the next cuts come from low-stress and
low-strain-energy areas. Preserve load connectivity, bearing/capture geometry,
print support and stability; check the changed load path after each cut.

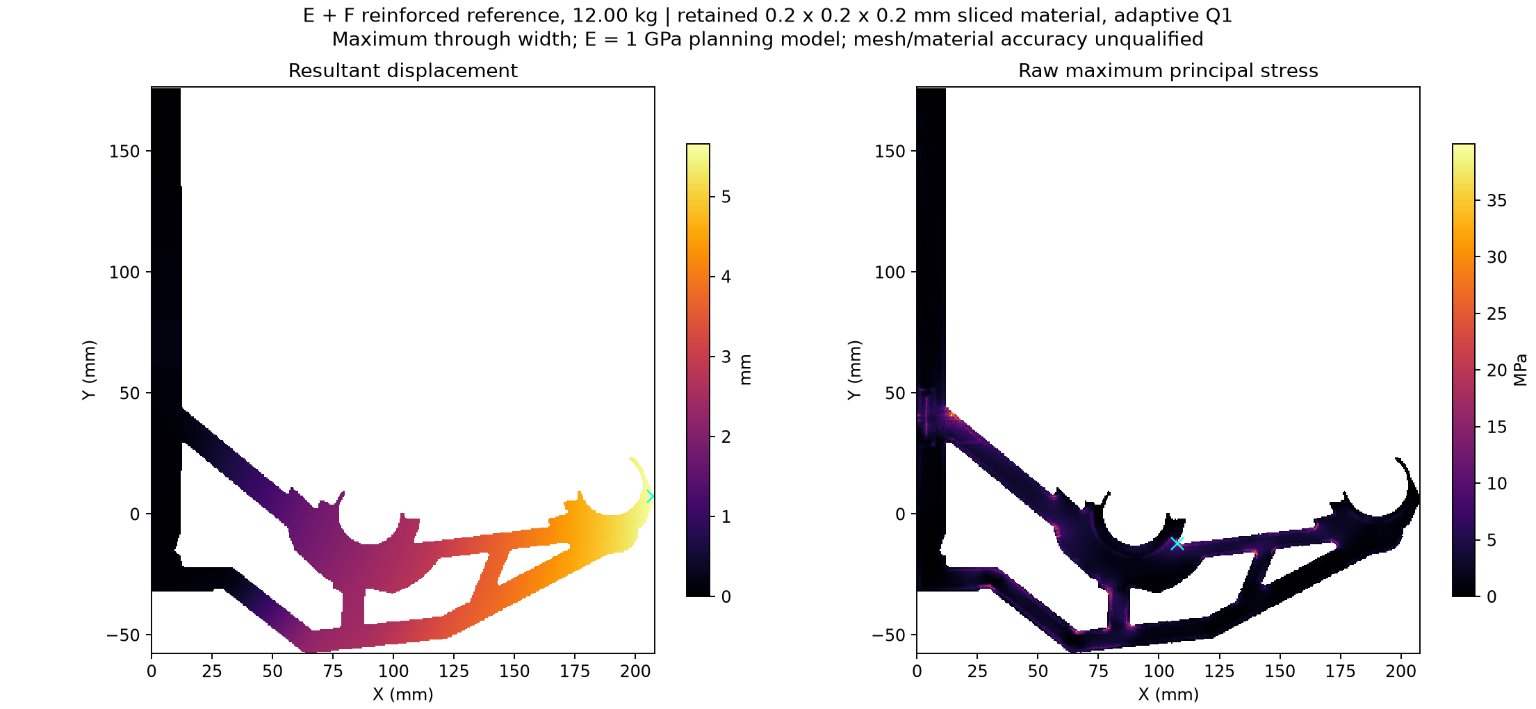
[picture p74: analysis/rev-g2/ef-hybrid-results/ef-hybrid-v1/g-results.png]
Accepted reference field


## Numerical evidence and limits

The reference's first strict linear/contact attempt failed at 6,000 iterations.
A stronger coarse retry also failed its bounded solve. Both raw fields and
all contact iterates survive. Neither failed field is promoted as a prediction.

The successful procedure settles unilateral contact at relative tolerance
1e-4, then recomputes equilibrium/contact at 1e-5. Discovery takes 271.805 s
including all stress export; the final check takes 59.754 s, with 40 linear
iterations and unchanged active contact. True final residual is 8.789e-6;
force/moment balance and contact inequalities pass. All 32,538,824 stress
samples survive. The maximum displacement change between the final discovery
and tight fields, evaluated across every fine node, is 3.235e-7 mm. This is an
iterate comparison, not a mesh-error bound. Earlier attempts, CAD, slicing,
geometry setup and audits are additional elapsed work.

The inscribed grid omits 11.091% of the reference's nominal raw plastic and
15.255% of the thinner cut's material. It adds no material and does not join
real gaps. Disconnected eroded components are retained; only the connected
loaded component receives the applied load. This omission limits quantitative
comparison, especially of local stress. An eroded model is not a guaranteed
conservative bound on every stress or failure mode. The adaptive solve uses
an isotropic E=1000 MPa, nu=0.35 planning law, idealized fixings and unilateral
wall contact. Moulding provides no structural support. Printed anisotropy,
creep, buckling, bonding, fit and a physical load rating remain unqualified.

A fresh EF plane-stress mesh diagnostic remains unsuccessful: its first
attempt encountered two zero-material roundoff elements; after an explicitly
bounded zero-volume cleanup, equilibrium checks still failed. Both attempts
are retained locally. No cheap EF ranking is claimed from those failures.
The completed 100-idea G pilot remains a separate, locally calibrated screen.

## Deliverables

Each directory contains aligned body/helper STEP files, model-only 3MF,
CAD verification, actual slice archive, section images, notes and hashes.
Individual helpers are modifiers, never extra printed parts.

https://github.com/thereprocase/spool-wall-rack/tree/main/designs/rev-g2/ef-cut-v3

https://github.com/thereprocase/spool-wall-rack/tree/main/designs/rev-g2/ef-reinvest-v1

https://github.com/thereprocase/spool-wall-rack/tree/main/designs/rev-g2/ef-hybrid-v1

https://github.com/thereprocase/spool-wall-rack/blob/main/PRINT-CANDIDATES.md

Public compact numerical receipts and full stress-field manifests

https://github.com/thereprocase/spool-wall-rack/tree/main/analysis/rev-g2/ef-hybrid-results

Raw stress arrays, contact iterates, integration caches, failed CAD/package
attempts and full slicer logs remain in ignored local evidence directories.
Do not restart the stopped whole-part CPU meshing jobs.

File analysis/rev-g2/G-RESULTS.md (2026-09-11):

# Rev G: completed 3D contact screen, with explicit accuracy limits

The retained sliced-material model gives **4.3355 mm maximum bracket movement
and 20.0254 MPa raw peak tensile stress at 12 kg**. Wall contact has settled:
there is no penetration and every active wall reaction is compressive.
This is a useful numerical screen, not qualification of the printed bracket.
The 0.2 mm inscribed geometry omits **8.0177%** of the raw nominal plastic;
material/mesh convergence and measured warm material properties remain open.

[Detailed reference audit](g-results/reference-tight/audit.json) ·
[All reference iterations and stress-file hashes](g-results/g-contact-tight-v1/solve.json) ·
[Aligned G STEP and helper handoff](../../designs/rev-g2/g-recheck/2w-5layers/README.md).

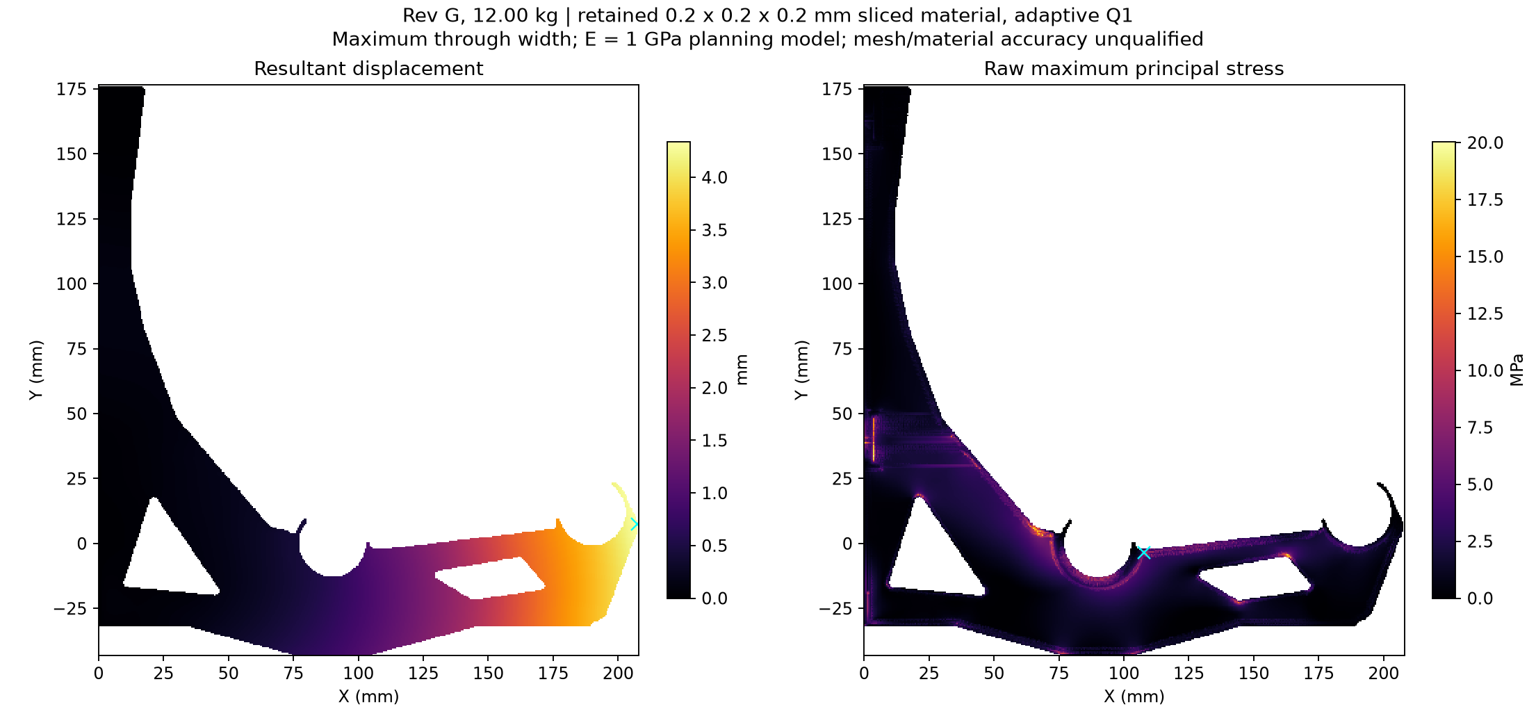
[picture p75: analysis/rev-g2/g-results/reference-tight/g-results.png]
G displacement and raw tensile stress


## What the reference says

| Quantity, at 12 kg / 117.72 N | Result |
|---|---:|
| Maximum resultant bracket movement | 4.335477 mm |
| Front bearing, load-weighted vertical movement | -3.886728 mm |
| Rear bearing, load-weighted vertical movement | -0.522320 mm |
| Raw maximum principal tensile stress | 20.025374 MPa |
| Raw maximum von Mises stress | 17.554158 MPa |
| Compressive wall reaction | 236.424282 N |
| Active wall nodes | 6,426 |
| Minimum wall gap | 0 mm |
| Minimum active wall reaction | +0.0000003502 N |
| Relative force / moment balance errors | 2.95e-9 / 2.89e-9 |
| True relative free residual | 9.96e-7 |

The maximum movement occurs near the outer front lip at
(207.4, 7.4, 21.6) mm. The raw tensile peak is at the inner-seat/forearm
transition, sampled at (107.6423, -3.5577, 22.8423) mm. The plots project
maxima through width; the cyan crosses mark the actual reported maxima.
All **32,772,600 Gauss samples** in **4,096,575 leaves** remain in the raw
stress files. No finite cell or peak was removed for reporting.

Within this model, 4.3355 mm exceeds the provisional 4 mm bracket allocation
by 0.3355 mm. Adding the separate 1 mm rail/mount reserve gives 5.3355 mm
against the 5 mm total budget. Those reserves are not measurements. A nominal
fourfold fracture factor would require an applicable material/process
allowable of at least 80.10 MPa at this sampled peak; no such allowable or
fracture margin has been established here. Raw stress is not mesh-converged.

## Solver accuracy and the delay

The original trials demanded a 1e-10 relative CG residual before allowing
the first wall-contact update. The full model has 14,207,226 independent
degrees of freedom and a slow residual tail. The initial bilateral wall
restraint also included about 322 N of artificial tensile wall reaction,
which had to be released before its displacements could describe contact.

An explicit 1e-5 inner-solve tolerance let the contact loop complete in
28 steps / 734 seconds, including every final stress sample. A fresh check
at 1e-6, using a finer auxiliary coarse grid, took 72.45 seconds and kept
exactly the same contact set. The maximum change across **every original
mesh node** was **4.894e-7 mm**; the largest change across **every stress
component and Gauss sample** was **5.527e-5 MPa**. The raw tensile peak changed
by 1.505e-6 MPa. These are measured iteration sensitivities, not a certified
bound on the exact continuum solution.

These runs are explicitly labelled `CONTACT_SCREEN_AT_STATED_TOLERANCE_ERODED_MATERIAL_ONLY`.
They do not retroactively pass the original stricter solver gate. Earlier
failures remain failures. The coarse-grid comparison at 0.4 mm failed linear
convergence and provides no accepted mesh-sensitivity result.

A bounded retry of the original 1e-10 CG target after contact settled also
failed: 3,500 iterations left a 3.06e-6 true relative free residual.
Its complete fields are retained separately as a failed iterate. The stated
1e-6 screen and its measured quantity sensitivity are the basis of the
reference numbers above; this retry does not upgrade them to the original gate.

## Adding and removing one 1.25 kg spool

| Load | Maximum movement, mm | Maximum movement change from 12 kg, mm | Raw tensile peak, MPa |
|---|---:|---:|---:|
| 10.75 kg | 3.883864 | 0.451612 | 17.939398 |
| 12 kg | 4.335477 | 0.000000 | 20.025374 |
| 13.25 kg | 4.787089 | 0.451612 | 22.111351 |

[Removed-spool audit](g-results/minus-spool/audit.json) and [added-spool audit](g-results/plus-spool/audit.json) retain the force, moment, gaps, reactions and all-sample comparisons. Both keep the 6,426-node contact set. The bracket-only change is about 0.452 mm, leaving about 0.548 mm of the 1 mm change budget for rails/mounts and other effects; those contributions remain unqualified.

The first added-spool attempt with an unscaled initial guess failed its 1e-6 residual target after 1,800 iterations and is preserved. For the successful cases, the converged reference displacement was scaled only as an initial guess. Each case independently assembled the new force, applied the full operator, recomputed reactions and nonzero wall gaps, checked contact and recovered every stress sample. The guesses already satisfied the stated tolerance, so CG accepted them at iteration zero. This demonstrates the same-contact linear response for these loads; it is not a claim that future contact changes can be handled by scaling alone.

## Method and independent checks

The fine physics is the existing constrained adaptive Q1 operator `P.T K P`.
Eight-point integration retains every leaf. An auxiliary Galerkin coarse
space integrates its basis over the actual retained material using exact
polynomial moments, including fixed-DOF projection. It accelerates iteration
without adding physical material, gap bonds, or sacrificial bridge stiffness.
The tiny unloaded components remain in the fine operator; they receive no
coarse correction that could excite their unforced rigid modes.

PyAMG 5.3.0 builds the auxiliary hierarchy on CPU. The V-cycle, transfers,
symmetric smoothing, coarse inverse and surrounding CG run on CUDA. Six
rigid-body near-nullspace candidates follow the elasticity guidance in
[PETSc's solver manual](https://petsc.org/main/manual/ksp/) and
[PyAMG's aggregation documentation](https://pyamg.readthedocs.io/en/latest/generated/pyamg.aggregation.html).
[PyAMG's MIT license](g-results/PYAMG-LICENSE.txt) is included; Warp retains
its earlier verified Apache-2.0 provenance.

[Independent fixtures](g-results/coarse-fixtures/fixtures.json) compare the
coarse operator with a separately assembled scikit-fem operator on solid,
hollow, partial-contact and translated-grid cases; worst relative difference
is 2.69e-15. GPU preconditioner symmetry, positive quadratic forms and CPU/GPU
agreement pass. A long-beam GPU comparison reduces 580 iterations to 80 while
retaining agreement with an independent direct CPU solution.
[Contact fixtures](g-results/contact-fixtures/fixtures.json) cover opening,
closing, nonzero gaps, contact release and fresh changed-load solves with
displacement/contact warm starts. A zero-free-load normalization bug found
by that restart test was fixed; the failed attempt is retained in the ledger.

## What still limits interpretation

- The retained volume is 66,126.984 mm3 versus 71,890.970 mm3 of raw nominal
  material. Erosion is conservative in material amount; it is not a certified
  upper bound on every local stress or displacement. The constrained coarse
  leaves also need a mechanical refinement comparison.
- The mechanics input is the preserved historical two-wall/five-skin-layer
  Orca slice with three original 100% helpers and 0% base infill. The separately
  checked fresh P1S/PETG slice has not replaced this input. No calibrated
  PETG/ASA print-property claim follows from either slice.
- The constitutive law is isotropic E = 1,000 MPa, nu = 0.35. Printed bond
  anisotropy, warm creep, defects and material/process allowables are unmeasured.
- Washers and bores are idealized restraints, with unilateral wall contact
  and radial nonnegative seat loading. Fastener/substrate capacity, rail sag,
  mount slip, dowel fit and physical qualification remain separate work.
- The 0.025 mm boundary census is still geometry-only. It has not become a
  mechanically tested finer full-G mesh. No G2 architecture is built here.

The next method improvement must reduce and measure material/mesh error on
this completed contact problem. Preserved CPU meshing failures stay stopped.

## Reproduction and evidence

Install [requirements-coarse.txt](requirements-coarse.txt) in the isolated
analysis environment. Use the geometry/adaptive preparation commands from
[ADAPTIVE-MESH.md](ADAPTIVE-MESH.md), then run `gpu_demo_solve.py` with
`--coarse-ratio 8 --linear-rtol 1e-5 --true-residual-limit 1.01e-5` for the
initial contact screen. Pass the last saved `master_u.npy` and
`active_wall_indices.npy` with `--initial` and `--initial-active` for a fresh
check at `--coarse-ratio 4 --linear-rtol 1e-6 --true-residual-limit 1.01e-6`.
Each output directory must be new. Omitting tolerance options retains the
original strict defaults. `report_gpu_g.py` audits saved fields and compares
all samples without altering them.

The published JSON reports contain every computed stress-file hash. Large
raw arrays, complete contact states, original failures and caches remain
preserved locally; they are not all embedded in Git. The evidence manifest
records their relative names, sizes and hashes. No CAD was changed: the
existing G body and all three aligned helper exports remain the handoff.

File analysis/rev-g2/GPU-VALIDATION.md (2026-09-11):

# GPU execution checkpoint: tested backend, unresolved whole-G material fidelity

September 11, 2026. **Warp now runs on the actual RTX 3080 Ti.** An upstream
elasticity example, independent 3D numerical fixtures and a manufactured patch
test on G's raw sliced material have been completed. The conservative voxel
geometry still removes too much material to accept as the corrected bracket.
No whole-G GPU load/contact solve, 3D strength margin or G2 architecture is
accepted. The stopped whole-part CPU meshing jobs remain stopped.

## Selected software and reproducible installation

Selected [NVIDIA Warp 1.17.0](https://github.com/NVIDIA/warp/releases/tag/v1.17.0),
whose [source license](https://github.com/NVIDIA/warp/blob/f4c57f26f1e3936a89afd283e39fcabf6d548dc7/LICENSE.md)
is Apache-2.0. The installed wheel includes its own third-party license notices;
this project does not redistribute that runtime. No commercial solver license
or trial is used. The installed wheel JIT compiles the GPU kernels successfully
under WSL2 on the RTX 3080 Ti, 12 GiB, driver 616.92. This is a tested wheel/JIT
installation, **not a source build of the Warp runtime**.

The wheel's elasticity example SHA-256 matches the tagged upstream source at
`f4c57f26f1e3936a89afd283e39fcabf6d548dc7`. Exact environment versions and source
hashes are in [environment.json](gpu-validation/environment.json).

The reviewed DTU snapshots remain useful research references:
[OpenMP GPU](https://github.com/topopt/TopOpt-in-OpenMP-GPU/tree/b46ed453ad5a05818b563e540ce176c9d85c6fe2)
and [Futhark](https://github.com/topopt/futtop/tree/c3cd2b00632ad57cd3d8917246552b2fb4e99e01).
Neither tree contained a license/COPYING file, and neither repository's GitHub
metadata advertised a license in the current inspection. Reuse permission was
not established, so neither was installed or incorporated. No conclusion about
permission should be inferred from public download availability.

Use an isolated environment with [requirements-gpu.txt](requirements-gpu.txt).
The earlier CAD/meshing environment and its caches are unchanged. These commands
run from the repository root, with a working CUDA device exposed to Python:

```sh
python3 -m venv .work/gpu-venv
.work/gpu-venv/bin/python -m pip install -r analysis/rev-g2/requirements-gpu.txt
.work/gpu-venv/bin/python analysis/rev-g2/gpu_benchmark.py --cg-tol 1e-10 --output analysis/rev-g2/.work/gpu-replay/upstream-tight
.work/gpu-venv/bin/python analysis/rev-g2/validate_gpu_hex.py --output analysis/rev-g2/.work/gpu-replay/fixtures
.work/gpu-venv/bin/python analysis/rev-g2/gpu_material_probe.py --h .4 .2 .1 --output analysis/rev-g2/.work/gpu-replay/material
```

Python 3.11.15 was used for the recorded run. The GPU adapter rejects a CPU
device; it does not silently fall back. Run measurements sequentially. Logs
and original failed attempts remain locally in `.work/gpu-route/logs`.

## Upstream elasticity benchmark

The upstream [mixed-elasticity example](https://github.com/NVIDIA/warp/blob/f4c57f26f1e3936a89afd283e39fcabf6d548dc7/warp/examples/fem/example_mixed_elasticity.py)
is a **2D nonlinear** problem, not 3D bracket elasticity. Its 25-by-25 grid uses
degree-two displacement, imposed displacement 0.1 and Poisson parameter 0.5.
The wrapper leaves the upstream file unchanged and explicitly overrides the
linear solver tolerance to `1e-10`. That override is part of the result.

The [accepted backend comparison](gpu-validation/upstream-tight.json) retains
[both CPU/GPU displacement and upstream stress coefficient fields](gpu-validation/upstream-tight.npz).
Relative L2 differences are **3.24e-6 in displacement** and **7.31e-6 in stress**,
both below the original `1e-4` comparison gate. This is a backend regression,
not independent physical validation of the upstream nonlinear problem.

The first measured GPU call took 0.407 s including setup and available cached
JIT work; the subsequent synchronized step took **0.0985 s**. The Warp CUDA
allocation-pool high water was **20.7 MiB**. Device-wide sampled memory peaked
at **1,350.2 MiB**, including the CUDA context, display and unrelated allocations.
These are different memory measures. Sampling is every 20 ms and can miss
short-lived peaks; the allocator high-water counter is not sampled. CPU timing
includes its own initialization/cache behavior, so no controlled speedup ratio
is claimed. Crop timings below do not predict a bracket solve.

Two default-tolerance comparisons failed the original stress-agreement gate:

- [Default material/load](gpu-validation/failures/default-tolerance/upstream.json):
  stress relative L2 difference `2.372e-4`; full fields retained.
- [Severe near-incompressible case](gpu-validation/failures/near-incompressible.json):
  displacement -0.5, Poisson parameter 0.99, stress difference `5.125e-4`;
  full fields retained. It has not been qualified by the accepted default-case run.

The upstream helper defaults to CG tolerance `1e-4`. Tightening that solve
tolerance resolved the default-case comparison without loosening the acceptance
gate. Neither failed output is substituted for the accepted result. The
upstream stress coefficients are retained exactly as its example produces
them; they are not used as bracket stress or material allowables.

## Independent 3D adapter tests

[gpu_hex.py](gpu_hex.py) implements matrix-free, uniform rectangular Q1
hexahedral linear elasticity using Warp GPU kernels and Warp's CG solver.
The common element matrix is integrated at eight Gauss points; the GPU applies
it without assembling a whole-model stiffness matrix. Preconditioning is
diagonal/Jacobi. **There is no multigrid yet.** Mesh construction and contact
active-set decisions run on the CPU; elasticity operator application, CG vector
work and stress recovery run on the GPU in float64.

The [fixture report](gpu-validation/hex-fixtures.json) passes:

| Check | Measured result |
|---|---:|
| General affine strain, analytic stress | maximum error 1.14e-12 MPa |
| Random displacement: GPU operator vs independently assembled scikit-fem Q1 operator | relative difference 3.00e-16 |
| Translation / infinitesimal rotation | internal force norms below 3e-13 N |
| Hollow beam, 0.4 mm walls / two cells through wall | GPU vs independent direct CPU displacement error 2.44e-13 relative |
| Hollow beam force / moment errors | 1.11e-12 N / 2.90e-12 N mm |
| Nonzero-gap contact | analytical open, close, touching, exact touch and release cases pass |
| Face / edge / corner connectivity | shared face bonds; edge-only and corner-only touches have separate nodes |

The hollow fixture has 400 material cells and zero cavity elements. Its
1 N bending diagnostic solves in about 0.025 s with 140 CG iterations.
All 3,200 finite stress samples, displacement, force, reaction, volumes and
independent CPU displacements are in [hollow-bending.npz](gpu-validation/hollow-bending.npz).
The analytic contact fixtures use an actual 3D bar, not just a scalar spring;
their full fields are in the five `contact-*.npz` files alongside the report.

The first fixture run stopped at an incorrectly written expected cell count
(320 instead of `10 * (8*6 - 4*2) = 400`). It had already passed its elasticity
comparisons. Its [incomplete report and fields](gpu-validation/failures/fixture-count)
remain preserved; the corrected completed run is the accepted fixture report.

No void or sacrificial bridge cell receives stiffness. Nodal connectivity is
split locally when material cells touch only on an edge/corner, even if the
same material connects elsewhere. All eight unaveraged stress samples in
every retained cell are exported. Reported raw peaks are maxima over those
samples, not percentiles, nodal smoothing or bounds on unsampled continuum
stress. No cell is deleted based on its stress.

## Actual G sliced-material crop and resolution limit

The input is the preserved **raw** two-wall/five-skin-layer cache, not its
closed/simplified continuum. The crop is installed X=140..148 mm,
Y=-34..-26 mm, Z=0..24 mm. Its raw slice volume is **415.626717 mm3**.
Source hashes are recorded. This is a geometric footprint volume, not extrusion E.

The [mapper](gpu_material_probe.py) retains a voxel only when its entire XY
rectangle is covered by **every** raw slab crossing its Z interval. It never
uses centroid occupancy, closes gaps or gives voids fractional stiffness.
The synthetic bridge-only connector is excluded through the existing
`layer_shapes` routine, and the mapped beads remain two disconnected components.
The separately preserved G-code validation establishes the real bridge mask.

| XY / Z grid, mm | Retained cells | Retained volume, mm3 | Omitted raw material | GPU patch solve, s |
|---|---:|---:|---:|---:|
| 0.4 / 0.2 | 10,765 | 344.480 | 17.12% | 0.051 |
| 0.2 / 0.2 | 47,606 | 380.848 | 8.37% | 0.101 |
| 0.1 / 0.2 | 198,853 | 397.706 | 4.31% | 0.437 |

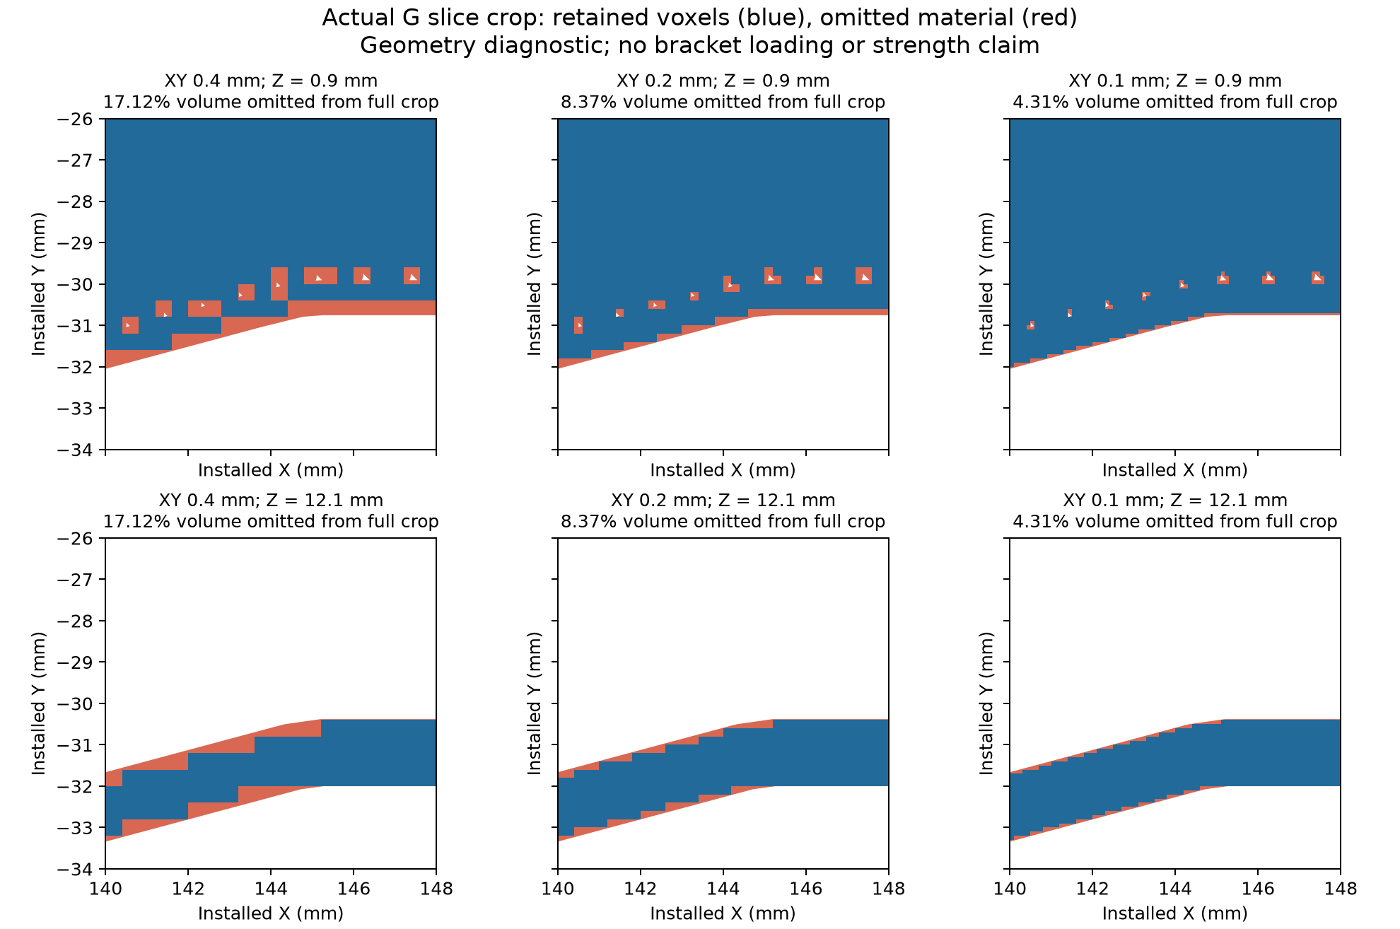
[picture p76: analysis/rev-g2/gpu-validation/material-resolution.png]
Raw material omitted by conservative voxel mapping


The finer crop has 232,445 nodes and a CUDA allocation-pool high water of
**117.2 MiB**. Mapping took 0.705 s and CPU topology construction 7.660 s.
The GPU solve took 200 CG iterations. Its complete
[fields](gpu-validation/refinement/g-crop-h0p1.npz) retain all 1,590,824 Gauss
stress samples, every cell, applied/prescribed data, reactions and geometry.
[Combined coarse reports](gpu-validation/material-probe.json) and
[fine report](gpu-validation/refinement/material-probe.json) include all timings.

These are **manufactured patch tests**: a known affine displacement is imposed
on all material surfaces of the crop, including cavity and cut surfaces, with
interior nodes solved freely. This also supports disconnected particles for
the analytic test only; none are silently discarded. Maximum stress error is
below 2e-8 MPa at all three grids. These boundary conditions make a controlled
operator/mapping check; they are not G's seat, washer, bore or wall conditions.
They do not establish long-beam CG performance or contact at bracket scale.

**The conservative grid is not accepted for whole-G mechanics.** Even the
0.1 mm XY grid removes 4.31% of this crop, concentrated at boundaries and small
pores. A volume difference cannot bound local stress or movement errors, and
the crop cannot establish full-part connectivity. Refinement improves the
geometry but does not demonstrate a converged bracket response.

## Next work and retained gates

1. Resolve thin-path boundary representation with a bounded adaptive/cut-cell
   experiment that preserves disconnected material and actual face bonding, or
   demonstrate adequate full-voxel geometric and mechanical convergence.
2. Establish a practical preconditioner and runtime/memory behavior for a long,
   thin bending problem before scaling to the bracket. Small affine patch
   solves with many prescribed surface nodes are insufficient evidence.
3. Adapt and verify G's actual seat loads, 3.6 mm washer plane, bore restraints
   and nonzero-gap wall contact. Then solve the 117.72 N reference, refinement
   and changed-spool load with all force/moment/stress gates.
4. Only after corrected G feedback, implement the seven preparatory G2
   families and their aligned body/helper STEP checkpoints.

The current [print download index](../../PRINT-CANDIDATES.md) is unchanged in
candidate count: eight earlier implemented handoffs and five G slicing
schedules. This checkpoint adds solver evidence, not a printable architecture.
Measured material/process, creep, dowel fit, rail/mount behavior and physical
qualification remain outstanding. No released spool rating follows from this work.

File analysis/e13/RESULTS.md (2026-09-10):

# E13 solved engineering results

The reinforced inner seat and mirrored 50° finish have been re-solved in 2D and
3D. The printable body stays solid CAD with two separate modifier helpers; only
the analysis domains remove sparse core material.

## Angular reinforcement and stress concentrations

E13 uses **11 mm added underside depth** and straight tapers into a short flat
bottom. It is 1.5 mm deeper than E12 and remains below the 12.67 mm cap. Small
corner blends, rigid shoulder transitions, fingers, plates, hardware and
mirrored 50° chamfers remain. The adjacent arms are not weakened.

[Matched E10/E12/E13 comparison](COMPARISON.md) and
[finished section properties](../../designs/closed-wall-e13/section-verification.json)
record the measured changes. [The hotspot audit](HOTSPOTS.md) compares every
region and retains raw peaks, locations, cell volumes and mesh sensitivity.
These comparisons cannot establish that every local peak is a numerical artifact.

## Current 3D solution and refinement

12 kg equivalent per bracket; E = 1,000 MPa and ν = 0.35. The near-seat window is
X = 75–110 mm, Y = −24–0 mm, over the full width.

| Walls | Tetrahedra, coarse → fine | Front movement at E1000 (mm) | Movement change | Near-seat p99, coarse → fine (MPa) | p99 change |
|---:|---:|---:|---:|---:|---:|
| 8 | 323,629 → 757,028 | 2.148 | 1.84% | 3.82 → 3.80 | -0.34% |
| 10 | 328,179 → 787,137 | 1.937 | 1.90% | 3.60 → 3.57 | -1.09% |

8-wall 3D stress and cutaway

Cuts through the actual solved tetrahedra

[10-wall 3D view](fem-3d-10w.png). The 6 MPa colour cap makes the working field
visible; saved fields retain every solved value. Percentiles and raw peaks are
not stress allowables. These meshes do not establish asymptotic convergence,
printed orthotropy, layer adhesion, snap insertion, rupture or lifetime strength.

| Walls | Raw peak, coarse (MPa) | Raw peak, fine (MPa) | Fine free residual | 2D front coefficient relative to 3D |
|---:|---:|---:|---:|---:|
| 8 | 17.5 | 25.5 | 6.80e-09 | -4.36% |
| 10 | 15.1 | 24.2 | 5.46e-09 | -4.18% |

Raw peaks remain sensitive to small cells at chamfer, tunnel and analysis-core
intersections. Their locations and volumes are in `engineering-summary.json`.
All published 3D fields pass independently recomputed free residual, force and
moment balance below 1e-6. The affine test checks displacement, recovered stress
and strain energy; PARDISO agrees with an independent SuperLU patch solution.
The reduced solver has separate affine and beam checks.

All current and baseline global domains use audited same-domain CAD face cleanup. The
current summary compares h1.5/h1 for both wall counts; the hotspot audit
also retains h2 as the third mesh level and new h1 E12 baselines. No finite cells are deleted
for their stress values. `analysis-topology-cleanup.json` and mesh audits
record CAD volumes and any numerically zero-volume removal.

## Material movement and creep margin

The retained grade-specific room-temperature XY moduli are applied to E13's new
coefficients. They are not measured hot or aged properties.

| Material | Walls | E (MPa) | K (MPa·mm) | Initial front (mm) | One 1.25 kg roll (mm) | Ec for 5 mm bracket-only (MPa) | Compliance growth limit |
|---|---:|---:|---:|---:|---:|---:|---:|
| PLA | 8 | 3427 | 2148.0 | 0.627 | 0.065 | 430 | 7.98× |
| PETG | 10 | 2311 | 1936.6 | 0.838 | 0.087 | 387 | 5.97× |
| ASA | 8 | 2379 | 2148.0 | 0.903 | 0.094 | 430 | 5.54× |
| PA6-GF dry | 8 | 5357 | 2148.0 | 0.401 | 0.042 | 430 | 12.47× |
| PA6-GF wet | 8 | 1794 | 2148.0 | 1.198 | 0.125 | 430 | 4.18× |

`δ(t,T) = K × J(t,T) = K / Ec(t,T)` assumes common linear-viscoelastic compliance
and an unchanged load/contact state. For the whole rack use **Ec ≥ K / (5 mm −
dowel movement − wall/fastener movement)**. Retain the project screening target
of at least 1.0 GPa effective creep modulus at the intended age and loaded
temperature history; it is not a published allowable or rupture criterion.

The one-roll calculation assigns its entire reaction to one bracket for the
stated simple/two-equal-span case. Fast unloading uses aged instantaneous
modulus, not reversal of accumulated creep. Other support arrangements,
overhangs and impact need their actual reactions.

PLA/PETG remain prototype choices; ASA is the higher-temperature comparison.
PA6-GF dry and water-conditioned cases stay separate. Match the source's
100°C/16-hour annealing and conditioning before using its properties, and
recheck fit. [Exact grades, source URLs and hashes](../../designs/closed-wall-e6/material-reference-data.json).

## 24 kg brief proof scenario

Elastic stress and movement double at 24 kg with the same load pattern and
active contact. This is linear scaling, not a damage simulation or a performed
physical proof test.

| Walls | Near-seat p99 at 24 kg (MPa) | Front movement at E1000 (mm) |
|---:|---:|---:|
| 8 | 7.61 | 4.296 |
| 10 | 7.13 | 3.873 |

## Screw landings and contact

The global model uses compression-only wall contact, rigid washer axial
restraints and rigid shank shear restraints. No tightening friction or arbitrary
preload is credited. The lower washer carries substantial outward demand.

| Walls | Upper washer outward demand (N) | Lower washer outward demand (N) |
|---:|---:|---:|
| 8 | 15.2 | 213.5 |
| 10 | 15.4 | 211.0 |

The separate **500 N upper-landing submodel** uses the actual 3.6 mm land and flat rear support. Its 33,764 → 83,814 tetrahedron refinement changes washer movement by 1.61%. Fine mean movement is **0.01208 mm at E1000**, with a **4.95 MPa** raw peak. This constant-force scenario does not predict installed clamp-force retention.

E13 screw-landing stress

Retain the backed 3.6 mm land. A gap behind it creates bending/punching conditions
outside this submodel. Use the checked washer dimensions and substrate-appropriate
fixings. Separate scalar von Mises maxima from service and tightening cannot be
added as if they were stress tensors.

## Creep sensitivity with E13 coefficients

The retained [PETG study](https://doi.org/10.3390/polym17152075) supplies a short-time
example at about 21.3°C, tested to 20 hours. Its approximate Figure 26 spectrum
gives compliance multipliers near 1.07 at five hours and 1.10 at twenty hours.
The formal 1.14 plateau is built into the finite fit and does not prove years of
behavior at 85°F for these bracket grades.

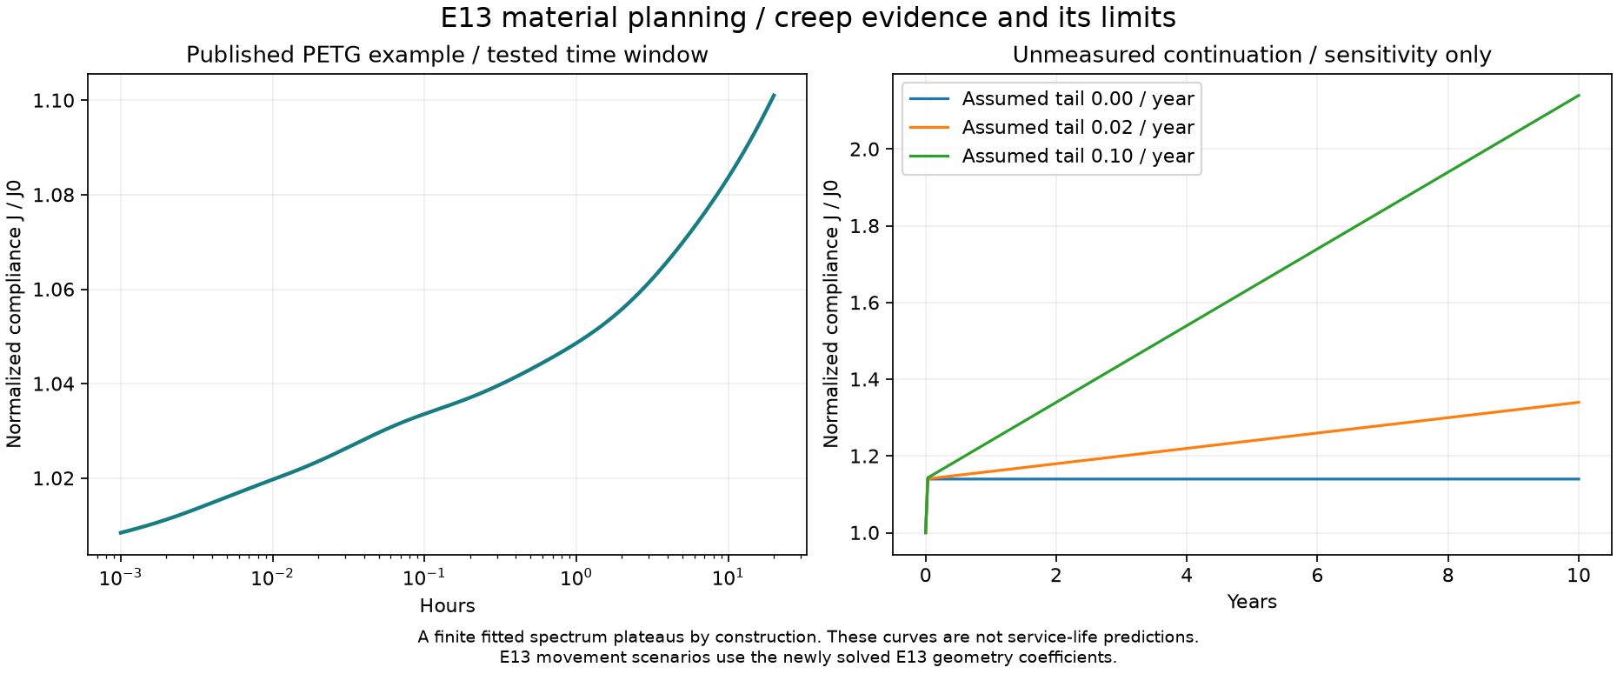
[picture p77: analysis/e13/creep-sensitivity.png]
Short-time evidence and unmeasured tails


These deliberately different long-time tails use E13's new movement coefficients.
They are **not PLA/PETG service-life forecasts**.

| Years | Assumed extra compliance / year | Multiplier | PLA front (mm) | PETG front (mm) |
|---:|---:|---:|---:|---:|
| 1 | 0.00 | 1.14 | 0.71 | 0.96 |
| 1 | 0.02 | 1.16 | 0.73 | 0.97 |
| 1 | 0.10 | 1.24 | 0.78 | 1.04 |
| 5 | 0.00 | 1.14 | 0.71 | 0.96 |
| 5 | 0.02 | 1.24 | 0.78 | 1.04 |
| 5 | 0.10 | 1.64 | 1.03 | 1.37 |
| 10 | 0.00 | 1.14 | 0.71 | 0.96 |
| 10 | 0.02 | 1.34 | 0.84 | 1.12 |
| 10 | 0.10 | 2.14 | 1.34 | 1.79 |

At 85°F sustained and 100°F for six loaded hours/year, the uncalibrated Arrhenius
sensitivity assumes 50/100/200 kJ/mol activation energy. Hot-rate factors are
1.70/2.90/8.42, adding 0.048%/0.130%/0.508% to annual equivalent time. This does
not prove thermal adequacy; actual hot softening, nonlinear creep and rupture
remain unqualified. Full numerical values are in `engineering-summary.json`.

## Print evidence and qualification boundary

The delivered STEP contains one valid body and two aligned helpers. Both faces
measure 50°. Complete flexible-finger sectors match E10 at nine print depths;
hardware and nominal spool-clearance checks pass. Actual OrcaSlicer 8/10-wall
G-code verifies the four solid bands and seat-wall footprints.
[CAD and toolpath evidence](../../designs/closed-wall-e13/README.md).

The 5 mm total loaded-movement and 1 mm per-roll-change limits include dowels and
mounts. Rod fit, snap behavior, extrusion quality, sustained/hot movement and
creep rupture still need physical qualification. No lifetime safe spool count
is assigned by this revision.

[Reproduce](README.md) · [Current print and engineering guide](../../README.md).

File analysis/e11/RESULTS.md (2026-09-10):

# E11 solved engineering results

The reinforced inner seat and mirrored 50° finish have been re-solved in 2D and
3D. The printable body stays solid CAD with two separate modifier helpers; only
the analysis domains remove sparse core material.

## Matched E10/E11 comparison

At identical load, wall count and solver assumptions, the reduced model gives
about **37% lower near-seat stress and 35% less front movement**. Loading only
the outer rod lowers the near-seat statistic **43.5%** in E11. The fixed comparison
window excludes added underside volume from its percentile denominator. This
supports reduced-section bending as the original mechanism, while real bearing
effects remain possible. [Comparison fields and refinement](COMPARISON.md).

The finished section model gives at least **1.539 times the bending I** and
**1.282 times the elastic section modulus** of the stronger adjacent plain-arm
reference band. This is local section margin, not a capacity rating.
[Section evidence](../../designs/closed-wall-e11/section-verification.json).

## Current 3D solution and refinement

12 kg equivalent per bracket; E = 1,000 MPa and ν = 0.35. The near-seat window is
X = 75–110 mm, Y = −24–0 mm, over the full width.

| Walls | Tetrahedra, coarse → fine | Front movement at E1000 (mm) | Movement change | Near-seat p99, coarse → fine (MPa) | p99 change |
|---:|---:|---:|---:|---:|---:|
| 8 | 180,806 → 235,089 | 2.306 | 2.56% | 3.56 → 3.79 | 6.37% |
| 10 | 149,156 → 242,810 | 2.098 | 2.27% | 3.79 → 3.79 | 0.10% |

8-wall 3D stress and cutaway

Cuts through the actual solved tetrahedra

[10-wall 3D view](fem-3d-10w.png). The 6 MPa colour cap makes the working field
visible; saved fields retain every solved value. Percentiles and raw peaks are
not stress allowables. These meshes do not establish asymptotic convergence,
printed orthotropy, layer adhesion, snap insertion, rupture or lifetime strength.

| Walls | Raw peak, coarse (MPa) | Raw peak, fine (MPa) | Fine free residual | 2D front coefficient relative to 3D |
|---:|---:|---:|---:|---:|
| 8 | 35.3 | 37.9 | 3.17e-08 | -0.55% |
| 10 | 75.3 | 51.1 | 3.11e-08 | +0.31% |

Raw peaks remain sensitive to small cells at chamfer, tunnel and analysis-core
intersections. Their locations and volumes are in `engineering-summary.json`.
All published 3D fields pass independently recomputed free residual, force and
moment balance below 1e-6. The affine test checks displacement, recovered stress
and strain energy; PARDISO agrees with an independent SuperLU patch solution.
The reduced solver has separate affine and beam checks.

An initial 10-wall coarse field failed the residual gate and was rejected. An
initial 8-wall refined topology produced a 335 MPa peak in a 3.10e-10 mm³
tunnel-mouth cell. Merging redundant same-domain CAD faces allowed new meshes
without deleting finite material for its stress value; front movement changed
only 0.13% in the 8-wall refined comparison. `analysis-topology-cleanup.json`
records CAD volume differences below 0.001 mm³. Mesh audits retain finite cells
and record only numerically zero-volume removal.
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

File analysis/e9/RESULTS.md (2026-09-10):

# Solved E9 engineering results

These results apply to the raised-front E9 prototype, including its reshaped back arm and 2 mm broad-face chamfers. The rail-statics comparison isolates the effect of the 12 mm height change.

| Material | Walls | Reference E (MPa) | Initial front movement (mm) | One 1.25 kg roll (mm) | Creep modulus needed for 5 mm (MPa) | Compliance limit |
|---|---:|---:|---:|---:|---:|---:|
| PLA | 8 | 3427 | 1.01 | 0.105 | 693 | 4.94× |
| PETG | 10 | 2311 | 1.37 | 0.142 | 632 | 3.66× |
| ASA | 8 | 2379 | 1.46 | 0.152 | 693 | 3.43× |
| PA6-GF dry | 8 | 5357 | 0.65 | 0.067 | 693 | 7.73× |
| PA6-GF wet | 8 | 1794 | 1.93 | 0.201 | 693 | 2.59× |

Moduli are room-temperature reference values. The creep-modulus limits apply to bracket movement alone; subtract dowel and wall movement from the 5 mm system allowance. The one-roll column assigns the entire roll reaction to one bracket, for the stated simple/two-equal-span arrangement, and uses the reference instantaneous modulus. It is not a measured aged unloading modulus.
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

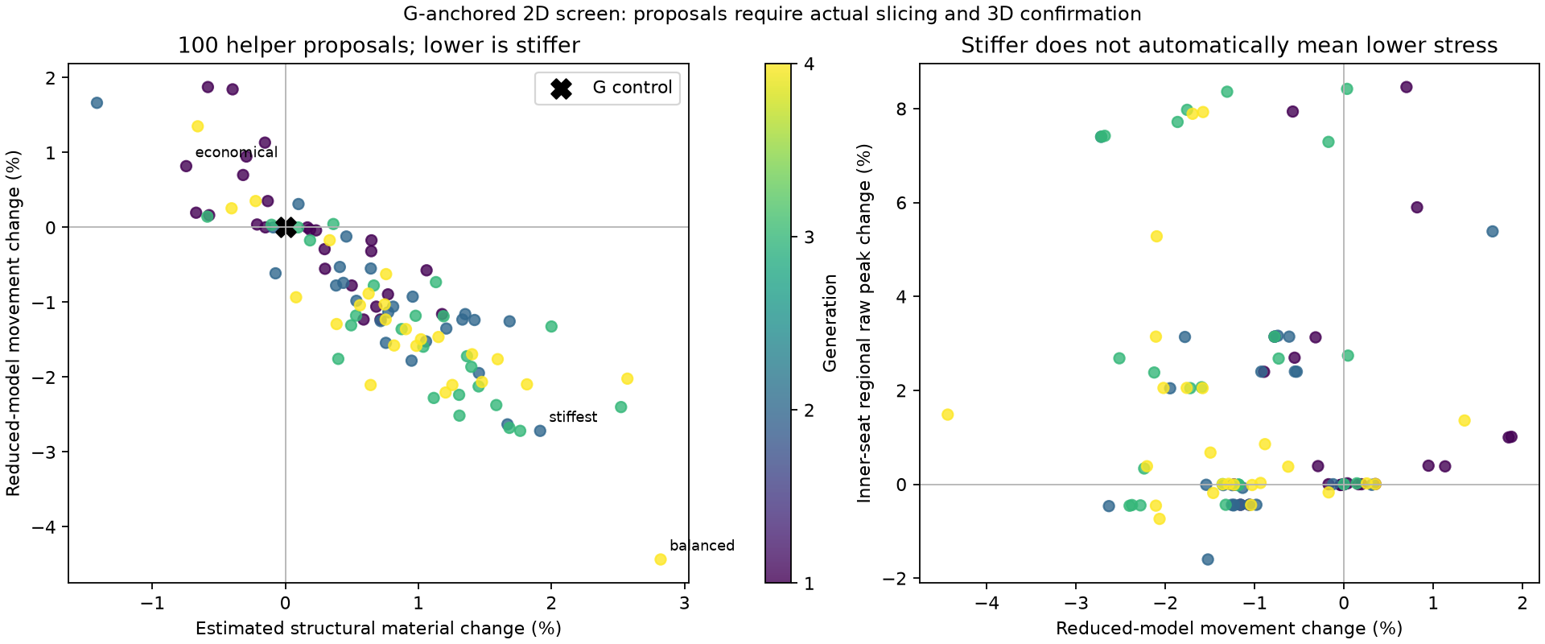
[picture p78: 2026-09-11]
analysis/rev-g2/evolution-results/batch-02/search.png

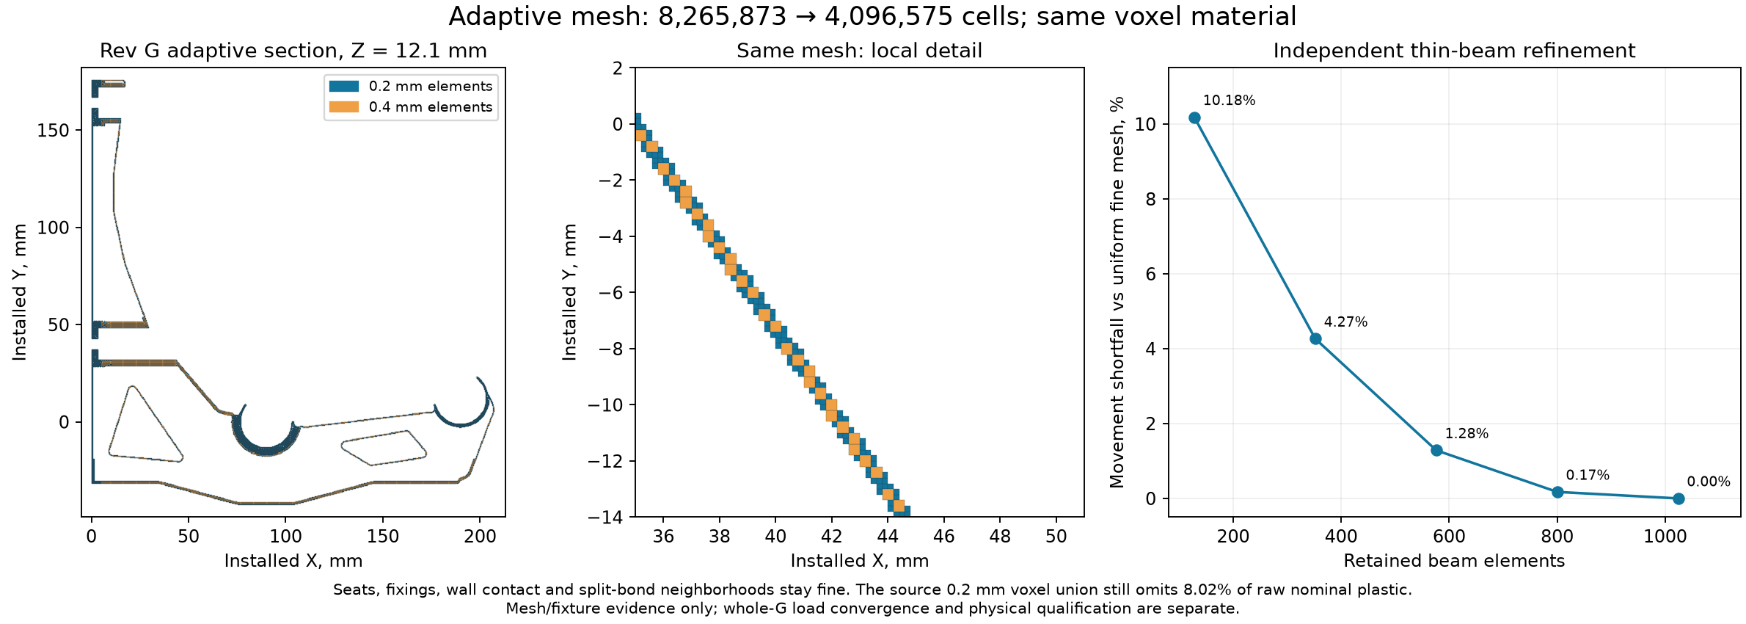
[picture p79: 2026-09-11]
analysis/rev-g2/adaptive-validation/adaptive-mesh.png

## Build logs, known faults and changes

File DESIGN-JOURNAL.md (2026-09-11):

# Historical design journal

Fresh 10.75 / 12 / 13.25 kg G contact checks are documented in [G results](analysis/rev-g2/G-RESULTS.md). One spool changes bracket movement by about 0.452 mm; material accuracy and physical qualification remain open.

These entries preserve earlier reasoning and superseded values. Use the current [engineering guide](README.md) and its linked results for present criteria and conclusions.

## September 11 — continuous brace, thicker controls and recovered originals

Replaced disconnected reinforcement patches with rounded, tapered paths reaching the actual seat/forearm and bearing/keel endpoints. Raw credited layers form one local component on each route; no pores or sacrificial bridges are used to invent connections. CAD verifies body-clipped overlap. Nonetheless, the thin connected helper trial remains much more flexible than G.

Added a direct six-millimetre diagonal between the lower mounting region and keel, retaining the upper-mast relief, fixed interfaces and one-inch moulding underside. In ASA with four walls and 1.6 mm skins, it cuts 27.048% versus a deliberate eight-wall G control. Filling the diagonal with a 100% helper spends 5.406 cm3, leaving 22.492% saving and 2.957 cm3 of reserve before the 20% target. Actual core and adjacent tapered-helper routes each contain all their regional material and endpoint anchors in a single connected component.

The thicker G intermediate contact result is 2.672976 mm / 21.000368 MPa. The reinforced EF intermediate result is 4.981787 mm / 32.195513 MPa. Both retain every stress sample; both miss their bounded 1e-5 check. The EF part exceeds the 4 mm movement allocation and is not a winner. Material omissions remain approximately 4.734% for G and 8.902% for EF. Connectivity and material saving are not enough to demonstrate an effective architecture.

Recovered the actual overnight ASA archive through the existing printer bridge route, with read-only direct transfer after its buffered download stalled. The archive has two brackets, seven walls, 10% base infill and 1.6 mm minimum skins. Its associated downloaded STEP matches E13 byte for byte; the newer downloaded STEP matches G. The saved G PETG project has two walls, 10% infill and all three expected dense helpers, but was saved after the morning job began. The original PETG submission is unavailable: both current printer archive and cached G-code contain a newer PLA profile. The successful physical ASA print therefore must not be called a validated eight-wall G reference. No print, service or printer-setting changes were made during recovery.

Original private archives and job records remain local. Public recovery receipts include selected settings, source hashes and the limits of matching a stripped sliced archive to CAD. Future comparisons should preserve actual submitted files under unique names and separate architecture, wall/skin schedule and polymer.

## September 11 — build E plus F, cut 29%, then reinvest locally

Resolved the crown-moulding interface: preserve the G lower wall corner at
X=0, Y=-32 mm and a horizontal underside for at least 25.4 mm outward. Rod and
mount heights stay fixed. Actual moulding projection is 19.05 mm. No moulding
support is credited by the mechanics model.

Built E's deeper frame with F-derived seat-root backing, retaining exact G
bearing/capture geometry. The first full actual-slice contact screen is
5.660824 mm maximum movement and 39.997226 MPa raw tensile peak, with 11.09%
nominal material omitted by the inscribed 0.2 mm grid. It is worse than G,
despite a small 1.475% extrusion saving; this is not a winning design.

The objective is now a substantial material reserve. Successive actual slices
save 10.977%, 16.851%, then 29.211% of matched G spent extrusion. The 29.211%
cut retains two walls, three 0.2 mm top/bottom layers, a 0.6 mm central helper
plate and reduced broad dense bands. Sacrificial bridges remain spent plastic
with zero stiffness or bond credit.

Added a separate local helper at three stressed transitions identified in the
accepted EF reference: inner seat into forearm, upper brace into wall, and
seat into lower post. The actual slice adds back 6.342 cm3 and retains 20.653%
net saving. Cut-versus-reinforced mechanics are underway. Further material
needed for reinforcement should come from low-stress/low-energy areas, with
new structural and slicing checks. Low stress alone is not an unconditional
permission to remove a connection or print support.

The original strict contact solve and stronger coarse retry failed. Settling
contact first at 1e-4 and then independently checking 1e-5 succeeds. Every
finite stress sample, contact iterate, failed preparation and raw cache is
preserved. See `analysis/rev-g2/EF-RESULTS.md` for the current result rather
than treating historical failure fields as predictions.

## September 11 — reopen the outer body and finish the local pilot

The helper-only pilot was too narrow for the architecture objective. The next
study varies the actual body, depth, braces, windows and through-width material
arrangement. Rod and mounting positions are fixed again. The matching bottom
corner and 15 mm outboard relationship are required, with their exact datums
pending. The old local silhouette floor is not an imposed search boundary.

Published [six reproducible XY body sketches](designs/rev-g2/shape-seeds/README.md):
open triangular frame, curved braces, deep keel, independent arms, seat portals,
and reshaped shear panels. All are connected in projection, add and remove
substantial projected area relative to G, and pass the nominal spool-clearance
sweep. They are unbuilt concepts: CAD, arbitrary helpers, sliced mass, actual
connectivity, manufacturing checks and mechanical ranking remain unfinished.

The local helper pilot's final same-material mesh check is complete. Releasing
adaptive constraints changes its leader from 4.129457 to 4.154745 mm maximum
movement. All 10,234,400 fine-node displacements are compared; maximum nodal
change is 0.025293 mm. The raw tensile peak moves and changes from 20.429187
to 19.679217 MPa; all 67,740,528 uniform-mesh samples are retained. Preparation,
solve/export, audit and comparison take 318.10 active seconds. The 8.12% boundary
material omission persists. This supports the pilot's local movement screen;
small stress differences and transfer to broad architectures remain unresolved.

The second stiffness candidate failed its bounded retry as well as its initial
solve; total active treatment including both audits was 9 min 55 s. No failed
field is promoted to a prediction. All evidence remains preserved in the
[completed loop record](analysis/rev-g2/EVOLUTION.md).

## September 11 — staged evolutionary screening pilot

Established a bounded local helper search around G: paired intuition seeds,
four generations of 25, 5–10% quantized mutations, recombination and independent
exploration. The corrected raw-volume 2D baseline is retained; new helper
responses are explicitly approximate and require real slicing and 3D feedback.
All 100 new proposals passed reduced equilibrium and retained every stress
cell in 677.87 s. A preliminary rounding-policy failure is preserved separately.

The first actual finalist completed CAD, P1S PETG slicing, material mapping,
adaptive GPU contact and all-field audit in 414.80 s. It gives 4.129457 mm
maximum movement, versus 4.335468 mm for the fresh process control. Its raw
peak is 20.429187 MPa versus 20.024198 MPa for the control, and the peak moves
to another location. The movement estimate was close; the cheap global stress
score missed the increase. This supports staged confirmation, not automatic
acceptance of reduced-model winners.

The fresh process check exposed a parser omission: Orca's P1S `0x2` nozzle
offset must be restored before model placement is inverted. The fix leaves
every historical neutral-reference path array identical. Earlier P1S caches
and the failed default-grid-budget attempt remain preserved. No stopped CPU
tetrahedral meshing job restarted. See [the loop record](analysis/rev-g2/EVOLUTION.md)
for subsequent finalists, mesh refinement, evidence and current limits.

## September 11 — G contact results and a measured numerical tolerance study

Implemented exact material-integrated Galerkin coarse correction and a GPU
V-cycle; independent operator, direct-solve beam and changed-load contact
fixtures pass. The original full-G residual gate delayed all wall-contact
updates. Keeping that gate explicit, a 1e-5 intermediate solve tolerance
allowed 28 contact steps to settle in 734 seconds. Rechecking at 1e-6 took
72 seconds and changed no original-node displacement by more than 4.894e-7 mm
and no retained stress component by more than 5.527e-5 MPa.

At 12 kg the retained-material screen gives 4.335477 mm maximum movement and
20.025374 MPa raw tensile stress. It has no wall penetration or tensile active
wall reactions. This model exceeds the 4 mm bracket allocation, but its 8.0177%
material omission, idealized hardware and unmeasured isotropic material law
prevent a printed-part pass/fail qualification. The raw peak remains unconverged
with respect to mesh/material representation. All G stress samples and failed
attempts survive. The coarser mesh trial failed linear convergence.

[Results, fresh spool-load checks, evidence and next accuracy gate](analysis/rev-g2/G-RESULTS.md).
Existing G STEP/helper exports are reused; G2 architectures remain unbuilt.

## September 11 — adaptive constraints, finer boundaries and bounded whole-G trials

Implemented two-level hex coarsening with Q1 hanging-node constraints and a
matrix-free CUDA `P.T K P` operator. Independent scikit-fem, affine/rigid,
Dirichlet and bending fixtures pass. Real G exposed a partially connected edge
case; its initial rejection is retained and split-bond neighborhoods now stay
fine. Protecting those neighborhoods plus seats/fixings/wall contact reduces
8,265,873 cells to 4,096,575 without changing the eroded material union.

The 1,000-iteration and subsequent 12,000-iteration GPU trials failed linear
equilibrium convergence. Complete failed fields and every raw stress sample
survive; neither failure yields a movement or strength result. A useful coarse
correction/preconditioner is still required. No old CPU meshing job restarted.

A separate geometry-only boundary census reaches 0.025 mm XY with 1.10% raw
material omission using 11.75 million prisms before grading, versus 568.79
million uniform fine cells. Multilevel constraints and mechanical refinement
remain unfinished; this is not a solve-time speedup measurement.

An actual installed P1S/Generic PETG slice completed in 2.67 s. Bambu G-code
comment aliases preserve the historical parsed arrays exactly. An initial
footer accounting rejection was traced to 75.526 mm3 of startup priming lines;
counting that spent, nonstructural plastic passes the unchanged accounting
gate and enables a fresh raw shape. Historical neutral slices remain separate.

[Full evidence, failures, limitations and reproduction](analysis/rev-g2/ADAPTIVE-MESH.md).
G's existing aligned STEP/helpers and all seven unbuilt G2 concepts retain
their prior status. No preferred or physically qualified prototype is added.

## September 11 — test the free GPU route on real hardware and raw slices

Installed Warp 1.17.0 in an isolated WSL environment and verified its explicit
Apache-2.0 license and tagged upstream example hash. The DTU snapshots did not
establish reuse permission and were not incorporated. The upstream nonlinear
2D example passes CPU/GPU agreement after an explicit tighter CG tolerance;
the default-tolerance failures remain preserved with full fields.

A new matrix-free GPU Q1 hex adapter passes independent analytic stress/energy,
rigid-motion, scikit-fem operator/displacement, 0.4 mm hollow-wall and 3D
nonzero-gap opening/closing/release contact fixtures. It gives no void or thick
bridge stiffness and splits edge/corner-only nodal bonds. All finite Gauss
stress samples and raw sampled peaks are retained.

An 8x8x24 mm crop of G's actual raw two-wall/five-skin-layer material passes
manufactured GPU patch tests at 0.4, 0.2 and 0.1 mm XY spacing. The finest has
198,853 cells, takes 0.437 s for its patch solve and reaches 117.2 MiB in the
CUDA allocation pool. These surface-prescribed patch timings do not predict
whole-bracket or long-beam performance. Conservative voxelization still removes
17.12%, 8.37% and 4.31% of the crop, respectively; this representation is not
accepted for G. Geometry/bond preservation and preconditioning are next.

[Complete evidence, failures and reproduction](analysis/rev-g2/GPU-VALIDATION.md).
No corrected G 3D load solution or new G2 CAD candidate is claimed. Existing
STEP/helper handoffs, earlier numerical evidence and stopped CPU meshing jobs
remain preserved.

## September 11 — correct slicer-to-FEM material mapping before G2

The long whole-part CPU tetrahedral meshing attempts were stopped without an
accepted G mesh. The next route is GPU voxel/immersed FEM. A
[primary-source software review](analysis/rev-g2/GPU-FEM-REVIEW.md) distinguishes
existing GPU applications, published elasticity kernels and incomplete research
frameworks. No replacement solver or GPU result is established yet; the raw
slicer-material representation and earlier failures remain preserved.

The five-case shape validation is now complete: 50,000 independent
variable-width capsule occupancy samples and through-thickness checks agree
within the explicitly bounded polygonization uncertainty. All effective
wall/skin settings, zero base infill, three 100% helpers, unchanged G geometry
hashes and P1S bed/exclusion checks pass. Raw slice evidence is archived.

Sliced structural material, including few-wall/many-skin and reverse cases

The reference cache loads in about 1.6 seconds; 10,000 occupancy queries take
about 0.06 seconds on the analysis machine. Nominal footprint volume and
extrusion E accounting remain separate. Boundary-only TetGen reproduces the
continuum volume and cavities, but the independent topology/quality audit
rejects it for mechanics. A bounded-envelope mesher is being checked next.
[Validation and current state](analysis/rev-g2/README.md).

The hand-built G shell/core and one-direction footprint coverage audit did
not establish equality with emitted material. The current recheck uses the
same body and helpers, zero base infill and two walls minimum. A two/eight-wall
by two/eight-skin-layer matrix tests the new representation. Thick 0.4 mm
bridge paths remain in plastic use but receive no structural credit.

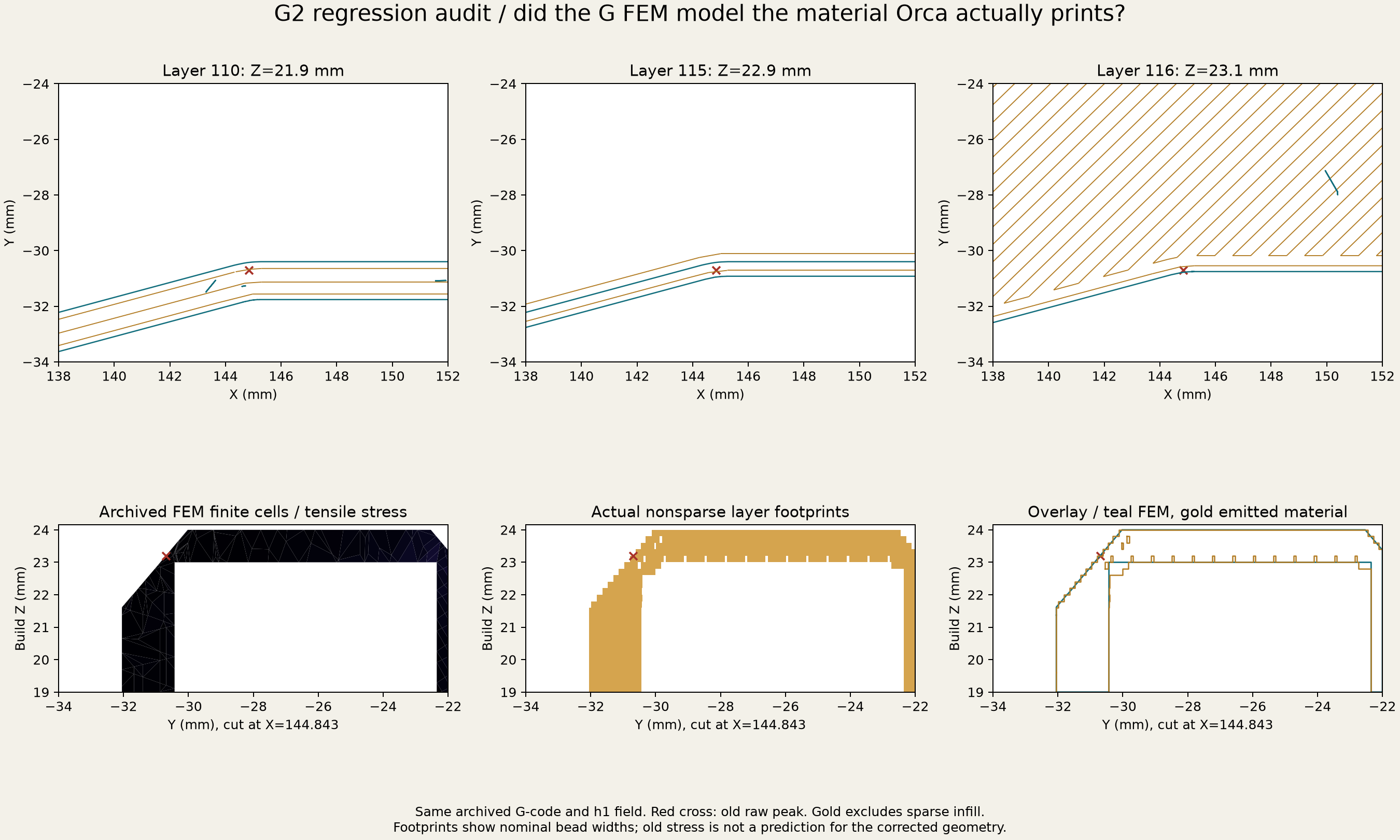
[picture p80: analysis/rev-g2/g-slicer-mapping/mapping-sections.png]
Archived G paths compared with its former FEM section


This initial overlay is diagnostic; it is not a corrected strength result.
The broad architecture brief also supersedes the draft's fixed rail/fixing
positions and local E13 silhouette constraint. [Current brief](G2-BRIEF.md).

## Post-G — September 11 design envelope

Replaced exact exterior preservation with an explicit admissible volume and
functional fit/retention/mounting requirements. The underside may extend up
to 8 mm below its current local profile, with an absolute floor of Y=-51 mm.
Material may be removed anywhere; walls, skins, plates, ribs and windows are
variables. Helpers have no fixed count, shape or placement; their union is
clipped to the body before mass and toolpath checks.

Design envelope and permitted underside growth

The envelope builder verifies accepted removal/addition probes and rejects
excessive drop and wall penetration. No expanded optimization or new bracket
qualification has run. [Contract and evidence](designs/design-envelope/README.md).

## Rev G — repeatable genetic study completed; no accepted finalist

Implemented a cached canonical plane-stress evaluator and seeded integer
genetic search. Four uncached reference cases reproduce the existing full
fields. Two broad-family seeds plus a full-plane family informed by 3D
failures evaluate 1,458 distinct parameter sets; two cached search replays
reproduce complete population ledgers and selections exactly.

Actual Rev G CAD

The thin first-seed candidate slices to 84.35 g but fails movement, raw 3D
strength and dense-path coverage. The full-plane feedback candidate uses
103.76 g, 37.9% less than E13, with 3.246 mm vertical movement at E = 1 GPa
on h1. Matched stiffness per gram improves 6.6%. Its 3D tensile peak rises
32.29 → 37.99 → 55.05 MPa across h2/h1.5/h1, so it fails the 4× nominal
fracture screen. The final peak is beside a preserved E13 exterior chamfer.
A wider inner-seat support variant costs 108.03 g and improves coarse
movement to 2.988 mm, but remains rejected on strength.

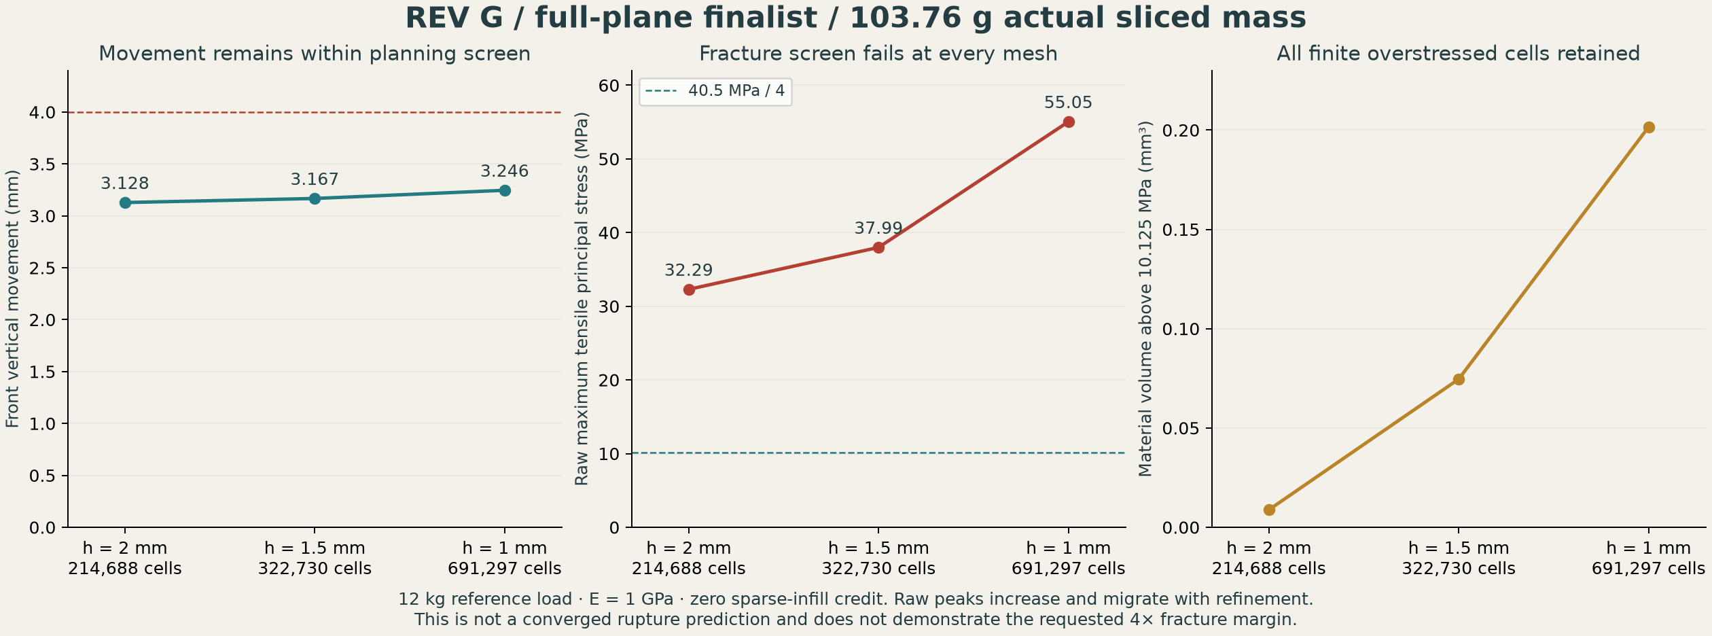
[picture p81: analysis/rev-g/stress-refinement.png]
Three-mesh stress and movement evidence


The F light-helper connectivity failure is repaired without changing its
printed density domain; it now slices to 93.76 g, while its original F
strength failure remains. Full-plane G and wider-seat toolpath gates pass.
Quadratic buckling is benchmarked and reported separately from fracture.
All finite stress fields, failed constraints and source hashes are retained.

No tested G finalist is computationally accepted or physically qualified.
The search sprint is complete under its explicit no-feasible-finalist outcome;
E13 stays the established prototype handoff. The next study must resolve
local geometry and material behavior before claiming a fracture margin.
[Rev G evidence](analysis/rev-g/README.md) · [CAD](designs/rev-g/README.md)
· [F checkpoint](REV-F-CHECKPOINT.md) · [Next study](NEXT-SPRINT.md).

## Rev F — September 10 checkpoint; evolutionary search next

Added two angular windows inside E13's unchanged exterior outline and protected
functional interfaces. Explored shaped internal planes and three precise infill
helpers with selection tabs outside the body. The three-wall shaped and
four-wall full-plane packages pass geometry and real Orca toolpath checks;
external tabs do not print.

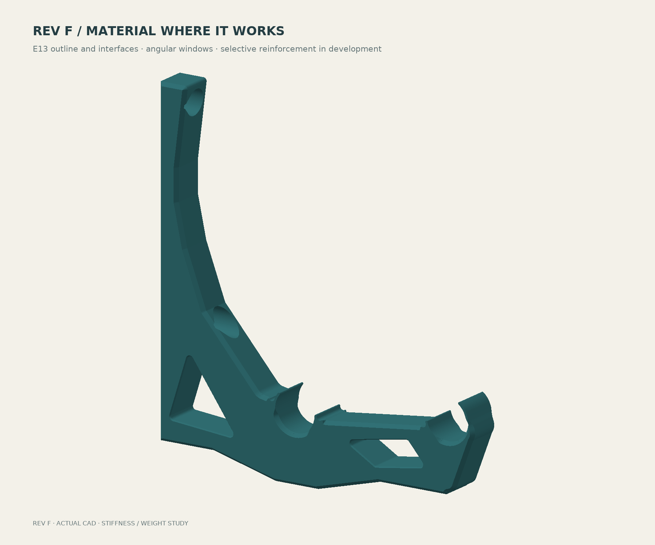
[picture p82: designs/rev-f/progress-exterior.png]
Rev F actual CAD checkpoint


The four-wall full-plane slice uses 147.02 g versus E13 eight walls at 167.11 g
(neutral 1.24 g/cm³), with 2.1565 mm versus 2.1480 mm front movement at E = 1 GPa
on matched h1 meshes. The objective was then clarified to minimum mass within
5 mm total movement, 1 mm change per spool and 4× nominal fracture margin;
matching baseline stiffness is no longer a constraint.

The new one-wall light candidate estimates 87.81 g and gives 3.582 mm bracket
movement in 3D, but its conservative raw-peak strength ratio is only 0.85.
Its modifier STL connectivity check also fails, so its mass remains unsliced.
No Rev F candidate demonstrates the required 4× fracture margin. All finite
peaks and the checked fields are retained in the checkpoint.

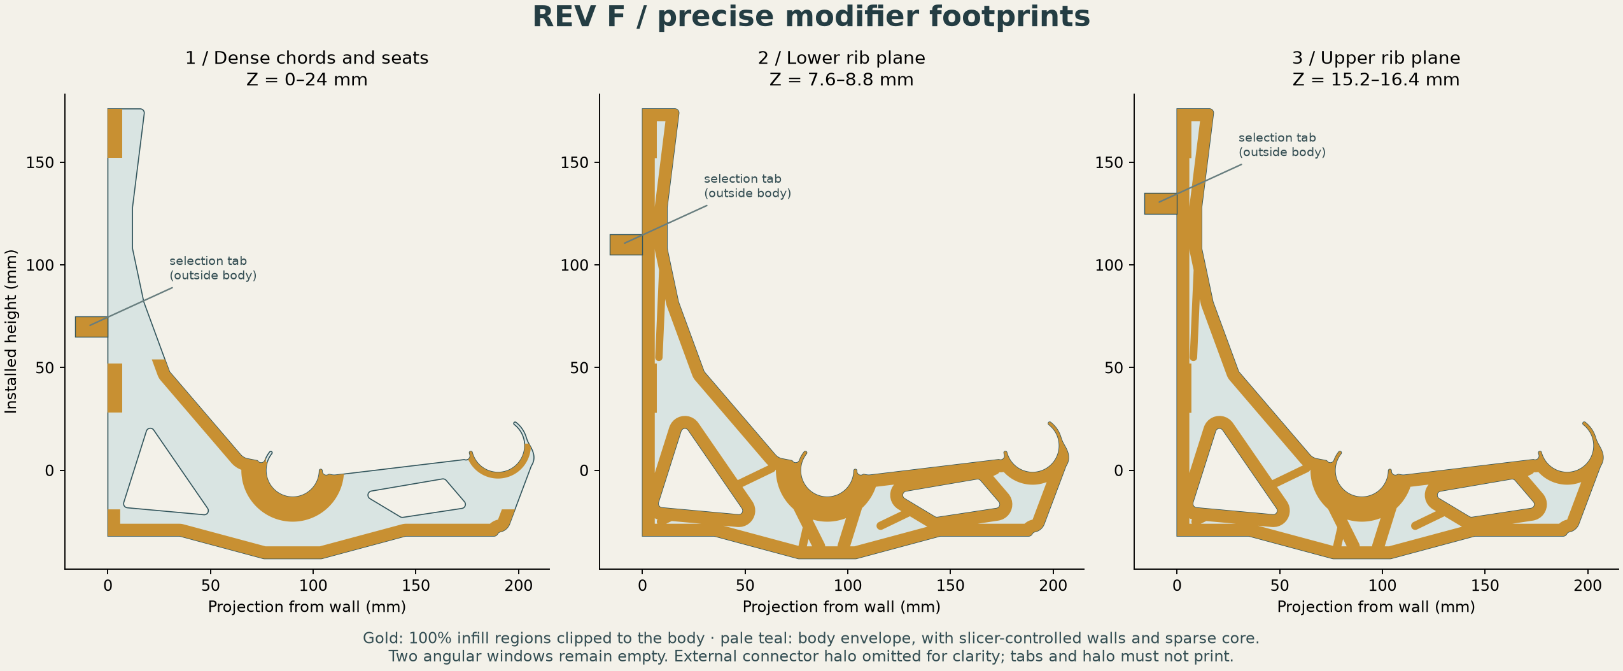
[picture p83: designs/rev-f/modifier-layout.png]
Three local modifier regions and selection tabs


The incomplete-native-project Orca CLI crash was traced to missing preset
metadata on the wrong import path; truthful model-only metadata and fixed
orientation now pass repeated slicing. E13 remains the established prototype
handoff. [Rev F status and evidence](analysis/rev-f/README.md) ·
[Experimental CAD](designs/rev-f/README.md).

**Next sprint:** a seeded evolutionary optimizer with cached candidate results,
actual Orca mass and hard serviceability, 3D strength and manufacturing gates.
No optimizer is implemented in this checkpoint. [Archived sprint brief](REV-G-SPRINT-BRIEF.md).

## E13 — angular reinforcement and finer stress meshes

Replaced the broad curved underside with straight 11 mm-deep flanks into a
short flat, 1.5 mm deeper than E12. Small corner blends keep the faceted look.
The 207.51 × 219 mm body retains the fingers, relief pockets, rigid shoulders,
mirrored 50-degree finish, screw geometry and four continuous plates.

Angular E13

Outline change

The matched reduced model improves near-seat stress by 12–13% versus E12,
40–41% versus E10, with about 16% less movement than E12. Three new global mesh
levels per wall count and two new fine E12 baselines assess the rest of the
stress field. Raw peaks and their cell locations/volumes are retained; the
package does not claim all stress concentrations have disappeared.

Refined stress sections

Current front coefficients are K=2147.972 MPa mm (8 walls) and 1936.610 (10).
All ten 3D fields pass independent residual, force and moment checks; geometry
and both OrcaSlicer path audits pass. Physical fit, insertion, loaded movement
and sustained/hot qualification are the next steps. No lifetime rating is
assigned. [Current guide](README.md) · [Hotspot evidence](analysis/e13/HOTSPOTS.md).

## E12 — one-quarter protrusion, most of the measured benefit

Reduced the added underside depth from 38 to 9.5 mm, meeting the preferred
one-quarter target and the one-third maximum. A broader smooth blend produces
an approximately 28.5 mm inner-center section and 207.51 x 217.50 mm print
footprint. The fingers, relief pockets, R6 rigid shoulders, 50-degree mirrored
finish, hardware and four continuous plates remain. No relief holes were added.

Quarter-depth E12

Depth tradeoff

The explicit compactness requirement supersedes E11's adjacent-section margin
criterion. The finished seat still improves over E10, but no longer exceeds
both neighboring reference bands. Matched near-seat stress is 31.7-32.5% lower
than E10 and front movement is only 5.6-7.1% higher than E11. The outer-only
near-seat statistic improves about 35% over E10.

All E12 3D/material/landing results were rerun. Fine front coefficients are
K=2472.537 MPa mm (8 walls) and 2241.876 (10 walls). The accepted fields pass
independent residual/force/moment gates; rejected 10-wall mesh attempts are
recorded. Both OrcaSlicer audits pass the solid-band, wall and finger checks.

Updated E12 stress sections

Next: configure the aligned helpers for the intended filament, verify actual
rod fit and print the prototype, then measure immediate/sustained/hot movement.
No physical or lifetime rating is claimed. [E12 guide](E12-ENGINEERING-GUIDE.md) and
[complete numerical results](analysis/e12/RESULTS.md).

## E11 — strong inner seat, 50° chamfers and refreshed FEA

Deepened the underside beneath the inner rod by 38 mm, giving approximately
57 mm center section depth. The smooth underside and R6 rigid-shoulder blends
restore the reduced bending section while retaining the functional snap sectors,
relief pockets, rail centers and hardware. The minimum seat-band bending I is
1.539 times the stronger adjacent plain-arm reference; elastic section modulus
is at least 1.282 times that reference. Both reference bands include the new
underside runouts.

The 2 mm face inset now rises 2.384 mm at 50° above the bed, mirrored on the
opposite side. Independent STEP probes measure the angles. Complete flexible
finger sectors match E10 through nine print depths. Delivered STEP solids,
closed STLs, hardware access and the 322-case nominal spool sweep pass; minimum
clearance is 3.927 mm.

E11 finished geometry

Matched E10/E11 reduced FEM gives 37.4–37.6% lower near-seat stress and
35.1–35.5% less front movement. The outer-rod-only diagnostic lowers stress
under the unloaded inner seat by 43.5%, supporting reduced-section bending.
New E11 8/10-wall 3D solves include the finished geometry and contact restraints;
their refined K values are 2306.334 and 2098.156 MPa·mm. Material movement,
creep sensitivities, screw demand and the landing submodel are all updated.
Rejected numerical fields and topology cleanup are explicitly audited.

E11 solved stress sections

Actual OrcaSlicer 2.4.2 audits verify 120 layers, all four intended solid bands,
and continuous seat-wall footprints at 8/10 walls. These are nominal path checks,
not calibrated printer profiles. The new print footprint is approximately
207.51 × 246.00 mm. The concrete next step is to configure the delivered helpers
in the intended filament profile, check measured rod fit, print the prototype
and run the stated immediate/sustained/hot movement checks. No lifetime spool
rating is assigned. [Archived E11 guide](E11-ENGINEERING-GUIDE.md) and [full results](analysis/e11/RESULTS.md).

## E10 — continuous chamfers after filleting

Replaced the repeated stop/start bevel patches with continuous 2 mm chamfers around the pre-filleted body. Only the thin dowel-retainer regions use runouts. Mirroring the finished half makes the two broad-face treatments identical. The source profile, 12 mm rail lift, fasteners and modifier bands remain unchanged; E9 FEM is explicitly a prior-finish baseline.

The exported STEP contains three valid solids and passes hardware clearance. Verification includes 726 chamfer material probes over 121 representative segments, full depth at ten structural junctions and eight finger-material checks. The STL exporter omitted four microscopic tessellation triangles; closing those pinholes yields closed meshes and does not alter the STEP.

The supplier audit confirms Lowe's publishes 1-inch actual diameter for the Madison Mill poplar/oak rods, but the checked retailer and manufacturer pages give no numeric diameter or ovality tolerance. The 26 mm seat remains provisional. Added full-width rear/front fit coupons, each with aligned helper modifiers, and a measurement/fit plan. No physical measurements or fit tests have been performed.

E10 continuous finish

## E9 — raised-front running prototype

Adopted the +12 mm front rail as the current prototype. The rear center stays at (90, 0), front center becomes (190, 12), and both retainers rotate to the new contact directions. The back arm moves inward while retaining full-height wall contact; the front buttress meets the original base rather than leaving a stub.

Reduced both broad-face chamfers to 2 mm and verified them on nine structural edges using mirrored material-presence probes. Kept nominal R2 exposed wall-facet blends and smooth chamfer runouts before small features. The 322-case 180–220 mm spool sweep gives 3.93 mm minimum nominal clearance. STEP, closed meshes and fastener access checks pass.

Rebuilt the analysis material domain from the finished E9 CAD, including matching chamfer reinforcement, four 1.2 mm plates and zero sparse-infill credit. New 2D/3D fields and a 500 N upper screw-landing submodel are under [analysis/e9](analysis/e9). The main README holds current calculated margins; the [E8 guide](E8-ENGINEERING-GUIDE.md) remains an explicitly archived level-rail baseline.

E9 verified drawing

Physical slicing, fit and sustained/hot load qualification remain necessary before assigning lifetime spool ratings.

# Spool wall rack

A wall-mounted filament rack using nominal 1-inch wooden dowels. The bracket prints on its side so continuous L-shaped plates carry the principal bending load in the layer plane. Spools must slide across bracket locations without contacting the plastic.

**Current prototype: E8 — a solid STEP body with two helper solids for 100% infill modifiers.** The user chooses wall count and infill for the body. The slicer generates sparse support between the internal solid bands; no infill grid is modeled in CAD.

**[Download the STEP assembly with helpers](designs/closed-wall-e8/bracket-with-modifier-helpers.step)** · [Slicer setup and dimensions](designs/closed-wall-e8/README.md).

E8 modifier locations

## Engineering analysis in progress

The full-bracket 2D/3D stress and creep study now includes the screw landings: rack pull/prying and washer compression from tightening are separate load cases. [Analysis checkpoint](analysis/e8/STATUS.md). The printable E8 geometry remains the current prototype while those results are checked.

## Design journal

Latest checkpoint: **Prototype wall-count starting points are 8 for PLA and 10 for PETG**, with both helpers at 100% infill. For the assumed 0.42/0.45 mm line widths and 0.2 mm layers, these correspond to approximately 3.3 and 4.1 mm perimeter thickness. They are test settings, not a verified load or creep rating.

### Wall counts — map the slicer setting to actual section

Six walls approximately recover the old 2.4 mm nominal perimeter; nine approximate the earlier 3.6 mm proposal. The current body still has the 28 mm arm depth. Selected 8 PLA / 10 PETG as starting settings with additional section margin. A simple local forearm comparison gives about 0.22 / 0.27 mm initial vertical movement respectively at the 12 kg bracket target, using typical reference moduli. That is not a whole-bracket or long-term prediction. Actual sliced thickness and the changed mounting connection still govern.

[Wall-count mapping, assumptions and limits](designs/closed-wall-e8/WALL-COUNTS.md).

### E8 — solid body plus modifier helpers

E7's compartment lattice recreated infill in CAD and increased modeled material by 42%. Replaced it with a solid exterior/functional body and two simple helper slabs at print Z = 7.6–8.8 and 15.2–16.4 mm. The user selects body wall count and infill percentage, then changes both helper parts to 100% infill modifiers. With 1.2 mm top/bottom settings, this retains the intended four solid planes while the slicer supplies sparse support between them.

The STEP preserves named component geometry and alignment. It does not carry modifier status or print settings. The helpers extend 2 mm beyond the body projection and must be converted to modifiers before slicing. The final package also includes three aligned STL files as an import fallback.

E7's fastener changes remain: 3.6 mm clamping lands, Ø5.2 mm shank clearance, Ø16 mm nominal access and the raised lower screw axis. The body no longer has a prescribed 2.4 mm CAD shell; actual wall thickness follows the user's slicer settings. Old hollow-section calculations do not establish the capacity of this print setup.

[STEP handoff and setup](designs/closed-wall-e8/README.md) · [Roundtrip and hardware checks](designs/closed-wall-e8/verification.json).

### E7 — compartment the voids and recess the fixings

Added 1.2 mm dividing walls within each air band, retaining all four continuous load-plane plates. Full cells have R2 corners and a 10 × 10 mm clear bounding box, limiting any straight geometric span to 14.14 mm. The three bands contain 106 / 97 / 106 cavities after local keepouts. This gives the internal plates short roofs to bridge; it does not establish actual sliced bridge direction or print quality.

Replaced the long screw bores with flat washer seats 3.6 mm from the wall. Ø5.2 mm clearance accommodates #8/#10 wood screws and nominal M5 shanks; M5 is the tighter printed fit. The Ø16 mm nominal access opening accommodates the checked Ø13 mm washer and a Ø15.8 mm straight driver envelope. Its 45-degree roof shoulders and short rounded cap avoid another long flat internal ceiling.

Raised the lower screw axis from Y = 12 to 40 mm to clear the rear dowel seat during installation. The upper stays at 164 mm. Removed the old projecting lower screw pad. Both washer landings support approximately 99.1% of the checked annulus. The full-height wall contact and compact exterior envelope remain.

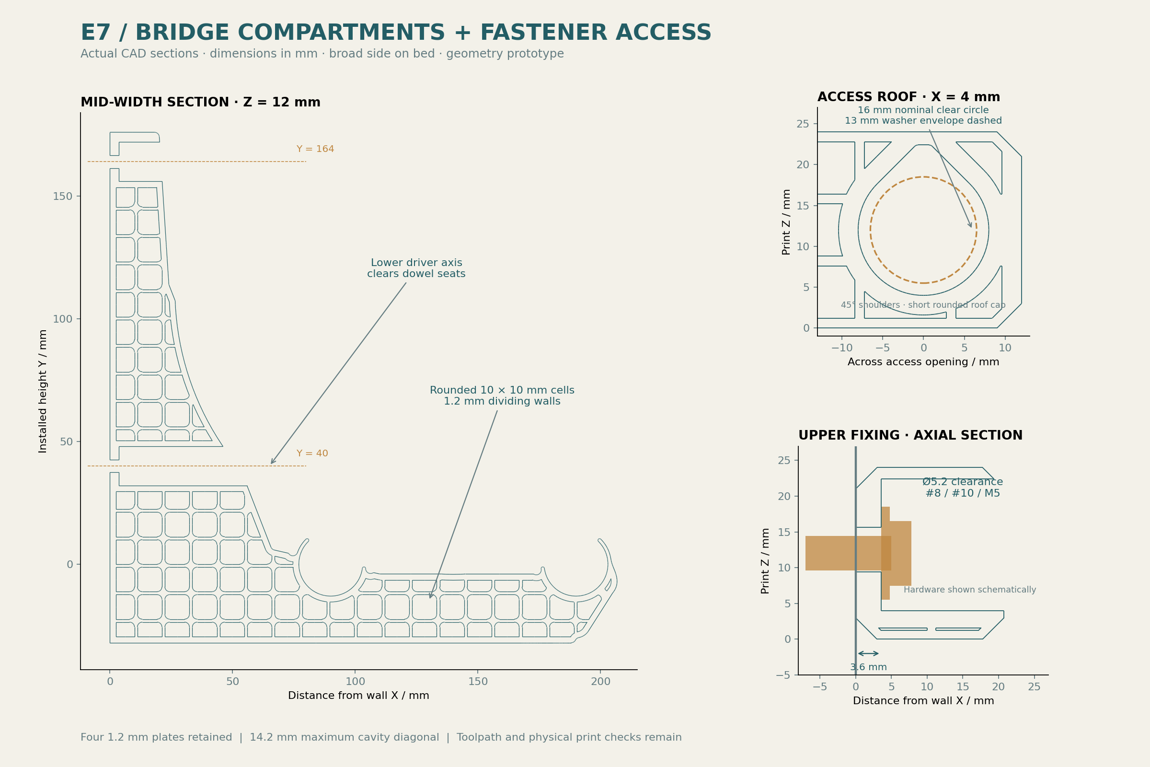
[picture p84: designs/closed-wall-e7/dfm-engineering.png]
E7 fixing and compartment sections


Solid volume increases from 94.3 to 133.8 cm³, approximately 42%, including the compartment walls and access reinforcement. The separate 34 mm arm-depth proposal is not incorporated. E6's load calculations do not validate the changed E7 connection, and the manufacturing dividers receive no assigned strength credit.

[DFM revision, dimensions and rebuild instructions](designs/closed-wall-e7/README.md) · [Actual geometry checks](designs/closed-wall-e7/dfm-verification.json).

### Additional section for PLA or PETG

A thicker perimeter alone gives a modest benefit: increasing 2.4 to 3.6 mm at the original arm depth increases ideal section I by 23%. Pairing that with a depth increase from 28 to 34 mm gives approximately 100% more I. Keep the spool bearing track and flexible fingers fixed, add depth below the arm, and carry the increase smoothly through the knee. The extra depth would cost approximately 6 mm of loaded rack height.

The current PETG reference needs 41% more I to match the original ASA initial bending stiffness. The proposed section exceeds that requirement. PLA already has similar reference stiffness to ASA; added section would reduce working stress and provide deformation margin. The required long-term creep allowance remains unestablished for both. These are section estimates, not whole-bracket stiffness or material-specific spool ratings.

[Sizing comparison, equations and limitations](designs/closed-wall-e6/MATERIAL-SIZING.md) · [Reproducible results](designs/closed-wall-e6/material-sizing.json).

### Material cases — PLA, PETG, ASA and PA6-GF

Expanded the final-CAD section check from the midpoint to ten knee/forearm stations and included outward seat forces for 180–220 mm spools. At the 12 kg design target the largest sampled nominal stress is **3.47 MPa**; linear scaling gives 6.93 MPa at the proposed 24 kg proof load. These are screening stresses, not local peaks or material allowables. The higher knee/near-seat demand supersedes relying on the earlier midpoint figure alone.

| Material | Decision for the 85°F / 100°F cases |
|---|---|
| PLA | Initially stiff; least thermal headroom among the reference grades. Monitored creep trial before any unattended full-row recommendation. |
| PETG | Candidate; lower reference bending stiffness. Sustained-load behavior needs measurement. |
| ASA | **First full-load prototype choice** for thermal headroom and the integrated unfilled snap geometry; not yet creep-qualified. |
| PA6-GF | Evaluate annealed dry and moisture-conditioned states. Reference wet bending stiffness is about one-third of dry; snap behavior needs separate qualification. |

The 12 kg target covers the 10.58 kg continuous-support estimate at 60 mm spool pitch with a 1.42 kg budget for self-weight and variation. This is a target, not a verified capacity or bound on arbitrary installations. Both temperature cases retain full load; the hot hours are not averaged away. The material study includes sourced reference data, a 1,000-hour screening trial, six-hour hot exposure and proposed movement criteria. It does not infer multi-year life or assign safe spool counts from tensile strengths or HDT.

[Full material assessment and qualification cases](designs/closed-wall-e6/MATERIAL-CASES.md) · [Computed cases](designs/closed-wall-e6/material-work-cases.json) · [Reference data and sources](designs/closed-wall-e6/material-reference-data.json).

### 16-inch support spacing — service load case, not a rating

E6 is not yet cleared for a fully loaded installation. For six full spools per 406.4 mm bay at an assumed gross mass of 1.25 kg each, the bay carries 7.5 kg. Six per bay requires a pitch no greater than 67.7 mm; spools can straddle bracket locations because the bracket does not interrupt the bearing track.

An interior support between simply supported bays carries about one bay's load. Continuous dowels across two equal, uniformly loaded bays place 1.25 times one bay's load on the middle bracket: **9.375 kg equivalent**, before dowel weight and handling loads. This factor describes that beam case; it is not a safety factor or a universal maximum. At 60–70 mm spool pitch, the same continuous-span estimate ranges from approximately 9.1 to 10.6 kg at the middle support.

The six-spool example produces approximately 12.9 N·m at the wall and an idealized 66 N upper-screw tension demand. A sampled arm midpoint has approximately 1.85 MPa nominal combined stress, including the outward seat force. Those numbers omit critical local concentrations, other sections and creep; they are not allowable loads. The 1-inch dowel calculation gives approximately 0.22 mm instantaneous resultant deflection using an explicitly assumed 8 GPa wood modulus. Purchased dowel properties remain unidentified.

The material study above now specifies the temperature envelope and four reference filament cases. Final grade, actual spool mass/pitch, wall fasteners and rail end conditions still need confirmation for an installation rating. Internal-roof printing remains unresolved. [Inputs, equations and limitations](designs/closed-wall-e6/check_16inch_loading.py) · [Calculated demands](designs/closed-wall-e6/loading-16inch.json).

### E6 — shorten the span, retain arm depth, use the upper spool envelope

Moved the rail centers from 76/226 mm to 90/190 mm from the wall, reducing their spacing from 150 to 100 mm. That lets the arm rise under the spool while retaining approximately 28 mm of depth. Rotated both retainers to match the new spool contact directions, keeping their rigid bearing sectors opposite the contact. Minimum nominal flange clearance is 3.48 mm across 180–220 mm spools.

The back now lies in one wall plane from the arm underside at −32 mm to the top at +176 mm. Small square lands at the wall-side ends remove the old clipped toe; the exposed edges keep their finishing treatments where space permits. Chamfers leave an 18 mm-wide central wall-bearing face, interrupted by the screw holes. Actual contact pressure will depend on wall flatness and fastening; geometric contact does not imply uniform bearing.

Raised the upper fixing from +138 to +164 mm. Screw spacing increases from 126 to 152 mm while the bracket remains below the top of even the 180 mm reference flange. This uses otherwise empty space beside the spool to preserve the mounting lever arm. The four continuous 1.2 mm plates and 2.4 mm modeled perimeter remain.

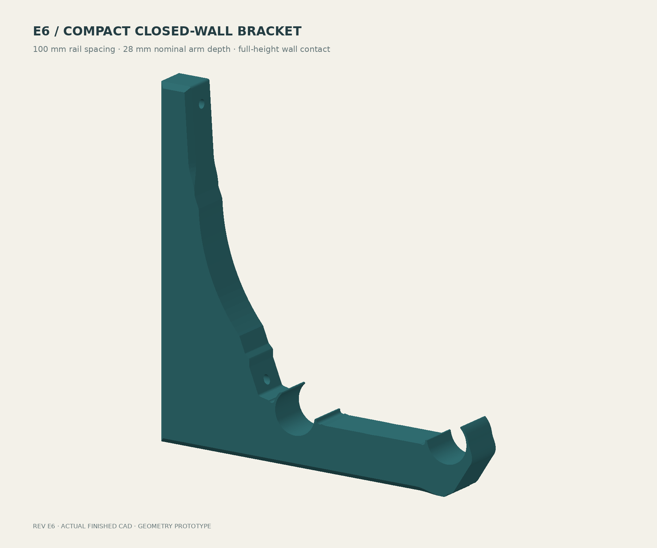
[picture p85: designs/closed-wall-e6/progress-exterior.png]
E6 finished CAD


| Geometry | E4 | E6 |
|---|---:|---:|
| Rail spacing | 150 mm | 100 mm |
| Bracket height | 239 mm | 208 mm |
| Bracket projection | 244.24 mm | 206.73 mm |
| Extension below a 200 mm spool | 72.7 mm | 32.7 mm |
| Loaded envelope, 200 mm spool | 272.7 mm | 232.7 mm |
| Screw spacing | 126 mm | 152 mm |
| Midspan arm depth | 35.2 mm | 27.9 mm |

**Mechanical screening:** E6's midpoint section has 59% of E4's second moment of area, but the span falls to two-thirds. A uniform-beam estimate based on that midpoint section gives approximately twice the forearm stiffness through the `I/L³` relationship. This is a screening comparison, not a prediction of complete-bracket stiffness: the actual varying sections, snap roots, wall leg and mounting connection remain to be analyzed. An idealized upper-screw tension calculation gives approximately 4% lower tension for the same total vertical load.

**Handling tradeoff:** closer rods create a shallower cradle. For the 200 mm reference spool, the ideal center-of-mass rise to pass over one rod falls from approximately 29 to 12 mm. Spools will be easier to rock out fore/aft. The dowel snaps retain the rods, not the spools. Validate insertion, sliding and accidental bumps before accepting this rail spacing.

The final CAD is one valid solid and both delivered STL meshes pass edge-closure checks. [Envelope and section calculations](designs/closed-wall-e6/vertical-verification.json) · [Geometry check](designs/closed-wall-e6/verification.json) · [Finish check](designs/closed-wall-e6/finish-verification.json) · [Mesh check](designs/closed-wall-e6/mesh-verification.json).

### E5 — reject simple arm thinning as an equivalent replacement

First raised the underside by 45 mm while retaining the 150 mm span. That left only an 18 mm-deep arm. Its midspan second moment of area fell to approximately 18% of E4's, with no compensating span reduction. Kept this as an illustrated study and proceeded to E6. [E5 checkpoint](designs/closed-wall-e5/README.md).

### E4 — angular frame, chamfers that fade into the faces

Replaced the main body's sweeping outline with straight facets and R2 corner blends. Both broad faces receive 3 mm chamfers along the large structural edges. Before the retainers and small mounting features, the chamfer depth fades over 20 mm using a quintic curve with zero slope and curvature at both ends. The bevel also fades at the short upper-leg facet junction to avoid a hard termination there. The thin fingers and their small rounded noses keep their functional sections; a blanket R2 treatment would consume them. Integrated concave root blends increase to R2.

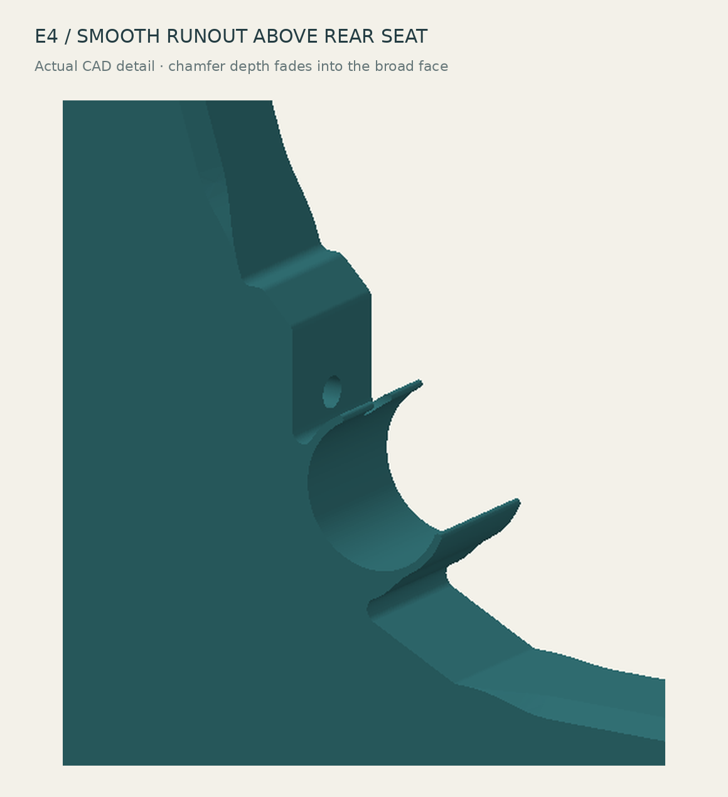
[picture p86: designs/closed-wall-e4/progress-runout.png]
Smooth chamfer runout near the rear seat


The bevels require extra solid material at the cavity rims. A 3 mm bevel over the original 1.2 mm face and 2.4 mm perimeter would leave an inadequate diagonal ligament. Local cavity setbacks now follow each bevel and its runout, preserving a design minimum of 1.2 mm behind the treated surface. The two continuous internal plates remain 1.2 mm, with three hollow bands. This local reinforcement does not solve unsupported internal-roof printing.

The final STEP is a valid single solid; the final bracket and coupon STL meshes have no boundary or nonmanifold edges. The nominal full-profile spool clearance sweep gives 5.34 mm minimum over 180–220 mm flanges; the 0.005 mm contour simplification tolerance is much smaller than the clearance margin. The finished chamfers only remove exterior material. These checks do not establish insertion force, strength, or creep life.

[Finished STEP](designs/closed-wall-e4/bracket.step) · [Final STL](designs/closed-wall-e4/bracket.stl) · [Finish verification](designs/closed-wall-e4/finish-verification.json) · [Mesh verification](designs/closed-wall-e4/mesh-verification.json) · [Seat drawing](designs/closed-wall-e4/retainer-engineering.png)

### E3 — remove the vestigial saddle prong

The small spur below the snap finger was leftover geometry from the original open saddle. Rounding it in E2 preserved a feature with no retaining function. Removed both the original saddle-lip sectors and their circular support nodes. Rebuilt each connection as a buttress between the arm and the rigid bearing sector, keeping the actual curved snap fingers.

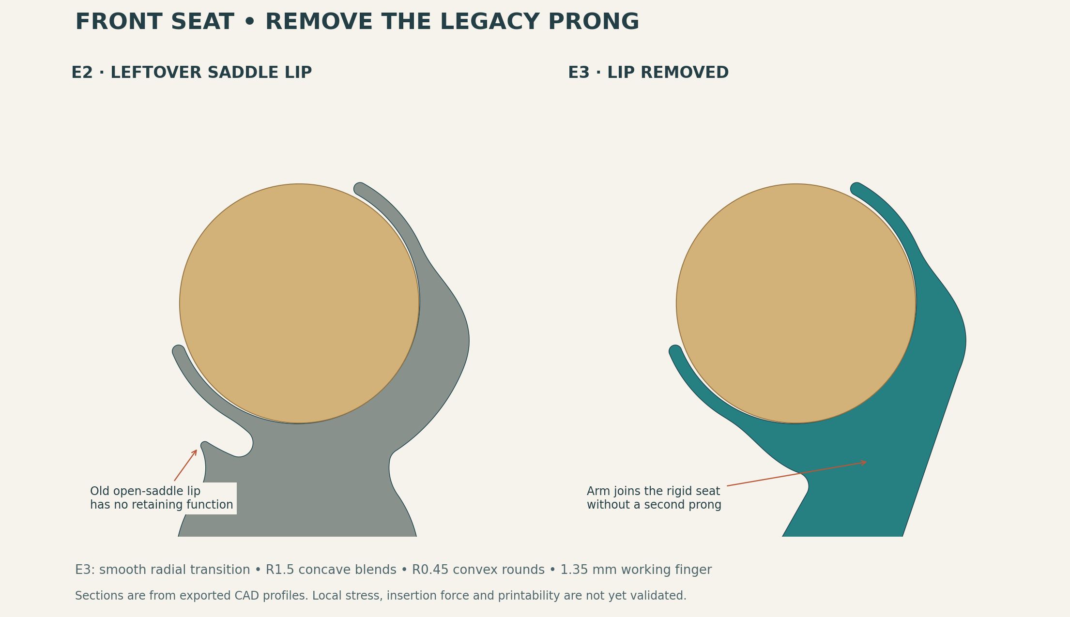
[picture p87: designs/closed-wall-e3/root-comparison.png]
Front seat: the unwanted prong is removed


The snap opening, throat, thin finger dimensions and smooth root construction remain the same. The support beneath the retainer changes, so its effective compliance still needs evaluation in the integrated part. The existing 8 mm coupon remains a local retainer fit sample, not a stiffness match for the complete bracket.

The full-profile nominal clearance sweep still passes at 5.64 mm minimum over 180–220 mm flanges. The new outline is connected. [Geometric results](designs/closed-wall-e3/verification.json) · [Mesh checks](designs/closed-wall-e3/mesh-verification.json).

### E2 — replace abrupt snap roots with smooth transitions

The E1 root treatment was inadequate: adding circles to a stepped profile left abrupt shoulders, and the relief pockets ended in sharp notches. Replaced that construction with a continuous transition from the 1.35 mm finger to the thick bearing sector. The analytic transition matches radius, tangent, and curvature at both ends. Its minimum curvature radius is approximately 6.76 mm before integration into the bracket.

Added R1.5 concave blends at the integrated roots and relief-slot ends, plus R0.45 convex rounds. Enlarged the relief pocket to 17.75 mm radius and increased the local bearing thickness from 5 to 6 mm to preserve a substantial connection to the bracket. The nominal capture throat remains approximately 24.51 mm. The working fingers remain 1.35 mm thick; the thicker roots change their compliance, so insertion force still needs validation.

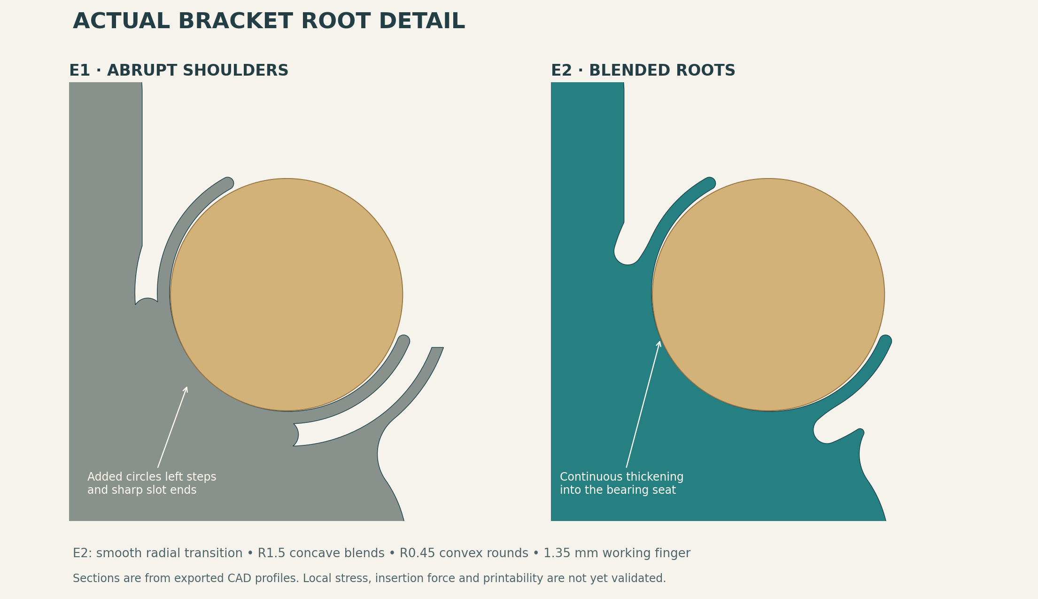
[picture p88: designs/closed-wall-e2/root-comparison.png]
Actual CAD root comparison


The nominal flange sweep passes with 5.64 mm minimum full-bracket clearance and 6.91 mm retainer clearance. A boundary-angle check around the rear seat found no large resolved direction jumps; the maximum was 2.36° after excluding microscopic tessellation edges. This is a geometric check, not a claim of zero stress concentration. [Root verification details](designs/closed-wall-e2/root-verification.json).

The rebuilt bracket and coupon also pass mesh edge-closure checks. [Mesh verification](designs/closed-wall-e2/mesh-verification.json).

Slicer paths and physical insertion behavior remain unverified. The full bracket still needs an internal-roof printing solution.

### E1 — align the snap opening with spool contact

Rotated each seat so its opening faces the spool contact and its rigid bearing sector lies directly opposite. Mirrored the two seats. This preserves the exposed track surface while directing the spool reaction into the thick bearing sector. Added separate 1.35 mm curved fingers and rounded noses, with a nominal 24.51 mm throat. A 185° concentric wrap was rejected because its capture disappears within the seat clearance.

The new profile passes the nominal 180–220 mm flange clearance sweep. Minimum retainer clearance is 6.91 mm; minimum full-profile clearance is 5.40 mm. These are seated geometric clearances, not insertion-path or tolerance validation. The thick bearing sector is 5 mm radially; the structural perimeter increases from 1.35 to 2.4 mm. Continuous side and internal plates remain 1.2 mm.

The drawing at the top of this page comes from the current CAD profile. The [8 mm coupon](designs/closed-wall-e1/snap-coupon-8mm.stl) makes the first fit trial smaller than a full bracket. It does not establish the 24 mm-wide bracket's insertion force.

### D — verify continuous internal planes

Established the upward wall leg and four full L-shaped plates. Rebuilt the delivered mesh, checked edge closure and all 120 layer-center sections, and independently checked nominal spool clearance. Found the main manufacturing issue: true empty cavities leave approximately 84 mm of unsupported region near the knee. A global infill percentage does not support those cavities.

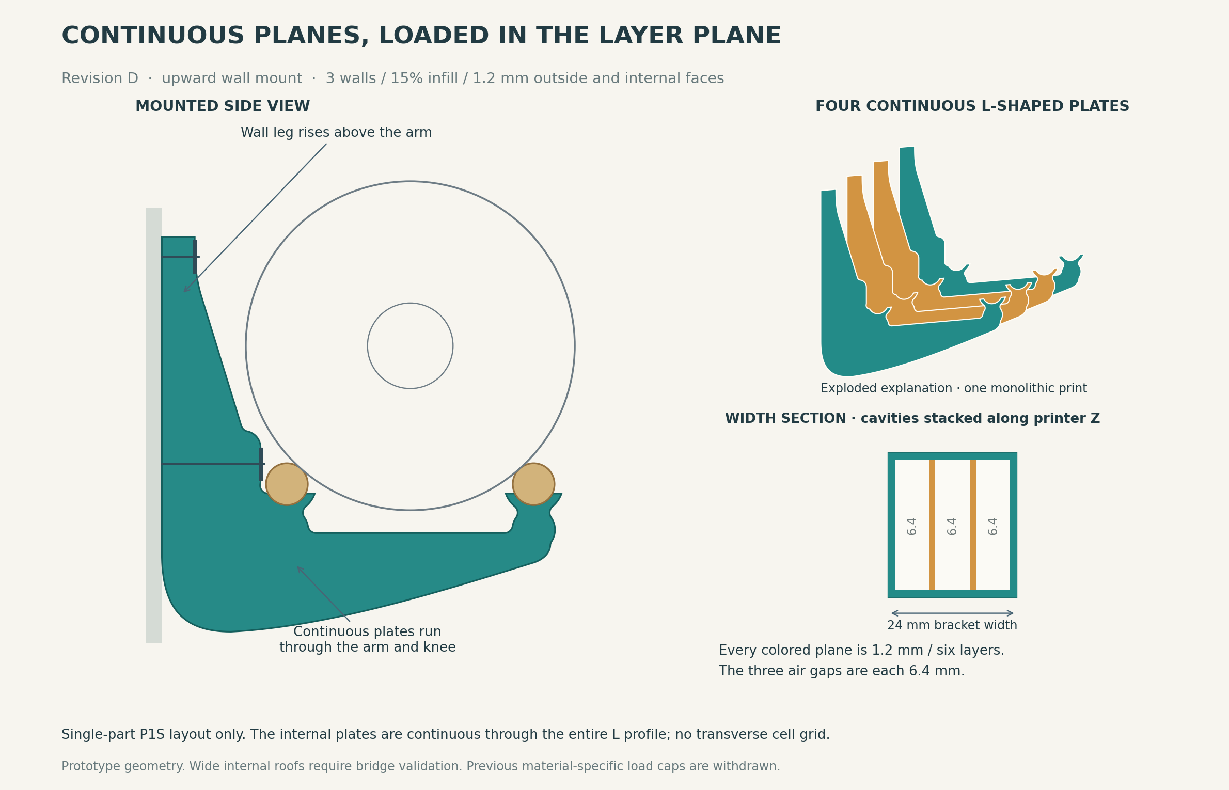
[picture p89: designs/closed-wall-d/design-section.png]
D continuous-plate section


[Exterior](designs/closed-wall-d/progress-exterior.png) · [Arm cutaway](designs/closed-wall-d/progress-cutaway.png) · [Separated plate explanation](designs/closed-wall-d/progress-plates.png)

### Deferred — open-web alternative

Archived the separate reference concept. It has no shared geometry changes or load claims with the current closed-wall path.

## Current files

- [STEP assembly: body plus modifier helpers](designs/closed-wall-e8/bracket-with-modifier-helpers.step)
- [Body-only STEP](designs/closed-wall-e8/body-only.step)
- [Aligned body STL](designs/closed-wall-e8/body-only.stl), [helper 1](designs/closed-wall-e8/helper-1.stl) and [helper 2](designs/closed-wall-e8/helper-2.stl)
- [Setup instructions and rebuild](designs/closed-wall-e8/README.md)
- [Verification](designs/closed-wall-e8/verification.json)
- [Design decisions](DESIGN.md)
- [Separate future open-web reference](future/open-web/README.md)

## Geometry

| Feature | E8 value |
|---|---:|
| Nominal dowel diameter | 25.4 mm |
| Seat diameter / spacing | 26 / 100 mm |
| Single-part envelope | approximately 206.73 × 208 × 24 mm |
| Structural perimeter | User-selected slicer wall count and extrusion widths |
| Broad-face chamfer / body corner radius | 3 / 2 mm where features permit |
| Full-height wall land | 208 mm |
| Screw centers above rail datum | 164 and 40 mm |
| Clamping thickness / nominal access diameter | 3.6 / 16 mm |
| Screw clearance / washer envelope OD | 5.2 / 13 mm |
| Internal support | User-selected slicer infill; no modeled cell grid |
| Chamfer runout length | 20 mm |
| Exterior side plates | Slicer top/bottom layers; 1.2 mm suggested |
| Internal continuous plates | Two 1.2 mm helper solids converted to 100% infill modifiers |
| Intervening sparse-infill bands | 3 × 6.4 mm |
| Snap finger bending thickness | 1.35 mm |
| Rigid seat radial thickness | 6 mm |
| Nominal capture wrap / throat | 218° / approximately 24.51 mm |

The snap opening faces the spool contact. The thick seat lies 180° opposite that contact for the 200 mm reference spool. Front and rear retainers are mirrored. The contact direction varies with spool diameter; the nominal seated geometry was checked over 180–220 mm. Minimum computed clearance is 3.48 mm for the complete bracket and 7.45 mm for the rear retainer, with symmetry applying to the front retainer.

## Build and inspect

Follow the [E8 setup and rebuild instructions](designs/closed-wall-e8/README.md). Import the STEP as one object with three aligned parts. Choose body walls and infill, change the helper parts to modifiers, and set their infill to 100%. Keep the supplied broad-side-down orientation and inspect the two internal solid bands in the sliced preview.

## Verification limits

E8's STEP roundtrip preserves three valid solids, and hardware envelope checks pass. STEP does not encode slicer settings. The helper overlap is intentional and must not become extra printed slabs. Actual walls, solid-band formation, sparse-infill support and physical print quality need slicer/print checks. Previous E6 section properties do not rate arbitrary E8 print settings. Main bracket loads, fasteners, dowels, snaps, handling stability and long-term creep remain unqualified.

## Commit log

2026-09-10 Initialize design journal and current prototype status
2026-09-10 Checkpoint D audit and E1 snap geometry with illustrated design journal
    [arm-section.stl, bracket.3mf, bracket.scad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]
2026-09-10 Replace stepped snap roots with smooth transitions and rounded relief slots
    [bracket.scad, bracket.stl, retainer.scad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]
2026-09-10 Remove obsolete saddle prongs and rebuild direct bearing buttresses
    [bracket.scad, bracket.stl, retainer.scad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]
2026-09-10 Add angular E4 body with mirrored 3 mm chamfers and smooth runouts
    [bracket.scad, bracket.step, bracket.stl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]
2026-09-10 Compact rack envelope with closer rails and full-height wall contact; archive E5 study
    [bracket.scad, bracket.step, bracket.stl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]
2026-09-10 Document full-row service demands at 16-inch support spacing without assigning capacity
2026-09-10 Compare added perimeter and arm depth for PLA and PETG prototypes
2026-09-10 Add E7 bridge compartments recessed wall fixings and DFM coupons
    [bracket.scad, bracket.stl, bridge-coupon.stl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]
2026-09-10 Replace modeled infill with E8 solid STEP and two modifier helper slabs
    [body-mounted.stl, body-only.step, body-only.stl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]
2026-09-10 Document E8 PLA and PETG prototype wall counts with explicit section assumptions
2026-09-10 Checkpoint reproducible E8 whole-bracket and screw-landing FEM work
2026-09-10 Replace README with full print and material engineering guide; adopt 5 mm serviceability
2026-09-10 Record raised-front collision check against current E8 profile
2026-09-10 Document 12 mm raised-front interference and required back-arm revision
2026-09-10 Promote E9 raised-front prototype with verified 2 mm chamfers and R2 wall transitions [skip ci]
    [body-mounted.stl, body-only.step, body-only.stl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]
2026-09-10 Checkpoint E9 solved 10-wall and screw-landing fields while 8-wall analysis completes [skip ci]
2026-09-10 Publish verified E9 FEM, creep margins and full print engineering guide [skip ci]
2026-09-10 Publish E10 continuous chamfers after filleting and full-width dowel fit coupons [skip ci]
    [body-mounted.stl, body-only.step, body-only.stl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]
2026-09-10 Reinforce E11 inner seat and publish verified CAD, slicing and FEA
    Deepen the inner-seat underside, smooth the rigid shoulders, preserve the fingers and continuous plates, and mirror the broad-face chamfers at 50 degrees.
    Publish matched E10/E11 comparisons, refined 8/10-wall 3D fields, landing checks, material and creep sensitivities, and section/3D stress views. Verify the delivered CAD, Arachne toolpaths, numerical balances and artifact hashes; preserve E10 as the historical guide.
    [body-mounted.stl, body-only.step, body-only.stl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]
2026-09-10 Slim E12 seat reinforcement to one-quarter depth and refresh validation
    Reduce the underside addition from 38 mm to 9.5 mm with a broader smooth blend, preserving the fingers, continuous plates, hardware and mirrored 50-degree finish.
    Publish matched E10/E11/E12 comparisons, new 8/10-wall 3D and landing refinements, updated material and creep tables, and checked CAD/Arachne toolpaths. Document the compactness tradeoff and rejected mesh attempts; archive the deeper E11 guide.
    [body-mounted.stl, body-only.step, body-only.stl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]
2026-09-10 Shape E13 angular reinforcement and refine global hotspot analysis
    [body-mounted.stl, body-only.step, body-only.stl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]
2026-09-11 Checkpoint Rev F CAD, constraint studies and next optimization sprint
    [body-mounted.stl, body-only.step, body-only.stl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]
2026-09-11 Complete Rev G evolutionary search and publish rejected finalist evidence
    [body-mounted.stl, body-only.step, body-only.stl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]
2026-09-11 Checkpoint G2 brief and slicer-derived material correction
2026-09-11 Checkpoint corrected material diagnostics and STEP helper handoffs before restart
2026-09-11 Validate free GPU elasticity route and retain sliced-material fidelity limits
2026-09-11 Checkpoint G evolutionary screening and three visual CAD handoffs
    [body-mounted.stl, body-only.step, body-only.stl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]
2026-09-11 Build E plus F body and reinvest a 29 percent material cut
    [body-mounted.stl, body-only.step, body-only.stl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]
2026-09-11 Mark EF STEP handoffs as exact binary CAD artifacts
2026-09-11 Recover E13 print reference and record connected EF brace limits
    [body-mounted.stl, body-only.step, body-only.stl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]
